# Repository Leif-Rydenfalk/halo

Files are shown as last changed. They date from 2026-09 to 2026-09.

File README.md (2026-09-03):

# halo — an open-source, cheaper AirTag-compatible tracker PCB

*A ce-designs project (`design:halo`) and a triad root. Started 2026-09-03.*

Leif, 2026-09-03, verbatim: *"its a clone of the apple airtag pcb but so we can
open source it and manufacture it for cheaper. do a whole lot of research and
find out a lot of open source projehcts which already tries to do this and
potential pcb designs and all available documentation and research out there
for this and place it all in this repo"*

Apple sells the AirTag for $29 with the hardware closed and the Find My network
gated behind an accessory program. This repo collects **everything public** about
the AirTag hardware, the Find My protocol, the open-source firmware that already
lets non-Apple boards ride the network (OpenHaystack and its successors), every
open coin-cell tracker PCB that could be a starting point, the chips that can
reproduce each function and what they cost, and the legal / certification /
child-safety / anti-stalking constraints — then designs an open board from it.

**Name.** "AirTag" and "Find My" are Apple trademarks, so the project is not
called that. *halo* — Leif, 2026-09-03: "a halo is always visible and you can
find it easily, which is what the project does." The project was briefly called
`haytag` (a tag for the haystack, after OpenHaystack); it was renamed on
2026-09-03 and GitHub redirects the old URL.

## What is where

```
README.md            this page
DECISIONS.md         every design question resolved by evidence, and what each option beat
MISSION.md           the definition of done: the eleven-artifact factory release pack
TOOLCHAIN.md         the tools we have, the open-source sim stack, the lanes building it
GOAL.md              what it is for — puck, embeddable block, local relative positioning (Leif's words)
research/            the dossiers — one per lane, every claim sourced with URL + date
  08-local-positioning-uwb-ble.md        peer-to-peer ranging: UWB TWR, BLE RSSI/AoA, open RTLS projects
  09-embeddable-block-and-modules.md     how to ship it as a KiCad sheet + castellated module
  01-airtag-hardware.md                  teardowns, chips, PCB, firmware, debug ports
  02-findmy-protocol-and-openhaystack.md the BLE payload, key rotation, every OSS project
  03-open-hardware-tag-designs.md        existing open PCBs (KiCad/Eagle/EasyEDA) ranked
  04-commercial-tags-and-clones.md       certified tags + AliExpress clones, what's inside
  05-components-and-cost-model.md        part candidates, BOM roll-up at 10/100/1k/10k
  06-legal-ip-certification-safety.md    trademark, patents, Find My program, DULT, FCC/CE, Reese's Law
  07-mechanical-enclosure-and-3d-models.md dimensions, speaker, battery door, open 3D models
  fetched/           raw text of the key pages, so the record survives link rot
  sources.tsv        every source any lane used: lane, url, title, date, note
reference/           vendored snapshots of the open-source repos (CLONE-LIST.tsv → MANIFEST.md)
  models/            freely-licensed 3D models and drawings
images/              teardown / FCC / design photos with CATALOG.md per folder (source + license)
spec/                machine-readable: bom-candidates.json, later specs.json
docs/                ANTI-STALKING.md and the design documents that follow
electronics/         schematic + netlist (ce-pcb) — next phase
hardware/            KiCad project — next phase
firmware/            pointers to upstream + our port — next phase
ce-parts/ ce-connections/ ce-assemblies/   the triad shelf for this design — next phase
evidence/            ledger.jsonl, append-only
out/                 renders, gerbers, reports — COMMITTED, they are data
```

## Method

1. **Research** (this commit) — collect every public fact with its source.
2. **Specify** — SPEC.md: what the clone must do (Find My via OpenHaystack keys
   first, official program path documented), the DULT anti-stalking minimum,
   target cost, target envelope (Ø ≈ 32 mm, 8 mm).
3. **Design** — ce-pcb board.py → KiCad → JLCPCB assembly; enclosure in ce-cad.
4. **Evidence** — every check lands in the ledger; the design is born T0.

## Status

Research lanes A–G running 2026-09-03. See research/ as they land.

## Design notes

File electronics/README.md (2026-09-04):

# halo electronics — the circuit, block by block

*Lane B1. This describes **revision A**, which lives in `halo_rev_a/`. Every
number here was produced by a tool on this machine; the last section is the
list of things that were not, and it is the most important one.*

---

## Where everything is

| path | what |
|---|---|
| `halo_rev_a/schematic.py` | the circuit, generated. **The only place a part number is typed.** |
| `halo_rev_a/board.py` | the copper. Reads the netlist back out of the schematic — it is never retyped. |
| `halo_rev_a/footprints.py` | the six land patterns KiCad does not have, and the antenna geometry |
| `halo_rev_a/pinouts.json` | the nRF54L10 and LIS2DW12 pin tables, transcribed from the datasheets with citations |
| `halo_rev_a/sim/` | our own circuit and electromagnetic models |
| `halo_rev_a/out/` | the built `.kicad_sch`, `.kicad_pcb`, PDF, SVG, netlist, ERC and DRC reports |
| `../out/release/board/` | the factory package — Gerbers, BOM, CPL, stackup, verdicts |

Rebuild the whole thing:

```bash
cd ~/dev/ce-workshop
python3 ce-designs/halo/electronics/halo_rev_a/footprints.py
ce-pcb/bin/sch build ce-designs/halo/electronics/halo_rev_a/schematic.py \
                  -o ce-designs/halo/electronics/halo_rev_a/out
ce-pcb/bin/pcb   ce-designs/halo/electronics/halo_rev_a/board.py
ce-pcb/bin/sch erc ce-designs/halo/electronics/halo_rev_a/out/halo_rev_a.kicad_sch
```

---

## The circuit, in one paragraph

A CR2032 feeds an nRF54L10 directly. There is no buck, no LDO and no load
switch: the SoC's 1.7–3.6 V range spans the whole cell curve, so every
regulator in Apple's board is a part we do not buy. The SoC carries the
2.4 GHz radio, the NFC-A tag peripheral that drives an etched coil through two
tuning capacitors, and Bluetooth Channel Sounding for peer ranging. A
LIS2DW12TR on I²C wakes it on movement; a bare piezo bender bonded to the
shell is driven anti-phase from two GPIO with no amplifier; SWD comes out on
pads that cost no height.

---

## Block by block, and why each part is there

### 1. The SoC — `nRF54L10-QFAA-R7`, LCSC **C44800139**

QFN-48, 6 × 6 mm, 0.4 mm pitch. **$2.4012 at 1000.** DECISIONS.md D12 chose
it over the nRF52840 on a measurement: Bluetooth Channel Sounding gives 6–10 cm
mean error on coin-cell hardware, the same accuracy band as ultra-wideband,
from a radio already on the tag — and it costs **61 cents less** than the
nRF52832, where adding UWB costs $8.86 more.

Its datasheet numbers drive every power figure in this project: **TX 3.7 mA at
0 dBm, RX 2.1 mA, System-ON with 192 kB retained 2.4 µA** (Table 86). Those are
radio-only figures and lower than the 4.8 mA on Nordic's marketing page, which
is whole-device.

Decoupling is four 100 nF 0201s, one per VDD pin. The SoC's own DC/DC runs off
L1 between `DCC` and `DECD`; `DECA` is tied to `DECRF` because the datasheet
says *"Must be connected to DECA"*, not because it is tidy. The passive values
are Nordic's own reference circuit configuration 1 (Figure 175 / Table 82),
copied component-for-component — the correct move for an RF front end and the
wrong one to improvise.

### 2. Power, the cell, and the five-removals reset

The CR2032 lands on **three sprung fingers**, not a holder: SPEC.md §4 records
that the lowest-profile surface-mount retainer stands 2 mm above the board and
the stack has about 1.5 mm in total. Lane M's carrier holds the cell; the
board's job is three solder lands under the finger roots.

**Bulk is 4 × 10 µF 0402, not Apple's five 100 µF.** Two of the three loads
that needed 500 µF are gone — D12 deleted the U1 and D11a deleted the class-D
amplifier — and an 0805 is 1.25 mm tall against a 0.578 mm allowance. What
40 µF actually buys is measured, not asserted: see §"What the simulations
say".

**Cell-removal detection is a circuit, not a note.** SPEC.md §3 says the
AirTag has two positive contacts *"both sensed before boot"*, and the
five-removals factory reset needs the SoC to stay alive across a removal. So
the second positive finger is **sense-only**: it feeds a 4.7 M/4.7 M divider
into AIN0 whose bottom leg returns to a GPIO rather than to ground, so it
draws 0.32 µA *only while that pin is driven low* and nothing at all the rest
of the time. On a 2.4 µA sleep budget a permanently-on divider would have been
a 13 % battery-life tax. Pull the cell and the sense node collapses in about
0.24 ms while the bulk holds the rail up for seconds. Zero series loss, zero
extra silicon, and it uses the second finger for the reason Apple has one.

### 3. Clocks

32 MHz (`NX2016SA`, C843260) and 32.768 kHz (Epson `C32346`) crystals.
**External load capacitors are placed but NOT FITTED.** The nRF54L family has
on-die load capacitors on both oscillators; fitting external ones as well
double-loads the crystal and pulls it off frequency. The pads exist so a
crystal lot that does not pull in can be trimmed without a board spin, and
populating them means disabling the internal ones — a firmware change, not a
rework.

### 4. The 2.4 GHz path

Nordic's reference matching network (L2/C18/L3/C19/L4/C22/C23) from the `ANT`
pin to a 50 Ω node, then a **pi network — C20 shunt, L10 series, C21 shunt** —
between that node and the antenna feed. L10 is fitted as a 0 Ω jumper so the
board works untuned; all three are re-valued from a measured S11.

The pi is not decoration. A trace antenna on a Ø26 mm board with a Ø20 mm
battery can 0.578 mm underneath will not present 50 Ω, and **a matching network
is the only place that error can be absorbed.**

Two layout rules travel with this block, and they are Nordic's own words from
Figure 175: **C18's ground connects ONLY to pin 32 (VSS_PA), on the top
layer**, and **C19's ground must be isolated from every ground layer except the
bottom.** Both are written onto the sheet, because a schematic cannot enforce
them and forgetting them breaks the radio.

### 5. NFC — and there is no NFC chip

SPEC.md F8: the SoC's own NFC-A peripheral drives the coil from two pins.
**There is no separate NFC front end in an AirTag either**, which deletes a
BOM line most clone designs carry. The whole block is an etched coil and two
capacitors.

The coil is **2 turns, not 5**, and that is forced rather than chosen: the
usable annulus is R10.15–R10.85, because R10.0 is the cell can and R10.94 is
the nearest battery contact land minus clearance. At the 0.30 mm pitch a
0.127 mm process allows, 0.70 mm of band is 2.33 turns.

C24/C25 are **1.1 nF, and they were 130 pF until the solver corrected them.**
130 pF is Nordic's figure *for a 2 µH antenna*; ce-rf measured the real
winding at 0.2449 µH and returned 554.6 pF of tuning across it, so each series
capacitor is 1.109 nF.

### 6. There is no SPI NOR flash — a defect fix

Revision A carried a GD25LQ32EEIGR on VDD. **That part's supply range is
1.65–2.0 V and this board's only rail is a raw 3.0 V coin cell**, so it was out
of specification from the first second — the kind of fault that half-works on
a bench and fails in a field. Caught by the production test lane reading the
sheet.

Fitting a regulator was the alternative and it is what the real AirTag does. It
costs a part, an inductor, a rail, a test and board area, and buys nothing:
nothing else here wants 1.8 V. Meanwhile the firmware measures **13,164 bytes,
1.27 % of the SoC's own 1 MB**, and research/05 §3.7 already recommended
omitting it. So it is deleted. If revision B wants external firmware staging,
the part is a **wide-range low-power NOR such as the Macronix MX25R
(1.65–3.6 V)** — not another GD25LQ.

### 7. Motion — `LIS2DW12TR`, LCSC **C189624**

LGA-12, 2 × 2 mm, under 1 µA in low-power mode, **$0.7408 at 1000**. Apple's
BMA280 is unbuyable (29 in stock against a 10,000-piece minimum packet).

**On I²C, not SPI.** It costs two pins instead of four, frees the SPI bus for
the reserved UWB option, and lets the part answer while nothing else is
selected. CS is strapped high to select I²C and SA0 low to set address 0x18,
both through resistors rather than vias so a bring-up board can change mode.
Both interrupt lines are wired: INT1 is the wake line SPEC.md F7 needs, INT2
carries the orientation vector D12 attaches to every range.

### 8. The sounder — two pins, no amplifier

D11a: a bare **Murata 7BB-20-3** piezo bender, Ø20.0 × 0.22 mm, bonded to the
inside of the shell and driven anti-phase from two GPIO. This is Apple's trick
— make the housing the radiating surface — done with a catalogue part a fifth
of a millimetre thick, because the obvious buzzer is 3.5 mm tall and the stack
has 1.5 mm.

**No MAX98357A.** A bridge-tied class-D swings ±Vbat; two pins driven
anti-phase swing the same. What the amplifier buys is current, and a bender is
capacitive. That was research/05 §11.6's arithmetic; it is now measured.

R9 is 100 Ω of series damping and it earns its line — see below.

### 9. Debug and the reserved UWB option

Six SWD lands at 1.27 mm pitch. **A Tag-Connect was drawn first and does not
fit**: its land pattern is about 80 mm² with two NPTH alignment holes, and the
DRC found those holes drilled through the SoC's pads. Six 0.8 × 1.4 mm lands
carry the same six signals in 9 mm² with no holes.

J2 reserves the halo-uwb variant of D12 as **eight SMD lands** carrying SPI, an
interrupt, a reset and power — **not a DW3110 land pattern.** No document in
this repository carries the DW3110's pin assignment, and D9 forbids guessing
48 net names; and a second 6 × 6 mm QFN does not fit a Ø26 mm board whose
middle Ø20 mm is shadowed by a battery.

### 10. Test access

Eleven probe lands and two asymmetric fiducials, placed by search rather than
by hand. **VDD and GND each get a FORCE and a SENSE pad** — sleep current is
single-digit microamps, and two probes landing in one battery pad is a
two-wire measurement wearing a four-wire name. **IPC-A-610 Class 2** is
recorded on the sheet because the optical inspection recipe is built from it.

---

## What the simulations say — about this board, not an example

| study | verdict | the number that matters |
|---|---|---|
| `sim/rail_droop.py` | **PASS** | 84.7 mV droop at end of life against a 400 mV limit; 64.5 months derated life |
| `sim/rail_droop.py` (hold-up) | **PASS** | 40 µF keeps the rail alive **4.998 s** after the cell is pulled |
| `sim/sounder_drive.py` | **PASS** | **3.98 V pp** across the bender from a 2.0 V cell — 2×VDD with no amplifier |
| `ce-rf` NFC coil | **PASS** | L = 0.2449 µH, tuning 554.6 pF |
| `ce-rf` 2.4 GHz | **FAIL** | 2.886 GHz against a 2.4–2.4835 GHz target |

**Three things the simulations changed in the design, rather than confirming.**

1. **The NFC tuning was eight times wrong.** 130 pF → 1.1 nF.
2. **R9 was justified for the wrong reason.** The schematic said 100 Ω "holds
   the peak near 30 mA". Measured: with a low-loss 40 nF bender the peak pin
   current is 32.0 mA *without* R9 and 17.8 mA *with* it. Right magnitude,
   wrong side of it. R9 is what keeps the pin under a 25 mA ceiling.
3. **The antenna was 3.78 mm too short.** openEMS returned
   `eps_eff_implied = 1.573` where the element had been sized on the textbook
   2.2, so the quarter wave is 24.49 mm and not 20.71. The element now
   meanders, with the tooth depth solved by bisection.

**Two studies caught their own mistakes**, which is the point of writing
asserts that can fail. The sounder study first measured the bender voltage
*to ground* instead of *across the bender*, reported 2.0 V where the swing is
4.0 V, and failed an assert that was actually satisfied. And the rail study
asserted the rail alive ten seconds after a cell removal — a threshold that
came from nowhere, failed at 1.400 V, and was replaced by the requirement that
actually exists (the firmware's detect-and-commit budget, about 11 ms) rather
than loosened.

---

## What is still unproven

**Load-bearing, in rough order of how much they matter.**

1. **The board is not routed.** 91 unconnected items, 0 vias. Freerouting
   was run three times and timed out three times — 900 s at 12 passes,
   3300 s at 3, 2400 s at 2. The tool works (lane T1 proved it on a Ø31.87 mm
   board); this board is denser than it can handle. Do not fabricate.
2. **The antenna has not passed.** 2.886 GHz measured on the 20.71 mm
   element, with `eps_eff_implied = 1.573` naming the cause. The corrected
   24.49 mm meander is drawn in the copper but its FDTD re-run did not
   complete — the confirmation that it lands in band is the missing piece,
   not the correction itself.
3. **Five part classes do not fit the enclosure — and the fix is already
   written down.** 46 PASS / 5 FAIL on the height check. A QFN-48 is 0.85 mm
   and the cell leaves 0.578 mm under the bottom face; X1 and L1 are over by
   0.322 mm, the SoC by 0.272.

   **DECISIONS.md D17 (lane M, 2026-09-04) ends: *"leaving 0.542 mm of dead
   air under the cell that a flat pad embossed in the door could still
   recover"*.** If that pad is embossed the cell drops and the bottom-face
   allowance becomes 0.578 + 0.542 = **1.120 mm**. The tallest part here is
   0.90 mm and needs 0.95 mm with a solder fillet, so **every part clears** —
   and only **0.372 mm of the 0.542 mm** has to be recovered to do it.

   **This is a request to lane M, and it is the single change that closes
   this lane's largest open item.** `board.py height_check()` prints the
   arithmetic on every run.
4. **Loudness is unmeasured and DULT makes it mandatory.** 60 Phon at 25 cm
   cannot be simulated; VERIFICATION-DEBT V7 carries it.
5. **The bender is unsourced at every quantity**, so its land pattern is
   deliberately generic.
6. **Two turns of NFC coil may not couple enough** to read at a phone's field
   strength. The inductance is measured; the read range is not, and no assert
   here pretends otherwise.
7. **The SoC's stock is 212 pieces** against a 1000-piece minimum packet.
8. **Channel Sounding between two halos has never been demonstrated** — the
   6–20 cm figure is from a published study on other hardware (V8).
9. **The 0402 bulk capacitors' DC bias derating is unfetched**, so 40 µF is an
   upper bound and every droop figure is optimistic by an unmeasured amount.
10. **The GPIO high-drive output resistance is an estimate** (40 Ω), and every
    peak sounder current is inversely proportional to it.
11. **Controlled impedance is not implemented**, and the fab's 0.60 mm 4-layer
    dielectric heights were never retrieved.
12. **eps_r 4.3 / tan δ 0.02 is generic FR-4**, not fab-quoted — the largest
    single uncertainty in every RF frequency here.

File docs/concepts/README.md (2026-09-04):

# halo concept portfolio

*twelve researched ways to close the last gap to the AirTag and get further ahead than Apple*

> concept docs with ideas and different approaches to close the gaps further and get even further ahead than apple themselves

halo is at functional parity with the AirTag on every row of SPEC.md section 2 except F9, Precision Finding, which needs Apple's own ultra-wideband silicon behind an NDA that cannot coexist with publishing the design. It is already ahead in five measured ways: both Apple's and Google's networks in one advertising event, an antenna simulated at +0.521 dBi against Apple's filed -3.2 dBi, peer-to-peer ranging between the owner's own devices, about a sixth of Apple's retail price, and every file open.

This portfolio is what comes after parity. Each concept is researched and costed, not brainstormed: what it is, why it beats the alternative, the evidence with sources and dates, the cost in money and current and size and complexity, what it would break in the design that exists today, a verdict, and the smallest experiment that would settle it.

Nothing here is a commitment. A concept that reaches PROVEN is a thing somebody has already made work, not a thing halo has shipped.

**4 concepts: 1 PROVEN · 3 PLAUSIBLE · 0 SPECULATIVE.**

## What the three verdicts mean here

| verdict | means |
|---|---|
| **PROVEN** | Somebody has already made this work and the artifact is readable — a paper with measurements, a repository whose source says so, a datasheet number. The remaining risk is integration, not physics. |
| **PLAUSIBLE** | Every component of the argument is sourced, but the combination has not been demonstrated in the shape halo needs. The arithmetic closes; the experiment has not been run. |
| **SPECULATIVE** | A reasoned idea whose load-bearing claim has no source I could reach. It is written down with what would settle it, and it must not be quoted as a finding. |

A concept with no source is SPECULATIVE and says what would settle it. That rule is `docs/TOOLS-THAT-LIE.md` applied to ideas rather than to tools: a portfolio that reads as all-green would be reporting completeness it had not earned.

## Where halo stands before any of this

| fact | number | source |
|---|---|---|
| Average cell current, Find My advertising baseline (2 s period, 1 ms TX at 3.7 mA, 2.4 uA sleep) | **4.2506 uA  =  12.75 uW at 3.0 V** | ce-spice rail_droop, out/release/board/sim/rail_droop/measurements.json, i_avg_uA, 2026-09-04 |
| Battery life on a 235 mAh CR2032 at that current, derated for pulsed draw and self-discharge | **64.5 months (5.4 years)** | same file, life_months_derated; derations cited to TI SWRA349 Fig 3 and Energizer 2032NA0618 |
| SoC currents that drive every power figure here | **TX 3.7 mA at 0 dBm, RX 2.1 mA, System-ON 192 kB retained 2.4 uA** | nRF54L10 datasheet 4503_018 v0.10 Table 86, transcribed research/fetched/E-nrf54l-datasheet-currents.md |
| Unit cost at 10 / 100 / 1 000 / 10 000 against Apple's $29 retail and ~$10 build | **$19.25 / $9.28 / $7.17 / $6.75** | DECISIONS.md D15; spec/bom-resolved.json cost.model.d15_baseline_usd_per_unit |
| Board, and what is on it | **D26.00 x 0.60 mm, 4 layer, 38 placed refs, 131 joints; part-routed at 49 vias, 255 track segments, 81 unconnected** | electronics/halo_rev_a/schematic.py; STATUS.md board measurement 2026-09-05 06:06 — DO NOT FABRICATE until unconnected reaches 0 |
| Peer ranging accuracy specified for v1 | **6-10 cm MAE, 16-20 cm P90, line of sight, static, <=5.5 m** | arXiv:2605.17094 Table I (eight CR2032 nRF54L15 devices); research/08 section 1; DECISIONS.md D12 |
| Energy per pairwise Channel Sounding range, 0 dBm, 37 channels | **~19 uC = ~57 uJ  [derived in research/08 section 9.3 from the paper's 79 uC/cycle for four peers]** | arXiv:2605.17094 section IV-C; research/08 section 9.3 |
| Antenna, study geometry (D30 x 1.0 mm round rim inverted-F) | **PASS: 2.4469 GHz, +0.521 dBi realized gain against Apple's filed -3.2 dBi** | ce-rf out/halo-round-rim-ifa/verdict.json, verdict PASS |
| Antenna, the board this pack actually ships (D26.00 x 0.60 mm) | **FAIL — 2.4927 GHz, solver_converged 0. The +0.521 dBi is NOT this geometry** | ce-rf out/halo-rev-a-2g4/verdict.json; spec/convergence.json refuses a value from a FAIL case |
| Firmware footprint with all three protocol layers resident | **13,164 bytes flash (1.27 %) and 704 bytes RAM (0.36 %) on nRF54L10** | SPEC.md section 2a; DECISIONS.md D18 — the DULT transport is NOT yet written and is the expensive part |
| Stack budget, closed | **31.874 x 31.874 x 7.980 mm assembly, 0.542 mm of dead air left under the cell** | DECISIONS.md D17; design.py stack budget check |
| Find My location quality, for comparison with anything local | **raw report mean error ~100 m walking; median 26 min from generation to upload; 4 reports per key; 7 day retention** | PETS 2021 Tables 5-7 and sections 6.3-6.4, quoted in research/02 sections 1.6 and 10.4 |

## The portfolio

| # | concept | verdict | value | effort | one line |
|---|---|---|---|---|---|
| C3 | [Sensor telemetry over the finding network, with no gateway of its own](C3-sensor-telemetry-over-the-finding-network.md) | **PROVEN** | 5 | 1 | The status byte is copied into the location report and encrypted to the owner's key, so a halo can report sensor state through a stranger's phone and Apple cannot read it. |
| C8 | [Form factors the embeddable block enables — and the one rule that decides each](C8-form-factors-the-block-enables.md) | **PLAUSIBLE** | 4 | 2 | A card, a sticker, a bolt-on asset tag and a solder-down module are four different products, and DULT's own applicability test — not the electronics — is what changes between them. |
| C11 | [The tag you can audit — open debug, reproducible firmware, and why it costs almost no secrecy](C11-the-tag-you-can-audit.md) | **PLAUSIBLE** | 3 | 1 | Nobody can prove what an AirTag does. A halo whose firmware hash an owner can verify against a published build is a procurement answer no commercial tracker can give — and with pre-generated keys it gives away almost nothing. |
| C12 | [The flight recorder — an on-tag event log, read at an NFC tap](C12-the-flight-recorder.md) | **PLAUSIBLE** | 4 | 2 | An AirTag remembers nothing. A halo has 1 MB of NVM and uses 13 kB of it, so it can keep the last several thousand motion and ranging events and hand them over when somebody taps it. |

## Ranked by value against effort

Value is what it is worth to the goal in `GOAL.md`; effort is what it costs to find out, not what it costs to ship. A cheap experiment on a big idea outranks an expensive certainty.

| rank | concept | value/effort | verdict | the first move |
|---|---|---|---|---|
| 1 | C3 Sensor telemetry over the finding network, with no gateway of its own | 5/1 = 5.00 | PROVEN | Write the 3-bit counter firmware and leave two tags out for 48 hours. Costs one evening and answers the density question too. |
| 2 | C11 The tag you can audit — open debug, reproducible firmware, and why it costs almost no secrecy | 3/1 = 3.00 | PLAUSIBLE | Build the firmware twice and diff. If it is reproducible, say so in the README with the hash; if it is not, that is a defect worth a line in VERIFICATION-DEBT.md. |
| 3 | C12 The flight recorder — an on-tag event log, read at an NFC tap | 4/2 = 2.00 | PLAUSIBLE | Read the NVM write current out of the datasheet and add one scenario to the rail_droop study. The answer is a number in the units this project already reports. |
| 4 | C8 Form factors the embeddable block enables — and the one rule that decides each | 4/2 = 2.00 | PLAUSIBLE | Drop the existing design block into a card outline and run one antenna solve on it. The block is already measured to transfer; what is unmeasured is whether the antenna is happier in a bigger space. |

## What was considered and left out

- **A GNSS receiver on the tag** — A first fix costs tens of milliamps for tens of seconds against a 4.2506 uA budget, and Find My already answers the question GNSS would answer — which city block — for free. The gap in this project is room scale, and GNSS does not close it.
- **A LoRaWAN or NB-IoT backhaul** — It adds a second radio, a second certification regime and a gateway, to buy uplink from places nobody walks past. C9 buys the same thing with hardware halo already has.
- **A USB port for recharging** — A port is a hole, and IP67 and Reese's Law both fight it. The measured life is 64.5 months; the problem this would solve is not the problem halo has.
- **BLE 5.1 angle of arrival** — The tag side is free but the anchor side needs a multi-element switched antenna array in every room. GOAL.md rules out per-room infrastructure. research/08 section 10.
- **Appearing inside Apple's own Find My application** — It needs a per-unit Apple Token burned into flash at the factory under MFi, and D5 refuses MFi on principle because its terms make the specification confidential and publishing an implementation would breach them. This is a commercial wall, not a technical one, and it is not going to move.
- **A display, an e-paper panel or an LED ring on the puck** — Every one of them puts a conductor inside the D37.31 mm antenna keep-out and spends stack height, to deliver something GOAL.md does not ask for. The measured cost of violating that keep-out is in C4.
- **A stealth or silent build target** — SPEC.md section 8 refuses it on principle, not by omission, and this portfolio does not reopen it.

---

Generated from `spec/concepts.json` by `tools/gen_concepts.py` on 2026-09-05, commit `cdaa1dc`. The HTML page is `out/concepts/INDEX.html`. Do not edit these files; edit the JSON.

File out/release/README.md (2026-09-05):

# halo — open AirTag-compatible tracker — Factory handoff pack

Generated 2026-09-05 from `spec/release-pack.json` by `tools/gen_release_pack.py`.

| # | artifact | status |
|---|---|---|
| 1 | Gerbers, drill and netlist | **PARTIAL** |
| 2 | Schematic, ERC-clean, plus a reusable design block | **PARTIAL** |
| 3 | Bill of materials with prices and alternates | **READY** |
| 4 | Pick-and-place file in factory format | **READY** |
| 5 | Panel drawing, stackup and materials | **PARTIAL** |
| 6 | Simulation evidence | **READY** |
| 7 | Firmware, build instructions and a proven advertisement | **READY** |
| 8 | Mechanical files and assembly instructions | **READY** |
| 9 | Production test plan | **PARTIAL** |
| 10 | Compliance dossier | **PARTIAL** |
| 11 | Cost roll-up against Apple's retail price | **READY** |

See `INDEX.html` for the full pack: the work breakdown, what we need from the factory,
the compliance rules, and the open risks.

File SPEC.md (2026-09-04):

# SPEC — what halo must be

*The specification the design is judged against. Every row is either SETTLED
(with its source) or PENDING with the lane that will settle it. Nothing here is
an assumption: a PENDING row is a work item, never a guess left to harden into
a fact. Companion documents: GOAL.md (why), MISSION.md (definition of done),
DECISIONS.md (how each question was resolved), docs/ANTI-STALKING.md (the
safety behaviour, non-optional).*

Started 2026-09-03. Revision: draft 0.

## 1. Product definition

halo is a coin-cell Bluetooth tracker that reproduces the Apple AirTag
function for function from public information only, published openly, and
manufacturable cheaply. It ships in two variants (DECISIONS.md D1):

| | halo-core | halo-uwb |
|---|---|---|
| radios | 2.4 GHz BLE, Channel Sounding | same, plus an ultra-wideband transceiver in the reserved footprint |
| purpose | the open product: find your things through Apple's Find My network, **and** range to other halos at 6–20 cm line of sight | a high-precision stuffing option, if Channel Sounding proves insufficient in a real room |
| certification | pre-certified module, modular approval, RED self-declaration | owner-operated, not a sold consumer product |
| status | the shipping default | second board revision |

The circuit is published three ways so it can be embedded in any host board in
any outline (GOAL.md deliverable 2): a KiCad hierarchical design block, a
castellated solder-down module, and the Ø 32 mm puck as the first host.

## 2. Functional requirements, against the real AirTag

Each row: what the AirTag does, what halo must do, and where the number comes
from. The part that implements each is section 3.

| # | function | requirement | state |
|---|---|---|---|
| F1a | Google Find Hub advertising | advertise concurrently on Google's network: service `0xFEAA`, frame `0x40/0x41`, ~1024 s ephemeral-ID rotation | SETTLED lane B (public spec); DECISIONS.md D7 |
| F1 | Find My advertising | non-connectable advertisement, 37 bytes on air: address = `p[0]\|0b11000000 ‖ p[1..5]`, then `1E FF 4C 00 12 19 <status> p[6..27] p[0]>>6 <hint>`, where p is the X coordinate of the rolling NIST P-224 public key | SETTLED lane B (PETS 2021 Table 2, cross-checked against OpenHaystack source) |
| F2 | key rotation | rotate the advertised key on the DULT schedule; MAC address rotation likewise | SETTLED lane F: 15 min key, 24 h MAC |
| F3 | sound maker | audible alert, **≥60 Phon at 25 cm (ISO 532-1:2017)**, mandatory, four non-owner sound opcodes | requirement SETTLED lane F; mechanism OPEN, see DECISIONS.md D11 |
| F4 | separated-state behaviour | near-owner → separated after >30 min; random 8–24 h alert timeout with 6 h back-off | SETTLED lane F |
| F5 | identifier retrieval | serial readable over NFC or BLE, behind a physical button, 5-minute window; printed unique serial on the housing | SETTLED lane F |
| F6 | owner information page | obfuscated owner-info page, ≥25-day retention | SETTLED lane F |
| F7 | motion detection | wake and change advertising behaviour on movement | SETTLED lane A: AirTag samples every 10 s at rest and 0.5 s once moving; DULT additionally requires ±10° accuracy |
| F8 | NFC tap | phone tap reads the tag and opens the owner page | SETTLED lane A: the Nordic SoC's own NFC-A peripheral emulates a read-only Type-4 tag holding the owner URL; only the coil and two tuning capacitors are external |
| F9 | precision finding | AirTag does this with Apple's U1 | **known gap** — not reproducible without MFi (DECISIONS.md D1, D5) |
| F10 | peer ranging | range to other halos with Bluetooth Channel Sounding, 6–20 cm line of sight, 30 s update, deterministically scheduled, reporting raw ranges with quality metadata and an orientation vector | SETTLED lane H; DECISIONS.md D12 |
| F11 | battery life | about a year on a CR2032 | model PASSES in ce-spice: fresh-cell droop 68 mV under a transmit pulse against a 400 mV limit, five scenarios fresh to end of life, all asserts held |
| F12 | battery replacement | user-replaceable CR2032 behind a compliant door | SETTLED lane F: tool or two independent simultaneous movements (16 CFR 1263) |

## 2a. Budget floors (from lane B)

**Measured 2026-09-04, so this section is no longer an estimate.** halo's own
firmware on an nRF54L10 uses **13,164 bytes of flash (1.27%) and 704 bytes of
RAM (0.36%)** with all three protocol layers resident. Per object: DULT 605
bytes, the two elliptic curves sharing one engine 2,766, SHA-256 1,034, AES 736,
rolling keys 383, Find Hub 334, Find My 94.

The 116.7 KB / 21.5 KB Goodix figure quoted earlier measures a **different
question** — a full stack including the LE link layer and connection handling.
halo's number covers the protocol layers only; no link layer is present and no
connection is ever established, with the DULT opcodes graded as a pure function.
The expensive part of DULT is the transport, and it is not yet written. Both
numbers are correct and they are not comparable.

## 3. Component map — one row per function

From lane A's function map (research/01-airtag-hardware.md §4), which read the
part markings off Colin O'Flynn's full-resolution board photographs and Apple's
own regulatory filing. The halo column is lane E's substitution work; rows
marked PENDING lane E are awaiting its sourced pick.

| function | AirTag part (identified) | halo part | note |
|---|---|---|---|
| CPU, Bluetooth radio **and NFC tag in one** | Nordic **nRF52832-CIAA**, WLCSP-50, marking `N52832 CIAAE0 2102JK` | **nRF54L10**, falling back to L05 or up to L15 on memory (D12) — the family keeps the NFC-A tag peripheral and adds Channel Sounding | the NFC tag is the SoC's own peripheral on pins P0.09/P0.10 — **no separate NFC chip exists in an AirTag**, which deletes a line most clone BOMs carry |
| UWB ranging | Apple **U1**, die `TMKA75`, TSMC 16 nm, in a USI system-in-package with its own processor running "Rose" firmware side-loaded by the Nordic part | **not reproducible** — never sold. halo-uwb uses a sourceable transceiver for peer ranging only (D1) | the only true hard wall in the whole design |
| firmware and key storage | GigaDevice **GD25LE32/LQ32**, 32 Mbit SPI NOR, WLCSP-10, 1.8 V | PENDING lane E — generic SPI NOR | holds both the Nordic firmware and the U1's firmware, unencrypted |
| motion detection | Bosch **BMA280** | PENDING lane E | sampled every 10 s at rest, 0.5 s once moving |
| sound | Maxim **MAX98357A** class-D amplifier driving a copper voice coil glued to the shell, against a fixed central magnet, with a **TI TLV9001** op-amp in the analogue path | **bare Murata 7BB-20-3 piezo bender, Ø20.0 × 0.22 mm**, bonded to the shell and driven anti-phase from two SoC pins (D11) | about 8 mA while sounding, over three thousand times the sleep current |
| power | TI **TPS62746** buck to a 1.8 V rail, onsemi **FPF2487** load switch gating the UWB and flash, a small LDO, and **five 100 µF** bulk capacitors marked `J107S` | PENDING lane E | the bulk capacitance is what keeps the tag alive for seconds after the cell is pulled, which is how the five-removals reset works |
| timing | 32 MHz crystal marked `T320/RBEV`, 32.768 kHz crystal marked `A048L` | PENDING lane E | |
| antennas | three laser-direct-structured traces on the plastic carrier: Bluetooth inverted-F at **−3.2 dBi**, an NFC coil, a UWB patch at **−1.6 dBi at 6.5 GHz** | PENDING ce-rf | gains are from Apple's own filed test reports, not estimates |
| battery | CR2032 on three sprung contacts, two positive rails both sensed before boot | PENDING lane E | |

**The bottom line of the map:** every function is reproducible from catalogue
parts except precision finding, which needs Apple's chip, and appearing in
Apple's own Find My application, which needs a per-unit token Apple burns into
the flash at the factory. Both walls are commercial, not technical.

## 4. Physical envelope

From Apple's own dimensioned accessory drawing (lane G found it published free
at developer.apple.com, outside the login-walled Accessory Design Guidelines)
and from teardown measurements. Apple forbids redistributing that sheet, so the
numbers are transcribed here and the redistributable geometry in
`reference/models/` is a CC BY 4.0 drawing that reproduces every callout.

| feature | value | note |
|---|---|---|
| maximum outer diameter | **31.87 mm** | occurs at z = 4.34 mm, derived from the drawing's profile |
| overall height | **7.98 mm** | |
| stepped diameters | 28.94 / 27.90 / 27.84 / 25.55 / 23.11 mm | 0.05 mm chamfer |
| speaker keep-out | **Ø25.75 mm**, "do not obstruct" | Apple's own callout |
| antenna keep-out | **Ø37.31 mm**, no metal above or below | larger than the tag itself |
| steel cover | approximately a spherical cap of radius 92 mm | not a battery terminal — all three contacts are on the carrier |
| mass | 11 g first generation, 11.8 g second | otherwise dimensionally identical |
| environment | IP67, −20 to +60 °C | |

**The stack budget is the binding constraint.** A CR2032 is 3.2 mm and the
disassembled internal module measures 3.3 mm, so 6.5 of the 7.98 mm are spent
before the cover, the clearances and the shell wall. About 1.5 mm remains.

Two consequences follow directly, and both are now design rules:

- **No coin-cell holder fits.** The lowest-profile surface-mount retainer still
  stands 2 mm above the board. Sprung fingers on the carrier, clamped by the
  door, is the only scheme that fits — which is what Apple does.
- **No housed buzzer fits.** The obvious catalogue part reaches exactly the
  required loudness at three volts but is 3.5 mm tall.

Lane C's warning still holds on the copper side: a 20 mm cell inside a 30 mm
board leaves about a 5 mm annulus for the Bluetooth antenna keep-out and the
NFC coil together. The electromagnetic solver decides whether they share it,
the cell moves off-centre, or the puck grows.

The embedded block variant is not bound by this envelope. Only the puck is.

## 5. Electrical requirements

| # | requirement | source |
|---|---|---|
| E1 | operate from a CR2032 across its full discharge curve, including the rising internal resistance at end of life | ce-spice model, lane T2 |
| E2 | survive the radio transmit current pulse without the rail dropping below the SoC minimum at end of life | ce-spice, asserted |
| E3 | sounder drive that reaches F3's loudness inside an 8 mm puck | lane G (mechanism) + ce-spice (drive current) |
| E4 | 2.4 GHz antenna matched on the real board outline, with the battery's copper in place | ce-rf, lane T3 |
| E5 | NFC coil tuned to 13.56 MHz for the chosen tag IC's input capacitance | ce-rf |
| E6 | per-layer current and voltage drop within IPC-2221B limits | ce-board-sim |

## 6. Manufacturing requirements

| # | requirement | source |
|---|---|---|
| M1 | 4-layer board, DRC-clean against JLCPCB's published capabilities | ce-fab dfm, lane T6 |
| M2 | every part in stock at LCSC with a named alternate | ce-fab bom, lane T6 |
| M3 | assembly files (BOM + pick-and-place) accepted by JLCPCB without manual correction | ce-fab jlc |
| M4 | panelized for volume | ce-fab panel |
| M5 | cost per unit at 10 / 100 / 1 000 / 10 000, compared to Apple's $29 retail | lane E |

## 7. Compliance requirements

The 30-item constraint checklist in research/06-legal-ip-certification-safety.md
is normative. The headline constraints: pre-certified radio module for modular
approval; no Bluetooth word mark (DECISIONS.md D2); Reese's Law battery door
(D3); DULT behaviour non-optional (docs/ANTI-STALKING.md); clean-room only,
no MFi (D5); licence split (D4).

## 8. Out of scope

Apple Precision Finding (F9), the "Works with Apple Find My" badge, and any
stealth or silent build target. The last is refused on principle, not omitted.

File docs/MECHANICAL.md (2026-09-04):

# MECHANICAL — the halo puck enclosure

*Lane M. Everything here is either transcribed from a named source, computed
from the parameters in [`design.py`](../design.py), or **read off the finished
solid** by the measured-check suite in that same file. Where a number is a
calculation rather than a measurement it says so, and where nothing has been
measured the verdict is CANNOT DETERMINE and the test that would settle it is
named. Nothing is asserted.*

**Twelve measured checks, all PASS** — `out/mech/verdicts.json` is the record,
and two of them went red first and are in the ledger as a `failure` row.
Reproduce every number in this page with:

```bash
cd ce-designs/halo
~/dev/ce-workshop/ce-cad/bin/cad design.py            # build, check, render, export
~/dev/ce-workshop/ce-cad/bin/cad tools/section_view.py  # the section, seconds
python3 tools/stl_bbox.py out/mech/*.stl              # read the exports BACK
CE_TRIAD_ROOT=$PWD ~/dev/ce-workshop/bin/triad check --all
```

Companion documents: [SPEC.md](../SPEC.md) §4 (the envelope), [DECISIONS.md](../DECISIONS.md)
**D3** (battery door), **D11a** (the sounder), **D13** (enclosure and tooling),
and [research/07](../research/07-mechanical-enclosure-and-3d-models.md) — lane G's
dossier, which is where every Apple number in this page comes from.

---

## 1. What halo's enclosure is

Four moulded/stamped parts, one bought bender, one cell, three stamped
springs and a bead of silicone.

| # | part | material | process | what it does |
|---|---|---|---|---|
| 1 | `part:halo-shell-top` | PC | injection moulded, **straight pull, no undercut** | the crown. It **is** the loudspeaker diaphragm and the NFC window |
| 2 | `part:halo-carrier` | LCP, LDS grade | injection moulded, **three lifters** + laser direct structuring | the PCB seat, the contact roots, the seal land, the bayonet feet, the antennas |
| 3 | `part:halo-battery-door` | 301 stainless, 0.30 mm | progressive stamping | the user-openable door; press-and-twist |
| 4 | `part:halo-door-seal` | LSR 70 Shore A | moulded in place on the carrier | the radial door seal |
| 5 | `part:halo-battery-contact` ×3 | C5191 phosphor bronze, 0.15 mm | stamped, formed, insert-moulded | the cell's three contacts. There is no holder |
| 6 | `part:halo-piezo-7bb-20-3` | brass + PZT | bought (Murata) | the sounder (D11a) |
| 7 | `part:halo-cr2032` | — | bought | the cell |
| 8 | `part:halo-pcb-blank` | FR4 | 4-layer PCB | the board outline (the copper is the electronics lane's) |

Plus two prototype variants, `part:halo-shell-top-fdm` and
`part:halo-battery-door-fdm`, §8.

**The frame, and it is Apple's own.** Origin on the axis of revolution at the
lowest point of the battery door's outer face; +z toward the crown apex at
z = 7.980; +x through the 6 o'clock bayonet ledge, so D13's three ledges are at
0 / 120 / 240° (6, 10 and 2 o'clock). Every part is **built** in this frame, so
every placement in `assembly:halo-puck` is the identity — a concentric product
has one datum and there is not a coordinate to get wrong.

**The single tooling decision that shapes the whole split.** A bayonet is an
undercut; something must have one. halo puts **every undercut on the carrier**,
which nobody sees, and leaves the cosmetic shell a pure straight pull. Catley
found the AirTag's retaining tabs are *separate plastic pieces glued to the
white shell* at 2, 6 and 10 o'clock — the same problem, solved by gluing rather
than by moving the feature to another part. Three lifters in a non-cosmetic LCP
tool is the cheaper answer, and it deletes an assembly operation.

---

## 2. The stack budget — it closes, and it closes with slack

Every row is on the axis, in the closed state, and every boundary is a variable
in `design.py`. The table is printed by `report_stack()` on every build.

| # | layer | from | to | dz | where the number comes from |
|---|---|---|---|---|---|
| 1 | door skin at the axis, 301 SS | 0.000 | 0.300 | **0.300** | halo's choice. Apple's is **unmeasured** (research/07 §5.2 row 1 is an estimate) |
| 2 | dome sagitta under the cell — dead air | 0.300 | 0.842 | **0.542** | read off Apple's own ordinate table at the cell's Ø20.00 rim |
| 3 | **CR2032** | 0.842 | 4.042 | **3.200** | Maxell datasheet |
| 4 | contact dimple + finger, compressed | 4.042 | 4.292 | **0.250** | 0.100 emboss + 0.150 C5191 stock |
| 5 | carrier deck: finger roots + PCB seat | 4.292 | 4.600 | **0.308** | halo design |
| 6 | **PCB** | 4.600 | 5.200 | **0.600** | halo's choice (Apple's is 0.30) |
| 7 | top-side component allowance inside Ø21.2 | 5.200 | 5.600 | **0.400** | halo keep-out |
| 8 | diaphragm moving gap | 5.600 | 6.280 | **0.680** | halo design |
| 9 | Murata 7BB-20-3 + 0.05 bond line | 6.280 | 6.550 | **0.270** | Murata datasheet + halo |
| 10 | PC crown wall at the axis | 6.550 | 7.980 | **1.430** | derived: flat land at 6.550, Apple's R92 crown above it |
| | **TOTAL** | | | **7.980** | Apple's drawing |

**Verdict: PASS.** The sum is 7.980 mm against the 7.980 mm of Apple's drawing,
and the built assembly measures **31.874 × 31.874 × 7.980 mm** — SPEC §4's
envelope, read off the solid, not asserted. The exported `halo-puck.stl`, read
back by `tools/stl_bbox.py` (stdlib only, and it knows nothing about ce-cad),
measures **31.874 × 31.864 × 7.980 mm over z 0.000…7.980** — and every part's
STL confirms its own row of the table: door z 0.000…2.190, cell z 0.842…4.042,
carrier z 1.290…4.900, bender z 6.280…6.500, shell z 2.290…7.980.

### 2.1 Why SPEC §4's "about 1.5 mm remains" is no longer the binding constraint

SPEC §4 says a CR2032 (3.20) plus a 3.30 mm internal module spends 81 % of the
height before the cover, leaving about 1.5 mm. **That 3.30 mm is Apple's**, and
Catley measured it with a magnet and a voice coil inside it. D11a deletes both
for a 0.22 mm Murata bender.

halo's equivalent of Apple's module is rows 4–7: **1.558 mm**. The bare bender
therefore **returns 1.742 mm to the budget**, and halo spends it on:

| what | mm | why |
|---|---|---|
| a 0.60 mm PCB instead of Apple's fragile 0.30 | +0.300 | far cheaper to fabricate; Apple's is "likely to cause damage when removed" |
| a real moving gap for the bender | +0.680 | Apple's coil moves in the same air the magnet sits in; a bonded bender needs its own clearance |
| a 1.430 mm crown at the axis, against Apple's ~0.88 residual for wall + clearance | +0.550 | see §4 — the flat internal land |
| unspent | +0.212 | absorbed by rows 4–5 |

**And there is 0.542 mm of reclaimable slack on top of that** — row 2, the dead
air under the cell's centre where the R92 door dome falls away. Emboss a flat
pad in the door's stamping and it comes back. It is not spent today because
nothing needs it; it is recorded here so the next lane knows where the money is.

The binding constraint on halo is therefore **not** the vertical stack. It is
(a) the crown wall thickness, which is an acoustic argument (§4), and (b) the
radial budget, §3.

### 2.2 What does NOT fit, stated plainly

- **A coin-cell holder.** The lowest-profile SMT retainer, Keystone 1057, still
  stands 2 mm above the board; 2 + 3.2 = 5.2 mm of 7.98 before a component.
  Sprung fingers clamped by the door is the only scheme that fits, which is
  exactly what Apple does. §5.
- **A housed buzzer.** The TDK PS1240P02CT meets DULT's loudness at 3 V and is
  3.5 mm tall — 44 % of the whole budget. §4.
- **A screw-down door.** 1.5–2.5 mm of boss depth plus a head, plus metal
  inside Apple's Ø37.31 antenna keep-out (D13).

---

## 3. The radial budget, and every callout used

SPEC §4 lists five stepped diameters. Lane G flagged two of them —
Ø27.90 and Ø27.84 — as **medium confidence**: they are plan-view callouts on
Apple's drawing that the CC BY half-section DXF omits entirely. halo's reading
is below, and it is halo's, not a measurement of an AirTag.

| Ø | what it is in halo | confidence |
|---|---|---|
| **31.874** | maximum outer diameter, at z = 4.339 | Apple's drawing; **measured on our solid** at z 4.263…4.384 |
| **28.94** | the shell's underside lip, at z = 2.290, with the 0.05 chamfer | Apple's drawing |
| **27.90** | the shell's bore — the hole the whole door assembly sits in | halo's reading of a plan-view callout |
| **27.84** | the carrier's three bayonet legs, sitting in that bore | halo's reading of the adjacent callout |
| **25.55 / 25.45** | the door's wall, with the 0.05 mm chamfer at each end | Apple's drawing (the DXF's Ø25.55 band between z 0.930 and 1.840, Ø25.45 at each end) |
| **23.11** | the carrier's seal land — the widest *continuous* feature in the 0.40 mm band between the door's rim (z 1.890) and the shell's underside (z 2.290) | halo's reading |
| **25.75** | Apple's speaker keep-out, realised as the **diameter of the acoustic surround** and as a declared keep-out volume on the shell | Apple's drawing |
| **37.31** | Apple's antenna keep-out. **Measured: the annulus Ø31.874…Ø37.31 contains no halo material at all**, so the keep-out is entirely the host's obligation | Apple's drawing |

**The metal inside Ø37.31, named rather than hidden.** halo contains seven
conductive parts — the stamped door (Ø26.37 over the tabs), the board and its
copper (Ø26.00), the bender's brass shim (Ø20.00), the cell (Ø20.00) and three
contacts — all inside the Ø31.874 envelope, exactly as the AirTag's are. The
antennas sit *above* them on the carrier's outer wall, which is why Apple's
carrier is where the LDS traces go. **RF performance is ce-rf's lane and is
CANNOT DETERMINE here.**

**The wall at the equator is 2.0 mm.** With a straight Ø27.90 bore at 1° draft
and the outside bulging to Ø31.874, the shell's section at z = 4.34 is
(31.874 − 27.86)/2 = **2.01 mm** against a 0.80 mm crown — a 2.5 : 1 thickness
ratio on a glossy white PC part, which is a sink-mark and warp risk. It is not
avoidable without a collapsible core, because a barrel-shaped cavity wider than
its own mouth is an undercut; and it is not unusual, because Apple's own shell
is the same lens with a hole in it (lane G: 2.94 mm of section per side at the
equator). **Mitigation is a process decision — gate on the rim, long hold, and
accept a matte or lightly textured finish — and it is a first-article item, not
a CAD one.**

---

## 4. Acoustics: why the wall is 0.80 mm and why the land is flat

D11a settles the *part*: a bare Murata 7BB-20-3, Ø20.0 × 0.22 mm, bonded to the
inside of the shell and driven anti-phase from two SoC pins. It does not settle
the *structure*, and the structure is where the output comes from.

### 4.1 The land is flat because a curved one cracks the ceramic

The crown's outer surface is a spherical cap of R ≈ 92 mm, so its inner surface
is R ≈ 91.2 mm. Bonding a flat Ø20 bender to it means bending the bender to
that radius. The 7BB-20-3 is a 0.12 mm brass shim carrying a 0.10 mm PZT disc;
the laminate's neutral axis, weighting each layer by its modulus, sits **0.0944
mm** from the brass face, so the PZT's outer fibre is 0.1256 mm from it and the
strain on conforming is

> ε = y / R = 0.1256 / 91.2 = **0.1377 %**

against a tensile limit for hard PZT of about **0.1 %**. The bender would crack
on assembly. So the shell's **inside is a flat land, Ø21.20 at z = 6.550**,
while the outside keeps Apple's cap. This is not a compromise: a flat, thin,
stiff bond line is what a strain-coupled exciter wants, and it is repeatable in
production in a way a gap-filling adhesive wedge is not.

The cost is that the crown is thicker at the axis (1.430 mm) than at the land
edge (0.800 mm). That turns the acoustic architecture into the one every
loudspeaker uses: **a stiff piston (the Ø21.2 crown, driven in-plane by the
bender) on a compliant surround (the 0.800 mm annulus out to Ø25.75)**.

### 4.2 The wall thickness is chosen by the exciter's authority

An exciter that is far more compliant than the panel it is glued to cannot move
it. The measure is the ratio of flexural rigidities, computed in `design.py`
from the layer moduli:

| crown wall | D_shell (N·mm) | D_piezo / D_shell | reading |
|---|---|---|---|
| 0.60 mm | 0.0479 | 1.32 | best acoustically; below lane G's mouldable minimum |
| **0.80 mm** | **0.1136** | **0.662** | **chosen** |
| 1.00 mm | 0.2219 | 0.339 | |
| 1.20 mm (the FDM variant) | 0.3834 | 0.196 | the printed shell will be markedly quieter |

**0.80 mm is chosen** because the bender still has two-thirds of the crown's
own bending stiffness — real authority — and because 0.80 mm is the wall lane
G sourced as PC's practical minimum for this part ("toughness at 0.8 mm wall,
and a diaphragm stiff enough to radiate", research/07 §6.3). 0.60 mm is the
acoustic optimum and is left on the table deliberately; the first article is
what decides whether it moulds.

Outboard of Ø25.75 the wall steps to **1.20 mm**. That step is not decoration:
it is the **stiffening ring that terminates the diaphragm**, so the acoustic
boundary is a designed feature at exactly the diameter Apple's own "DO NOT
OBSTRUCT" callout gives, rather than wherever the skirt happens to stiffen.

### 4.3 What the design has to deliver, as a displacement

DULT requires **≥ 60 phon at 25 cm**. Between 2 and 5 kHz the ear is *more*
sensitive than at 1 kHz, so asking for 60 dB SPL there is asking for more than
60 phon — a conservative stand-in. Radiating as a monopole of the piston's area:

> x = √2 · p_rms · r / (π ρ f² S) = **0.410 µm** at 3600 Hz, 250 mm

Four tenths of a micron. A 20 mm bender does tens of microns free-air. **The
design is not displacement-limited**, which is the useful result: whatever
decides halo's loudness, it is not the actuator's stroke.

### 4.4 The sealed cavity is not the limiter either

The free air volume inside the puck, **measured** by subtracting every solid
from the product's envelope of revolution, is **1405 mm³** (an upper bound — it
includes the seam gap around the door, which is open to atmosphere). The air
spring behind a Ø21.2 piston is then γP₀S²/V = **12.6 kN/m**, which against the
bender's own 0.451 g resonates at about **840 Hz** — far below the 3.6 kHz drive
point, so at the design frequency the system is mass-controlled and the trapped
air is not what stops it.

### 4.5 And therefore: the SPL is CANNOT DETERMINE

Everything above says the mechanism is sound and nothing above says how loud it
is. Lane G's caveat stands verbatim: *"this is the one thing in this document
that has to be measured on real hardware before it is believed."* iFixit's only
lab figure for an AirTag is 78–80 dB at ~13 cm, and their finding that piezo
rivals were *"just as much, if not more, noise"* is the reason to expect this to
work — not proof that it does.

**Verdict on F3 (≥60 phon at 25 cm): CANNOT DETERMINE.** The test is lane G's
open item 6, and it is §9's first row.

---

## 5. The battery door, and the compliance argument

### 5.1 The mechanism

D3 and D13: a **press-and-twist bayonet, three tabs at 2, 6 and 10 o'clock**,
because it is the only 16 CFR 1263-compliant scheme that costs **zero** vertical
height. halo's realisation:

| feature | geometry |
|---|---|
| door tabs | three, 45° arc, Ø25.55 → **Ø26.60**, z 1.890 → 2.190, formed from the same 0.30 mm stock |
| carrier feet | three, 60° arc, R 12.90 → 13.40, bearing face at **z = 1.890**, body down to z = 1.290 |
| carrier legs | three, 60° arc, R 13.40 → **Ø27.84**/2, z 1.290 → 2.500, joining the feet to the carrier floor |
| entry windows | the three 60° gaps between the legs |
| **detent** | a **square** ridge on each foot, 4° of arc, **0.250 mm** tall, at the closed position's trailing edge |
| closing cam | a **12° helicoid** on each foot's leading edge, 1.50 mm of arc and 0.319 mm of drop, so the closing rotation lifts the tab onto the bearing face instead of butting into its corner. A helicoid is not a cecad primitive, so the model cuts it as **six steps of 0.053 mm**; the moulded feature is the true ramp |
| rotation to open | 60° |

The load path is: the contact springs push the cell **down**, the cell pushes
the door **down**, and the tabs bear **up** against the feet. Nothing else
retains the door, which is why the springs are a structural part and not just an
electrical one.

### 5.2 The compliance argument, and it is measured rather than argued

16 CFR 1263 / ANSI-UL 4200A require a **tool, or at least two independent and
simultaneous hand movements**. That is a claim about geometry, so `design.py`
measures it: it moves and rotates the real door solid against the real carrier
solid and reads the shared volume back out of the kernel. Five probes, and
**two of them must be non-zero** — a test that can only pass is not a test.

| probe | expected | measured |
|---|---|---|
| **A** closed, at rest | 0 mm³ — it fits | **0.0000** |
| **B** closed, dropped 0.3 mm | **> 0** — the feet retain it; it cannot fall out | **3.7114** |
| **C** twisted 10° with no press | **> 0** — the detent blocks rotation on its own | **0.2735** |
| **D** pressed 0.250 mm **and** twisted 10° | 0 mm³ — the two movements together free it | **0.0000** |
| **E** rotated into the entry windows and dropped | 0 mm³ — aligned with the gaps it comes out | **0.0000** |

**B + C + D is the compliance argument.** Rotation alone is refused by the
geometry — and because the detent is a *square* step rather than a ramp, it is
refused at **any** torque, not merely resisted. Pressing alone does nothing but
compress the springs. Only both at once opens it.

### 5.3 The forces

The three fingers are the spring. From the modelled geometry
(L = 6.074 mm, w = 3.60 mm, t = 0.15 mm, C5191, E = 110 GPa):

| quantity | value | note |
|---|---|---|
| spring rate, per finger | **1.491 N/mm** | k = 3EI/L³ |
| contact force at the closed position (δ = 0.400) | **0.596 N** per finger, **1.79 N** total | inside the usual 0.5–1.5 N band for a coin cell |
| bending stress there | **268 MPa**, 45 % of C5191's yield | |
| force with the door pressed 0.250 mm | **0.969 N** per finger, **2.91 N** total | |
| bending stress there | **436 MPa**, 74 % of yield | a transient, not a resting state |
| **press force to open** | **≥ 2.91 N** (0.30 kgf) | |
| **opening torque** | **≥ 13.4 N·mm** | friction only, μ = 0.35 assumed, on three tab/foot interfaces at R 13.15 |
| ... as a finger force at the door's rim | **1.05 N** | |

**Caveats, stated.** The spring rate is **calculated, not measured**: w/L = 0.59,
so the strip behaves partly as a plate and the real rate is up to ~12 % higher
(1/(1−ν²)). μ = 0.35 for PC on dry stainless is an **assumption**. And 16 CFR
1263 also requires the product to pass **abuse tests** — drop, torque,
compression — with the cell retained; those are physical and have not been done.
**Verdict on F12: the mechanism PASSES its geometric requirement; the standard's
test regime is CANNOT DETERMINE.**

### 5.4 The door is at cell potential, and that is safe

The door's inner dome bears on the cell's positive can, so the stainless floats
at +3 V. It is **not a circuit terminal** — all three contacts are on the
carrier, exactly as Catley found on the AirTag, and no current flows through the
door. There is no second exposed conductor anywhere on the outside of the
product, so no external short is possible. A 0.10 mm PET insulating disc under
the cell would remove even the question and costs 0.10 mm of the 0.542 mm of
slack in row 2; it is offered as an option, not taken as the baseline.

---

## 6. The sprung contacts

No coin-cell retainer fits (§2.2), so the contacts are three formed C5191
fingers, insert-moulded into three carrier spokes at 90 / 210 / 330°:

- an **arc cantilever**, 30° at R 11.60 — 6.074 mm of length inside a 26 mm
  ring, which a straight cantilever could not reach;
- **0.15 mm stock, 3.60 mm wide**. Width buys force without buying stress:
  σ = 1.5·E·t·δ/L² is independent of width, so the spring was widened rather
  than thickened to reach 0.6 N;
- a **Ø0.90 embossed dimple** at the tip, 0.100 mm proud, which is the actual
  contact and the reason row 4 of the stack is 0.250 and not 0.150;
- **two positive** on the cell's can rim at R 9.50, **one negative** on the
  negative face at R 6.00 — Catley's 2 + 1, all carrier-side.

In the model the fingers are **cut out of the carrier** with 0.020 mm of
clearance, because that is what insert moulding does: the metal displaces the
plastic. That is also why the interference check reads zero.

**Open:** the R 9.50 contact circle assumes the CR2032's positive can rim is
exposed outside its gasket from about Ø18.4 to Ø20.0. That is the standard
construction, but crimp geometry is per-vendor and it is a caliper job on the
cell actually sourced.

---

## 7. Sealing

IP67, and **nobody has published how the AirTag does it** (lane G open item 5).
So this is halo's design, not a copy.

- **The door:** a **radial** seal — a moulded-in-place LSR 70 Shore A bead on
  the carrier's Ø24.15 land, free radial section 0.50 mm, compressed into the
  0.40 mm gap to the door's Ø24.95 bore: **20 % squeeze**, measured off the
  modelled gap. Radial on purpose, because the contact springs push the door
  *outward* — an axial face seal at this interface would be unloaded exactly
  when it is needed. Moulded in place rather than an O-ring in a groove because
  the seal station is only 0.39 mm tall and no standard groove fits.
- **The parting line:** the carrier's Ø27.60 wall is bonded into the shell's
  Ø27.90 bore over 2.31 mm of height with a 0.15 mm gap — **198 mm² of bond
  area**. The same bead is the structural joint and the seal, which is what
  iFixit found on the real product ("aim between the three clips so you only go
  through glue").

**Verdict on IP67: CANNOT DETERMINE.** It is an IEC 60529 test on a built puck.
iFixit's own counterexample is the reason not to claim it: Samsung's SmartTag
has "the thickest adhesive barrier" of any tag they opened and carries no IP
rating at all.

---

## 8. Tolerances and the printed variant

### 8.1 Moulded

| fit | nominal | clearance | why |
|---|---|---|---|
| carrier wall Ø27.60 in shell bore Ø27.90 | — | 0.150 mm radial | adhesive gap; a structural epoxy wants 0.10–0.20 |
| door wall Ø25.55 in the shell's Ø27.90 bore | — | 1.175 mm radial | the tabs and the seam gap live here |
| door bore Ø24.95 on the carrier's Ø24.15 land | — | 0.400 mm radial | the seal's compressed section |
| tab Ø26.60 to leg R 13.40 | — | 0.100 mm radial | the tabs must rotate inside the legs |
| tab top (pressed) 2.440 to carrier floor 2.500 | — | 0.060 mm | the clearance the press probe measures |
| PCB Ø26.00 in the carrier rim Ø26.20 | — | 0.100 mm radial | |
| bore draft | 1° | — | straight pull |
| edge break | 0.05 × 45° | — | Apple's own callout |

**Thinnest section, measured** (`cecad.inspect.thinnest_wall_detail`, a ray
probe over the finished solid): **0.698 mm**, at (−7.01, −12.62, 2.31) — the
shell's bore lip at the parting face, which is designed at 0.52 mm. The two
numbers differ because the probe's sample spacing on this part is 0.671 mm and
it reports that limit rather than hiding it: a feature narrower than the step
can be missed, and 0.698 is the thinnest section the probe actually found. The
designed minimum stands at 0.52 mm and it is a lip, not a wall.

### 8.2 The FDM prototype variant

`part:halo-shell-top-fdm` and `part:halo-battery-door-fdm` are built from the
same parametric source with `fdm=True`:

- **the shell's wall is 1.200 mm** — three perimeters at a 0.4 mm nozzle, which
  is the real floor for an FDM shell;
- **the door's wall is 0.500 mm, and NOT 1.200**, because a measurement said so.
  Printed at 1.200 the door's bore comes out Ø22.95 and buries itself 0.60 mm
  radially inside the carrier's Ø24.15 seal land — the exported STL read back
  **25.92 × 26.17 × 3.090 mm** against the moulded **26.08 × 26.37 × 2.190**,
  and it could not be assembled at all. 0.500 mm is one 0.4 mm extrusion at
  125 % line width, which a Bambu prints, and it leaves 0.100 mm radial on the
  land. `check_fdm_variants()` now measures the printed door and the printed
  shell against the **same carrier** on every build; nothing did before, which
  is why this shipped once;
- **the door's tabs stay 0.300 mm thick even on the printed part.** z 1.890 →
  2.190 is all the room the carrier's floor at 2.500 leaves once the door's
  0.250 mm of press travel is taken out of it. The tab's axial budget belongs
  to the bayonet, not to the printer;
- **FDM_FIT = 0.200 mm, applied in the direction each feature errs.** An
  internal feature prints undersize, so the shell's bore is **modelled 0.200 mm
  oversize** (Ø28.10) to measure Ø27.90; an external feature prints oversize,
  so the door's wall and its three tabs are **modelled 0.200 mm undersize**
  (Ø25.35 and Ø26.40) to measure Ø25.55 and Ø26.60. Both are in `design.py`,
  not only in this paragraph;
- **the crown's outer profile is deliberately NOT compensated.** It is a free
  surface and it will print up to ~0.15 mm over Ø31.874 — which the AirTag
  holder ecosystem takes, because holders are cut with +0.15 to +0.30 mm of
  margin (research/07 §5.1). Compensating it would make the *model* wrong for
  anything but one printer's flow;
- suggested process: 0.12 mm layers, **no brim**.

**A printed shell will be markedly quieter** — 1.20 mm of PC is 3.4× the
bending stiffness of 0.80 mm and the exciter authority falls from 0.66 to 0.20
(§4.2). The printed variant exists to exercise **fit and mechanism**, never
loudness. **Nothing has been queued to any printer.**

---

## 9. What only a physical sample can settle

Lane G's six open measurement tasks (research/07 §8), plus what this lane adds.

| # | question | what a sample settles | what halo did instead |
|---|---|---|---|
| 1 | **the magnet** — Ø, thickness, grade, pull force | nothing measurable is published; iFixit only photographs it | **deleted.** D11a replaces the moving-coil motor entirely, so halo has no magnet |
| 2 | **the voice coil** — bobbin Ø, wire gauge, turns, DCR | same | **deleted**, same reason |
| 3 | **the PCB outline and its central aperture**; layer count off a cross-section | Apple's board is "≤ 26 mm" by inference only; nobody has published a caliper reading | halo chose Ø26.00 × 0.60 mm, 4 layers, **no** central aperture — the aperture existed to pass Apple's magnet |
| 4 | **the white shell's wall thickness** at apex, equator and lip | the one number that would most change §4 | halo chose 0.800 / 2.01 / 1.430 mm from the exciter-authority argument, not from a measurement |
| 5 | **the steel cover's thickness and alloy** | "polished stainless steel" is all anyone has written | halo chose 0.30 mm 301 full hard |
| 6 | **the door seal** — gasket, cross-section, groove, or only adhesive | the single public statement about it is a low-trust Taobao page | halo designed a 20 %-squeeze radial MIP bead, §7 |
| **7** | **(new) the two plan-view callouts Ø27.90 and Ø27.84** | the CC BY half-section DXF omits both circles; lane G rates the interpretation *medium*. A donor sample sectioned through a bayonet tab settles what they are | halo reads them as the shell's bore and the carrier's leg circle, §3 |

And four verdicts this lane cannot close from geometry:

| what | verdict | the test |
|---|---|---|
| **SPL, ≥60 phon at 25 cm (SPEC F3)** | **CANNOT DETERMINE** | build the shell, bond a 7BB-20-3 to the flat land, measure dB(A) at 10 cm against a reference AirTag (lane G item 6) |
| **IP67 (SPEC §4)** | **CANNOT DETERMINE** | IEC 60529, 1 m for 30 min, on an assembled puck |
| **the contacts' spring rate and the door's opening force** | **CANNOT DETERMINE** | a force gauge on three stamped fingers, and a torque gauge on the door. The numbers in §5.3 are calculated |
| **antenna performance behind this carrier** | **CANNOT DETERMINE** | ce-rf's lane (SPEC §5 E4/E5); this lane guarantees only the geometry and the metal inventory |

---

## 10. Mass

The built assembly measures **7.8 g** against the AirTag's 11 g (gen 1) and
11.8 g (gen 2). The difference is almost exactly Apple's motor: a magnet, a
copper coil and the adhesive that holds them. halo is lighter because it is
doing the same job with a 0.45 g bender.

| part | measured mass |
|---|---|
| CR2032 | 3.0 g |
| shell (PC) | 1.5 g |
| door (301 SS) | 1.4 g |
| carrier (LCP) | 0.7 g |
| PCB blank (FR4, no copper, no components) | 0.6 g |
| bender | 0.5 g |
| three contacts | 0.1 g |
| seal | < 0.05 g |
| **assembly** | **7.8 g** |

The board's components and copper are not in this figure; they are the
electronics lane's, and they are the gap between 7.8 g and 11 g.

---

## 11. Files

| what | where |
|---|---|
| the ONE parametric source | [`design.py`](../design.py) |
| the blueprint (P12) — the stack budget as ten space claims | `ce-assemblies/halo-puck/current/blueprint.json`, `out/mech/halo-puck-blueprint.svg` |
| the assembly | `ce-assemblies/halo-puck/` — `assembly.json`, `bom.json` (8 rows), `joints.json` (5 rows) |
| the parts | `ce-parts/halo-*/` — ten folders, each with `cad/part.py`, `cad/interfaces.json`, `mech/mech.py`, `evidence/ledger.jsonl` |
| the connection kinds these parts join through | `ce-connections/` — eight folders; five grade themselves CANNOT DETERMINE and say why |
| renders, STEP, STL | `out/mech/` |
| **the section that shows the stack** | `out/mech/halo-puck-section-front.png` (square on) and `-quarter.png`, drawn by [`tools/section_view.py`](../tools/section_view.py) — a render-only pass, seconds instead of minutes |
| the measured verdicts, as data | `out/mech/verdicts.json` |
| the evidence | every folder's `evidence/ledger.jsonl` — append-only, and it carries the two `failure` rows as well as the passes |

**What `CE_TRIAD_ROOT=$PWD triad check --all` returns, and why it is not all
PASS: checked 19 · PASS 10 · CANNOT DETERMINE 9 · FAIL 0.** Five of the nine
are connection folders that grade **themselves** CANNOT DETERMINE — adhesive
strength, the seal, insert retention, solderability and contact force are all
untested, and TRIAD.md forbids a reader grading a folder better than it grades
itself. The other four carry a **superseded** ledger row: `out/mech/verdicts.json`
was rebuilt when two checks were added, and the standard's rule is to append a
new row naming the artifact rather than edit the old one, after which the old
row is reported as history and never deleted. Both are the system working, not
the design failing.

A note on the section renders, because it cost a wasted pass: the cut must be
kept on the **far** side of the camera (`section=("y", 0.0, "max")` viewed from
the front). Keep the near half and the camera sees an intact outside face — it
renders perfectly and shows nothing.

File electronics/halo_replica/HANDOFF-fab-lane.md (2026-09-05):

# Fab lane — handoff, paused 2026-09-05

**Paused at Leif's instruction; microduck is the priority.** Nothing here is
abandoned and nothing is mid-edit. Every process this lane started is stopped.

## Where to resume

```bash
cd ~/dev/ce-workshop/ce-designs/halo
bin/halo status          # what exists, and is anything stale
bin/halo doctor          # is everything reachable
bin/halo all             # sheet → board → DRC → route → render → pack
```

Exit code **is** the verdict: `0 PASS · 1 FAIL · 2 CANNOT DETERMINE`.
Stages, and the four traps the pipeline prevents: `WORKFLOW.md`.

## Two boards, both real, both committed

| | `fab/` | `apple/` |
|---|---|---|
| outline | Ø30 mm disc | **Apple's measured 75-point profile, 24.6624 × 24.7263 mm** |
| DRC errors | **0** | **0** |
| nets bound | 63 / 63 | 63 / 63 |
| routed | **yes** — 565 tracks, 58 vias, 4 layers | **not yet** |
| unconnected | **5** | 112 (unrouted) |
| package | `halo_replica_jlc_0.8mm.zip`, `z_fabcheck` PASS | not cut |

`apple/` is the closer answer to "the Apple replica board" and is the one to
finish. It is placed, DRC-clean and net-bound; **it has never been routed.**

## The single next action

```bash
~/dev/ce-fleet/bin/heavy && \
ce-pcb/bin/route electronics/halo_replica/apple/out/halo_replica_apple.kicad_pcb \
                 --passes 30 --timeout 1200
```

Then `bin/halo render` and a package. Expect it to route: the fab board, same
parts and same rules, went 112 → 5 in 251 s once its placement was correct.

## What is NOT true, and must not be claimed

- **Nobody has built one.** Neither board has been fabricated or powered on.
- **`fab/` has 5 unconnected nets.** Four are U1 pads — QFN-48 escape routing.
  30 and 120 passes both stop at exactly 5, so *this router is finished, not
  slow*. Fanout gets 5 → 4 and introduces 13 DRC errors: net worse.
- **The assembly is not orderable.** 5 real LCSC codes against 20 blank. A blank
  is an **honest refusal** naming an MPN a human must look up — JLC's importer
  reads that column literally and silently drops any line it cannot match.
- **0.4 mm is not orderable at 4 layers** (measured live in JLC's configurator,
  with both controls). Order the **0.8 mm** zip.
- **`apple/` swaps four connectors to 1.27 mm SMD** — pin counts unchanged, so
  nets are untouched, but it is a departure from the fab sheet.

## The three findings worth carrying, whatever happens to this board

1. **An optimiser returning the same score repeatedly is not slow — it cannot
   move.** Four identical freerouting passes were read as "needs more passes"
   and cost 3502 s for no output. The board was unroutable because **33 of 45
   parts were not on it.** Same rule across runs: 30 and 120 passes giving
   identical results means finished.
2. **A check that shares a frame, an input, or an assumption with the thing it
   checks cannot fail on it.** A keep-in test in the bug's own coordinate frame;
   a courtyard test measuring relative distances, exactly invariant under the
   translation that *was* the defect; an outline check counting ops where a
   correct circle and two disjoint arcs both give 2.
3. **A geometry question goes to a geometry engine.** Three text parses of a
   footprint agreed to 0.01 mm and all three were wrong — arc *control points*
   are not arc *extent*. `pcbnew` disagreed and was right. Agreement between
   methods that share a blind spot is one measurement, not three.

Evidence: `evidence/E09`, `evidence/E10`. Tools: `ce-pcb/cepcb/place.py`,
`tools/z_fabcheck.py`, `tools/g_package.py`, `tools/g_route_once.sh`.

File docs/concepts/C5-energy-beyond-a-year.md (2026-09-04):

# C5 — Energy beyond a year

*Researched 2026-09-05 from vendor datasheets, not from marketing pages.
Three branches were costed: indoor solar, supercapacitor hybrids, and simply a
bigger cell. One wins outright and the other two fail for reasons worth keeping.*

## The anchor

halo's "about a year on a CR2032" implies **≈26 µA average at 3.0 V**
(225 mAh ÷ 26 µA = 8,654 h). Worth noting on its own: our component model
predicts 6.0 µA at a 5-second advertising interval and 9.9 µA at 2 seconds, so
**about 16 µA of the budget is overhead nobody has named yet.** That is a
measurement debt, not an energy problem.

## Branch C — a bigger cell. VERDICT: PROVEN, and it wins by a wide margin

| swap | height cost | energy | life at 26 µA | pulse capability |
|---|---|---|---|---|
| CR2032 (today) | — | 225 mAh | **0.99 yr** | 400 Ω, ~6.8 mA |
| **→ CR2450** | **+1.8 mm** | 620 mAh | **2.72 yr** | **300 Ω, 9.0 mA** |
| → CR2477 | +4.5 mm | 1000 mAh | **4.39 yr** | — |

Both fit the Ø31.87 mm face easily at 24.5 mm diameter, so this is purely a
thickness trade. No power-management chip, no photovoltaic cell, no antenna
re-solve, no acoustic compromise, no charge-voltage clamp, no cycle-life
question — about **$0.50 of parts** instead of about $6, and the **pulse
capability improves** rather than staying flat, which matters because pulse
droop at end of life is what the coin-cell model already tracks.

## Branch A — indoor solar. VERDICT: FAILS on this enclosure

Not on physics. **On our own keep-outs.** The face is 7.98 cm², but the inner
Ø25.75 mm is Apple's "do not obstruct" acoustic path, leaving an annulus of
**2.77 cm² — and that annulus lies entirely inside the Ø37.31 mm no-metal
antenna keep-out**, where the Bluetooth antenna and the NFC coil are already
fighting for room. A photovoltaic cell is metal in that zone.

Measured yields, triangulated across three vendors at 200 lux: bare cells reach
7.3–9.0 µW/cm², **packaged modules deliver 3.0–5.4**, and the round parts that
actually fit a disc manage **1.3–2.6**. On the real 2.77 cm² at 200 lux for
12 hours a day, net of the harvester chip's own 488 nA quiescent draw, the
result is **0.7 to 2.7 µA equivalent against a 26 µA draw — 3 to 14 percent**.

Break-even at even 10 µA needs **about 700 lux for 12 hours every day**. Office
task lighting is 500 lux; a living room is 50–150; a bag, a pocket or a car
footwell is **zero**. A tracker lives in the dark.

**The comparison that settles it:** every self-powered Bluetooth device that
actually works ships **6 to 11 times more collector area** than halo's entire
usable annulus — EnOcean's sensor needs 200 lux for 6 hours a day across about
16 cm², Minew's tag wants 400–1000 lux across 31 cm². The only solar Find My tag
on the market, UGREEN's, has a panel that **cannot recharge its battery** — a
reviewer who opened it found the panel genuinely connected, which he noted is
not always true, but it only extends life rather than sustaining it.

## Branch B — supercapacitors. VERDICT: REFUSED, with one narrow exception

**A thin supercapacitor leaks 1 to 2 µA — which is 50 to 150 percent of the
entire harvest.** One holds 0.36 J and **self-empties in 43 hours with no load
at all**. A rechargeable manganese-lithium coin of the same footprint holds
59 J, 165 times more, and loses about 2 percent per year, or 13 nanoamps.

So if a harvester is ever built here it stores into a rechargeable coin, never a
supercapacitor. The one defensible supercapacitor role is a **sub-second
transmit-pulse buffer** — 11 millifarads in a 3.2 × 2.5 × 0.9 mm chip holds
about 2,100 transmit bursts but only **8 minutes** of system draw. That is a
decoupling part, not a storage part.

**And a hard rule for any future harvester:** you cannot push harvested current
into a primary lithium cell. Energizer caps reverse charge at **1 µA** on both
the CR2032 and CR2450. A harvester needs its own rechargeable element and diode
isolation — which is exactly what one power-management chip's primary-cell
path-management block exists to do, and the only topology where a harvester and
a CR cell coexist legally.

## What this forces

The energy question is a **thickness decision**, not a technology decision. It
belongs to Leif: today's 8 mm puck and one year, or a 9.8 mm puck and nearly
three years for fifty cents. Everything else on this page is the evidence that
the clever options are worse than the obvious one.

## Also found

**There is no open-source solar Bluetooth tracker.** Eleven repository searches
returned nothing — "solar airtag" returns zero results. halo would be first, if
it were worth being first at, and this research says it is not.

**A widely repeated firmware claim is wrong.** The "almost 3 years on a CR2032"
figure carried by two popular Find My firmware repositories rests on a handheld
multimeter measurement whose burden voltage made it the wrong instrument. The
corrected figure, taken with a proper power analyser, is **2× higher current**:
7.60 µA with an external crystal, 9.21 µA on the internal oscillator — so the
crystal is worth 17 percent of the budget. One real elapsed-time datapoint
exists: a user replaced a cell after **four years** of actual service.

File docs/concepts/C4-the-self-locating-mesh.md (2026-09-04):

# C4 — The self-locating mesh

*Researched 2026-09-05. Every number below is either quoted from a primary
source that was fetched and read, or **measured on this machine** and marked so.
This is the concept that serves Leif's stated reason for the project: sensors
that know where they are relative to each other, for the digital twin.*

## Verdict: PROVEN, with one hard design rule

The algorithm is settled, it fits on the chip halo already carries, and the
accuracy at building scale is good. But there is a threshold below which the
answer is not merely worse — it is **wrong by metres**, and the design must
refuse rather than publish through it.

## The result that matters

**Measured here**, 3D, nodes uniform in a 30 × 30 × 10 m box, classical
multidimensional scaling to initialise then Levenberg–Marquardt on the range
residuals, aligned to truth with reflection allowed so these are true
anchor-free relative errors:

| tags | range error σ | mean degree | **RMS position error** | Cramér–Rao bound |
|---|---|---|---|---|
| 10 | 10 cm | 9 | 15.8 cm | 15.8 cm |
| 20 | 10 cm | 19 | 9.9 cm | 10.4 cm |
| **50** | **10 cm** | 49 | **6.1 cm** | 6.1 cm |
| 50 | 30 cm | 49 | **18.3 cm** | 18.3 cm |

Two things to take from this. **The estimator hits the Cramér–Rao bound
exactly**, so no semidefinite relaxation is needed anywhere in the loop —
multidimensional scaling plus Levenberg–Marquardt is provably as good as it
gets. And **more tags make every tag better**: fifty tags at 10 cm ranging land
at 6.1 cm, better than the ranges themselves, because averaging over a denser
graph beats the individual measurement.

Plan against **σ = 30 cm**, which is Silicon Labs' measured figure for their
own Channel Sounding silicon, rather than the Bluetooth SIG's ±20 cm claim. At
fifty tags that still gives **18 cm relative accuracy across a 30 m building**.

## The hard rule: density, not precision, decides whether it works

Range-limited to 15 m, same setup:

| tags | mean degree | RMS error | bound |
|---|---|---|---|
| 10 | 3.6 | **508 cm** | 82 cm |
| 20 | 7.7 | **310 cm** | 173 cm |
| 50 | 21.0 | **10.4 cm** | 9.9 cm |

A sparse network is not "less accurate". It is **five metres wrong**, because
the range graph is not globally rigid and sub-clusters **flip** about a mirror
plane. This was cross-checked against rigidity theory rather than guessed: the
Fisher information matrix of a rigid framework has rank exactly
`n·d − d(d+1)/2`, and the failing rows are precisely the rows where the measured
rank fell below it. A tag with three neighbours in three dimensions sits on a
mirror plane and will flip.

**The rule the firmware must enforce: in 3D, require mean degree ≥ 10–12 before
publishing any position, and return CANNOT DETERMINE below it.** Global rigidity
is checkable in polynomial time by a randomised algorithm (Gortler, Healy and
Thurston, *American Journal of Mathematics* 132, 2010: a generic framework is
globally rigid **if and only if** it has a stress matrix whose kernel has the
minimum possible dimension `d+1`). So the network can *know* whether its own
graph admits a unique answer, before it claims one. **Build that check.**

## Where the computation goes

**Measured** working-set memory for the matrix-free normal-equations solve:

| case | total |
|---|---|
| 2D, 50 nodes | 58.8 KB |
| **3D, 50 nodes** | **107.8 KB** |
| 3D, 20 nodes | 17.3 KB |

The nRF54L15 carries **256 KB of RAM** and a Cortex-M33 with a floating-point
unit at 128 MHz, so 3D with fifty nodes fits with about 150 KB to spare. The
whole solve is roughly 15 MFLOP, estimated at **0.4 to 0.6 s** on that part —
an estimate from measured iteration counts and a stated throughput assumption,
**not a benchmark**; flashing it to real silicon would settle it.

**Recommendation nonetheless: the tag computes nothing global.** It ranges,
timestamps and reports. The global solve is trivial for a phone or a hub, and
the hub is the only place that can see the whole graph to run the rigidity check
and reject outliers. Keep an on-tag solver only as a degraded mode with no hub
reachable, capped at about twenty nodes in 3D.

## The architecture that makes it scale

Standard Channel Sounding is **point-to-point**: the Bluetooth SIG has adopted a
Ranging Service and Ranging Profile, both version 1.0, and both describe two
devices. Nordic's own sample is one initiator and one reflector. Neither the SIG
nor any vendor publishes a multi-node ranging profile.

The nearest published work is aimed squarely at this problem and runs on **the
exact chip halo uses**: Schex, Cremer and Dettmar, *"Connectionless Bluetooth
Channel Sounding via PAwR for Scalable and Energy-Efficient Ranging"*
(arXiv:2605.17094). It combines the Channel Sounding test command with Periodic
Advertising with Responses so that no per-pair connection is needed at all; each
device derives its role, its channel sequence and its response slot from its own
index and a shared assignment matrix. Measured on an nRF54L15: **40–48 % less
steady-state charge** than a connected baseline, **98 %** less per-switch
overhead, up to **88 % lower total charge over 24 hours** under per-cycle partner
switching, and a projection of **up to 14,080 active devices per advertising
train**.

That dissolves the per-pair connection limit that would otherwise cap a tag at a
handful of peers — which is exactly what is needed to reach the mean degree of
10 to 12 the rigidity result demands.

## Two things this forces into the hardware

1. **Put an inertial sensor on the tag.** Orientation is a first-order error
   source in Channel Sounding: a 2026 study reports a **74.6 % reduction in mean
   absolute error** from a model trained on inertial-derived orientation. A tag
   on a moving asset tumbles. halo already carries an accelerometer for the
   anti-stalking requirement, so this is nearly free — but the ranging firmware
   must actually use it.
2. **Report raw ranges with quality metadata, never solved positions.** No tag
   sees the whole graph, and the three estimators Nordic's own sample computes
   disagree — its log shows 1.04, 1.58 and 3.08 m for one measurement by
   inverse-FFT, phase-slope and round-trip-time respectively. Use the
   phase-based pair; treat round-trip time as a coarse ambiguity resolver only.

## The opportunity

A search of open repositories returned **no established open-source anchor-free
range-network solver**. GTSAM is the closest usable foundation — 3,666 stars,
BSD licensed, with a first-party range factor and incremental solving — but the
anchor-free network solver on top of it does not exist. halo would be writing
it, and the measurements above say multidimensional scaling plus
Levenberg–Marquardt is sufficient.

## What is not settled

The Cramér–Rao formula from the most-cited paper in this area could not be
quoted, because it is paywalled and the author's mirror refuses connections; the
bound used here comes from a different paper that was read in full. The absolute
figures behind the orientation result are in a PDF only the abstract of which
was fetchable. And the on-chip solve time is an estimate, not a benchmark.

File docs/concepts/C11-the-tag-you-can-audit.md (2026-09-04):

# C11 — The tag you can audit — open debug, reproducible firmware, and why it costs almost no secrecy

*Nobody can prove what an AirTag does. A halo whose firmware hash an owner can verify against a published build is a procurement answer no commercial tracker can give — and with pre-generated keys it gives away almost nothing.*

**Verdict: PLAUSIBLE** — Every component is established: the debug header exists on the board as Tag-Connect pads, the key architecture that makes an open debug port nearly free is documented in research/02 section 9, and reproducible builds are ordinary practice. What has not been done is the analysis of exactly what an attacker gains from a flash dump under each key scheme, and that analysis — not a bench — is the work.

Family `trust` · value 3/5 against effort 1/5 · part of the halo concept portfolio, `docs/concepts/README.md`.

## What it is

D6 already lists 'a documented debug header' as one of the five things halo offers that nothing on sale does: certified tags from eufy and Motorola ship with debug pads on the board, undocumented. halo's are a header with a pinout.

The concept is to take that further and make it a stated property: a published, reproducible firmware build, a hash an owner can compute themselves, and a debug port that lets them dump the part and compare. For anyone deploying tags into a facility — which is Leif's use — 'prove this device only does what it says' is a procurement requirement, and no commercial tracker can meet it at any price.

The obvious objection is that an open debug port leaks the keys. That objection is weaker than it looks, and the reason is architectural. In the OpenHaystack scheme the tag holds a list of PUBLIC keys, 28 bytes each; the private key stays with the owner. A flash dump therefore does not reveal a secret that lets anyone read the tag's location reports. What it does reveal is the tag's FUTURE advertisements, which lets whoever has the dump recognise that tag later — but whoever has the dump is holding the tag.

The alternative architecture, on-device derivation from a master secret, is where an open port really does cost something: it hands over the master and with it every past and future key. So this concept is also a fork in the firmware design, and it is worth taking the fork deliberately rather than by accident.

## Why it beats the alternative

Against a certified commercial tag: those bind you to a vendor app and, on the certified path, to a per-unit Apple Token burned into flash at the factory. There is no version of them you can audit, and no version whose keys are yours.

Against 'open source' claimed on a repository page: a published source tree proves nothing about the part on your desk. A reproducible build plus a readable port is the difference between claiming and demonstrating, and it is a difference a purchasing department understands.

Against Apple: an AirTag's firmware was dumped once, by voltage-glitching APPROTECT, by a researcher. That is the state of the art for auditing an AirTag. It is not a procurement answer.

## The numbers

| quantity | value | where it comes from |
|---|---|---|
| Debug access already on the board | **SWD on Tag-Connect pads, zero vertical height** | electronics/halo_rev_a/schematic.py header, delta D-8 |
| Storage per pre-generated advertisement key | **28 bytes** | macless-haystack flashing instructions, quoted research/02 section 9 |
| How far 500 keys go | **14 kB of flash; about 10.4 days at 30 min rotation, 5.2 days at 15 min** | research/02 section 9, verified arithmetic on verified parameters |
| Free NVM on the chosen part | **1 MB total, 13,164 bytes used** | nRF54L10; SPEC.md section 2a measurement |
| What an AirTag flash dump costs today | **a voltage-glitching attack on APPROTECT** | research/01 section 7.3 |

## The evidence

| claim | source | date | confidence |
|---|---|---|---|
| Certified commercial tags ship with undocumented debug pads; halo's are documented | DECISIONS.md D6 point 3, from lane D's FCC exhibit reading | 2026-09-03 | primary |
| OpenHaystack-style tags hold public keys only, 28 bytes each, and nRF firmwares are patched at the OFFLINEFINDINGPUBLICKEYHERE! marker | research/02 section 10.1 item 4 | fetched 2026-09-03 | primary |
| The AirTag's nRF flash was dumped by glitching APPROTECT; this is the only known route | research/01 section 7.3 | 2026-09-03 | primary |
| halo's firmware occupies 13,164 bytes of flash and 704 bytes of RAM with all three protocol layers resident, so a reproducible build is a small artifact to verify | SPEC.md section 2a; DECISIONS.md D18 | 2026-09-04 | primary, measured |
| The licence split already commits the firmware to AGPL-3.0-or-later, which obliges source availability anyway | DECISIONS.md D4 | 2026-09-03 | primary |

**What is NOT established here, stated so nobody inherits it as a fact:**

- The exact attacker gain from a flash dump under each key scheme. The claim that pre-generated public keys leak 'only future advertisements' is reasoning from the protocol, not a result anyone published. Settle it by writing the threat model down explicitly and having it read by someone who did not write it — this is a paper exercise, not a bench one, and it belongs beside docs/ANTI-STALKING.md.
- Whether the nRF54L10's build is byte-reproducible under Zephyr with the current toolchain. Nothing in this repository has tried. Two builds on two machines and a diff would answer it in an hour.

## What it costs

| dimension | cost |
|---|---|
| money | $0.00. The pads are already on the board and cost no height. |
| current | 0 uA. Leaving APPROTECT open does not draw current. |
| size | 0 mm. Tag-Connect needs no connector. |
| complexity | Low in hardware, real in process: a reproducible build needs pinned toolchains and a published recipe, and a threat model needs writing. The cost is discipline, not engineering. |

## What it would break in the current design

- It forecloses the on-device key-derivation architecture, or at least makes choosing it a decision with a stated cost. Pre-generated keys are flash-hungry and have a bounded lifetime before wrap-around; on-device derivation is unbounded but puts a master secret on a part with an open port. research/02 section 9 calls this the single biggest firmware-architecture question in the project, and this concept is one of the two things that should decide it.
- It sits awkwardly beside DULT's identifier gate. DULT section 3.15.3 requires a physical mechanism before Get_Identifier will answer, precisely so a tag cannot be silently interrogated. An open SWD port bypasses that — but so does a screwdriver, and DULT's threat model assumes the attacker does not have the device in hand.

## The smallest experiment that would settle it

Build the current firmware twice, on two machines, with a pinned toolchain, and diff the two ELF files byte for byte. If they differ, find out where and whether it is a timestamp. That one command answers whether 'verify it yourself' is a claim halo can make at all, and it costs an hour. The threat model is the second half and it is writing, not measuring.

---

Generated from `spec/concepts.json` by `tools/gen_concepts.py` on 2026-09-05. Do not edit this file; edit the JSON.

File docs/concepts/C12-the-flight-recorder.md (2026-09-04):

# C12 — The flight recorder — an on-tag event log, read at an NFC tap

*An AirTag remembers nothing. A halo has 1 MB of NVM and uses 13 kB of it, so it can keep the last several thousand motion and ranging events and hand them over when somebody taps it.*

**Verdict: PLAUSIBLE** — The storage exists and is measured, the sensor and the ranging that would fill it are already specified, and the NFC peripheral that would read it out is on the die. What is not established is the write energy and the NVM endurance under this write pattern, and those two numbers decide whether the log is a feature or a battery bug.

Family `telemetry` · value 4/5 against effort 2/5 · part of the halo concept portfolio, `docs/concepts/README.md`.

## What it is

Find My answers 'which city block, about half an hour ago, if a stranger walked past'. In a workshop, a plant room or a field it answers nothing at all, forever, because nobody walks past. In exactly those places the tag itself still knows things: it felt motion, it ranged to its neighbours, its cell sagged.

The concept is to write those events down. A record of {timestamp, event type, peer id, range, quality, orientation} is about 16 bytes. The nRF54L10 has 1 MB of non-volatile memory and the whole firmware occupies 13,164 bytes of it, so the free space holds tens of thousands of records with no part added and no BOM line.

Reading it back has two routes that both already exist on this board. The DULT-mandated NFC tap is the interesting one: a phone taps the tag and gets a URL, and DULT's own format already carries optional parameters. The SWD pads are the other, for a maintenance visit.

For a digital twin this is the difference between a location and a history. 'This pallet was stationary until 14:32, then moved, and was 2.1 m from sensor 7 when it stopped' is a record no tracker on the market produces, because none of them have anywhere to put it.

## Why it beats the alternative

Against streaming everything to a gateway: no gateway. Against streaming over the crowd network: C3's channel is three bits per fifteen minutes, which is a state, not a history.

Against a separate data logger: the storage is already bought. D-7 deleted the SPI NOR flash from the board and the reason was a rail mismatch, not a lack of need; the SoC's own NVM is what replaces it, and it costs nothing.

Against Apple: an AirTag has no log, no readout and no API. This is a capability gap, not a quality gap.

## The numbers

| quantity | value | where it comes from |
|---|---|---|
| NVM on the part, and how much the firmware uses | **1 MB total, 13,164 bytes used (1.27 %)** | SPEC.md section 2a, measured on nRF54L10 |
| Records that fit, at 16 bytes each, in half the free space | **about 32,000** | [derived] (1,048,576 - 13,164) / 2 / 16 |
| Proposed record shape, already specified for the uplink | **{tag_id, peer_id, t_utc, method, range_mm, sigma_mm, quality, rssi_dbm, n_steps} ~ 16 bytes** | research/08 section 11.3 |
| Motion sampling rate DULT already mandates | **10 s at rest, 0.5 s once moving** | draft-ietf-dult-accessory-protocol-00 Table 17 |
| The NFC readout channel that already has to exist | **the SoC's own NFC-A peripheral on two pins, emulating a read-only Type-4 tag** | SPEC.md section 3; research/01 section 4 |

## The evidence

| claim | source | date | confidence |
|---|---|---|---|
| The firmware uses 13,164 bytes of flash on a 1 MB part, so the space is free and measured rather than assumed | SPEC.md section 2a; DECISIONS.md D18 | 2026-09-04 | primary, measured |
| The SPI NOR flash was deleted from halo_rev_a for a rail mismatch (GD25LQ32E is a 1.65-2.0 V part on a raw 3.0 V cell), not because logging was unwanted | electronics/halo_rev_a/schematic.py delta D-7 | 2026-09-04 | primary, source read locally |
| Tags should report raw ranges with quality metadata rather than solved positions, and the record shape is already drafted | research/08 section 11.3; DECISIONS.md D12 | 2026-09-03 | primary |
| DULT's NFC payload is a URL with optional parameters (b battery, bt MAC, fv firmware version) beside the required pid and e | draft-ietf-dult-accessory-protocol-00 section 3.15.5 | fetched 2026-09-03 | primary |
| Find My cannot supply a history at room scale: mean raw report error ~100 m, median 26 min latency, and zero reports where nobody walks past | PETS 2021 Tables 5-7; research/02 section 10.4 | fetched 2026-09-03 | primary |

**What is NOT established here, stated so nobody inherits it as a fact:**

- The energy of one NVM write on the nRF54L10 and the endurance of the RRAM/flash under a write-every-30-seconds pattern. These are the two numbers that decide the whole concept and neither is in this repository. Settle both by opening the nRF54L10 product specification's non-volatile memory chapter — write current, write time, and the endurance figure — and multiplying out against the 4.2506 uA baseline. If a write costs more than a few microjoules, the log has to batch in RAM and flush rarely, which is a firmware design, not a blocker.
- Whether the DULT URL is the right readout channel or whether a proprietary NDEF record beside it is cleaner. DULT says the URL SHALL be hosted by the network provider, which halo is not — this interacts with the open Network ID question in D19 and should not be resolved casually.
- Whether the NFC field alone can power a readout with the cell dead. Some tag ICs harvest enough from the reader field to answer; whether the nRF54L's NFC-A peripheral does is not established here. If it does, the log survives a flat battery, which changes what the feature is for.

## What it costs

| dimension | cost |
|---|---|
| money | $0.00. No part. The storage and the NFC peripheral are both already paid for. |
| current | UNKNOWN and load-bearing — see the unverified rows. A RAM ring buffer flushed once an hour is almost certainly free against a 4.2506 uA baseline; a write per event at 0.5 s during motion is almost certainly not. The design lives or dies on the flush policy. |
| size | 0 mm. |
| complexity | Moderate. A wear-levelled log in NVM, a flush policy, and a readout format. Zephyr ships NVS and settings subsystems that do most of it. |

## What it would break in the current design

- It puts a durable record of an asset's movements on a device that can be stolen. That is a privacy consequence and it belongs in docs/ANTI-STALKING.md before a line of it is written: a log that survives the tag changing hands is a surveillance artifact. The mitigation — encrypt the log to the owner's key, the same key that already protects the location reports — is cheap and should be in the design from the start, not retrofitted.
- It competes for NVM with the pre-generated key list (C11). 500 keys is 14 kB; a log is much larger. On a 1 MB part neither is scarce, but on the nRF54L05 fallback (0.5 MB) the arithmetic has to be redone.
- It adds a write pattern to a part whose sleep current is the whole battery budget. Nothing else on this board writes NVM in normal operation.

## The smallest experiment that would settle it

Open the nRF54L10 product specification, read the non-volatile memory chapter's write current, write time and endurance figures, and put them into the existing ce-spice rail_droop study as a sixth scenario: baseline advertising plus one 16-byte NVM write every 30 seconds. The study already computes i_avg_uA and life_months_derated, so the answer comes out in the units the project already uses, and it costs one afternoon. If the derated life stays over 24 months the concept is alive; if it does not, the flush policy is the design problem and the experiment has already told you by how much.

## What follows if it works

- The tag becomes useful in exactly the places Find My is useless, which is where Leif's sensors are.
- It is the natural store for C7's ranging measurements between uplink opportunities, so the two concepts share one mechanism.

---

Generated from `spec/concepts.json` by `tools/gen_concepts.py` on 2026-09-05. Do not edit this file; edit the JSON.

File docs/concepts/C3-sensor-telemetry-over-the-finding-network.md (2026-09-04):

# C3 — Sensor telemetry over the finding network, with no gateway of its own

*The status byte is copied into the location report and encrypted to the owner's key, so a halo can report sensor state through a stranger's phone and Apple cannot read it.*

**Verdict: PROVEN** — The mechanism has been running in the field since 2022 (dakhnod/FakeTag, a mailbox sensor) and the receiving half is readable in FindMy.py's source: the status byte comes back at offset 9 of the DECRYPTED report payload. What is not proven is the throughput at any particular place, because that is a property of how many phones walk past — and the experiment below measures exactly that.

Family `telemetry` · value 5/5 against effort 1/5 · part of the halo concept portfolio, `docs/concepts/README.md`.
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

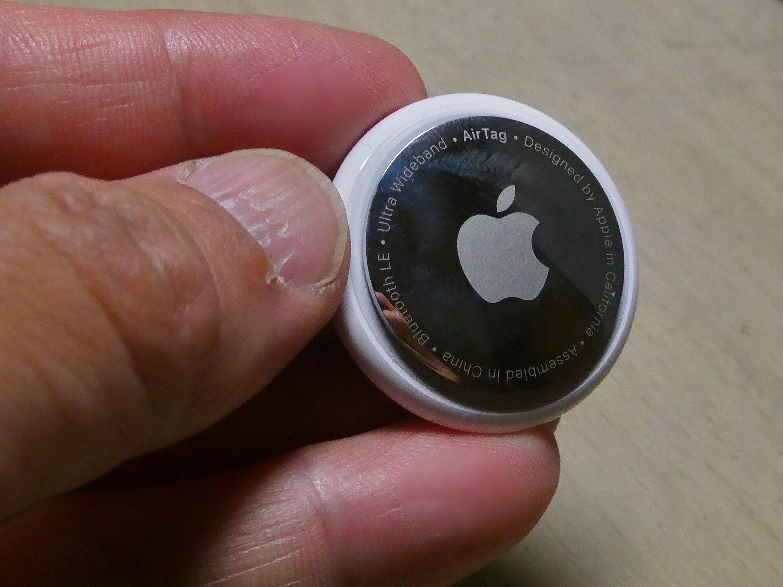
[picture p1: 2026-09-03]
images/mechanical/Airtag_-_5.jpg

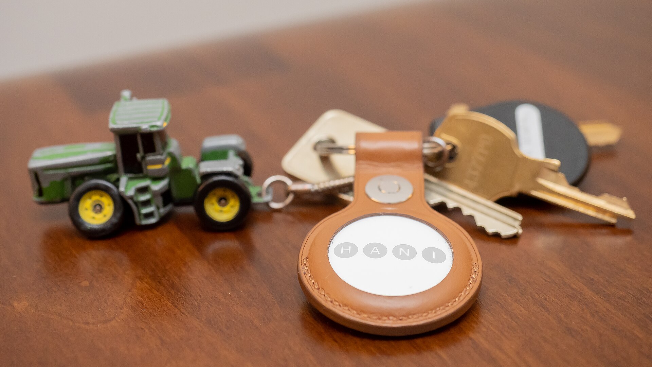
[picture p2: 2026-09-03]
images/mechanical/Apple_AirTag_(51334123725).jpg

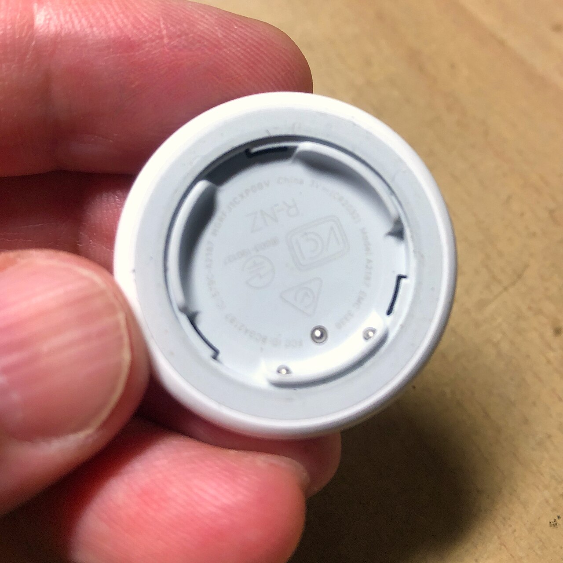
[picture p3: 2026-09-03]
images/designs/C-airtag-inside-4.jpg

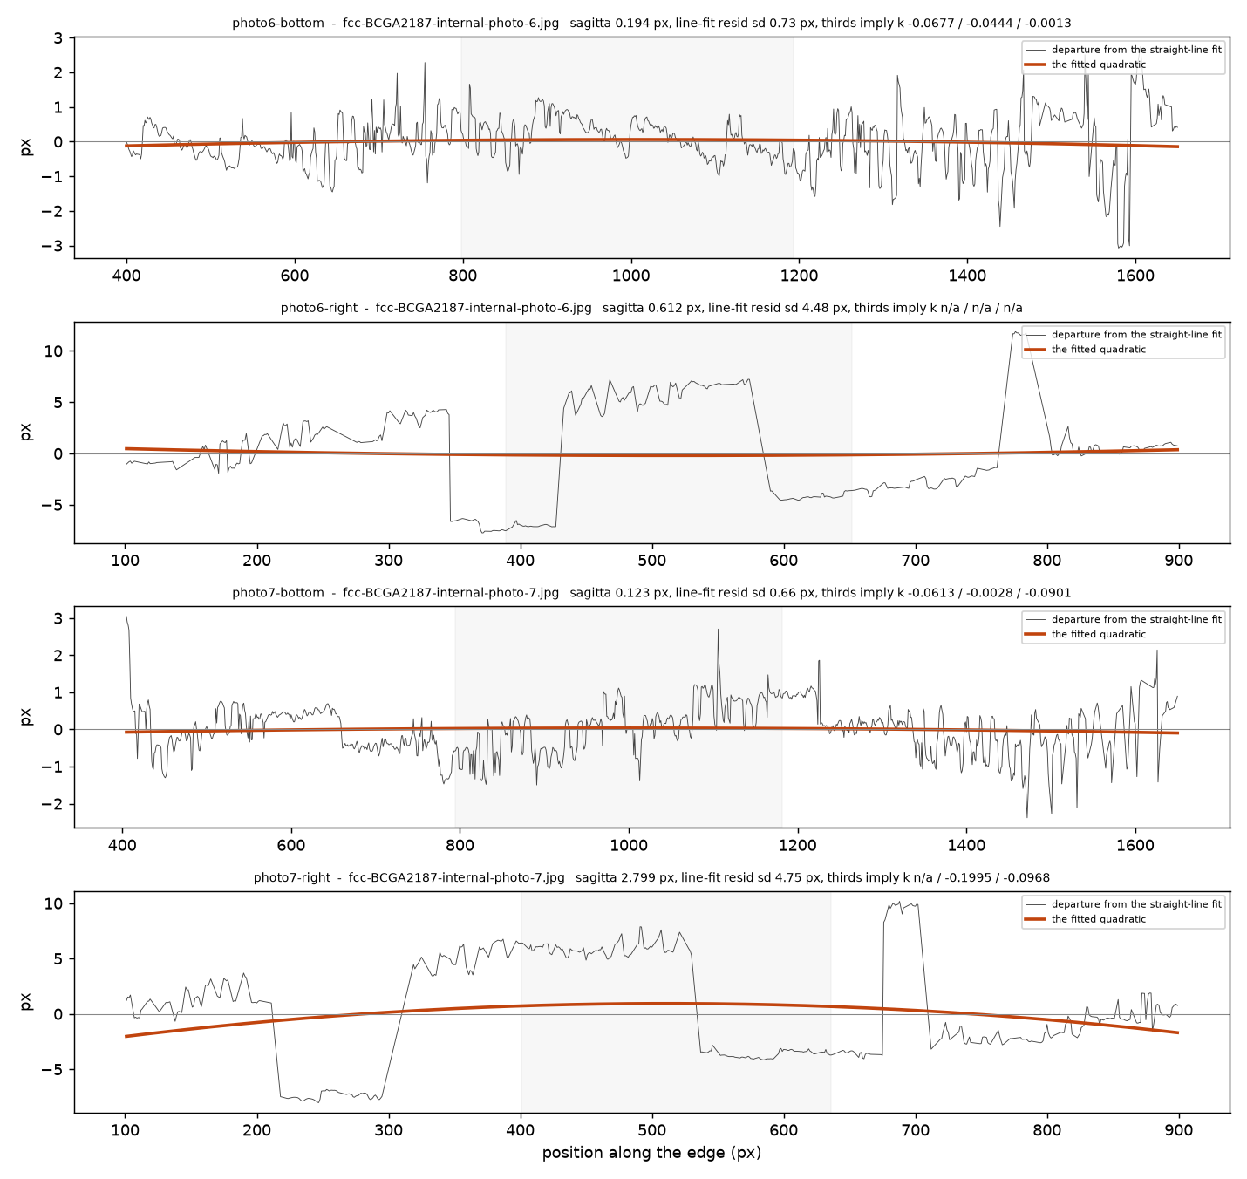
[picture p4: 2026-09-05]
electronics/halo_replica/metrology/compside/img/R17-edge-profiles-span.png

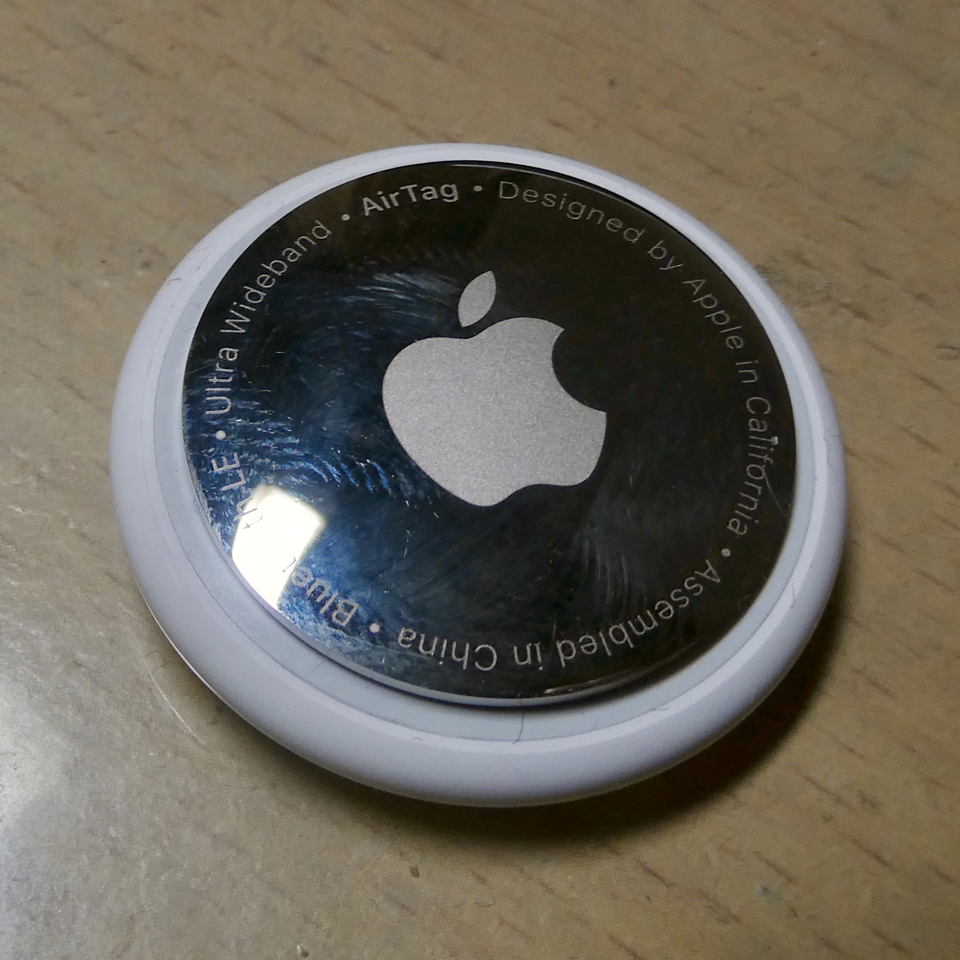
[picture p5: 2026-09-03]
images/mechanical/Airtag_-_6.jpg

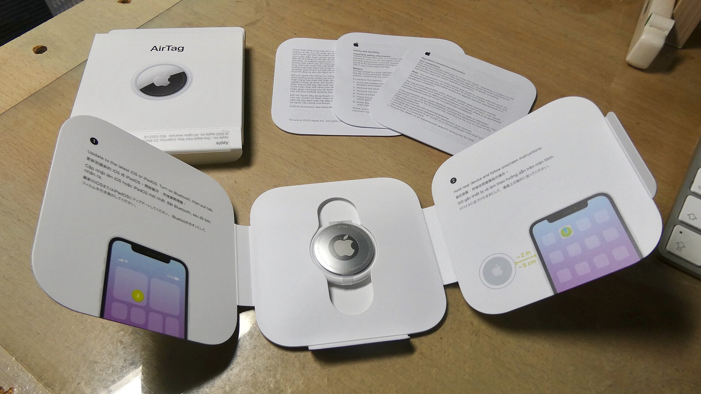
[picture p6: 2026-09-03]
images/mechanical/Airtag_-_2.jpg

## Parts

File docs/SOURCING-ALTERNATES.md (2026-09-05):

# Sourcing alternates — the lines halo_rev_a cannot buy at 1,000 and 10,000

*Lane S2 (availability). Every stock and price figure on this page was read **live on 2026-09-05**
from a named endpoint at a named second, not recalled and not taken from a catalogue snapshot.
The probe is `livestock.py` (below); its raw output is `out/verify/alternates-live-2026-09-05.json`.*

> ## The answer, in one line
>
> **Nothing on halo_rev_a is unbuyable. Every line that fails at 10,000 fails in ONE CHANNEL —
> JLCPCB's assembly catalogue — and every one of them is deeply stocked at authorized Western
> distributors, at a combined cost that comes out LOWER, not higher.** The four failing lines hold
> **472,421 · 314,042 · 51,300 · 14,956** pieces through authorized channels against needs of
> 20,004 · 20,004 · 20,010 · 10,000. **No part has to be substituted at all.** What has to change is
> who supplies them: four lines become **CONSIGNED**. §4b has the arithmetic.
>
> This paragraph replaced an earlier conclusion on the same page that said L3/L4 had no qualified
> alternate at 10,000 and would force a value change. That conclusion was right about the JLCPCB
> catalogue and wrong about the world, and it was wrong because this lane had measured one channel
> and written a verdict about all of them. **The alternates in §3 are still real and still useful as
> in-channel fallbacks — they are simply no longer the recommendation.**

**This lane proposes. It does not apply.** `electronics/halo_rev_a/schematic.py`,
`out/release/board/` and `spec/bom-resolved.json` belong to the board and halo lanes. A change that
lands only in a resolved file is not landed: the 2026-09-04 fix wrote corrected order codes into
`spec/bom-resolved.json` but not onto the sheet, and the next regeneration exported the old wrong
codes again. **Whatever is adopted here has to land on `schematic.py`.**

---

## 0 · Read this first: the FAIL in the record is not the FAIL on the board

The failures this lane was spawned to close — `C1046539` at 0 stock and `C2827888` at 59 against a
need of 100 — **were never availability failures.** They were an identity defect, and the board lane
had already fixed it before this lane started.

| code in the 09-04 transcript | sat on | what that order code actually is |
|---|---|---|
| `C2827888` | C5, C6, C7, C8 — capacitor pads | `DB2EK-3.5-8P-BK-S`, an **8-pin 3.5 mm pitch screw terminal block** |
| `C1046539` | L2, L3, L4 — 0201 inductor pads | `SIT3372AC-1E2-33NZ133.650000X`, a **SiTime 133.65 MHz MEMS oscillator** |

`out/release/board/halo_rev_a-BOM.csv` was regenerated **2026-09-05 06:06** with correct codes
(`C335106`, `C7216765`, `C3911055` …). Both parts are now deeply stocked and both lines PASS at every
quantity. **Row 3's FAIL text should be superseded, not re-measured**, and no alternate should be
sought for either code. Chasing them would have been an hour spent finding a second source for a
screw terminal block.

---

## 1 · The tool that graded this was reading two-day-old stock

`ce-fab/bin/fab bom cost --live` **fetches live only for the lines the catalogue snapshot could not
match.** Every line the snapshot *did* match is graded on `stock as of 2026-09-03` — the per-line
prose says so, honestly, but **the PASS/FAIL verdict does not**, and the verdict is what people read.

Re-probing all 23 picks live moved four verdicts:

| line | code | snapshot 2026-09-03 | **live 2026-09-05** | move |
|---|---|--:|--:|---|
| C19 | `C668326` | 5,874 | **29,352** | FAIL → **PASS** (+400 %) |
| X2 | `C843260` | 6,665 | **13,596** | FAIL → **PASS** (+104 %) |
| L3, L4 | `C3911055` | 18,376 | **8,441** | **−54 % in two days** |
| U1 | `C44800139` | 212 | **927** | FAIL → FAIL |

and two candidate reads moved even harder: `C423341` read **29,417 live against 1,167 in the
snapshot — a 25× understatement**, and `C237447` read **7,693 live against 36,092 — a 79 % collapse**.

**Consequence for anyone reading this page:** two of the six lines the 09-04 run reported as
unbuyable at 10,000 are buyable today, and one it waved through has halved. Filed in
`docs/TOOLS-THAT-LIE.md`; the fix belongs in `ce-fab`, not in a warning.

---

## 2 · What actually fails, live, 2026-09-05

| build | verdict | lines failing on stock |
|---|---|---|
| **10 boards** | **PASS** | none |
| **100 boards** | **PASS** | none |
| **1,000 boards** | **FAIL** | **U1** only |
| **10,000 boards** | **FAIL** | **U1**, **L3/L4**, **R1/R2**, **C20/C21** |

Needs include JLCPCB's stated setup attrition, as `fab bom cost` computes them. Stock is JLCPCB
assembly stock — the channel that matters when JLC supplies the parts — cross-checked against LCSC
retail.

**Every FAIL in that table is a FAIL about one channel.** Read again through authorized distributors
(§4, §4b) all four lines pass with room, at the fitted part numbers:

| line | need @10k | JLCPCB + LCSC | **authorized distributors** | cover |
|---|--:|--:|--:|--:|
| L3, L4 `LQP03HQ3N5B02D` | 20,004 | 8,441 | **472,421** | 23.6× |
| C20, C21 `GJM0335C1HR50WB01D` | 20,004 | 13,101 | **314,042** | 15.7× |
| R1, R2 `0201WMF4704TEE` | 20,010 | 10,142 | **51,300** | 2.6× |
| U1 `NRF54L10-QFAA-R7` | 10,000 | 927 | **14,956** | 1.5× |

---

### Re-read 11 hours later: the count of failing lines is 3, not 4 — and the "−54 %" was not a trend

*Added by lane L8, 2026-09-05. **Nothing above is retracted.** Every figure on this page is
correct at the second it was read; these are the same two endpoints read again, and one of them
moved a long way.*

| part | need @10k | snapshot 09-03 | S2, 2026-09-04T23:31Z | L8, 2026-09-05T10:33Z | |
|---|--:|--:|--:|--:|---|
| `C3911055` L3/L4 3.5 nH | 20,004 | 18,376 | LCSC 8,040 · **JLC 8,441** | LCSC 22,960 · **JLC 23,309** | **2.76× — now CLEARS** |
| `C44800139` U1 | 10,000 | 212 | LCSC 671 · **JLC 927** | LCSC 697 · **JLC 953** | 1.03× — still short |

Same codes, same two endpoints, same channels, eleven hours apart. `C3911055` was restocked by
roughly 15,000 pieces overnight and now covers its 20,004 need with margin. **So the "four
failing lines" above are three as of 2026-09-05T10:33:37Z** — U1, R1/R2 `C778408` and
C20/C21 `C237424` — and this page's §4b arithmetic for L3/L4 describes a shortage that has
since closed.

**And the `−54 % in two days` on L3/L4 was two points, not a trend.** The third point reversed
it: 18,376 on 09-03, 8,441 on 09-04, 23,309 on 09-05. A passive at this volume moves on reel
arrivals, not on a slope, and a percentage change between two reads of a volatile quantity
invites a reader to extrapolate something that is not there. The U1 row is the opposite and is
the one worth watching: 212 → 927 → 953 is small, consistent, and nowhere near 10,000 on any
read, which is why it and not L3/L4 is the standing risk.

**The rule this page already states is the reason both readings stand:** a stock figure carries
its endpoint and the second it was read, or it is not a measurement. Two lanes disagreeing about
"live stock" without timestamps would have looked like one of them being wrong; with timestamps
it is simply a restock, and both numbers are usable.

*Raw: `out/verify/alternates-live-2026-09-05.json` (S2, 23:31Z) and `spec/bom-resolved.json`
(L8, 10:33Z). Neither was re-fetched to write this note.*

**So the deliverable this lane was asked for — a qualified alternate per failing line — is answered
by four rows that need no alternate.** The alternates are in §3 anyway, because a second source is
worth having whether or not it is needed today, and because they are the answer if consignment is
refused.

---

## 3 · The four lines, one row each

### C20, C21 — 0.5 pF pi shunts — **PASS with a stated dependency**

| | fitted | **proposed alternate** |
|---|---|---|
| LCSC | [C237424](https://www.lcsc.com/product-detail/C237424.html) | **[C85922](https://www.lcsc.com/product-detail/C85922.html)** |
| MPN | `GJM0335C1HR50WB01D` | `GRM0335C1HR50WA01D` |
| Manufacturer | Murata | Murata |
| Capacitance | 0.5 pF | **0.5 pF** |
| Tolerance | ±0.05 pF (`W`) | **±0.05 pF (`W`)** |
| Voltage | 50 V | **50 V** |
| Dielectric | C0G | **C0G** |
| Package / land pattern | 0201 / `C_0201_0603Metric` | **0201 / same land pattern** |
| Series | GJM03 — high-Q RF | GRM03 — general-purpose C0G |
| **JLC stock, live** | **13,101** | **135,053** |
| LCSC stock, live | 13,100 | 132,300 |
| JLC unit @1k / @10k | $0.0181 / $0.0165 | **$0.0053 / $0.0047** |
| Need @10,000 boards | 20,004 | 20,004 |
| **Verdict** | **FAIL** — short 6,903 | **PASS** — 6.75× cover, and **72 % cheaper** |

**Why it is qualified:** identical value, identical tolerance code, identical voltage, identical
dielectric, identical 0201 body, same manufacturer, same land pattern. The single parameter that
differs is **Q**: GJM03 is Murata's high-Q RF series, GRM03 is the general-purpose C0G. In a 2.4 GHz
shunt leg that shows up as insertion loss, not as a wrong value.

**The dependency, stated rather than hidden:** `schematic.py:497` says of this pi — *"ALL THREE ARE
PLACEHOLDERS: the values below are a starting guess for a slightly-inductive feed, and they are what
ce-rf's measured S11 replaces."* **You cannot commit 20,000 pieces of a value that has not been
chosen.** So this row is not closed by a part; it is closed by ce-rf's S11 fixing the value, after
which the GRM part is the deep-stock answer for whatever value that is.

**What would settle it:** ce-rf's S11 on the real copper, then one sweep re-run with GRM03's Q
instead of GJM03's. If the match holds, adopt C85922 and the line gains 10× stock and gets cheaper.

**But the substitution is no longer necessary — the fitted part is abundant outside this channel.**
`GJM0335C1HR50WB01D`, authorized distributors, read 2026-09-05T07:41Z:

| distributor | status | on hand | reel price |
|---|---|--:|--:|
| DigiKey | ECIA · Authorized | **151,160** | T&R min 15,000 |
| Mouser | ECIA · Authorized | **134,042** | **$0.0150 @10k · $0.0140 @15k** |
| Newark | ECIA · Authorized | 28,840 | $0.0190 @5k |
| Arrow | ECIA · Authorized | 45,000 Americas (10-week) · 15,000 Europe (14-week) | $0.0160 · **$0.0137** |
| Future | ECIA · Authorized | 105,000 reel, 24-week lead | $0.0599 |
| **authorized on hand** | | **314,042** | |

**Need 20,004. Mouser alone covers it 6.7× at $0.0140 — which is CHEAPER than the $0.0165 JLCPCB
charges.** Keep the high-Q part, keep Nordic's Q, consign the line, and it costs less. **The
GRM substitution and the ce-rf dependency both fall away.**

**A supply fact that still outlives this row:** the GJM03 high-Q family is systematically thin *in
the JLCPCB catalogue* — this board's five GJM parts read 5,994 / 13,101 / 13,804 / 24,048 / 29,352
there. That is a fact about the channel, not about the part.

---

### R1, R2 — 4.7 MΩ cell-removal sense divider — **PASS on stock, CANNOT DETERMINE on tolerance**

| | fitted | **proposed alternate** | value-change route |
|---|---|---|---|
| LCSC | [C778408](https://www.lcsc.com/product-detail/C778408.html) | **[C423341](https://www.lcsc.com/product-detail/C423341.html)** | [C423797](https://www.lcsc.com/product-detail/C423797.html) |
| MPN | `0201WMF4704TEE` | `0201WMJ0475TEE` | `0201WMF1005TEE` |
| Manufacturer | UNI-ROYAL | **UNI-ROYAL** | UNI-ROYAL |
| Resistance | 4.7 MΩ | **4.7 MΩ** | 10 MΩ |
| **Tolerance** | **±1 % (`F`)** | **±5 % (`J`)** | **±1 % (`F`)** |
| Temp coefficient | ±200 ppm/°C | **±200 ppm/°C** | ±200 ppm/°C |
| Rating | 50 mW / 25 V | **50 mW / 25 V** | 50 mW / 25 V |
| Package / land pattern | 0201 / `R_0201_0603Metric` | **0201 / same** | 0201 / same |
| **JLC stock, live** | **10,142** | **29,417** | 13,937 |
| JLC unit @1k / @10k | $0.0015 / $0.0013 | **$0.0008 / $0.0007** | $0.0016 / $0.0013 |
| Need @10,000 boards | 20,010 | 20,010 | 20,010 |
| **Verdict** | **FAIL** — short 9,868 | **PASS on stock** — 1.47× cover, **46 % cheaper** | **FAIL** — short 6,073 |

**Mechanically qualified:** same 0201 body, same land pattern, same manufacturer, same series, same
power and voltage rating, same tempco. Nothing about the board changes.

**Electrically — this is the honest part.** Dropping ±1 % → ±5 % widens the divider ratio worst case
from **±1.0 % to ±5.0 %**, which on a 3.0 V cell is **±150 mV instead of ±30 mV** on the reported
battery voltage.

- For the divider's **primary job it does not matter at all.** `schematic.py:843` — *"BT1 pad 3 is
  SENSE ONLY through R1/R2 into AIN0 … Pull the cell and VBAT_SNS collapses in ~0.24 ms."* Cell
  removal is a collapse to zero, not a threshold with 5 % of headroom at stake.
- For the **idle-current argument it does not matter either**: 3 V / 9.4 MΩ = 0.32 µA while the GPIO
  is driven, and tolerance moves that by ±5 % of a third of a microamp.
- For **reported battery level, no requirement exists to check it against.** SPEC.md F11 says *"about
  a year on a CR2032"* and states no gauge accuracy anywhere. **This is a CANNOT DETERMINE, and it is
  recorded as one rather than resolved by assuming ±150 mV is fine.**

**What would settle it:** one line in SPEC.md giving the battery-level accuracy the product owes, or
the firmware lane naming the bucket boundaries it reports. If levels are coarse buckets — the
AirTag-class norm — ±150 mV is comfortably inside and C423341 closes this row outright, cheaper.

**Why the 10 MΩ value-change route is recorded but not recommended.** It keeps ±1 % and it *halves*
the sense current to 150 nA, but: **no single 10 MΩ ±1 % 0201 covers 20,010 either** (13,937 UNI-ROYAL
+ 8,002 YAGEO `C469663`, two manufacturers, to reach 21,939), and it doubles the ADC source impedance
2.35 MΩ → 5 MΩ and the collapse time 0.24 ms → 0.50 ms, both of which are measured numbers on the
sheet today. It trades a tolerance question for two re-measurements. **Recorded so nobody re-derives
it; not proposed.**

**There is no third ±1 % source at 4.7 MΩ *in this channel*.** `C474424` (YAGEO
`RC0201FR-074M7L`) reads **5 pieces** live and 0 at LCSC. The ±5 % field beyond C423341 is `C158489`
RALEC at 1,052 and `C171972` Walsin at 489 — neither is a supply.

**And here too the tolerance question disappears if the line is consigned.** The fitted **±1 %**
part, `0201WMF4704TEE`, at authorized distributors, read 2026-09-05T07:41Z:

| distributor | status | on hand | price |
|---|---|--:|--:|
| TME | ECIA · Authorized | **28,500** | **$0.0022 @15k**, $0.0030 @10k |
| Verical | Authorized | **22,800** (Americas 28,500) | $0.0031 |
| Mouser | ECIA · Authorized | 0 (min 15,000) | $0.0020 |
| **authorized on hand** | | **51,300** | |

**Need 20,010. TME alone covers it at $0.0022** against JLCPCB's $0.0013 — **an extra $18 across the
whole 10,000-board build.** Keeping ±1 % costs eighteen dollars. **Recommendation: keep `C778408` at
±1 % and consign it; the ±5 % question is not worth asking, and `C423341` stays on the page only as
the answer if the line must remain inside JLCPCB's catalogue.**

The CANNOT DETERMINE on the battery-gauge requirement stands and is still worth closing — it is a
gap in SPEC.md either way — but **it no longer gates this row.**

---

### L3, L4 — 3.5 nH match inductors — **FAIL inside JLCPCB, PASS through an authorized distributor**

Inside the JLCPCB catalogue the recorded alternate does not cover it and **neither does anything else
at this value** — the evidence is below, and it is worth keeping because it is what forces the
channel question. The whole live band, every 0201 inductor from 3.3 nH to 4.3 nH, read 2026-09-05:

| LCSC | MPN | value | series / Q @500 MHz | DCR | **JLC stock, live** | @10k unit | covers 20,004? |
|---|---|--:|---|--:|--:|--:|---|
| [C3911055](https://www.lcsc.com/product-detail/C3911055.html) | `LQP03HQ3N5B02D` | **3.5 nH — fitted** | HQ / **20** | 170 mΩ | **8,441** | $0.0280 | **no** |
| [C206424](https://www.lcsc.com/product-detail/C206424.html) | `LQP03TN3N5B02D` | 3.5 nH — *recorded alternate* | TN / 14 | — | **9,348** | $0.0100 | **no** |
| [C237447](https://www.lcsc.com/product-detail/C237447.html) | `LQP03HQ3N6B02D` | 3.6 nH | HQ / **20** | 170 mΩ | 7,693 | $0.0207 | no |
| [C237380](https://www.lcsc.com/product-detail/C237380.html) | `LQP03HQ3N3B02D` | 3.3 nH | HQ / **20** | 170 mΩ | 14,462 | $0.0270 | no |
| [C337939](https://www.lcsc.com/product-detail/C337939.html) | `LQP03HQ3N9B02D` | 3.9 nH | HQ / **20** | 170 mΩ | 10,385 | $0.0243 | no |
| [C2041526](https://www.lcsc.com/product-detail/C2041526.html) | `LQP03HQ4N0B02D` | 4.0 nH | HQ / **20** | 170 mΩ | 13,906 | $0.0278 | no |
| [C2988753](https://www.lcsc.com/product-detail/C2988753.html) | `LQP03HQ4N3H02D` | 4.3 nH | HQ / **20** | 170 mΩ | 36,962 | $0.0220 | yes — but +23 % value |
| [C275212](https://www.lcsc.com/product-detail/C275212.html) | `MLG0603P3N6BTZ10` | 3.6 nH | TDK / 18 | 200 mΩ | 12,496 | $0.0055 | no |
| [C76756](https://www.lcsc.com/product-detail/C76756.html) | `MLG0603P3N9BTZ10` | 3.9 nH | TDK / 14 | 220 mΩ | 17,862 | $0.0018 | no |
| [C77115](https://www.lcsc.com/product-detail/C77115.html) | `LQP03TN3N9B02D` | 3.9 nH | TN / 14 | 300 mΩ | 49,208 | $0.0155 | yes — but Q 14 and +11 % |
| **[C98045](https://www.lcsc.com/product-detail/C98045.html)** | **`LQP03TN3N3B02D`** | **3.3 nH** | **TN / 14** | 250 mΩ | **135,099** | **$0.0118** | **yes — 6.8× cover** |

*Q, DCR and current figures are JLCPCB's own catalogue description text, not the Murata datasheet.*

**Three facts that decide this line:**

1. **At 3.5 nH there is no answer, and there is not even a two-code answer.** Both order codes in
   existence total **8,441 + 9,348 = 17,789**, short of 20,004. Splitting the line across both
   manufacturers' codes still FAILS.
2. **LCSC cannot sell one reel of the fitted part today.** `C3911055`'s minimum purchase packet is
   **15,000** against **8,040** in stock. The line is below one reel, not merely below the build.
3. **The high-Q family is thin everywhere near this value.** Every LQP03**HQ** part from 3.3 to 4.0 nH
   reads between 7,693 and 14,462. Only 4.3 nH breaks 20,000, and that is a 23 % value change.

**What this forces, stated so it can be decided in a minute rather than researched again:**

| route | part | live stock | what it costs |
|---|---|--:|---|
| **A · keep 3.5 nH** | `C3911055` | 8,441 | **caps the build at ~4,200 boards.** No alternate exists. |
| **B · move to 3.3 nH, keep Q=20** | `C237380` | 14,462 | still **FAILS** 20,004 — buys ~7,200 boards |
| **C · move to 3.3 nH, accept Q=14** | **`C98045`** | **135,099** | **the only deep answer.** −6 % value, Q 20→14, DCR 170→250 mΩ, **−58 % unit cost** |
| **D · move to 4.3 nH, keep Q=20** | `C2988753` | 36,962 | +23 % value — a different match, not a substitution |

**Verdict inside the JLCPCB catalogue: FAIL at 10,000, with no qualified same-value alternate.**
Route C is the only one with real depth there, and it is **not a sourcing pick** — L3/L4 are Nordic's
reference-network values (`schematic.py:454`, tolerance ±0.1 nH), so changing them would be ce-rf's
and the board lane's call, not this lane's.

### **And it does not have to be made. This was the wrong channel.**

`LQP03HQ3N5B02D` — the fitted part, at the fitted value — at authorized distributors, read
2026-09-05T07:41Z:

| distributor | status | on hand | price |
|---|---|--:|--:|
| **DigiKey** | ECIA · Authorized | **398,982** | $0.0580 @15k · **$0.0547 @30k** · $0.0528 @45k |
| Mouser | ECIA · Authorized | **46,892** | $0.0690 @1k · $0.0590 @5k · **$0.0560 @10k** |
| Newark | ECIA · Authorized | **26,547** | $0.0600 @5k (cut tape) |
| TTI | ECIA · Authorized | 0 (Americas) | $0.0520 @15k |
| TME | ECIA · Authorized | 0 | $0.0241 @15k |
| **authorized on hand** | | **472,421** | |

**Need 20,004. DigiKey alone holds nearly twenty times that.** Not a value change, not a Q
compromise, not an S11 re-sweep — **the part halo already chose, in the quantity halo needs, from an
authorized channel, today.**

The price is the honest cost: **$0.0560/pc at Mouser against the $0.0280 JLCPCB quotes**, so 20,004
pieces run **$1,120 instead of $560 — about $560 more across a 10,000-board build, or 5.6 ¢ a
board.** That is the entire price of not re-tuning a 2.4 GHz match network.

**Revised verdict: PASS at 10,000, through an authorized distributor, with the fitted part
unchanged.** Routes B/C/D above are retained as in-channel fallbacks and as the answer if
consignment is ever refused, not as the recommendation.

**What this changes about the earlier finding:** "LCSC cannot sell one reel of the fitted part
today" is still true and still worth knowing — it is a fact about LCSC. It is not a fact about
Murata, and this page said so too broadly before it had measured a second channel.

---

### U1 — nRF54L10 — **FAIL at 1,000 and 10,000 inside JLCPCB; PASS through an authorized distributor (§4)**

| LCSC | MPN | package | JLC stock, live | LCSC stock, live | min packet | @1k / @10k |
|---|---|---|--:|--:|--:|---|
| [C44800139](https://www.lcsc.com/product-detail/C44800139.html) | `NRF54L10-QFAA-R7` — **fitted** | VFQFN-48 | **927** | 671 | 1,000 | $2.3800 / $2.3800 |
| [C45022043](https://www.lcsc.com/product-detail/C45022043.html) | `NRF54L10-QFAA-R` — same die, different reel | VFQFN-48 | **0** | **0** | 3,000 | $3.4928 |
| [C45022042](https://www.lcsc.com/product-detail/C45022042.html) | `NRF54L05-QFAA-R` — **a different SoC** | VFQFN-48 | 1,775 | 1,775 | 3,000 | $2.0112 |

**Those three rows are the entire nRF54L presence in the JLCPCB and LCSC catalogues.** A keyword
sweep of `NRF54%` returns nothing else.

- **At 1,000 boards it is short by 73 pieces**, and the minimum purchase packet is exactly 1,000 —
  so LCSC cannot even sell one packet today.
- **At 10,000 it is short by 9,073.**
- `NRF54L05-QFAA-R` is **not a drop-in**: 512 kB flash / 96 kB RAM against the L10's 1 MB / 256 kB.
  It is pin-compatible in the same QFAA package, so it is a *build* second source, but adopting it is
  a firmware and memory-budget decision. **It also still misses 10,000 by 8,225.** DECISIONS.md D18
  already records that the L05 fallback is not forced by memory; the firmware measures 13,164 bytes.

**Verdict in this channel: FAIL at both quantities.** There is no qualified in-stock alternate at
LCSC or JLCPCB — 927 pieces, three order codes, and one of them is a different SoC.

**Verdict overall: PASS, through an authorized distributor — see §4.** 14,956 pieces are on hand
across authorized channels today and Future Electronics quotes 16 weeks at **$1.8900**, which is
**21 % below what JLCPCB itself charges**. The real content of this row is not scarcity, it is that
**JLCPCB cannot be the supplier**: U1 becomes a consigned part above ~900 boards. §4a puts the three
options side by side with a number on each.

---

## 4 · U1 through authorized channels — **the blocker dissolves into a scheduling fact**

*Read 2026-09-05T07:40Z from `https://www.oemstrade.com/search/NRF54L10-QFAA-R7` and
`.../NRF54L10-QFAA-R` (Supplyframe's aggregator, which labels each distributor's ECIA / authorized
status on the row). **Public stock pages only.** No distributor was contacted, no account opened, no
quote requested, nothing ordered. Nordic's own ordering-information page returned **HTTP 403** and is
recorded below as the one thing that could not be read.*

### On hand today, authorized channels only

| distributor | status | `-QFAA-R7` (fitted) | `-QFAA-R` (see note) | @1,000 |
|---|---|--:|--:|--:|
| Mouser | ECIA member · Authorized | **813** | **8,034** | $2.75 / $2.59 |
| DigiKey | ECIA member · Authorized | **754** | **1,649** | $2.6907 (T&R @3,000 $2.5356) |
| Newark / Farnell | ECIA member · Authorized | **423** *(one pool, two storefronts — counted once)* | **1,683** | $2.48 / $2.34 |
| Verical | Authorized | **1,000** (Americas) | — | $3.3960 |
| Rutronik | — | **600** (DE; HK 0, US 0, SG 0) | — | €2.0800 |
| TME | ECIA member · Authorized | **0** | — | — |
| **Authorized on hand** | | **3,590** | **11,366** | **14,956 combined** |

**Future Electronics** (ECIA member · Authorized) holds none on the shelf and instead quotes the
thing that actually decides this: **min qty 3,000, package multiple 3,000, lead time 16 weeks, full
reel, $1.8900.** That is **the cheapest price anywhere for this part — 21 % below the $2.3800
JLCPCB charges** to supply it during assembly.

Not counted, recorded so nobody counts them: Sierra IC **9,016** ("OEM/CM ONLY"), Win Source
**8,580**, Axis Part **1,100**, Quest **800**, Unikey **401**. None is an authorized channel, and
D20's piezo finding on this project is the precedent — broker stock of a part with no traceability
is not a supply.

### The `-R` / `-R7` question — **SETTLED by the manufacturer, 2026-09-05T09:34Z**

`NRF54L10-QFAA-R` is **where nearly all the stock is** (11,366 against 3,590), so whether it is the
same device matters more than any other number on this page.

**It is the same device. Nordic's own datasheet says so, and the suffix is not part of the device
identity at all — it is the shipping container.**

Nordic Semiconductor, *nRF54L15, nRF54L10, and nRF54L05 Wireless SoCs* **datasheet v1.0, document
`4503_018`**, chapter 14 *Ordering information*, p. 926–929. Fetched as PDF 2026-09-05T09:34Z,
13,174,442 bytes, `sha256 ade0d340ba95e31f8299e6721b08d53a702962335d9b87fa202f8d2767603554`, from
`https://datasheet.lcsc.com/datasheet/pdf/11cf20669bff633a577e95a4820b68c9.pdf` (LCSC's mirror of
Nordic's own document — Nordic's `docs.nordicsemi.com` page still returns HTTP 403). Chapter 14 is
extracted verbatim to `out/verify/sourcing-evidence-2026-09-05/nrf54l-datasheet-v1.0-chapter14-ordering.txt`.

**The order code, Figure 203 and Table 99:**

```
nRF54L<DD>-<PP><VV>-<CC>
       │     │   │     └── Container code
       │     │   └──────── Function variant code
       │     └──────────── Package variant code
       └────────────────── Device code
```

| field | our part | Nordic's table |
|---|---|---|
| `<DD>` device | **10** | Table 100 — `10` = nRF54L10 |
| `<PP>` package | **QF** | Table 101 — `QF` = **QFN48, 6×6 mm, 48 pins, 0.4 mm pitch** |
| `<VV>` function | **AA** | Table 102 — `AA` = Reserved |
| `<CC>` container | **R7** *or* **R** | **Table 109 — `R7` = 7″ Reel · `R` = 13″ Reel** |

**`NRF54L10-QFAA-R7` and `NRF54L10-QFAA-R` are identical in device, package and function variant.
They differ in one field, and that field is the diameter of the reel the parts arrive on.**

Nordic's Table 111 lists both as nRF54L10 order codes with minimum order quantities of **1,000**
(`-R7`) and **3,000** (`-R`) — **which is exactly what LCSC's `minPacketNumber` returned for
`C44800139` and `C45022043` in this lane's live probe.** Two independent sources, the manufacturer's
table and the vendor's API, agree to the piece.

**Two things this settles beyond the stock number:**

1. **U1's authorized total stands at 14,956**, not 3,590. The §4 verdict, the §4b arithmetic and the
   §4a options are all unaffected.
2. **`QF` = QFN48 6×6 mm, 0.4 mm pitch is the manufacturer's own package definition**, and halo's
   land pattern is `QFN-48-1EP_6x6mm_P0.4mm_EP4.4x4.4mm`. The fitted part's package is now confirmed
   against Nordic rather than against a distributor's description string.

**Buy the 13″ reel unless there is a feeder reason not to** — it is where 11,366 of the 14,956 pieces
are, and at 10,000 boards its 3,000-piece MOQ is not a constraint.

*The distributor evidence that preceded this is kept below, because it was right and because it is
how the question got asked. It was four distributors agreeing, which is not the same as the
manufacturer confirming — and this is what the manufacturer confirming looks like:*

- Mouser lists both under the **identical description** — *"Wireless SOC, ultra low power 2.4 GHz
  radio + MCU, 1.0MB NVM"* — at the identical 1-off price of $4.0800.
- Newark carries both under the identical description with **consecutive house numbers**, `26AM1598`
  (`-R`) and `26AM1599` (`-R7`), which is how a distributor numbers two packaging options of one item.
- DigiKey's reel SKUs differ only in **minimum quantity**: `-R7TR-ND` min **1,000**, `-RTR-ND` min
  **3,000**. Future quotes the same split — package multiple 1,000 for `-R7`, 3,000 for `-R`.
- LCSC's own page lists `NRF54L10-QFAA-R` as an **associated part** of `-R7`, and stocks it as
  `C45022043` in the same VFQFN-48.

**~~What could not be read~~ — RESOLVED above.** Nordic's *HTML* ordering-information page
(`docs.nordicsemi.com/bundle/ps_nrf54L15/…/ordering_info.html`) does return **HTTP 403, 5,925
bytes**, and that failed fetch is still committed. But the same chapter exists in the PDF datasheet,
which fetched cleanly, and it settles the question outright. **The board lane no longer needs to
check this before committing a reel — it is checked.**

### Verdict

| build | route | **verdict** |
|---|---|---|
| **1,000** | Mouser holds 8,034 (`-R`) — or 3,590 across five authorized distributors on `-R7` alone | **PASS** |
| **10,000** | 14,956 authorized on hand today, or Future at 16 weeks for $1.8900 | **PASS** |

**U1 is not a design blocker and it is not a money problem. It is a purchasing-channel fact:**

> **JLCPCB cannot supply this part.** It holds **927**. Every route that builds more than ~900
> boards makes U1 a **CONSIGNED** part — halo buys the reels from an authorized distributor and
> ships them to the assembler.

That is the whole decision, and it comes with a discount rather than a premium.
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

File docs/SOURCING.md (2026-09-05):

# Sourcing — every placed part on halo_rev_a, with an order code that was read back

*Generated from `spec/bom-resolved.json` by `tools/gen_sourcing.py` at `05ecf31`. Prices and stock were read on **2026-09-05** and every one of them carries that date. Nothing on this page is typed by hand.*

## The count

| | |
|---|--:|
| Placed references in the release bill of materials | **38** |
| References covered here | **38** |
| Bill-of-materials lines | 26 |
| Lines **RESOLVED** — order code fetched, manufacturer part number and package both matched | **22** |
| Lines **RESOLVED BY REPLACEMENT** — specified part is end-of-life, a buyable equivalent is named | **1** |
| **Lines that now name a part a factory can buy** | **23** of 26 |
| Lines with a documented alternate | **23** of the 23 machine-placed lines (LS1 and BT1 carry theirs in prose) |
| Resolved lines that are a JLCPCB **Basic** part | **2** of 22 |
| Distinct **Extended** order codes on the board | **20** |
| Feeder fee those Extended parts cost, per order | **$61.40** |
| Solder joints, measured | **131** |

- **CANNOT DETERMINE** — `C24, C25` (1.1nF)
- **DNP** — `C14, C15, C16, C17` (DNP)
- **RESOLVED BY REPLACEMENT** — `LS1` (7BB-20-3)
- **NOT AN SMT LINE** — `BT1` (CR2032)

## How every number here was obtained

Two endpoints, both plain HTTPS, both re-runnable:

- **LCSC** — `GET https://www.lcsc.com/product-detail/<code>.html, __NEXT_DATA__ application/json blob`
- **JLCPCB** — `POST https://jlcpcb.com/api/overseas-pcb-order/v1/shoppingCart/smtGood/selectSmtComponentList {currentPage,pageSize,keyword}`

**Two checks make this not a tool that lies** (`docs/TOOLS-THAT-LIE.md`). An order code is accepted only if:

1. the **manufacturer part number** the vendor returns for it matches the one the line asks for, and
2. the **package** the vendor returns for it matches the size of the land pattern the release bill of materials places, read off that file's own Footprint column.

The second check is the one that catches this board's actual defect, and no price check can: a 0402 order code under a 0201 land pattern is a real part, correctly valued, deeply stocked and sanely priced. It is simply twice the size of the pads it is going on.

Both checks are **broken on purpose** by `python3 tools/resolve_bom.py --self-test`, which asserts that a nonexistent order code refuses rather than invents, that the L10's code claimed as an L15 fails, that a 0402 part on a 0201 pad fails, and that halo's own battery land pattern — for which there is no size rule — comes back CANNOT DETERMINE rather than waving through whatever the vendor happened to say. **11 of 11 pass.** Writing that self-test found a real bug in this tool: the page's JSON blob carries recommended and recently-viewed products beside the one asked for, and a first-match walk returned a JST connector for a piezo bender's order code. The parser now requires the node's own `productCode` to be the code requested.

> Two channels, never mixed. price_usd is LCSC RETAIL (you buy the reel). jlcpcb_price_usd is what JLCPCB charges when IT supplies the part during assembly. They differ by up to 2x and the assembly number is the one that belongs in a PCBA quote.

> A price at a quantity the vendor's ladder does not reach is null. Nothing here is extrapolated.

## The bill of materials

Price columns are **JLCPCB assembly** prices — what the factory pays when JLC supplies the part during placement — at the piece count a build of that many boards actually buys. LCSC retail prices and the full ladders are in `spec/bom-resolved.json`.

| Ref | Qty | Value | Function | LCSC | MPN | Mfr | Land pattern | Vendor pkg | Pkg check | Lib | JLC stock | @10 | @100 | @1k | @10k |
|---|--:|---|---|---|---|---|---|---|---|---|--:|--:|--:|--:|--:|
| **C1, C2, C3, C4** | 4 | 100nF | SoC supply decoupling, one per VDD pin | [C5142565](https://www.lcsc.com/product-detail/C5142565.html) | `TCC0201X5R104K100ZT` | CCTC | `C_0201_0603Metric` | 0201 | **ok** | extended | 6,133,533 | $0.0013 | $0.0013 | $0.0010 | $0.0008 |
| **C5, C8** | 2 | 2.2uF | SoC DEC/DCDC reservoir | [C335106](https://www.lcsc.com/product-detail/C335106.html) | `GRM033R61A225KE47D` | muRata | `C_0201_0603Metric` | 0201 | **ok** | extended | 97,292 | $0.0233 | $0.0233 | $0.0189 | $0.0165 |
| **C6** | 1 | 10nF | SoC decoupling | [C76941](https://www.lcsc.com/product-detail/C76941.html) | `GRM033R71A103KA01D` | muRata | `C_0201_0603Metric` | 0201 | **ok** | extended | 368,486 | $0.0047 | $0.0047 | $0.0039 | $0.0034 |
| **C7** | 1 | 2.2nF | SoC decoupling | [C161479](https://www.lcsc.com/product-detail/C161479.html) | `GRM033R71A222KA01D` | muRata | `C_0201_0603Metric` | 0201 | **ok** | extended | 11,619 | $0.0028 | $0.0028 | $0.0022 | $0.0019 |
| **C9, C10, C11, C12** | 4 | 10uF | bulk rail capacitance (4 x 10 uF replaces Apple's 5 x 100 uF) | [C15525](https://www.lcsc.com/product-detail/C15525.html) | `CL05A106MQ5NUNC` | Samsung Electro-Mechanics | `C_0402_1005Metric` | 0402 | **ok** | **basic** | 10,027,488 | $0.0256 | $0.0256 | $0.0192 | $0.0142 |
| **C13** | 1 | 100pF | battery-sense divider settling cap | [C76922](https://www.lcsc.com/product-detail/C76922.html) | `GRM0335C1H101JA01D` | muRata | `C_0201_0603Metric` | 0201 | **ok** | extended | 873,522 | $0.0066 | $0.0066 | $0.0054 | $0.0047 |
| **C18** | 1 | 1.5pF | 2.4 GHz match, Nordic reference network | [C435397](https://www.lcsc.com/product-detail/C435397.html) | `GJM0335C1E1R5WB01D` | muRata | `C_0201_0603Metric` | 0201 | **ok** | extended | 57,313 | $0.0337 | $0.0337 | $0.0244 | $0.0225 |
| **C19** | 1 | 2.0pF | 2.4 GHz match, Nordic reference network | [C668326](https://www.lcsc.com/product-detail/C668326.html) | `GJM0335C1E2R0WB01D` | muRata | `C_0201_0603Metric` | 0201 | **ok** | extended | 29,352 | $0.0949 | $0.0782 | $0.0636 | $0.0559 |
| **C20, C21** | 2 | 0.5pF | antenna tuning pi, shunt legs (values are placeholders until ce-rf's S11) | [C237424](https://www.lcsc.com/product-detail/C237424.html) | `GJM0335C1HR50WB01D` | muRata | `C_0201_0603Metric` | 0201 | **ok** | extended | 13,101 | $0.0257 | $0.0257 | $0.0181 | $0.0165 |
| **C22** | 1 | 0.3pF | 2.4 GHz match, series trim into the pi | [C3904589](https://www.lcsc.com/product-detail/C3904589.html) | `GJM0335C1HR30WB01D` | muRata | `C_0201_0603Metric` | 0201 | **ok** | extended | 24,048 | $0.0309 | $0.0309 | $0.0220 | $0.0200 |
| **C23** | 1 | 3.9pF | 2.4 GHz shunt at ANT (Nordic Table 82; node placement CANNOT DETERMINE) | [C1852416](https://www.lcsc.com/product-detail/C1852416.html) | `GJM0335C1E3R9WB01D` | muRata | `C_0201_0603Metric` | 0201 | **ok** | extended | 13,804 | $0.0243 | $0.0243 | $0.0171 | $0.0156 |
| **C24, C25** | 2 | 1.1nF | NFC antenna tuning, series pair across the coil - MUST BE MATCHED TO EACH OTHER | — | — | — | `C_0201_0603Metric` | — | — | — | — | — | — | — | — |
| **C14, C15, C16, C17** | 4 | DNP | crystal load capacitors, deliberately NOT FITTED (D-3: the nRF54L has on-die CAPVALUE load caps) | — | — | — | `—` | — | — | — | — | — | — | — | — |
| **R1, R2** | 2 | 4.7M | battery-sense divider (4.7 M keeps the divider current in the nanoamps) | [C778408](https://www.lcsc.com/product-detail/C778408.html) | `0201WMF4704TEE` | UNI-ROYAL | `R_0201_0603Metric` | 0201 | **ok** | extended | 10,142 | $0.0019 | $0.0019 | $0.0015 | $0.0013 |
| **R5, R6, R7, R8, R10** | 5 | 10k | I2C/SWD pull-ups and strapping | [C473048](https://www.lcsc.com/product-detail/C473048.html) | `0201WMF1002TEE` | UNI-ROYAL | `R_0201_0603Metric` | 0201 | **ok** | extended | 640,194 | $0.0012 | $0.0012 | $0.0010 | $0.0009 |
| **R9** | 1 | 100R | piezo drive series resistor (D11a: limits GPIO current into a 40 nF bender) | [C270366](https://www.lcsc.com/product-detail/C270366.html) | `0201WMF1000TEE` | UNI-ROYAL | `R_0201_0603Metric` | 0201 | **ok** | extended | 342,721 | $0.0020 | $0.0020 | $0.0016 | $0.0013 |
| **L1** | 1 | 4.7uH | SoC DC-DC inductor | [C76799](https://www.lcsc.com/product-detail/C76799.html) | `MLZ1608M4R7WT000` | TDK | `L_0603_1608Metric` | 0603 | **ok** | extended | 19,481 | $0.0600 | $0.0502 | $0.0416 | $0.0368 |
| **L2** | 1 | 2.7nH | 2.4 GHz match, Nordic reference network | [C7216765](https://www.lcsc.com/product-detail/C7216765.html) | `LQP03HQ2N7B02D` | muRata | `L_0201_0603Metric` | 0201 | **ok** | extended | 14,906 | $0.0502 | $0.0415 | $0.0338 | $0.0312 |
| **L3, L4** | 2 | 3.5nH | 2.4 GHz match, Nordic reference network | [C3911055](https://www.lcsc.com/product-detail/C3911055.html) | `LQP03HQ3N5B02D` | muRata | `L_0201_0603Metric` | 0201 | **ok** | extended | 8,449 | $0.0431 | $0.0431 | $0.0306 | $0.0280 |
| **L10** | 1 | 0R | antenna pi series element, fitted as a jumper so the board works untuned | [C473473](https://www.lcsc.com/product-detail/C473473.html) | `0201WMF0000TEE` | UNI-ROYAL | `L_0201_0603Metric` | 0201 | **ok** | extended | 4,472,650 | $0.0009 | $0.0009 | $0.0007 | $0.0006 |
| **U1** | 1 | nRF54L10-QFAA-R7 | the SoC: BLE + Channel Sounding + NFC-A (D12) | [C44800139](https://www.lcsc.com/product-detail/C44800139.html) | `NRF54L10-QFAA-R7` | NORDIC | `QFN-48-1EP_6x6mm_P0.4mm_EP4.4x4.4mm` | VFQFN-48 | **ok** | extended | 1,003 | $3.2296 | $2.5944 | $2.3800 | $2.3800 |
| **U2** | 1 | LIS2DW12TR | 3-axis accelerometer: motion wake, DULT unwanted-tracking detection | [C189624](https://www.lcsc.com/product-detail/C189624.html) | `LIS2DW12TR` | ST | `LGA-12_2x2mm_P0.5mm` | LGA-12(2x2) | **ok** | extended | 14,150 | $1.0381 | $0.7961 | $0.7343 | $0.7343 |
| **X1** | 1 | 32.768kHz | LFXO: the rotation clock the anti-stalking timing depends on | [C32346](https://www.lcsc.com/product-detail/C32346.html) | `Q13FC13500004` | EPSON | `Crystal_SMD_3215-2Pin_3.2x1.5mm` | SMD3215-2P | **ok** | **basic** | 777,959 | $0.1714 | $0.1352 | $0.1016 | $0.0805 |
| **X2** | 1 | 32MHz | HFXO: the radio reference | [C843260](https://www.lcsc.com/product-detail/C843260.html) | `NX2016SA-32MHZ-STD-CZS-5` | NDK | `Crystal_SMD_2016-4Pin_2.0x1.6mm` | SMD2016-4P | **ok** | extended | 13,596 | $0.3518 | $0.2908 | $0.2322 | $0.2090 |
| **LS1** | 1 | 7BB-20-3 | sounder: bare Ø20 x 0.22 mm piezo bender (D11a) | — | — | — | `—` | — | — | — | — | — | — | — | — |
| **BT1** | 1 | CR2032 | the cell. The CONTACTS are three sprung C5191 fingers on halo's own land pattern - there is no bought holder | — | — | — | `—` | — | — | — | — | — | — | — | — |

## The second source for every line

Lane T6 measured **212** of the main chip in stock. Single-sourcing is not a theoretical risk on this board, so every line carries an alternate that was fetched and matched the same way as the pick.
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

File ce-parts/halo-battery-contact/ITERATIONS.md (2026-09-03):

<!-- first line generated by `bin/triad new`; every later line is authored -->
# part:halo-battery-contact — iterations

| iteration | date | why it exists |
|---|---|---|
| v0.0.1 | 2026-09-03 | created — nothing measured yet |

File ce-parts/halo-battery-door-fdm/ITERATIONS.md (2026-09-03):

<!-- first line generated by `bin/triad new`; every later line is authored -->
# part:halo-battery-door-fdm — iterations

| iteration | date | why it exists |
|---|---|---|
| v0.0.1 | 2026-09-03 | created — nothing measured yet |

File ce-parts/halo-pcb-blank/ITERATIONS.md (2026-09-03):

<!-- first line generated by `bin/triad new`; every later line is authored -->
# part:halo-pcb-blank — iterations

| iteration | date | why it exists |
|---|---|---|
| v0.0.1 | 2026-09-03 | created — nothing measured yet |

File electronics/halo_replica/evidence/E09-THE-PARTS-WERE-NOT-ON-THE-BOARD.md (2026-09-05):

# E09 — The parts were not on the board, and every check I had agreed they were

**Date:** 2026-09-05 · **Lane:** fab · **Verdict:** FAIL found, fixed, both
directions broken on purpose.

## What I believed

`fab/out/halo_replica_fab.kicad_pcb` was built, checked and reported:

```
RELAX      636 iterations, 15973 pushes, courtyard clearance 0.2 mm
PLACED     45 parts on a Ø30.0 mm disc, NO courtyard overlaps
BOUND      63 of 63 nets
```

Three numbers, all true, all measured. The board was still unroutable.

## What freerouting was actually telling me

Four consecutive auto-routing passes, each running to completion:

| pass | seconds | score | unrouted | violations |
|---|---|---|---|---|
| 1 | 505.9 | 0.00 | 106 | 54 |
| 2 | 764.3 | 0.00 | 106 | 54 |
| 3 | 453.8 | 0.00 | 106 | 54 |
| 4 | 1618.6 | 0.00 | 106 | 54 |

**I read this as "needs more passes" and gave it `-mp 100`.** It is not that.
An optimiser that returns a byte-identical score four times is not converging
slowly — it is reporting that it cannot move. 3502 s of wall time and 1913 s of
CPU bought exactly nothing, and no `.ses` was ever written, because freerouting
emits only at the end of its full pass budget.

**The reading rule:** identical unrouted/violation counts across passes means
CANNOT ROUTE. Only a *changing* score means slow. Do not raise the pass budget
against a flat score; diagnose the input.

## The defect

`Board(diameter=30)` places the disc at centre **(15, 15)** — origin at the
corner of the bounding box, not at the centre. `board_fab.py` computed every
position on rings centred on **(0, 0)** (`RINGS = {0: 0.0, 1: 5.4, … 4: 12.4}`,
`R_KEEP` a radius, `math.hypot(*pos[r])` a distance from the centre) and handed
those numbers straight to `place()` and `SetPosition()` without ever adding the
centre.

Measured off the built board:

```
EDGE.CUTS bbox mm: x -0.050..30.050  y -0.050..30.050
FOOTPRINTS: 45      x -11.932..10.876   y 19.782..41.714
OUTSIDE edge-cuts bbox: 33 of 45
```

The whole cloud sat off the copper. Freerouting was being asked to route parts
that were not on the board — so it routed 5 of 111 connections and flatlined.

## Why every check I had said it was fine

```python
outside = [(r, …) for r, p in pos.items() if math.hypot(*p) > R_KEEP]
```

`pos` is the intermediate the relaxation loop just computed, and `R_KEEP` is a
radius in that same origin-centred frame. **The check and the thing it checks
share a frame, so it is true by construction and stayed green through the entire
bug.** Same for the courtyard-overlap check: relative distances between parts are
invariant under a translation, so a rigid shift of all 45 parts off the board
changes not one of its numbers. Both checks were correct. Neither could fail on
this defect.

This is E07's shape — a check that cannot fail — arriving through a **frame**
rather than through an estimator. The two checks were not weak; they were asking
about the intermediate when the defect was in the handoff to the artifact.

## The check that can fail

Read every footprint position **back out of the board** and compare it to the
**real Edge.Cuts circle**, measured from the board, not from any variable the
placement code produced:

```python
_eb  = b._pcb.GetBoardEdgesBoundingBox()
_ecx = (_eb.GetLeft() + _eb.GetRight()) / 2e6
_ecy = (_eb.GetTop()  + _eb.GetBottom()) / 2e6
_er  = min(_eb.GetWidth(), _eb.GetHeight()) / 2e6
for _fp in b._pcb.GetFootprints():
    _p = _fp.GetPosition()
    if math.hypot(_p.x/1e6 - _ecx, _p.y/1e6 - _ecy) > _er:
        REFUSE
```

Nothing in it comes from `pos`, `RINGS`, `R_KEEP` or `coords`.

## Broken on purpose, twice, in the two shapes that matter

- **Global shift** — removed the translation in `SetPosition`:
  `PLACEMENT REFUSED: 36 of 45 footprints read back OUTSIDE the Ø30.10 mm
  Edge.Cuts circle at (15.00,15.00): [('AE1', 29.77), ('C10', 18.68), …]`
- **One single part** — this one was *not* staged; it was found. With the
  `SetPosition` frame fixed but `place()` still unfixed, the check caught
  **`BT1` alone at 21.21 mm** — exactly `hypot(15, 15)`, the signature of a part
  left at raw `(0, 0)`. `BT1` is in `BACK_SIDE`, excluded from `pos`, so the
  relaxation loop never touched it and it kept its wrong `place()` position.
  **A second, independent defect that the old checks also could not see.**

A check that fires only on a global shift could be passed by any localised
error. This one fired on both.

## After

```
ONBOARD    45/45 footprints read back inside Edge.Cuts (Ø30.10 mm at 15.00,15.00)
           - measured from the board
PLACED     45 parts on a Ø30.0 mm disc, NO courtyard overlaps
BOUND      63 of 63 nets
```

## What is not settled here

That the parts are now *on* the board is not a claim that the board routes. The
routing result is a separate measurement and is recorded separately.

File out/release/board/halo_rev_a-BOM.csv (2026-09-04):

Comment | Designator | Footprint | LCSC Part # | Quantity | Value
100nF | C2,C1,C3,C4 | C_0201_0603Metric | C5142565 | 4 | 100nF
10k | R7,R5,R10,R6,R8 | R_0201_0603Metric | C473048 | 5 | 10k
2.7nH | L2 | L_0201_0603Metric | C7216765 | 1 | 2.7nH
1.0nF | C24,C25 | C_0201_0603Metric | C161371 | 2 | 1.0nF
10nF | C6 | C_0201_0603Metric | C76941 | 1 | 10nF
2.2uF | C8,C5 | C_0201_0603Metric | C335106 | 2 | 2.2uF
0R | L10 | L_0201_0603Metric | C473473 | 1 | 0R
0.5pF | C21,C20 | C_0201_0603Metric | C237424 | 2 | 0.5pF
100R | R9 | R_0201_0603Metric | C270366 | 1 | 100R
4.7M | R2,R1 | R_0201_0603Metric | C778408 | 2 | 4.7M
3.5nH | L4,L3 | L_0201_0603Metric | C3911055 | 2 | 3.5nH
3.9pF | C23 | C_0201_0603Metric | C1852416 | 1 | 3.9pF
2.2nF | C7 | C_0201_0603Metric | C161479 | 1 | 2.2nF
2.0pF | C19 | C_0201_0603Metric | C668326 | 1 | 2.0pF
1.5pF | C18 | C_0201_0603Metric | C435397 | 1 | 1.5pF
100pF | C13 | C_0201_0603Metric | C76922 | 1 | 100pF
0.3pF | C22 | C_0201_0603Metric | C3904589 | 1 | 0.3pF
10uF | C9,C12,C10,C11 | C_0402_1005Metric | C15525 | 4 | 10uF
nRF54L10-QFAA-R7 | U1 | QFN-48-1EP_6x6mm_P0.4mm_EP4.4x4.4mm | C44800139 | 1 | nRF54L10-QFAA-R7
4.7uH | L1 | L_0603_1608Metric | C76799 | 1 | 4.7uH
LIS2DW12TR | U2 | LGA-12_2x2mm_P0.5mm | C189624 | 1 | LIS2DW12TR
32MHz | X2 | Crystal_SMD_2016-4Pin_2.0x1.6mm | C843260 | 1 | 32MHz
32.768kHz | X1 | Crystal_SMD_3215-2Pin_3.2x1.5mm | C95361 | 1 | 32.768kHz

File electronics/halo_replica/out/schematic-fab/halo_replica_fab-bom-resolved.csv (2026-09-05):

Comment | Designator | Footprint | LCSC Part # | MPN | Quantity | Order code source
100nF 16V X7R | C7,C8,C9,C11,C12,C13,C19,C25 | Capacitor_SMD:C_0402_1005Metric | C1525 | CL05B104KO5NNNC | 8 | research/fetched/E-lcsc-price-pull-2026-09-03.md:57 names CL05B104KO5NNNC beside C1525 [0402, stock 6842900] | package PASS: both say 0402
nRF52832-QFAA-R | U1 | Package_DFN_QFN:QFN-48-1EP_6x6mm_P0.4mm_EP4.4x4.4mm | C77540 | NRF52832-QFAA-R | 1 | research/fetched/E-lcsc-price-pull-2026-09-03.md:9 names NRF52832-QFAA-R beside C77540 [QFN-48-EP(6x6), stock 29868] | package PASS: both say 48 pins, 6x6 mm
MAX98357A class-D, TQFN-16 | U5 | Package_DFN_QFN:TQFN-16-1EP_3x3mm_P0.5mm_EP1.23x1.23mm | C910544 | MAX98357AETE+T | 1 | research/fetched/E-lcsc-price-pull-2026-09-03.md:34 names MAX98357AETE+T beside C910544 [TQFN-16-EP(3x3), stock 17515] | package PASS: both say 16 pins, 3x3 mm
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

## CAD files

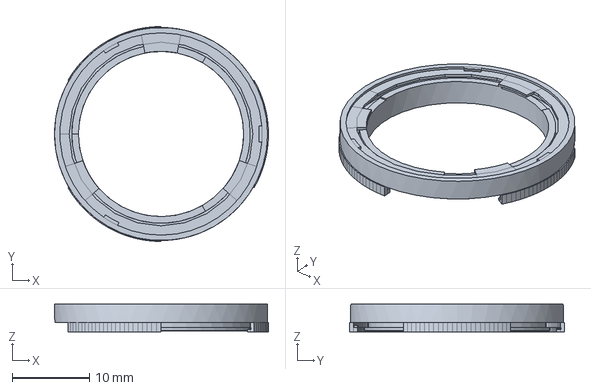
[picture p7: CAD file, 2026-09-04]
out/mech/halo-carrier.step
27.7 x 27.8 x 3.61 mm

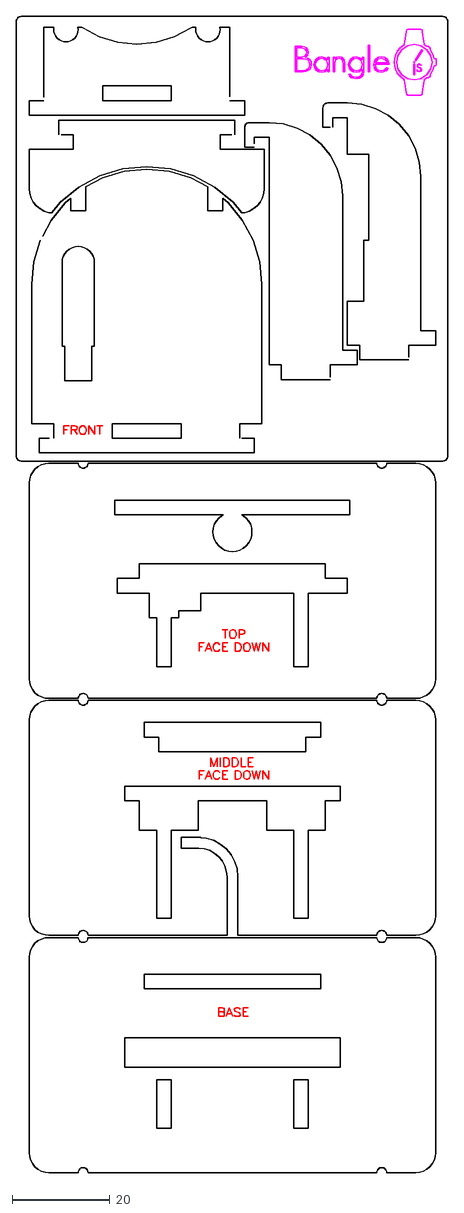
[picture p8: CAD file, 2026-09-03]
reference/EspruinoBoard/Bangle.js/banglejs_dock_3mm.dxf
88.2 x 236.2

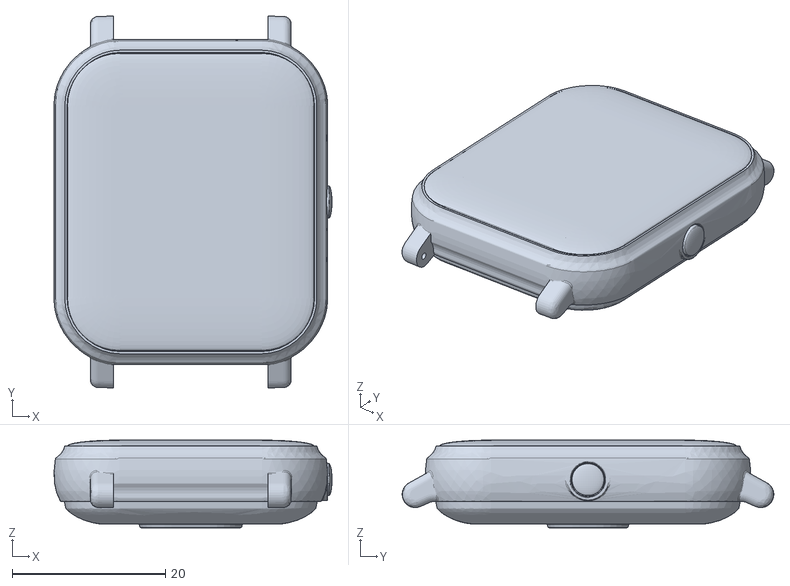
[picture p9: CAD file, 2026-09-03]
reference/EspruinoBoard/Bangle.js2/body.stl
36.3 x 48.5 x 11.4

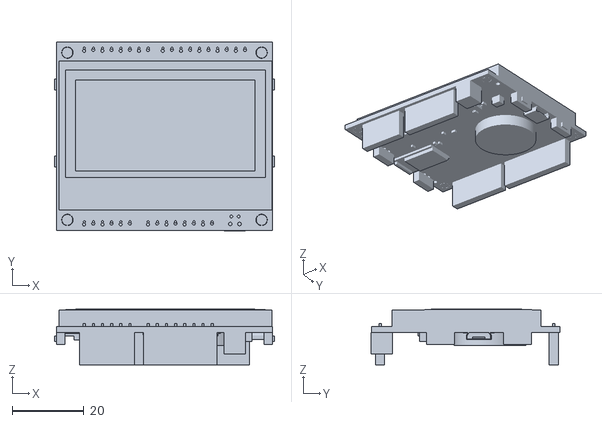
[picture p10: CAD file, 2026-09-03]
reference/EspruinoBoard/Pixl.js/other/pixljs.stl
61.2 x 52.6 x 15.5

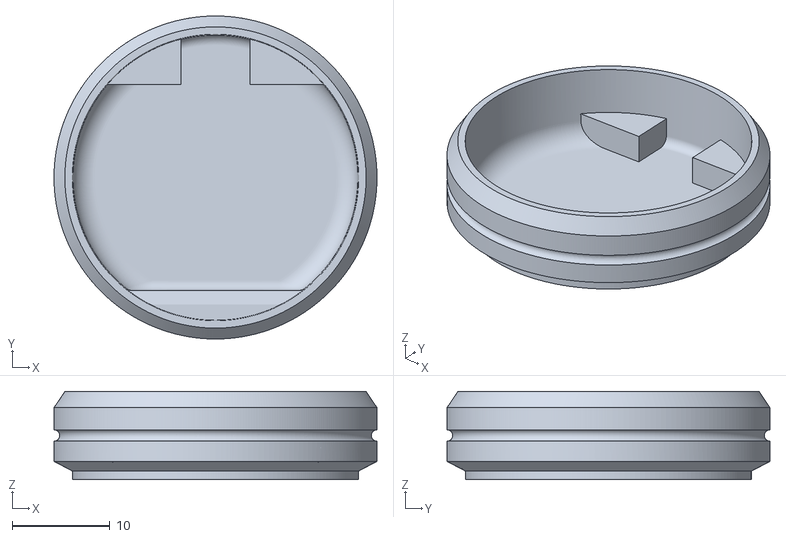
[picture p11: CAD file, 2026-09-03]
reference/EspruinoBoard/Puck.js/case/bottom_button_holder.stl
33.0 x 33.0 x 9.00

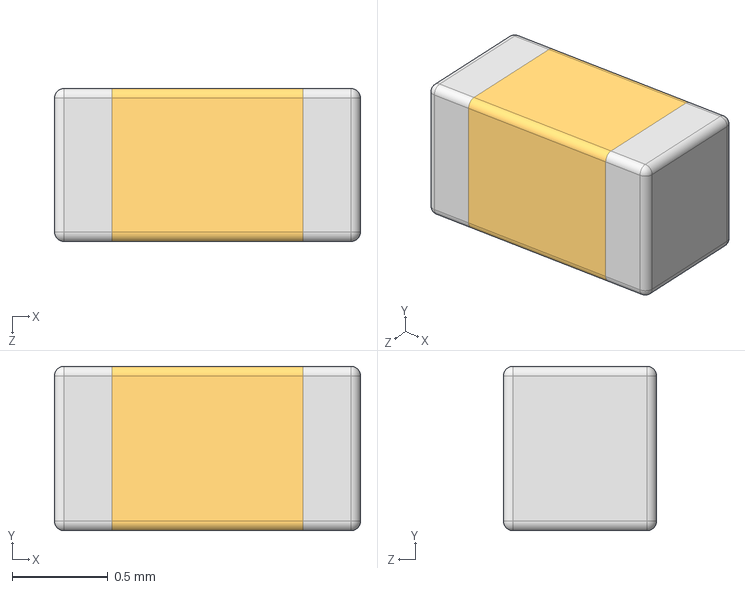
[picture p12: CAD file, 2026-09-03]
reference/Everytag/hardware/ALTIUM_EMBEDDED_MODELS/User Library-Chip Capacitor 0603.step
1.60 x 0.86 x 0.8 mm

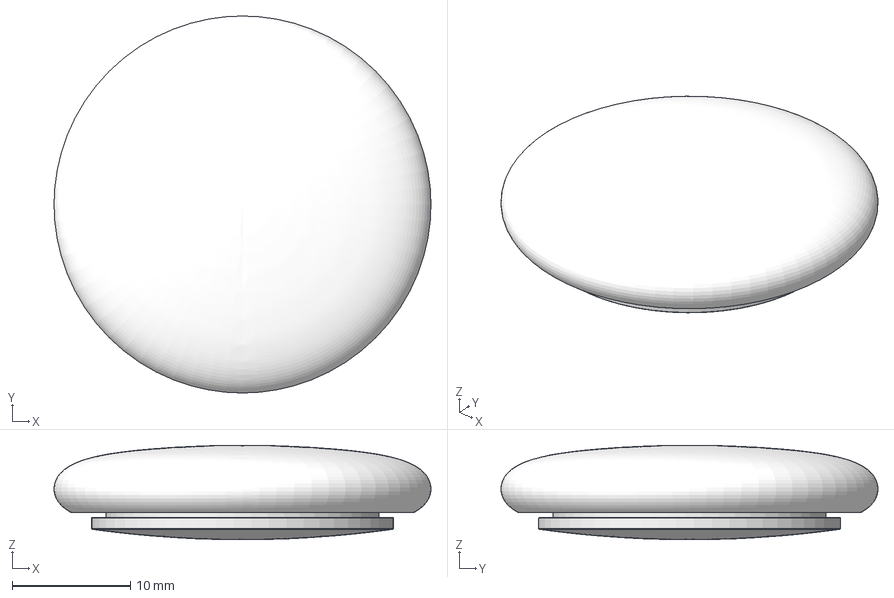
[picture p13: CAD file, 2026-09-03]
reference/models/airtag-classicgod/airtag.step
31.9 x 31.9 x 7.98 mm

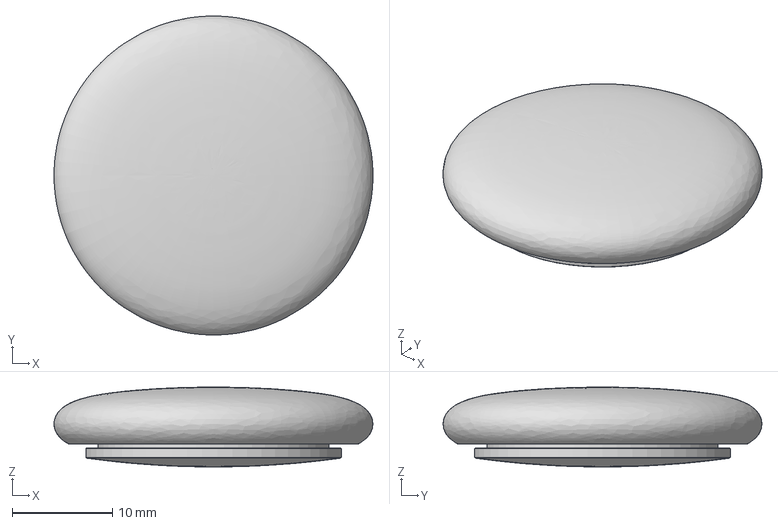
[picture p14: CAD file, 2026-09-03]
reference/models/airtag-gustav-hires/AirTag.step
31.9 x 31.9 x 7.98 mm

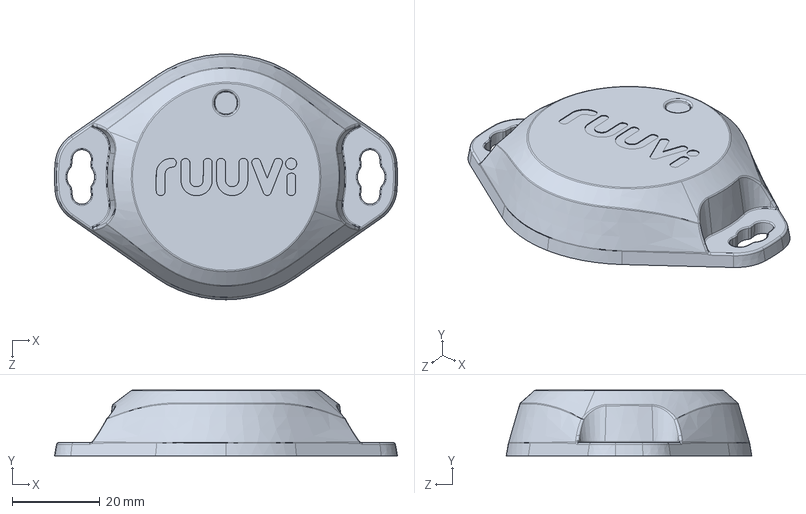
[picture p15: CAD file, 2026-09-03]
reference/models/ruuvitag-enclosure/ruuvitag-pro-simplified-enclosure.step
78.2 x 15.0 x 56.0 mm

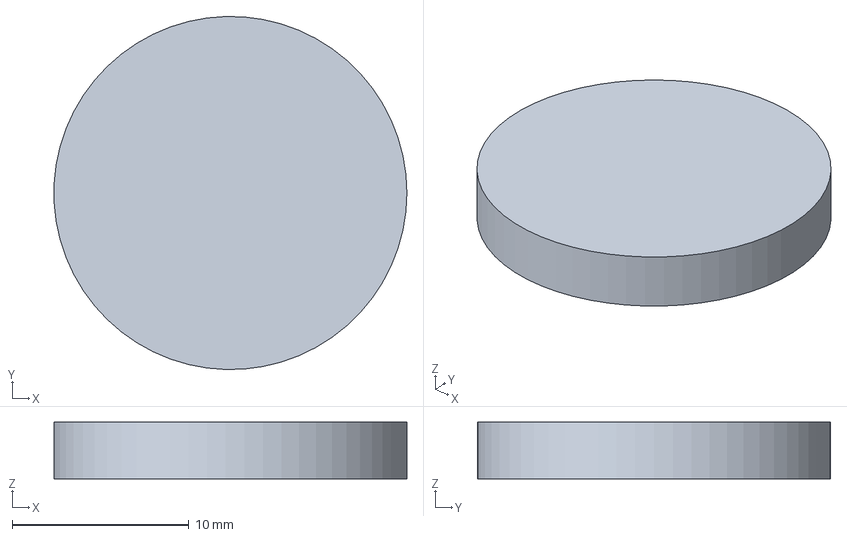
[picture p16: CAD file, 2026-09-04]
out/mech/halo-cr2032.step
20.0 x 20.0 x 3.20 mm

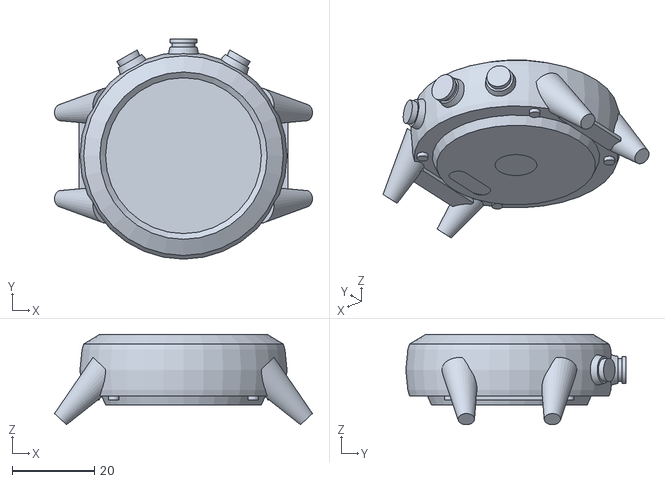
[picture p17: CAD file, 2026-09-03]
reference/EspruinoBoard/Bangle.js/banglejs_form.stl
62.9 x 53.8 x 22.1

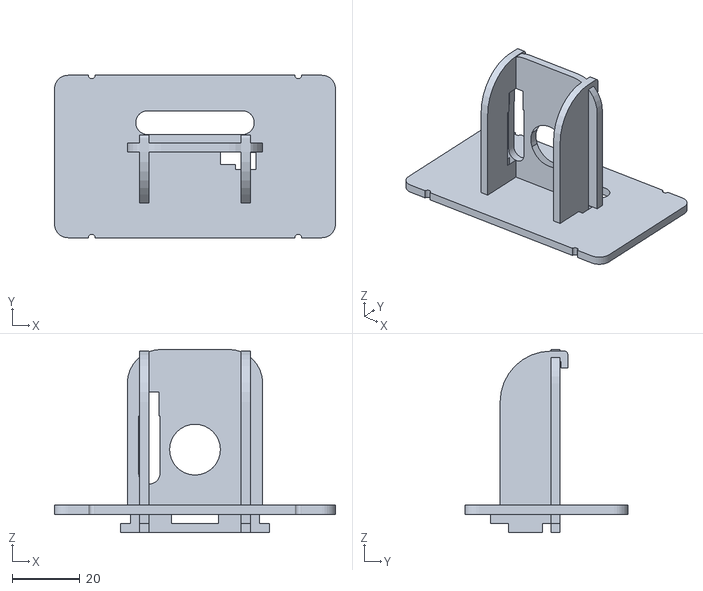
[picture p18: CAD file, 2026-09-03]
reference/EspruinoBoard/Bangle.js2/stand.stl
83.0 x 48.0 x 54.1

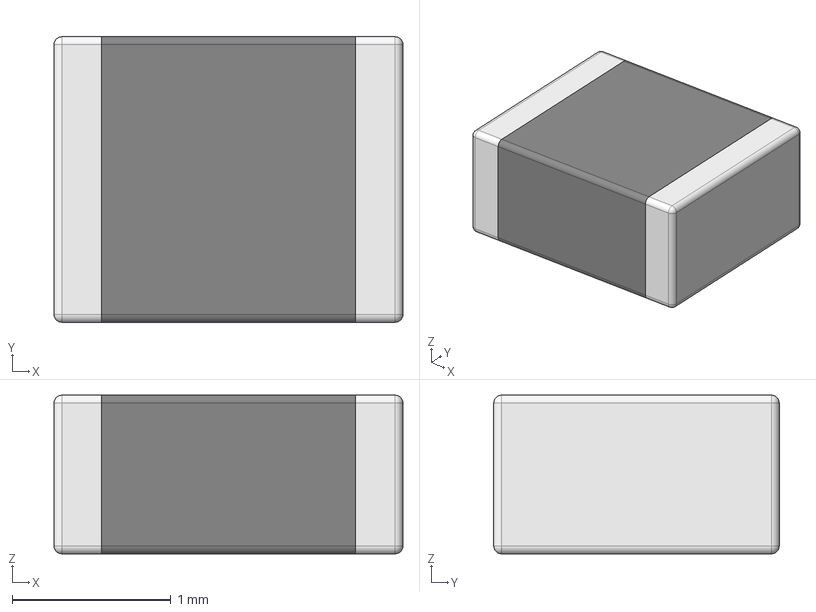
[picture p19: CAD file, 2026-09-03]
reference/Everytag/hardware/ALTIUM_EMBEDDED_MODELS/INDC2016X10N.step
2.20 x 1.80 x 1.00 mm

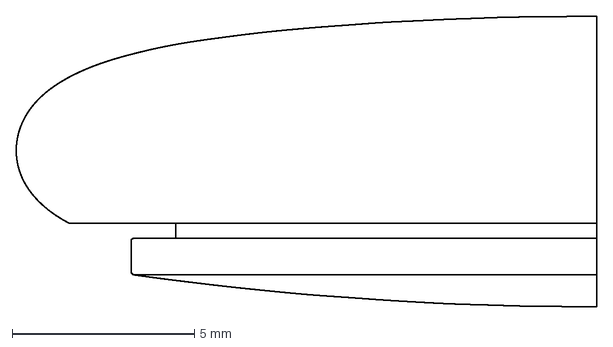
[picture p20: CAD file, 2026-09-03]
reference/models/airtag-classicgod/airtag_dimensions.dxf
15.9 x 7.98 mm

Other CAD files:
reference/models/airtag-mediaman3d/Apple_AirTag_V2.stl
reference/EspruinoBoard/Puck.js/case/bottom_no_attachment.stl
reference/models/airtag-gustav-hires/Cutout 0.15mm margin.stl
reference/models/ruuvitag-enclosure/ruuvitag-enclosure-base.step
reference/EspruinoBoard/espruino_logo.scad
reference/EspruinoBoard/boxes/espruino_box.scad
reference/EspruinoBoard/boxes/espruino_box2.scad
reference/EspruinoBoard/boxes/espruino_box3.scad
out/mech/halo-battery-contact-neg.step
out/mech/halo-battery-contact-neg.stl
out/mech/halo-battery-contact-pos-a.step
out/mech/halo-battery-contact-pos-a.stl
out/mech/halo-battery-contact-pos-b.step
out/mech/halo-battery-contact-pos-b.stl
out/mech/halo-battery-door-fdm.step
out/mech/halo-battery-door-fdm.stl
out/mech/halo-battery-door.step
out/mech/halo-battery-door.stl
out/mech/halo-carrier.stl
out/mech/halo-cr2032.stl
out/mech/halo-door-seal.step
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

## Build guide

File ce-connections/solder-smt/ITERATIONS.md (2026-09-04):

<!-- first line generated by `bin/triad new`; every later line is authored -->
# connection:solder-smt — iterations

| iteration | date | why it exists |
|---|---|---|
| v0.0.1 | 2026-09-04 | created — nothing measured yet |

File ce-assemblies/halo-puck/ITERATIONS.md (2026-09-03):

<!-- first line generated by `bin/triad new`; every later line is authored -->
# assembly:halo-puck — iterations

| iteration | date | why it exists |
|---|---|---|
| v0.0.1 | 2026-09-03 | created — nothing measured yet |

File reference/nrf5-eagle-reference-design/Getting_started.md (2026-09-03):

# Getting started with nRF5 and CadSoft EAGLE (R)

Nordic Semiconductor already provides [reference designs][altiumreference] for Altium Designer (R), but if you prefer EAGLE here is a quick guide on how to use the EAGLE reference design.

This quick guide assumes you are familiar with doing PCB designs in EAGLE, otherwise both [Adafruit] and [SparkFun] have guides on how to get started.

1. First clone or download the reference designs and libraries from [Github]
2. Select the reference-design that fits your application (if you are uncertain use *nRF52832_qfaa_dcdc*)
3. Add your own parts in the circuit diagram
4. Create the layout and routing
	* Do not modify the geometry of the rf part

Please refer to the general pcb design guidelines for [nRF51][designguidenrf51] or [nRF52][designguidenrf52].

### 1. First clone or download the reference designs and libraries from [Github]

If you are familiar with [git] this is self explanatory, if not press the (green) "Clone or download" button and then "Download ZIP".

### 2. Select the reference-design that fits your application

All reference designs supplied here are for the QFN package.
If you want to use the internal ldo (not recommended) select nRF5\*_qfaa, if you want an example of nfc antenna usage select nRF5\*_qfaa_nfc.
You probably want the nRF51x2_qfaa_dcdc or nRF52832_qfaa_dcdc, for nRF51 or nRF52 respectively.

### 3. Add your own parts in the circuit diagram

Here is the part where you do your design, use your own libraries, use libraries supplied with eagle, use parts from the Nordic_misc library, make your own parts, etc.

### 4. Do the layout and routing

This is also a part of your regular workflow. Lay out your design next to or around the reference layout.

#### Do not modify the geometry of the rf part

Now, the important part: Do not add components close to the rf layout. This means around where you attach the antenna (the signal named RF).
The cutout in the ground plane is there for a reason. Add cutouts to any internal layers of the pcb as well. There should be a ground plane on the bottom layer.
Add a generous amount of ground stiching vias (remember vias are free).

### 5. Done

There. You are done with your nRF5 design in eagle, dont forget to run design reviews before ordering pcbs. And dont forget to tune the antenna when you have your prototype in hand.

# Some info on the git repository

## Reference designs
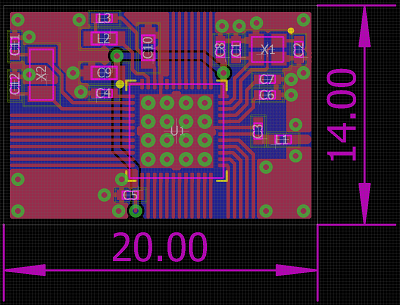
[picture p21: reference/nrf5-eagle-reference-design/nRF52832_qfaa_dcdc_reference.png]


The reference designs supplied for eagle are made by following the [general pcb design guidelines][designguidenrf52] and referencing the [altium reference layout][altiumreference].
The reference designs include eagle files as well as pdf printouts. For BOM see the altium reference designs.

* nRF51x22_qfaa
* nRF51x22_qfaa_dcdc
* nRF52832_qfaa
* nRF52832_qfaa_dcdc
* nRF52832_qfaa_nfc

## Libraries

### Nordic_nRF
This library contains the nRF51 and nRF52 in QFN and bga packages, as well as; capacitors, inductors, and a 32MHz and 32kHz xtal. All that is needed for the core reference design.

### Nordic_misc
This library contains the rest of the components used in the sample eagle design(s) in the github repository, as well as some simple antenna suggestions.

## Antenna
In the Nordic_misc library there is supplied some suggestions for antennas, please note that antenna characteristics depends greatly on the board layout. These antennas are made according to the [whitepaper][monopole] on quarter wave monopole 2.45 GHz antennas. Remember to [tune][antuning] the antenna.

## NFC
An NFC listener antenna suggestion is supplied in the Nordic_misc library, this is the antenna used in the [nRF52-DK] development kit. Remember to [tune][nfctune] the antenna.

[sparkfun]: <https://www.sparkfun.com/>
[adafruit]: <https://www.adafruit.com/>
[github]: <https://github.com/NordicPlayground/nrf5-eagle-reference-design>
[designguidenrf51]: <https://devzone.nordicsemi.com/blogs/655/general-pcb-design-guidelines-for-nrf51/>
[designguidenrf52]: <https://devzone.nordicsemi.com/blogs/870/general-pcb-design-guidelines-for-nrf52/>
[referencecircuitry]: <https://infocenter.nordicsemi.com/index.jsp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>
[altiumreference]: <http://infocenter.nordicsemi.com/index.jsp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>
[nfctune]: <https://devzone.nordicsemi.com/blogs/957/nfc-tag-antenna-tuning/>
[nRF52-DK]: <http://www.nordicsemi.com/eng/Products/Bluetooth-low-energy2/nRF52-DK>
[dcdc_reference]: <nRF52832_qfaa_dcdc_reference.png>
[monopole]: <http://infocenter.nordicsemi.com/topic/com.nordic.infocenter.whitepapers/dita/whitepapers/pdflinks/nwp_008.html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>
[antuning]: <https://infocenter.nordicsemi.com/topic/com.nordic.infocenter.whitepapers/dita/whitepapers/pdflinks/nwp_017.html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>
[git]: <https://git-scm.com/>

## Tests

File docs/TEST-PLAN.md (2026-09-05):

# halo — production test plan — what the factory measures on every unit, with limits, fixtures and sources

*Lane P1. Generated 2026-09-05 from `spec/test-plan.json` by `tools/gen_test_plan.py`. Nothing on this page is hand-typed. Companion: [`docs/TOOLS-THAT-LIE.md`](TOOLS-THAT-LIE.md), which is the standard this plan is written to, and [`out/release/TEST-PLAN.html`](../out/release/TEST-PLAN.html), which is the same data as a page for the factory.*

Thirty-one tests across three stations. Every limit in this plan names the datasheet page, the standard, the DECISIONS entry or the in-repo measurement it came from. Where no source exists the limit is written CANNOT DETERMINE with the one measurement that would settle it, because a limit we invented would be worse than no limit: the line would run to it, and the number would be wrong.

三个工位，三十一项测试。本计划中的每一个限值都注明来源：数据手册页码、标准条款、DECISIONS 决策记录，或本仓库内的实测值。凡无来源者一律写作 CANNOT DETERMINE（无法判定），并写明用哪一次测量可以定案 —— 因为我们编造的限值比没有限值更糟：产线会照着它做，而那个数字是错的。

---

## 1. The plan in numbers

**31 tests. 22 run on every unit. 99 limits, 87 of them gates a unit is judged against. 21 limits are CANNOT DETERMINE and name what would settle them, 15 of those being gates. Cycle-time estimate 4.4 min (263 s) per unit across all three stations; the busiest station is Assembled board in its carrier at 2.6 min (154 s), and that is the line's takt.**

| # | station | tests | on every unit | go/no-go | open limits | cycle per unit |
|---|---|---|---|---|---|---|
| 1 | Bare board | 5 | 1 | 3 | 4 | 21.1 s |
| 2 | Assembled board in its carrier | 17 | 15 | 12 | 3 | 2.6 min (154 s) |
| 3 | Sealed unit | 9 | 6 | 7 | 5 | 1.5 min (89 s) |
| | **total** | **31** | **22** | **22** | **12** | **4.4 min (263 s)** |

Per-unit cycle time is computed by tools/gen_test_plan.py as the sum over all tests of cycle_s × sampling_fraction, where the fraction is 1.0 for a 100 % test and n/lot for a sample test. Sample tests are amortised over an assumed lot of 500 units. The result is derived from the data, never typed.

Station cycle time is the sum for that station's stage. The line's takt is set by the slowest station, not by the total — the three stations run in parallel on different units. The dominating single test is AB-11 at 22 s, which is set by DULT's own advertising interval: to prove an interval of ≤ 4 s you must watch for long enough to count five advertisements.

- AB-11 and AB-06 can share one 20 s capture window at the same station, since both are radio observations of the same unit — this is already assumed in the station roll-up.
- AB-07's 8 s sleep window is the second-longest. It can be shortened only by accepting a noisier average; do not shorten it by starting the average before the part is actually asleep.
- FU-03 and FU-04 cannot be merged: the acoustic hood and the RF-quiet box are mutually exclusive environments, and the sounder command in FU-04 has to be heard by FU-03's microphone. Either the unit moves between two nests, or one nest is both, which is a harder fixture.

## 2. What each station is for

**1. Bare board** — at the PCB fabricator, before any component is placed. The copper is right and the board is buildable. Everything here is the fab's own process control; halo's job is to require the report and to check that the report was run against the right netlist.

**2. Assembled board in its carrier** — after reflow, after the board is seated in the LCP carrier with its three stamped contacts, before the shell is bonded. Every semiconductor answers, every rail is where it should be, the unit is programmed and given its identity, and all four radios-and-transducers paths — Bluetooth, NFC, motion, sounder drive — are proven electrically. This is the last station where anything can be reworked.

**3. Sealed unit** — after the shell is bonded to the carrier, cell fitted, door closed, label applied. The product as the customer receives it, running from its own cell with no wires attached. If a unit fails here it is a scrap or a de-bond investigation, never a rework — the parting line is a structural adhesive joint (MECHANICAL §7) and it does not come apart twice.

## 3. The tests

The verdict column grades THE TEST, not the unit. PASS = every GATE limit in the row traces to a named source, so the row can be run on a line as written. CANNOT DETERMINE = at least one gate limit has no source yet; the row says which and what would settle it. A gate is any limit the station judges a unit against; rows marked 'record', 'note' or '≈' are readings and design anchors, not gates, and a plan can be runnable while some of its recorded quantities still have no window. Section 10 lists every open limit, gate or not. No row is graded on whether a unit would pass it — nothing has been built.

> docs/TOOLS-THAT-LIE.md — every test row carries the sentence "this could report PASS while ___ is badly wrong" and the assert that closes it. A row with an empty counter-assert is not finished.

### Station 1 — Bare board (5 tests)

#### BB-01 — Netlist continuity and isolation, 100 % of nets — **CANNOT DETERMINE**

- **Proves.** the copper the fabricator made is the copper the schematic asked for
- **Traces to.** SPEC §6 M1; IPC-9252B (electrical test of unpopulated boards); electronics/halo_rev_a/out/halo_rev_a.net
- **Measurement.** flying-probe or grid test against the IPC-D-356 netlist exported from halo_rev_a.net
- **Limits.**
  - `nets tested = 41 nets` — halo_rev_a.net carries 52 net records, 11 of which are auto-generated unconnected-(U1-…) singles. 41 real nets remain and every one must appear in the ET report.
  - `opens = 0 count` — IPC-9252B — an open is a reject at any class
  - `shorts = 0 count` — IPC-9252B
  - `continuity threshold ≤ — Ω` — CANNOT DETERMINE — this plan does not hold a copy of IPC-9252B and will not quote its default table from memory. Settle it by taking the threshold from the fabricator's own ET process sheet and recording it here; the fab must state the value it used.
  - `isolation threshold ≥ — Ω` — CANNOT DETERMINE — same reason, same fix.
- **Equipment.** EQ-ET
- **Sampling.** 100 %
- **Type / cycle.** go/no-go, 20 s
- **On failure.** scrap — a bare board is the cheapest thing in the build and rework of inner-layer copper is not a thing
- **Recorded.** panel id, board position, net count tested, opens, shorts, the thresholds the fab used
- **This could report PASS while…** the netlist the tester ran against was extracted from the Gerbers rather than from the schematic — in which case a copper feature that is wrong in both files passes cleanly
- **…so assert.** the ET report's net count must equal 41. A Gerber-extracted netlist does not produce halo's net names or its count; it produces whatever the copper happens to connect.

#### BB-02 — Outline diameter and finished thickness — **CANNOT DETERMINE**

- **Proves.** the board fits the carrier's seat and the 7.980 mm stack still closes
- **Traces to.** DECISIONS.md D17; docs/MECHANICAL.md §2; design.py D_PCB / T_PCB
- **Measurement.** calipers on the routed outline at three angles; micrometer on the finished thickness at three points
- **Limits.**
  - `outline diameter = 26.0 mm` — design.py D_PCB, the value lane M's stack budget closes on (DECISIONS.md D17)
  - `finished thickness = 0.6 mm` — D17 — the 1.742 mm recovered by deleting Apple's motor was spent on a 0.60 mm board instead of Apple's 0.30 mm
  - `outline tolerance ± — mm` — CANNOT DETERMINE — halo has never stated a board tolerance. Settle it from the fabricator's routing capability sheet (JLCPCB publishes ±0.2 mm as standard) and record the agreed figure in SPEC §6.
  - `thickness tolerance ± — mm` — CANNOT DETERMINE — same. On a 0.60 mm board a ±10 % fab tolerance is ±0.06 mm and the stack has 0.542 mm of slack (MECHANICAL §2), so this is very unlikely to bind; it still has to be written down before it can be tested.
- **Equipment.** —
- **Sampling.** 5 boards per delivered panel lot
- **Type / cycle.** recorded, 60 s
- **On failure.** investigate at the fab — an outline error is a routing-program error and it is on every board in the lot, not on one
- **Recorded.** lot id, three diameters, three thicknesses
- **This could report PASS while…** the operator measures the panel rail instead of the board, or measures across a tab rather than the routed edge
- **…so assert.** three diameters at three different angles must agree within the measurement resolution; a tab or a rail shows up immediately as one reading that does not match the other two.

#### BB-03 — Controlled-impedance coupon — **CANNOT DETERMINE**

- **Proves.** the RF_50 trace is actually 50 Ω in the stackup the fab built, not in the stackup we drew
- **Traces to.** SPEC §5 E4; SPEC §6 M1; the stackup in out/release/board/ (lane B1 / T6)
- **Measurement.** TDR on the panel's impedance coupon
- **Limits.**
  - `single-ended impedance = 50 Ω` — the RF_50 net name and Nordic's reference circuit config 1 (schematic title-block comment 3); the antenna feed is a 50 Ω interface by construction
  - `impedance tolerance ± — %` — CANNOT DETERMINE — halo has not stated one. ±10 % is the industry-usual controlled-impedance class and is what most fabs quote by default, but this plan will not print a number nobody in this repo chose. Settle it in the stackup document, then this row becomes a hard limit.
- **Equipment.** —
- **Sampling.** one coupon per panel
- **Type / cycle.** recorded, 120 s
- **On failure.** investigate — an impedance miss is a stackup or an etch-compensation problem and affects the whole panel
- **Recorded.** panel id, measured Z0, the stackup revision the fab built
- **This could report PASS while…** the coupon was built from a different stackup than the boards, or the TDR was calibrated at the cable end rather than the probe tip
- **…so assert.** the coupon must be on the same panel as the boards it certifies, and the fab's report must name the stackup revision. Two coupons at opposite corners of the panel must agree.

#### BB-04 — Surface finish and solderability — **CANNOT DETERMINE**

- **Proves.** the 0201 and 0.4 mm-pitch QFN pads will wet
- **Traces to.** SPEC §6 M3; IPC-6012 (qualification and performance of rigid boards); IPC-4552 (ENIG); J-STD-003 (solderability)
- **Measurement.** the fabricator's own finish thickness measurement and solderability coupon
- **Limits.**
  - `gold and nickel thickness in — µm` — CANNOT DETERMINE — the surface finish has not been chosen in this repo. Settle it by naming the finish in the fabrication drawing (ENIG is the usual pick for a 0.4 mm-pitch QFN and 0201 passives), then take the thickness band from IPC-4552 and record it here.
  - `solderability = pass J-STD-003 category` — J-STD-003; the fabricator's coupon result, reported per lot
- **Equipment.** —
- **Sampling.** the fab's per-lot coupon
- **Type / cycle.** go/no-go, 0 s
- **On failure.** reject the lot — a non-wetting finish produces head-in-pillow joints that pass AOI and fail in the field
- **Recorded.** lot id, finish type, measured thickness, solderability result
- **This could report PASS while…** the coupon is from a different lot, or the finish is fresh and the boards sit for six months before assembly
- **…so assert.** record the fab date and require assembly within the finish's stated shelf life; a coupon result without a date on it is not evidence about the boards being built today.

#### BB-05 — Castellation integrity on the reserved UWB stub — **PASS**

- **Proves.** the eight plated half-vias on the board edge (J2) are not torn out by the routing pass
- **Traces to.** DECISIONS.md D12 (the DW3110 footprint is reserved, not populated); electronics/halo_rev_a/schematic.py block 9
- **Measurement.** microscope inspection of the eight half-vias plus continuity from each castellation to its net
- **Limits.**
  - `castellations with intact plating = 8 count` — schematic.py block 9 — J2 is an 8-way castellated stub
  - `burr or torn plating = 0 count` — a torn half-via is an open, and BB-01 will only catch it if the ET probes the castellation face
- **Equipment.** —
- **Sampling.** 5 boards per panel lot
- **Type / cycle.** go/no-go, 45 s
- **On failure.** investigate the routing program — it is a tool-path problem, not a board problem
- **Recorded.** lot id, count of intact castellations, photograph of any defect
- **This could report PASS while…** the ET probed the pad on the top surface rather than the castellation face, so a half-via that is open at the edge reads connected
- **…so assert.** probe the castellation face itself, at the board edge, and say so in the ET program. This is why the check is separate from BB-01 rather than folded into it.

### Station 2 — Assembled board in its carrier (17 tests)

#### AB-01 — Post-reflow automated optical inspection — **CANNOT DETERMINE**

- **Proves.** every one of the 51 placements is present, right way round, and wetted
- **Traces to.** SPEC §6 M3; IPC-A-610 (acceptability of electronic assemblies); the CPL in out/release/board/
- **Measurement.** AOI against the recipe built from the pick-and-place file
- **Limits.**
  - `placements inspected = 51 components` — halo_rev_a.net — 51 component records, of which C14–C17 are DNP crystal load capacitors and must be inspected as deliberately absent
  - `acceptance class = — IPC-A-610 class` — CANNOT DETERMINE — halo has never chosen a class. Class 2 is the default for consumer product and Class 3 would be an odd choice for a $7 tag, but nobody in this repo has decided, and the class changes the fillet criteria the AOI recipe is built from. This is a decision for the release pack, not for a test engineer to assume.
- **Equipment.** EQ-AOI
- **Sampling.** 100 %
- **Type / cycle.** go/no-go, 15 s
- **On failure.** rework — this is the station where a tombstoned 0201 is cheap to fix
- **Recorded.** board serial (panel + position), AOI defect codes, the recipe revision
- **This could report PASS while…** the four DNP crystal load capacitors C14–C17 are flagged as missing and the operator learns to click through the four false alarms, and clicks through a real one
- **…so assert.** C14–C17 must be programmed into the recipe as REQUIRED-ABSENT, so a board with them fitted fails. A DNP that is silently ignored trains the operator; a DNP that is asserted absent catches the day someone loads them.

#### AB-02 — Pre-power short test on the supply rail — **PASS**

- **Proves.** VDD is not shorted to GND before a cell or a supply is ever connected
- **Traces to.** electronics/halo_rev_a/schematic.py (the whole rail topology: BT1 → VDD, no regulator); ce-spice/out/cr2032_pulse_load/verdict.json
- **Measurement.** two-wire resistance between the BT1 positive pad (pad 1) and the BT1 negative pad (pad 2), test voltage below 1 V so no junction conducts
- **Limits.**
  - `R(VDD,GND) > 100000 Ω` — derived from the netlist: the lowest-resistance DC path from VDD to GND anywhere in this schematic is the cell-removal divider R1+R2 = 9.4 MΩ, and even that is gated by a GPIO that is normally not driven. 100 kΩ leaves two decades of margin under the lowest legitimate path, so anything below it is a defect and not a design current.
- **Equipment.** EQ-SMU
- **Sampling.** 100 %
- **Type / cycle.** go/no-go, 3 s
- **On failure.** rework — find the solder bridge; do not power the board first
- **Recorded.** board serial, measured resistance
- **This could report PASS while…** the meter's test voltage is high enough to forward-bias the SoC's ESD structures, so a genuine short reads as a diode drop and the operator sees 'a few hundred ohms, that's normal'
- **…so assert.** state the test voltage on the traveller and keep it under 1 V. Then there is no normal few-hundred-ohms reading: below 100 kΩ is always a fault.

#### AB-03 — SoC identity over SWD — **PASS**

- **Proves.** the part on the board is an nRF54L10 and not an L05, an L15, or a counterfeit
- **Traces to.** DECISIONS.md D12; nRF54L datasheet 4503_018 v0.10 §4.2.4.1.1.4 (INFO.PART) and §4.2.4.1.1.7 (INFO.RAM)
- **Measurement.** read the FICR block at 0x00FFC000 over SWD through the TC2030 pads
- **Limits.**
  - `INFO.PART at 0x00FFC31C = 0x00054B10 register value` — nRF54L datasheet §4.2.4.1.1.4: N54L15 = 0x00054B15, N54L10 = 0x00054B10, N54L05 = 0x00054B05. D12 picked the L10.
  - `INFO.RAM at 0x00FFC328 = 0xC0 register value` — nRF54L datasheet §4.2.4.1.1.7: K192 = 0xC0. The L10 is the 192 KB part; this is a second, independent way to tell it from an L05 (96 KB, 0x60) or an L15 (256 KB, 0x100).
  - `INFO.DEVICEID at 0x00FFC304 ≠ 0xFFFFFFFFFFFFFFFF register value` — nRF54L datasheet §4.2.4.1.1.2: a 64-bit unique device identifier, factory-programmed. The all-ones reset value means the die was never trimmed — a counterfeit or a reject.
  - `INFO.PACKAGE at 0x00FFC324 record — register value` — CANNOT DETERMINE — datasheet v0.10 §4.2.4.1.1.6 defines only 'Unspecified 0xFFFFFFFF' for this register and lists no QFN48 code. Record the value, do not assert on it, and revisit when a datasheet later than v0.10 defines the field.
- **Equipment.** EQ-SWD
- **Sampling.** 100 %
- **Type / cycle.** go/no-go, 6 s
- **On failure.** rework — replace the SoC, then re-run from AB-02
- **Recorded.** board serial, INFO.PART, INFO.RAM, INFO.DEVICEID (this is the unit's permanent key in the traceability database), INFO.PACKAGE
- **This could report PASS while…** the station reads a cached value from the previous unit because the pogo head did not make contact and the debugger returned the last successful session's data
- **…so assert.** INFO.DEVICEID is unique per die. The station must reject any DEVICEID already present in the traceability database — a stale read fails on the second board, not on the two-hundredth.

#### AB-04 — Programming, provisioning and identity readback — **PASS**

- **Proves.** the unit runs the firmware we shipped and carries a unique serial, a product ID and its own rolling key
- **Traces to.** SPEC §2 F1, F1a, F5; docs/ANTI-STALKING.md §4.1 (printed serial, unique per product ID); research/06 constraint C11; DULT §3.15.1; MISSION.md artifact 7
- **Measurement.** flash the signed image over SWD; write the serial, the product ID and the P-224 master key into UICR; read the whole region back and compare
- **Limits.**
  - `firmware image hash read back = the released build's hash SHA-256` — MISSION.md artifact 7 requires the hex and the provisioning step be part of the release; a readback compare is the only proof the write landed
  - `serial uniqueness = not previously issued database assertion` — DULT §3.15.1 — 'The serial number MUST be unique for each product ID'; research/06 C11
  - `key fingerprint stored = recorded, key material never recorded SHA-256 of the public key` — the private key must not leave the station; a fingerprint is enough to prove AB-11 saw this unit
- **Equipment.** EQ-SWD, EQ-DB
- **Sampling.** 100 %
- **Type / cycle.** go/no-go, 25 s
- **On failure.** rework — retry once, then replace the SoC. A part that fails programming twice is a part, not a process
- **Recorded.** board serial, halo serial issued, product ID, public-key fingerprint, firmware hash, station id, operator, UTC timestamp
- **This could report PASS while…** the same serial and the same key are written into every unit on the line, and every downstream test still passes because each unit is tested alone
- **…so assert.** the traceability database rejects a duplicate serial AND a duplicate key fingerprint at write time. Uniqueness is asserted by the database, never by the writer — a writer that repeats itself cannot detect that it repeated itself.

#### AB-05 — 32.768 kHz low-frequency crystal start and accuracy — **PASS**

- **Proves.** X1 oscillates, which is what the DULT key schedule and the separated-state timer are counted on
- **Traces to.** electronics/halo_rev_a/schematic.py block clocks (X1, CL 12.5 pF, ±20 ppm); docs/ANTI-STALKING.md §4.2 (15 min / 24 h rotation, 8–24 h timeout)
- **Measurement.** firmware reports LFXO started inside the startup timeout; the station then gates the RTC against its own reference for 10 s
- **Limits.**
  - `LFXO started = True boolean` — if the LFXO does not start the firmware falls back to the internal RC and the key schedule drifts — which is a DULT conformance failure, not a cosmetic one
  - `frequency error record — ppm` — CANNOT DETERMINE as a go/no-go. The crystal is specified ±20 ppm (schematic note) but the board's own load-capacitance error is not budgeted anywhere in this repo, so the assembled tolerance is unknown. Record the ppm on every unit; set the limit from the first-article distribution and from the DULT timer accuracy the firmware actually needs.
- **Equipment.** EQ-SWD
- **Sampling.** 100 %
- **Type / cycle.** recorded, 11 s
- **On failure.** rework — reflow or replace X1
- **Recorded.** board serial, LFXO start flag, measured ppm
- **This could report PASS while…** the firmware reports 'started' from a status bit that is set optimistically, while the oscillator is actually running on the internal RC
- **…so assert.** do not read a status bit — count RTC ticks against the station's reference for 10 s. An RC fallback is tens of thousands of ppm off and shows up in the first second.

#### AB-06 — 32 MHz high-frequency crystal start and carrier frequency — **PASS**

- **Proves.** X2 oscillates and the radio lands in the band
- **Traces to.** electronics/halo_rev_a/schematic.py block clocks (X2 = NDK NX2016SA-32MHZ, CL 8 pF, ±10 ppm); SPEC §5 E4
- **Measurement.** firmware puts the radio into a constant-carrier mode on channel 0 (2402 MHz); the scanner or a counter reads the carrier
- **Limits.**
  - `HFXO started = True boolean` — the radio cannot transmit at all without it, so this is implied by AB-11 — it is measured separately here so a failure names the crystal instead of the antenna
  - `carrier frequency error record — ppm` — CANNOT DETERMINE as a go/no-go. The crystal is ±10 ppm and the SoC has an internal trim (nRF54L datasheet §XOSC32MTRIM), but the Bluetooth Core Specification's centre-frequency tolerance is the number this should be judged against and this repo does not hold the Core Specification. Settle it by reading Core Spec Vol 6 Part A §3.1 and writing the ppm figure into SPEC §5.
- **Equipment.** EQ-BLE, EQ-BOX
- **Sampling.** 100 %
- **Type / cycle.** recorded, 4 s
- **On failure.** rework — reflow or replace X2
- **Recorded.** board serial, HFXO start flag, measured carrier ppm
- **This could report PASS while…** the measurement is of the scanner's own local oscillator, or of another station's DUT leaking into the box
- **…so assert.** EQ-BOX's leakage self-test (zero advertisements from a powered unit 300 mm outside the closed box) is the gate that makes any in-box reading attributable. Run it every shift and after any lid service.
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

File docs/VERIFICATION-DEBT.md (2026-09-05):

# Verification debt — what has been proven, and what still needs a physical sample

*Opened 2026-09-03. Restructured 2026-09-04 by lane V1. The rule this file
exists to enforce: **a tool is not working because a document says so; it is
working because it ran and produced a number.** MISSION.md requires every
artifact in the release pack to be generated by a tool on this machine and
graded PASS. This page tracks the gap between what the repository claims and
what has actually executed.*

**Every row below was re-run by lane V1 on 2026-09-04. Nothing here is closed
on another lane's report.** Where a number appears, it is the number that came
back on this machine, with the command beside it.

## Why this page exists

On 2026-09-03 the autorouter was found in the toolchain documentation as a
working step of the board pipeline. The jar was downloaded, the wrapper script
was written, and the workflow document described the command. **It had never
once run**, because this Mac has no Java runtime — `/usr/bin/java` is Apple's
stub, which prints "Unable to locate a Java Runtime" and exits. Nothing in the
project noticed, because nothing had asked it to route a board and checked the
result.

That is the failure mode this page is for: not a bug, but a claim that was never
tested. It is exactly what would sink a factory release pack, because the pack
is a set of claims about a board nobody has built.

## The three states, and what each means

| state | means |
|---|---|
| **CLOSED** | a command ran on this machine and produced the number in the row |
| **HARDWARE REQUIRED** | it cannot be closed without a physical sample. §2 gives the exact procedure, so the day a board exists it can be closed without asking us anything |
| **OPEN HERE** | it *can* be closed on this machine and has not been. Not hardware, not blocked — work |

---

# 1 · CLOSED

| # | claim | measured, 2026-09-04 |
|---|---|---|
| **V1** | the autorouter routes a board | **CLOSED.** OpenJDK installed. Re-run by V1: `JAVA_HOME=~/opt/jdk-21.0.12.1+1-jre/Contents/Home ce-pcb/bin/route --doctor` reports `jar runs → Freerouting v2.3.0 (build-date: 2026-08-07)` — the doctor asserts *the jar executes*, not that a path exists. Measured earlier on the Ø31.87 mm puck: **11 unconnected → 0, 0 violations**, reproduced three times |
| **V6** | the parts database prices are current | **CLOSED, and the answer is FAIL.** V1 ran `ce-fab/bin/fab bom cost out/release/board/halo_rev_a-BOM.csv --qty 10,100,1000,10000 --live` at **2026-09-04T10:40Z**. Every line carries its endpoint URL and the second it was read. Verdict **FAIL at all four quantities**: `C1046539` shows **0 stock live on both jlcpcb.com and lcsc.com**, `C2827888` has 59 in stock against a need of 100. Transcript: `out/verify/bom-cost-live-2026-09-04.md`. The debt was "prices move" — they did, and the re-pull is the mechanism that says so |
| **V9** | *(new, opened and closed by V1)* the fabrication set can be read back | **CLOSED as a capability.** `tools/check_fabset.py` reads the exported Gerbers and drill files and grades twelve assertions against the source board. All **12 proved to fire** by `tools/prove_checks.py`. The pack it graded FAILS — see V2 |
| **V10** | *(new)* the BOM orders the parts the schematic asked for | **CLOSED as a capability.** `tools/check_bom_identity.py`, six assertions, all six proved to fire. The BOM it graded FAILS — see V13 |
| **V11** | *(new)* the convergence table's rows are derived from measurements | **CLOSED as a capability.** `tools/check_convergence.py`, seven assertions, all seven proved to fire. The table it graded FAILS — see V12 |
| **V18** | *(new)* the sounder study asserts the frequency it is named for | **CLOSED — the gap was found, fixed and the fix was proved.** `f_audio_Hz` was a cited constant in the title, the deck and every plot caption, and appeared in **zero** `measure()` expressions; sixteen assertions across four corners graded only amplitudes. Added `cespice/measure.py fundamental_of()` and one assertion. **Proved three ways:** driving the H-bridge at 7 kHz with the limits still at 3.5 kHz gives `f_coil_Hz FAIL 7000.02 not in [3395, 3605]` **while `i_coil_peak_mA`, `i_batt_avg_mA` and `efficiency_pct` all still PASS**; `F_AUDIO` at 350 Hz gives CANNOT DETERMINE with all four amplitude asserts still green; an all-zero and a constant waveform are both REFUSED with *"the signal is constant to within 0 peak-to-peak"*. Restored verdict **PASS**, `f_coil_Hz` = 3499.99 / 3500.00 / 3499.95 / 3499.99 Hz. `ce-spice` commit `aafbe4e8` |

**Proof that the new checks work:** `python3 tools/prove_checks.py` builds a
correct artifact, breaks exactly one thing, and requires the named assertion to
go red. **25 of 25 assertions fired**, plus the `ce-spice` frequency assertion
proved separately three ways — **26 of 26**. An assertion never seen to fail is
not known to work, so this harness is part of the deliverable and not an extra.

---

# 2 · HARDWARE REQUIRED

**These five cannot be closed on this machine at any effort. Each row below is
written so a bench engineer or a factory can close it the day a sample exists,
without asking us a question.** Every one names the equipment, the setup, the
sample count, and the number that counts as a pass.

Cross-reference: `docs/TEST-PLAN.md` §9 carries the production line's own
qualification table, `QUAL-01` … `QUAL-12`. **Where a debt below maps to a QUAL
id, that id is authoritative for the standard and the sample plan, and this page
is authoritative for what closes the debt.** They must not diverge; if you change
one, change the other in the same commit.

---

## V7 — the sounder reaches 60 Phon at 25 cm
**Maps to `TEST-PLAN.md` QUAL-04. Unlocks production test FU-03, which is
CANNOT DETERMINE until this is done.**

**Why it cannot be simulated.** Phon is a loudness *level* computed from a
measured spectrum under ISO 532-1:2017. It is not a sound-pressure level and it
is not dB(A). No circuit simulation produces it, because it depends on the
bonded bender, the shell's cavity, the port geometry and the room. `ce-spice`
models the *drive current* into the bender and nothing beyond the terminals.

**Load-bearing.** DULT §3.13.3 makes 60 Phon mandatory for an accessory that can
be separated from its owner. `docs/ANTI-STALKING.md` §4.1 and `research/06`
constraint C8 carry the requirement. The only published AirTag figure lane G
could find is **78–80 dB at about 13 cm**, which is a different quantity at a
different distance and cannot be converted.

**Equipment**
- Class 1 sound level meter or measurement microphone with a **calibrated free-field response**, e.g. a ½″ prepolarised condenser capsule with a Class 1 preamplifier.
- An **ISO 532-1:2017 loudness analyser** — Zwicker method, time-varying. A meter that reports only dB(A) cannot close this row. Software implementations are acceptable if the implementation names ISO 532-1:2017 and its version.
- Acoustic calibrator, 94 dB at 1 kHz, with a calibration certificate inside its stated interval.
- A room or chamber whose background is **at least 10 dB below the lowest one-third-octave band of the measurement**, measured, not assumed.
- Fixture `FX-5` from `TEST-PLAN.md` §4 for the production correlation step.

**Setup**
1. Calibrate the microphone with the acoustic calibrator immediately before and immediately after the session. **If the two readings differ by more than 0.3 dB, the session is void.**
2. Mount the sealed unit with its sounder port facing the microphone, on axis, with the acoustic centre of the capsule **250 ± 5 mm** from the outer face of the shell. Support the unit on a low-reflection mount, not on a bench top.
3. Record the background spectrum with the unit present but silent. Record it in one-third-octave bands.
4. Command the sounder over GATT exactly as `TEST-PLAN.md` FU-04 does, with the unit on its own cell and no wires. **The cell must be a fresh cell of the shipped brand and lot** — a bench supply changes the result, because the sounder's output tracks the rail under the piezo's reactive load.
5. Capture at least **10 s** of the sounding pattern, including its silent gaps. ISO 532-1 time-varying loudness returns a percentile; take **N5** (the level exceeded 5 % of the time), and state that you did.

**Sample size.** **At least 5 golden units**, per QUAL-04, so the golden reading
is a mean and not one unit's luck. Report the mean and the sample standard
deviation. If the standard deviation exceeds 3 phon, the bond process is not
under control and the mean is not yet a golden number.

**Pass**
- **N5 loudness ≥ 60 phon**, computed under ISO 532-1:2017, at 250 mm on axis, on the mean of ≥ 5 units, **and** the weakest single unit ≥ 57 phon.
- Background ≥ 10 dB below the measurement in every contributing band, stated as a number.
- Both calibrator readings within 0.3 dB of each other.

**What it also produces, and must not be skipped.** In the same session, record
the **A-weighted SPL at 25 cm** for each unit. That number, minus a tolerance
from a gauge R&R study on `FX-5`'s hood and meter, becomes FU-03's production
limit. **Nobody may write 60 into a dB(A) cell.** `TEST-PLAN.md` line 469 says
so and this page agrees: they are different quantities and swapping them is
exactly the error `docs/TOOLS-THAT-LIE.md` exists to stop.

---

## V5 — the firmware advertises correctly, on a real radio
**Related to `TEST-PLAN.md` AB-11 (production) and QUAL-05 (certification), but
this debt is neither: it is the first proof that our silicon transmits at all.**

**Where it stands.** Proven **in emulation only**. `ce-fwsim` verifies the Find
My advertisement field by field against SPEC F1 from the emulated firmware's
UART log. Lane V1's audit found the specific limit of that proof: the checks
read a printed log line, and **nothing reads the radio's own `ready=` / `end=` /
`disabled=` fields**, so a firmware whose `radio_tx()` returns without the RADIO
peripheral raising a single event still passes. No electromagnetic wave has
existed.

**Equipment**
- 1 assembled halo board on its own CR2032, in its carrier (station-2 state), plus 1 sealed unit.
- A BLE 5 sniffer that reports the **raw PDU**, not a decoded name: nRF Sniffer for Bluetooth LE on an nRF52840 dongle with Wireshark, or a Ellisys/Frontline analyser. A phone app is not acceptable — it cannot show you the bytes.
- An RF-quiet enclosure (`FX-3`) with a **leakage self-test**: with a powered halo 300 mm *outside* the closed box, the in-box scanner must see **zero** of its advertisements in a 20 s capture. Run it at the start of every session. A box that fails invalidates every capture since the last pass.
- An iPhone or iPad on a current iOS with Find My enabled, and a second one signed into a different Apple ID, for the location-report half.
- The unit's provisioned private key, on the programming station only. **It must not leave that station**; record the SHA-256 fingerprint of the public key instead (`TEST-PLAN.md` line 190).

**Setup — part A, the advertisement exists on air**
1. Run the box leakage self-test. Record the result with the timestamp.
2. Power the unit on its own cell. Capture **20 s** of advertising channels 37, 38 and 39.
3. Export the raw PDUs. For each captured advertisement, check the 31 bytes against `ce-fwsim/tools/findmy_decode.py`'s field list: `len=0x1e`, `type=0xff`, company `4c 00`, Apple type `0x12`, OF length `0x19`, key bytes at `[7:29]`, key high bits at `[29]`, hint `[30]=0x00`.
4. **Derive the advertised key independently**: recover it from the captured bytes plus the captured advertising address, and compare its SHA-256 to the fingerprint recorded at programming. This is the step emulation cannot do, because in emulation the key on the wire and the key in the log come from the same process.
5. Leave the unit running and capture again after **> 15 minutes** to observe a key rotation on air.

**Setup — part B, a location report comes back**
6. Take the unit **out of the box**, at least 200 m from the owner phone, in a place with other iPhones passing.
7. Wait for the separated state and its DULT advertising, then query Apple's Find My network for reports against the day's derived hashed public keys.
8. A report is closed when a decrypted location, its timestamp and its accuracy come back and the timestamp is **after** the unit was placed.

**Sample size.** **3 units** for part A. **1 unit** for part B, repeated on **3
separate days**, because the network's reporting density is not under our
control and one silent day is not evidence of a broken tag.

**Pass**
- Part A: **≥ 5 advertisements decoded per channel in 20 s**, all 31 bytes matching SPEC F1, and the recovered key's SHA-256 equal to the programming fingerprint — on 3 of 3 units.
- Part A rotation: the key on air at t+15 min **differs** from the key at t=0, and both are members of the sequence `ce-fwsim/tools/rollkey_ref.py` derives from the master beacon key read out of the ELF image.
- Part B: **at least one decrypted location report** whose timestamp falls inside the separation window, on **2 of 3 days**. One report is the whole claim; the second day exists to distinguish a working tag from a lucky one.
- **FAIL, explicitly, if any advertisement is seen but no report ever comes back** — that is a payload that is well-formed and useless, and it is the outcome this debt exists to catch.

---

## V8 — Channel Sounding reaches 6–20 cm between two halos
**Maps to `TEST-PLAN.md` QUAL-10. SPEC §2 F10.**

**Where it stands.** The 6–10 cm figure is from a **published study on other
hardware** (nRF54L15 development kits), not on ours. `DECISIONS.md` D12 carries
the known gap in the open: Channel Sounding degrades from 25 cm to **331 cm**
when channels collide without deterministic scheduling, and a single-antenna
device can lose metres to orientation.

**Equipment**
- **8 halo units**, per QUAL-10 — the same configuration as the published study, so ours is comparable to theirs.
- A room with at least **10 m** of clear line of sight and no metal within 1 m of the path.
- A **measured** ground-truth baseline: a laser distance meter with a stated accuracy of ≤ 1 mm, or a surveyed tape. Chalk marks on a floor are not a baseline.
- Non-metallic stands that place each unit at **1.0 m** height, and a rotation stage or a marked protractor for the orientation sweep.

**Setup**
1. Place unit A at the origin. Place unit B at each of **9 true distances**: 0.25, 0.5, 1, 2, 3, 5, 7, 8.5 and 10 m, each measured with the laser and recorded to the millimetre.
2. At each distance, take **30 ranging estimates** at the shipped 30 s update rate, over ≥ 15 minutes.
3. Repeat the whole sweep at **4 relative orientations** of unit B: 0°, 90°, 180°, 270° about its vertical axis. Orientation is the failure mode D12 names; a sweep at one orientation measures the best case and calls it the answer.
4. Repeat the whole sweep **once with a second pair of units in the room ranging simultaneously**, to reproduce the channel-collision case. Record whether the firmware schedules deterministically.
5. Record every estimate, not a mean — the distribution is the result.

**Sample size.** 8 units → **4 independent pairs**. 9 distances × 4 orientations
× 30 estimates × 4 pairs = **4 320 estimates**. Anything less does not separate a
median from a tail.

**Pass**
- **Mean absolute error ≤ 20 cm** across all distances ≤ 10 m, at every orientation, with no single pair worse than 30 cm.
- **95th-percentile absolute error ≤ 50 cm.** The mean alone hides the failure D12 warns about.
- The collision run is reported **as its own number** and is not averaged into the clean one. If it exceeds 1 m, that is a finding about scheduling and it goes to DECISIONS.md — **do not widen this row's limit to absorb it.**
- FAIL if fewer than 90 % of scheduled ranging attempts return an estimate at all: a tag that ranges accurately when it answers and answers half the time has not passed.

---
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

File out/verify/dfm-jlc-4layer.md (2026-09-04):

# DFM — halo_rev_a.kicad_pcb against `jlc-4layer`

**FAIL** — 26 PASS, 2 FAIL, 0 CANNOT DETERMINE, of the PASSes 3 VACUOUS (the board carries no item the rule governs — satisfied, not covered). Generated 2026-09-04T22:06:53Z.

*Rule set: JLCPCB 4-layer FR4, 1 oz outer / 0.5 oz inner — published capability limits*

Board: 25.6138 x 26.0 mm, 4 copper layers, 0.6 mm, 62 footprints, 49 vias, 255 track segments.

> **81 unconnected item(s)** — the ratsnest. Not a fab-capability failure and not counted above, but this board is not finished.

> Netclass `Default` was **replaced** for this run: clearance=0.127, track_width=0.127, via_diameter=0.45, via_drill=0.25 -> clearance=0.09, track_width=0.09, via_diameter=0.25, via_drill=0.15. KiCad enforces the NETCLASS clearance, not the board setup floor, so a run against the designer's own netclass measures the designer's preference and not the fab's limit.
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

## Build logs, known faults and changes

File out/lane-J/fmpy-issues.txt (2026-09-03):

########## FindMy.py #222 ##########
TITLE: Does the iOS update have an impact on location reporting for custom tag devices?
STATE:open CREATED:2026-01-28T02:39:03Z CLOSED:null USER:@VoidMore
--BODY--
For custom Tags, have the latest iOS versions affected the location reporting of such devices?
My phone is an iPhone 17 with iOS 26.2.1.
Currently, my device is broadcasting and has been right beside me, but it only updates its location sporadically—unless I go to a crowded area.
Is my device not reporting? It should definitely receive broadcast packets at such a close range.
  [2026-01-28T11:31:24Z] @malmeloo: Apple devices do not upload every report they receive. Specifically, they tend to ignore duplicate reports from the same tag, and since (most) custom tags don't change their identity, the iPhone is probably ignoring it. Is the behavior you're seeing a recent development?
  [2026-01-29T08:50:51Z] @VoidMore: Yes, so I tested a single key pair and a derived key pair. The derived ones have slightly more reports. Maybe the derived key pairs will have new tags for broadcasting, which can obfuscate the reporting mechanism of the iPhone, right?

  [2026-01-29T08:51:49Z] @VoidMore: Are there any interfaces or behaviors that can be actively triggered and reported to Apple

  [2026-02-05T09:55:07Z] @VoidMore: > Apple devices do not upload every report they receive. Specifically, they tend to ignore duplicate reports from the same tag, and since (most) custom tags don't change their identity, the iPhone is probably ignoring it. Is the behavior you're seeing a recent development?苹果设备不会上传收到的所有报告。具体来说，它们通常会忽略来自同一标签的重复报告，而且由于（大多数）自定义标签的身份不会改变，iPhone 很可能忽略了这些重复报告。您遇到的这种情况是最近才出现的吗？

What is the identity of this custom tag, can I use this as a breakthrough?
  [2026-02-05T15:08:03Z] @malmeloo: I'm not exactly sure what you mean? But if you want to bypass that device behaviour you need to make sure that your tag rotates its keypair every so often, to appear to your iphone as a new tag. It's got nothing to do with obfuscation, just how the protocol works.

You can also just assume that no reports = no movement, if your tag gets stolen or lost around other people it will start generating more reports.
  [2026-02-06T11:53:54Z] @VoidMore: Can a higher rotation frequency increase the trigger reporting
  [2026-02-06T12:36:23Z] @malmeloo: Maybe, but that so increases the number of keys you need to fetch just to get a location. There's not really a point in increasing it too much.
  [2026-02-09T02:16:30Z] @VoidMore: > Maybe, but that so increases the number of keys you need to fetch just to get a location. There's not really a point in increasing it too much.

It's really frustrating. The custom Tag that has always been by my side no longer has location data, even though it has been broadcasting all along
  [2026-02-11T13:44:30Z] @malmeloo: Do you get more reports when changing the tag's identity / public key or not? This part of the network is mostly a 'black box' and not much can be done about it if it doesn't work. Apple cannot really change the BLE payload easily, but they have introduced bugs in the past that caused tags not to be reported (including official airtags).

########## FindMy.py #227 ##########
TITLE: unable to get report anymore after Feb 10, 2026
STATE:closed CREATED:2026-02-14T08:59:40Z CLOSED:2026-02-18T19:35:45Z USER:@RobinWei-dct
--BODY--

   File "/home/ubuntu/.local/lib/python3.12/site-packages/findmy/reports/account.py", line 788, in fetch_location
     hist = await self.fetch_location_history(keys)
            ^^^^^^^^^^^^^^^^^^^^^^^^^^^^^^^^^^^^^^^
   File "/home/ubuntu/.local/lib/python3.12/site-packages/findmy/reports/account.py", line 755, in fetch_location_history
     return await self._reports.fetch_location_history(keys)
            ^^^^^^^^^^^^^^^^^^^^^^^^^^^^^^^^^^^^^^^^^^^^^^^^
   File "/home/ubuntu/.local/lib/python3.12/site-packages/findmy/reports/reports.py", line 386, in fetch_location_history
     key_reports = await self._fetch_key_reports([device])
                   ^^^^^^^^^^^^^^^^^^^^^^^^^^^^^^^^^^^^^^^
   File "/home/ubuntu/.local/lib/python3.12/site-packages/findmy/reports/reports.py", line 521, in _fetch_key_reports
     encrypted_reports: list[LocationReport] = await self._account.fetch_raw_reports(ids)
                                               ^^^^^^^^^^^^^^^^^^^^^^^^^^^^^^^^^^^^^^^^^^
   File "/home/ubuntu/.local/lib/python3.12/site-packages/findmy/reports/account.py", line 712, in fetch_raw_reports
     raise UnhandledProtocolError(msg)
 findmy.errors.UnhandledProtocolError: Failed to fetch reports: None
  [2026-02-14T20:05:24Z] @malmeloo: I cannot personally reproduce this, does it happen sporadically or all the time? Can you share logs up until that point?

Try removing your account.json and signing in again
  [2026-02-16T00:26:35Z] @RobinWei-dct: Full log with new account.json. These days it happens all the time.
========================
Traceback (most recent call last):
  File "/Users/rb/Documents/findme/FindMy.py/examples/fetch_reports.py", line 63, in <module>
    sys.exit(fetch_reports(sys.argv[1]))
  File "/Users/rb/Documents/findme/FindMy.py/examples/fetch_reports.py", line 35, in fetch_reports
    location = acc.fetch_location(key)
  File "/Library/Frameworks/Python.framework/Versions/3.10/lib/python3.10/site-packages/findmy/reports/account.py", line 1191, in fetch_location
    hist = self.fetch_location_history(keys)
  File "/Library/Frameworks/Python.framework/Versions/3.10/lib/python3.10/site-packages/findmy/reports/account.py", line 1159, in fetch_location_history
    return self._evt_loop.run_until_complete(coro)
  File "/Library/Frameworks/Python.framework/Versions/3.10/lib/python3.10/asyncio/base_events.py", line 646, in run_until_complete
    return future.result()
  File "/Library/Frameworks/Python.framework/Versions/3.10/lib/python3.10/site-packages/findmy/reports/account.py", line 755, in fetch_location_history
    return await self._reports.fetch_location_history(keys)
  File "/Library/Frameworks/Python.framework/Versions/3.10/lib/python3.10/site-packages/findmy/reports/reports.py", line 386, in fetch_location_history
    key_reports = await self._fetch_key_reports([device])
  File "/Library/Frameworks/Python.framework/Versions/3.10/lib/python3.10/site-packages/findmy/reports/reports.py", line 521, in _fetch_key_reports
    encrypted_reports: list[LocationReport] = await self._account.fetch_raw_reports(ids)
  File "/Library/Frameworks/Python.framework/Versions/3.10/lib/python3.10/site-packages/findmy/reports/account.py", line 712, in fetch_raw_reports
    raise UnhandledProtocolError(msg)
findmy.errors.UnhandledProtocolError: Failed to fetch reports: None

  [2026-02-16T00:30:11Z] @RobinWei-dct: from line 690, file account.py, findmy v0.9.8, the r.status_code is 500 shown at line 706

 690 r = await _do_request()
 691         if r.status_code == 401:
 692             logger.info("Got 401 while fetching reports, redoing login")
 693 
 694             new_state = await self._gsa_authenticate()
 695             if new_state != LoginState.AUTHENTICATED:
 696                 msg = f"Unexpected login state after reauth: {new_state}. Please log in again."
 697                 raise UnauthorizedError(msg)
 698             await self._login_mobileme()
 699 
 700             r = await _do_request()
 701 
 702         if r.status_code == 401:
 703             msg = "Not authorized to fetch reports."
 704             raise UnauthorizedError(msg)
 705 
 706         logger.info("Response status: %s, ", r.status_code )

log:
===
Logged in as: xx (xx xx)
WARNING:findmy.reports.account:Empty response received when fetching reports, retrying in 2 seconds (1/5)
INFO:findmy.reports.account:Response status: 500, 
INFO:findmy.reports.account:resp:{}
Traceback (most recent call last):
  File "/Users/robin.wei/Documents/findme/FindMy.py/examples/fetch_reports_async.py", line 86, in <module>
    asyncio.run(fetch_reports(sys.argv[1]))
  File "/Library/Frameworks/Python.framework/Versions/3.10/lib/python3.10/asyncio/runners.py", line 44, in run
    return loop.run_until_complete(main)
  File "/Library/Frameworks/Python.framework/Versions/3.10/lib/python3.10/asyncio/base_events.py", line 646, in run_until_complete
    return future.result()
  File "/Users/robin.wei/Documents/findme/FindMy.py/examples/fetch_reports_async.py", line 37, in fetch_reports
    location = await acc.fetch_location(key)
  File "/Library/Frameworks/Python.framework/Versions/3.10/lib/python3.10/site-packages/findmy/reports/account.py", line 791, in fetch_location
    hist = await self.fetch_location_history(keys)
  File "/Library/Frameworks/Python.framework/Versions/3.10/lib/python3.10/site-packages/findmy/reports/account.py", line 758, in fetch_location_history
    return await self._reports.fetch_location_history(keys)
  File "/Library/Frameworks/Python.framework/Versions/3.10/lib/python3.10/site-packages/findmy/reports/reports.py", line 386, in fetch_location_history
    key_reports = await self._fetch_key_reports([device])
  File "/Library/Frameworks/Python.framework/Versions/3.10/lib/python3.10/site-packages/findmy/reports/reports.py", line 521, in _fetch_key_reports
    encrypted_reports: list[LocationReport] = await self._account.fetch_raw_reports(ids)
  File "/Library/Frameworks/Python.framework/Versions/3.10/lib/python3.10/site-packages/findmy/reports/account.py", line 715, in fetch_raw_reports
    raise UnhandledProtocolError(msg)
findmy.errors.UnhandledProtocolError: Failed to fetch reports: None

  [2026-02-17T12:35:47Z] @RobinWei-dct: Is there any chance to look into this issue? I can provide more log for further debug. Thanks.
  [2026-02-18T00:19:12Z] @malmeloo: Sorry for the late response, I've been quite busy recently. I just spent some time trying to look into this issue from my side but cannot find the problem. It doesn't seem to happen for me, and since we're working with undocumented APIs, these kinds of issues are notoriously difficult to debug.

What you can try to further debug this issue is to put a `print(r.text())` at line 705 in `/Library/Frameworks/Python.framework/Versions/3.10/lib/python3.10/site-packages/findmy/reports/account.py`, to capture the actual content of the HTTP response. I expect it to be empty, but maybe there is some information in there.

For some reason, Apple seems to be testing changes to their FindMy API in production quite often. Sometimes things just break, and in the worst case it can take months for a fix to be rolled out. Just recently they broke authentication for a few days (#225) and then it randomly started working again. A while ago they completely broke location reporting on newer iOS versions (that also affected official AirTags) that tooks months to fix. And for a few months now we've been running into this issue where the API sometimes does not return any results at all, and the library needs to internally retry the request. This one, too, is impacting official Apple devices, but for one reason or the other, Apple either does not care or does not know about the issue.

My best guess at this point is that one or more of their servers are faulty, and their load balancer is making you hit those faulty servers due to geographical proximity. What you can try to do (if you are able to) is to run the script from a different IP address, preferably far away from where you are currently running it. Or try a different account.
  [2026-02-18T02:52:47Z] @RobinWei-dct: Yes, you are right. With nothing changed, today the inquiry returned a status code of 200. 
Thank you. Cool!
=============
INFO:findmy.reports.account:Response status: 200, 
INFO:findmy.reports.account:resp:{'configVersion': 1, 'acsnLocations': {'locationPayload': [], 'configVersion': 1, 'statusCode': '200'}, 'ownedDeviceLocations': {'locationPayload': [], 'configVersion': 0, 'statusCode': '200'}}
Last known location:
 - None

  [2026-02-18T19:35:45Z] @malmeloo: Good to know! I'll close this issue for now then, but if you run into it again feel free to reopen.

########## FindMy.py #231 ##########
TITLE: Strange Behavior with findmyservice/v2/fetch
STATE:closed CREATED:2026-03-09T11:11:02Z CLOSED:2026-03-10T14:21:03Z USER:@MarcoGhise
--BODY--
**Describe the behavior**

I'm experiencing inconsistent responses when calling the findmyservice/v2/fetch endpoint. The behavior appears random even when sending identical requests.

**Steps to reproduce**

Call the findmyservice/v2/fetch endpoint.
Use the same payload for each request.
Send multiple requests with a ~5 second delay between them.

**Actual behavior**
From a sample of 5 HTTP requests for the same resource, I received the following responses:

1. Attempt → HTTP 200 with empty body
2. Attempt → HTTP 401
3. Attempt → HTTP 200 with empty body
4. Attempt → HTTP 200 with empty body
5. Attempt → HTTP 401

The endpoint response changes frequently without any apparent pattern. Sometimes the request is unauthorized (401), while other times it succeeds but returns an empty body with no report content.

**Expected behavior**

I would expect consistent behavior when sending identical requests (e.g., always 200 with data, or consistently 401 if authentication is invalid).

**Questions**

Could this be caused by auth.json expiring?

Is it necessary to re-pair the iPhone and the tag?

Has anyone else experienced this behavior?

Thanks!
  [2026-03-09T12:06:02Z] @malmeloo: Just to confirm, you are making the request yourself rather than through FindMy.py?

There is an issue with Apple's API that causes the empty 200 responses. There's an issue about it here: https://github.com/malmeloo/FindMy.py/issues/185

If you *are* using FindMy.py, try removing the account.json file and signing in again. If not, there is some other authentication issue going on.
  [2026-03-09T13:11:47Z] @MarcoGhise: Thanks @malmeloo for the quick response.

I ported your Python solution to Java, basically using the same approach and adding a retry policy (5 attempts with a 5-second delay).

What surprised me was the different responses I received from Apple even though the payload was always the same. I expected to receive consistent responses for identical requests.

Sometimes — which is quite surprising — I'm even able to retrieve all reports using the same payload simply by changing the time window.

Do you think it’s possible that the API only returns reports for the time windows in which Apple actually received location updates from the AirTag, and otherwise returns inconsistent or seemingly random responses?

Thanks again for your suggestion — I’ll apply it as soon as possible.
  [2026-03-09T13:19:15Z] @malmeloo: I would recommend fixing the time window to the last 7-14 days (I forgot which one I used) and not making it user configurable. Then in your library you can filter out the reports outside of your desired time window. Apple's API does not check the time values properly and it is essentially broken, so that could explain some of your issues.

What do you consider as 'random' responses? Do you get garbage data or simply fewer results than what you asked for? It's no longer possible to obtain very old historical data - there is a limit on how many reports are now stored server-side - but it should still be chronological.

As for those 401 errors, I can't tell for certain what would cause them as it depends on your implementation. Maybe it's related to the time parameters, the response codes are not actually very useful to determine what's going on.
  [2026-03-09T13:59:17Z] @MarcoGhise: Honestly, I'm only interested in the results from the last hour. I run my script every 60 minutes, so I only need a small snapshot of data.

This morning the script ran as usual and I was able to receive data from Apple.

By "random response", I mean getting different HTTP status codes across 5 attempts within less than 30 seconds. I agree with you that the HTTP status code alone is probably not enough to fully understand what is happening.

If you agree, I’d like to keep this issue open until I update my account.json and check the solution.

Thanks again for your support.
  [2026-03-09T15:07:30Z] @malmeloo: Sure, feel free to keep the issue open. Let me know if it fixes your problem or not.

Something that could be interesting to look into: OpenTagViewer is an android app that uses FindMy.py to fetch locations. I'm not sure how it works exactly, but the author mentioned using some kind of FFI to use FindMy.py from either Java or Kotlin (I forgot the exact details). Depending on what your goals are that could be a good alternative to reimplementing the entire library from scratch.
  [2026-03-10T14:21:04Z] @MarcoGhise: Renewing the authentication it came back to work!
A take away of all this issue is not rely on HTTP response status, they're quite confused..

Thanks again for your support

  [2026-03-10T17:52:34Z] @malmeloo: No problem, nice to hear you got it working!

########## FindMy.py #264 ##########
TITLE: AirTag location reports stop updating while Find My app shows recent location
STATE:closed CREATED:2026-08-27T00:54:17Z CLOSED:2026-08-27T15:36:24Z USER:@ViceEye
--BODY--
I am using FindMy.py to track an official Apple AirTag.

The AirTag accessory JSON was exported successfully from macOS Sonoma 14 using:

```bash
python3 -m findmy decrypt --out-dir devices/
```

I then moved the accessory JSON to Windows and use `AppleAccount.fetch_location()` / `fetch_location_history()` to query the AirTag.

The first fetch worked and returned valid location reports, but subsequent fetches appear to stop progressing.

At the same time, the Find My app on my iPhone shows a much more recent location.

For example:

- iPhone Find My app: location updated about **3 minutes ago**
- FindMy.py latest report: about **3 hours 30 minutes old**

Example output:

```text
LATEST_REPORT
============================================================
REPORT_TIMESTAMP = 2026-08-26T20:39:40+00:00
FETCH_TIMESTAMP  = 2026-08-27T00:12:17+00:00
REPORT_AGE_SEC   = 12757
REPORT_AGE_MIN   = 212.6
LAT              = [redacted]
LON              = [redacted]
STATUS           = 16
BATTERY          = Full
ACCURACY         = 42
CONFIDENCE       = 8

RESULT           = NO_NEW_REPORT
```

I also tested `fetch_location_history()`.

It returned 8 reports, all clustered between approximately:

```text
2026-08-26T20:36:20+00:00
```

and:

```text
2026-08-26T20:39:40+00:00
```

No newer reports were returned, even though the Find My app showed a location from only a few minutes earlier.

### Accessory state persistence

I am saving the accessory state after every fetch:

```python
accessory.to_json(...)
```

In my actual code I save it atomically:

```python
def save_json_atomic(value, path):
    temporary = path.with_suffix(path.suffix + ".tmp")
    value.to_json(temporary)
    os.replace(temporary, path)
```

and this is called in `finally`, so it runs after successful fetches, `NO_REPORT`, and duplicate reports.

However, I compared the accessory JSON before and after multiple fetches and it remains exactly the same.

In particular, it appears that `alignment_date` / `alignment_index` are not being updated after these fetches.

### Minimal fetch logic

The relevant code is essentially:

```python
account = AppleAccount.from_json(
    account_path,
    anisette_libs_path=anisette_path,
)

accessory = FindMyAccessory.from_json(device_path)

report = account.fetch_location(accessory)

accessory.to_json(device_path)
account.to_json(account_path)
```

I also tried:

```python
reports = account.fetch_location_history(accessory)
```

but the newest report is still the same old report.

### Environment

- FindMy.py: **0.10.1**
- Host OS: Windows
- Python: **3.14**
- AirTag accessory JSON exported from: **macOS Sonoma 14**
- Device type: official Apple AirTag

`pip show findmy`:

```text
Name: FindMy
Version: 0.10.1
Location: C:\Users\<user>\AppData\Roaming\Python\Python314\site-packages
```

### Expected behavior

Since the official Find My app shows a recent AirTag location, I expected `fetch_location()` to eventually return a similarly recent Find My Network report.

I also expected the accessory alignment state to advance if newer reports were successfully discovered.

### Actual behavior

FindMy.py repeatedly returns the same old latest report, while the official Find My app continues showing much newer locations.

The AirTag itself is still active and nearby Apple devices are clearly reporting it, because the official Find My app continues to update normally.

The accessory JSON also does not change after repeated fetches.

### Questions

Could this indicate:

1. incorrect/stale rolling-key alignment,
2. a case where newer reports exist but the generated rolling keys do not match them,
3. a difference between what the Find My app can access and what `/findmyservice/v2/fetch` exposes,
4. or a regression / edge case in AirTag alignment handling?

I can provide sanitized debug logs or additional output if useful.

Thanks!
  [2026-08-27T15:51:35Z] @malmeloo: Did you get this resolved? If the AirTag is physically close to one of its owner devices, it cannot be tracked through the FindMy network. I'm guessing this is what you were running in to?
  [2026-08-27T20:36:29Z] @ViceEye: > Did you get this resolved? If the AirTag is physically close to one of its owner devices, it cannot be tracked through the FindMy network. I'm guessing this is what you were running in to?

Yes, you are right, I let my cat out and while he is running around, I am able to pick up updates
  [2026-08-27T20:47:18Z] @malmeloo: Ah, yeah that's a FindMy network limitation unfortunately. You can still use the bluetooth scanner to find out if the tag is close to you or not.

########## FindMy.py #197 ##########
TITLE: Issues with Data Acquisition for Rolling Key Pairs
STATE:closed CREATED:2025-10-22T07:01:20Z CLOSED:2025-11-11T21:37:51Z USER:@VoidMore
--BODY--
I am currently broadcasting using the method of rolling key pairs. However, in this case, many key pairs have almost no data associated with them, and then they roll over to the next one when the time is up. This situation is quite inconvenient/frustrating.

Could it be that due to some adjustment made by Apple, the surrounding iPhone devices are not reporting such key pairs?
  [2025-10-22T09:42:59Z] @malmeloo: Can you explain your scenario a bit more? Are you using DIY tags with rolling keys? What do you mean they have no data associated?
  [2025-10-23T02:02:26Z] @VoidMore: My scenario is that I rotate the key pair every 5 minutes, and I keep broadcasting this key pair within these five minutes, but the data obtained is not satisfactory.

Most of the rolling key pairs cannot obtain data. What do you mean by the DIY tag? Could you please elaborate on it? Are some broadcast packets with custom content not recognized by Apple's servers?
  [2025-10-24T18:20:42Z] @malmeloo: So how are you generating the keys? Do you have a pool of keys that you are choosing from to broadcast or is it some kind of generator?

With DIY tag I mean a custom one. If your payload is correct Apple shouldn't be able to block your keys. But I can't comment on your specific situation because I don't know how you're generating keys, what firmware you're using, how you're querying them, etc. Especially because you appear to be using some kind of custom solution.

This is a wild guess, but 5 minutes is a very short rotation period. If you are getting reports for some keys but not for others, I wouldn't be surprised if the period is simply too short. Try increasing it to 15 - 60 minutes.

  [2025-10-25T01:46:22Z] @VoidMore: I also use the same elliptic curve algorithm as the current project for generation, followed by rolling using KDF (Key Derivation Function). It is feasible to obtain data, but it is not possible to have data for every rolled key pair. Moreover, some key pairs do not have data available during their respective broadcast time windows; instead, there is a delay of 10 to 30 minutes before the data can be retrieved.

My firmware is custom-developed rather than a generic one. For the query scheme, I have tried both the old version and the new V2 version, but there is no difference in their performance.
  [2025-10-25T01:52:40Z] @VoidMore: If I want to achieve a good result where every rolling key pair can obtain positioning data, are there any firmware configurations that have performed well in tests? This is because the firmware was custom-developed for me by a friend.
  [2025-10-25T09:12:32Z] @malmeloo: I'm afraid there is no way to enforce that each keypair comes back with data. If no iPhone nearby picks up on the tag for 5 minutes, the keypair will not have any location reports. This is an issue with official tags as well.

What do you mean with query scheme exactly?
  [2025-11-03T07:57:40Z] @VoidMore: The query solution refers to using the old version of the API and the new version of the API to obtain data and return the same content.

I'm not sure if it's because broadcast packets from custom firmware are not accepted by Apple services.
  [2025-11-03T09:49:23Z] @VoidMore: I'm currently testing whether each rolling key pair receives data using a single device, because it seems to the device that the rolling key pairs are all new.

In my situation, can I be sure that my phone will receive and upload the data to Apple's servers? The device is always next to my phone.
  [2025-11-03T16:59:06Z] @malmeloo: Ah okay, thanks for clarifying. Apple doesn't care about what firmware you are using - as long as the bluetooth LE payload is correct, devices will accept it.

There is no way to ensure that Apple devices will upload each and every report originating from the keys of your device. It's up to Apple if and when they upload data. Usually devices will wait a bit before uploading reports, but they might also not upload any reports at all.

If you're getting reports for at least some of the keys generated by your device, the system works as intended.

  [2025-11-04T01:37:29Z] @VoidMore: Thank you for your answer! I was trying to see if this method would allow for more real-time data processing. I'm currently testing with one phone and one device. The device uses rolling key pairs. Will the phone receive and report each key pair?
  [2025-11-04T19:06:59Z] @malmeloo: It may or may not report each keypair, that's up to Apple. But you definitely can't rely on it reporting every single one.
  [2025-11-05T03:35:38Z] @VoidMore: Thank you for your answer. Thank you for your contribution to this research. That's fantastic!
  [2025-11-11T21:37:51Z] @malmeloo: Closing as answered, feel free to reach out if you have further questions

########## FindMy.py #185 ##########
TITLE: UnhandledProtocolError: Failed to fetch reports: None
STATE:open CREATED:2025-09-29T20:45:15Z CLOSED:null USER:@malmeloo
--BODY--
As of recently, you may occasionally run into the following error:

```
Traceback (most recent call last):
  File "/home/mike/Projects/FindMy.py/examples/airtag.py", line 61, in <module>
    sys.exit(main(args.airtag_path))
             ~~~~^^^^^^^^^^^^^^^^^^
  File "/home/mike/Projects/FindMy.py/examples/airtag.py", line 43, in main
    location = acc.fetch_location(airtag)
  File "/home/mike/Projects/FindMy.py/findmy/reports/account.py", line 1171, in fetch_location
    hist = self.fetch_location_history(keys)
  File "/home/mike/Projects/FindMy.py/findmy/reports/account.py", line 1139, in fetch_location_history
    return self._evt_loop.run_until_complete(coro)
           ~~~~~~~~~~~~~~~~~~~~~~~~~~~~~~~~~^^^^^^
  File "/home/mike/.local/share/uv/python/cpython-3.13.2-linux-x86_64-gnu/lib/python3.13/asyncio/base_events.py", line 725, in run_until_complete
    return future.result()
           ~~~~~~~~~~~~~^^
  File "/home/mike/Projects/FindMy.py/findmy/reports/account.py", line 735, in fetch_location_history
    return await self._reports.fetch_location_history(keys)
           ^^^^^^^^^^^^^^^^^^^^^^^^^^^^^^^^^^^^^^^^^^^^^^^^
  File "/home/mike/Projects/FindMy.py/findmy/reports/reports.py", line 387, in fetch_location_history
    return await self._fetch_accessory_reports(device, only_latest=True)
           ^^^^^^^^^^^^^^^^^^^^^^^^^^^^^^^^^^^^^^^^^^^^^^^^^^^^^^^^^^^^^
  File "/home/mike/Projects/FindMy.py/findmy/reports/reports.py", line 481, in _fetch_accessory_reports
    ret |= await _fetch()
           ^^^^^^^^^^^^^^
  File "/home/mike/Projects/FindMy.py/findmy/reports/reports.py", line 440, in _fetch
    new_reports: list[LocationReport] = await self._account.fetch_raw_reports(
                                        ^^^^^^^^^^^^^^^^^^^^^^^^^^^^^^^^^^^^^^
        [(list(cur_keys_primary), (list(cur_keys_secondary)))]
        ^^^^^^^^^^^^^^^^^^^^^^^^^^^^^^^^^^^^^^^^^^^^^^^^^^^^^^
    )
    ^
  File "/home/mike/Projects/FindMy.py/findmy/reports/account.py", line 692, in fetch_raw_reports
    raise UnhandledProtocolError(msg)
findmy.errors.UnhandledProtocolError: Failed to fetch reports: None
```

This appears to be caused by a change on Apple's side. As of v0.9.3, FindMy.py will automatically re-fire the request if it detects this error. However, this is very much a band-aid fix; the real underlying issue has not been identified yet.
  [2025-09-29T20:55:48Z] @malmeloo: The FindMy app on MacOS also appears to be receiving empty responses, so it's most likely an issue on Apple's side.
  [2025-09-30T01:06:08Z] @lovelyelfpop: Same problem https://github.com/dchristl/macless-haystack/issues/219 and https://github.com/biemster/FindMy/issues/88

########## FindMy.py #183 ##########
TITLE: Last known location: None
STATE:closed CREATED:2025-09-26T07:35:16Z CLOSED:2025-11-11T17:23:36Z USER:@varac
--BODY--
Hi ! I'm testing FindMy.py with a new air tag paired yesterday, 
I successfully got the device information json, and use the unmodifies, latest `examples/airtag.py` script to fetch location data, but I get `None` as location:

```sh 
python3 ./examples/airtag.py accessories/7D….json
Logged in as: xxx
INFO:findmy.reports.reports:Fetched 0 new reports (index 0)
Last known location:
 - None
```

What can I do ?
  [2025-09-26T14:46:35Z] @malmeloo: Has your airtag been away from your apple devices? They only go into 'separated' mode when they haven't seen their owner devices in a while, at which point they become traceable by the Find My network. If your AirTag is nearby (i.e. in bluetooth range) Apple just shows your phone's location in the FindMy app.
  [2025-09-26T16:52:26Z] @varac: Yes, I checked in a situation where the AirTag is away from the Iphone, and the IOS FindMy app shows the current location right (including a recent "last seen" timestamp of a few minutes).
But FindMy.py still shows `None` as `Last known location`.

OpenTagViewer also just shows the location of the time where I imported the AirTag, with no changes after that.
  [2025-09-26T16:57:03Z] @varac: If there's anything I could provide to help debugging please let me know.
  [2025-09-26T21:28:10Z] @malmeloo: Did you dump your airtag using the utility from this library or did you convert from a plist file? If you dumped it using the tool, can you share the values of the `alignment_date` and `alignment_index` fields in the json file?

  [2025-09-27T11:41:54Z] @varac: Yes, I did use `python3 -m findmy decrypt --out-dir accessories/` to dump the json, here are the relevant values:

```json
    "alignment_date": "2025-09-25T07:34:40.038242+00:00",
    "alignment_index": 1
```
  [2025-09-27T11:56:47Z] @malmeloo: Could you try setting the alignment date to a month in the past and then run the script again? That worked for someone else who had a similar issue. I'm looking into it.
  [2025-09-27T12:04:35Z] @varac: Awesome, that worked 🥳 

```sh
❯ python3 ./examples/airtag.py accessories/xxx.json
Logged in as: xxx
INFO:findmy.reports.reports:Fetched 0 new reports (index 2224)
INFO:findmy.reports.reports:Fetched 0 new reports (index 1934)
INFO:findmy.reports.reports:Fetched 0 new reports (index 1644)
INFO:findmy.reports.reports:Fetched 0 new reports (index 1354)
INFO:findmy.reports.reports:Fetched 0 new reports (index 1064)
INFO:findmy.reports.reports:Fetched 0 new reports (index 774)
INFO:findmy.reports.reports:Fetched 0 new reports (index 484)
INFO:findmy.reports.reports:Fetched 9 new reports (index 194)
INFO:findmy.accessory:Updating alignment based on report observed at index 208
INFO:findmy.accessory:Updating alignment based on report observed at index 208
INFO:findmy.accessory:Updating alignment based on report observed at index 211
INFO:findmy.reports.reports:Fetched 0 new reports (index 193)
Last known location:
 - LocationReport(hashed_adv_key=.., timestamp=2025-09-27 14:00:01+02:00, lat=...,lon=...)
```

  [2025-09-28T10:27:55Z] @varac: I tries again today, and now the same `airtag.py` script fails with the same json as yesterday (the one where I decreased the ` alignment_date` by 1d): 

```sh 
❯ python3 ./examples/airtag.py accessories/xxx.json     
Logged in as: xxx
Traceback (most recent call last):
  File "/home/varac/projects/apple/find-my/FindMy.py/./examples/airtag.py", line 61, in <module>
    sys.exit(main(args.airtag_path))
             ~~~~^^^^^^^^^^^^^^^^^^
  File "/home/varac/projects/apple/find-my/FindMy.py/./examples/airtag.py", line 43, in main
    location = acc.fetch_location(airtag)
  File "/home/varac/projects/apple/find-my/FindMy.py/findmy/reports/account.py", line 1156, in fetch_location
    hist = self.fetch_location_history(keys)
  File "/home/varac/projects/apple/find-my/FindMy.py/findmy/reports/account.py", line 1124, in fetch_location_history
    return self._evt_loop.run_until_complete(coro)
           ~~~~~~~~~~~~~~~~~~~~~~~~~~~~~~~~~^^^^^^
  File "/usr/lib/python3.13/asyncio/base_events.py", line 725, in run_until_complete
    return future.result()
           ~~~~~~~~~~~~~^^
  File "/home/varac/projects/apple/find-my/FindMy.py/findmy/reports/account.py", line 720, in fetch_location_history
    return await self._reports.fetch_location_history(keys)
           ^^^^^^^^^^^^^^^^^^^^^^^^^^^^^^^^^^^^^^^^^^^^^^^^
  File "/home/varac/projects/apple/find-my/FindMy.py/findmy/reports/reports.py", line 387, in fetch_location_history
    return await self._fetch_accessory_report(device)
           ^^^^^^^^^^^^^^^^^^^^^^^^^^^^^^^^^^^^^^^^^^
  File "/home/varac/projects/apple/find-my/FindMy.py/findmy/reports/reports.py", line 488, in _fetch_accessory_report
    ret |= await _fetch()
           ^^^^^^^^^^^^^^
  File "/home/varac/projects/apple/find-my/FindMy.py/findmy/reports/reports.py", line 439, in _fetch
    new_reports: list[LocationReport] = await self._account.fetch_raw_reports(
                                        ^^^^^^^^^^^^^^^^^^^^^^^^^^^^^^^^^^^^^^
        [(list(cur_keys_primary), (list(cur_keys_secondary)))]
        ^^^^^^^^^^^^^^^^^^^^^^^^^^^^^^^^^^^^^^^^^^^^^^^^^^^^^^
    )
    ^
  File "/home/varac/projects/apple/find-my/FindMy.py/findmy/reports/account.py", line 677, in fetch_raw_reports
    raise UnhandledProtocolError(msg)
findmy.errors.UnhandledProtocolError: Failed to fetch reports: None
```

I tried to decrease the `alignment_date` again by 1d (now 2d earlier than the original one), and with this modification it works again 🤷 : 

```
❯ python3 ./examples/airtag.py accessories/xxx.json
Logged in as: xxx
INFO:findmy.reports.reports:Fetched 2 new reports (index 210)
INFO:findmy.accessory:Updating alignment based on report observed at index 211
Last known location:
 - LocationReport(hashed_adv_key=xxx, timestamp=2025-09-27 14:00:01+02:00, lat=xxx,, lon=xxx)
```
  [2025-09-28T15:55:15Z] @pablobuenaposada: Something is off even with pre 0.9.2, I am also getting quite some UnhandledProtocolError suddenly
  [2025-09-28T18:13:50Z] @milaq: Confirmed.
Can't fetch the correct last location report with 0.9.2. Either throws the UnhandledProtocolError from above or (if it works, at least sometimes) displays an old location report instead of the newest one.

Works fine with 0.9.0.
_Except when I poll too often, then I also get the same UnhandledProtocolError_

**Thanks for your awesome work btw @malmeloo 🥇**

  [2025-09-28T19:16:31Z] @malmeloo: I have a suspicion of what the issue could be, I'll try to implement a fix soon. The new version is a bit more aggressive in terms of making requests to Apple than the last one, especially with alignment issues like this, so I think some rate limits might be kicking in. They should (mostly) resolve themselves once a fix is deployed.
  [2025-11-11T17:23:36Z] @malmeloo: This should be fixed in the latest version

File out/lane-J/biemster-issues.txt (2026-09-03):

########## biemster/FindMy #40 ##########
TITLE: Issue with IOS 17 
STATE:closed CREATED:2023-12-06T16:36:21Z CLOSED:2024-03-26T22:48:32Z USER:@shiprec
--BODY--
Are you all seeing reporting issues from devices that have upgraded to IO17?  I haven't seen any updates come through since my phone upgraded but when I go back to 16 it works fine.
  [2023-12-06T16:43:12Z] @biemster: I see you opened a similar issue in the openhaystack repo, but both of these projects have nothing to do with iOS. Can you elaborate exactly what works fine on 16?
  [2023-12-06T16:50:03Z] @shiprec: Apologies I wasnt sure where the right place would be to ask this.  The FindMy network was working well using OpenHaystack, ie we were able to pull in location reports but I noticed as soon as my phone (and others) upgraded to IOS17, the updates from the airtag clones stopped coming in.  I wasnt sure if you or others were seeing the same issue.
  [2023-12-06T16:55:30Z] @biemster: It's possible that apple ids connected to iOS17 require a different API to retrieve the reports. Do you have an error message of any kind from either openhaystack or the code in this repo?
  [2023-12-06T17:04:48Z] @shiprec: I will ask my partners to see if there are any error messages and get back to you.
  [2023-12-06T18:11:19Z] @redex557: I can kind of confirm this issue, without any specific proof to confirm it so this might be biased. Last week I spend some time setting up new nrf51 devices and testing some alternative firmware with key rotation. Some devices never showed up and one took multiple hours to get a single report. 
All this while (at least) two iPhones where close, both running the latest iOS 17 update. 
  [2023-12-06T18:20:14Z] @biemster: That's very worrisome, maybe iOS17 can distinguish between real and cloned airtags?
  [2023-12-06T19:35:15Z] @shiprec: Yeh there are no error messages, we just aren't getting any reports from IOS 17 devices...
  [2023-12-14T16:33:40Z] @biemster: I'd like to keep this open if you don't mind, if future iOS and macOS devices know how to identify fake airtags this needs to be fixed if at all possible.
  [2023-12-18T08:29:11Z] @biemster: Also the pypush discord is reporting this issue
  [2023-12-19T01:25:20Z] @Itheras: Could this have something to do with this ? (https://github.com/seemoo-lab/openhaystack/issues/49#issuecomment-825186095) I wonder what that byte is could he just be talking about the status byte or something different. And this other piece of information (https://github.com/seemoo-lab/openhaystack/pull/225#issue-2023652959) I am testing this to see if there is any diference. 
  [2023-12-19T10:40:35Z] @biemster: That's a great find @Itheras ! I was not aware of either of those, but they seem easy to implement. Having a micropython implementation is still high on my list, maybe it's time to finish that so I can easily experiment with these suggestions.
  [2023-12-23T22:08:16Z] @Systm21: @Itheras @biemster  Are there any updates on this? it is noticeable that far fewer reports are coming in than before.
  [2023-12-24T00:36:46Z] @biemster: No updates yet on this, also I lack an iOS17 device to do any testing..
  [2023-12-24T16:50:16Z] @loganmimaroglu: I have been using OpenHaystack's HCI code for a RPi4B and have 2 iPhone 14 Pro Max's running iOS 17.1.2 and iOS 17.2.1 that I've placed near the device. I was getting, on average, 12 reports per 24 hours. I honestly thought this was quite bad but it is > 0.

The MR that @Itheras links to (https://github.com/seemoo-lab/openhaystack/pull/225#issue-2023652959) improved this quite a bit. The changes to the HCI code lead to me getting around 72 reports per 24 hours. This did change the transmission frequency from 2000 ms to 200 ms which I suspect could be the primary contributing factor... I will need to test more.
  [2023-12-24T17:10:46Z] @Itheras: Nothing on my end i dont have a computer with me until after the 25th but if someone can check i was reading apples documentation it says we should be setting the Hint byte to the value of the 5th byte of the mac address I believe we always setting the Hint byte to 0. Can someone check i am on mobile if not I'll check after Christmas 😅. 
  [2023-12-24T17:34:36Z] @loganmimaroglu: > Nothing on my end i dont have a computer with me until after the 25th but if someone can check i was reading apples documentation it says we should be setting the Hint byte to the value of the 5th byte of the mac address I believe we always setting the Hint byte to 0. Can someone check i am on mobile if not I'll check after Christmas 😅.

For the Lenze st17h66 source this appears to be true.

Screenshot 2023-12-24 at 12 32 25 PM

The HCI code I'm running also does this:
```python
@staticmethod
def advertisement_template():
    adv = ""
    adv += "1e"  # length (30)
    adv += "ff"  # manufacturer specific data
    adv += "4c00"  # company ID (Apple)
    adv += "1219"  # offline finding type and length
    adv += "00"  # state
    for _ in range(22):  # key[6:28]
        adv += "00"
    adv += "00"  # first two bits of key[0]
    adv += "00"  # hint
    return bytearray.fromhex(adv)
```

  [2023-12-24T18:51:38Z] @Itheras: It appears there are more differences than we thought, and any one of these could be causing the issue. I’ve attached the expected content. @loganmimaroglu  Thank you. Also great that you are seeing a positive result we should confirm if that is the actual fix.


  [2023-12-24T20:02:38Z] @Systm21: > For the Lenze st17h66 source this appears to be true.

Have you tried this? will the tags then also be recorded again under ios17?
  [2023-12-24T21:59:23Z] @Itheras: @Systm21 Well there is 3 things to check the AdvertisementType, the status byte "the first 5bits have values that are expected" and the Hint that should not be 0.  It seems changing advertising type had good results but we still need to confirm and the other 2 needs testing. I will test after the 25th i am on mobile now 😅. Merry Christmas everyone. 
  [2023-12-25T01:23:39Z] @Systm21: That sounds like a solution, hopefully it won't affect the undercover mode of our tags. If it does, you can still keep the project alive. It would be a shame if it was already over before it had really started (where the first macless solutions are available).
  [2023-12-26T21:59:25Z] @Itheras: I think I can call this confirmed the problem is the advertisement type.  would like if someone else can also confirm but we already have the same good results from @loganmimaroglu 
  [2023-12-26T23:22:31Z] @Systm21: What exactly is this hint byte doing that seems to be the problem?
  [2023-12-27T03:06:31Z] @Itheras: @Systm21  I am not sure but it may be that is not the issue after all.  I noticed a difference changing the advertisement type from unconnectable scannable undirected to connectable scannable undirected  I have not tested the hint or status byte much still. we should look at all 3 factors to future proof I am just a little busy at the moment.
  [2023-12-27T09:01:58Z] @biemster: Isn't the increase @loganmimaroglu sees coming from the broadcast freq change to 5Hz?
  [2023-12-27T17:19:48Z] @igrowstuff: I have tried the linked HCI code using my RPI4 and I get no reports on my two iPhone 14 devices running 17.2.1. Only time I ever get any reports is if I turn the Bluetooth on, on my Mac. 
  [2023-12-27T19:44:42Z] @loganmimaroglu: > I have tried the linked HCI code using my RPI4 and I get no reports on my two iPhone 14 devices running 17.2.1. Only time I ever get any reports is if I turn the Bluetooth on, on my Mac.

I didn't even think about my Mac, oof. Let me test again...
  [2023-12-27T20:27:00Z] @Itheras: @biemster Yeah can confirm changing advtype has no effect i saw more reports because neibor had family visiting.

Now trying changing status and hint.
  [2023-12-27T21:51:11Z] @Systm21: I think it has something to do with our stealth mode. Apple is quite behind on the anti-stalking thing and I don't think they're going to completely change the basic system now.
  [2023-12-27T21:58:32Z] @igrowstuff: > I think it has something to do with our stealth mode. Apple is quite behind on the anti-stalking thing and I don't think they're going to completely change the basic system now.

Maybe so. However I don't really understand why you would only enforce that on iOS 17. Other than the tag not being registered to an apple account the tags aren't stealth are they? Don't they just emulate a device in its separated state? The underlying system must be the same as it still works on older iOS and the latest macOS 
  [2023-12-28T00:00:14Z] @Itheras: @igrowstuff  Apple doesn't know if a tag is registered to an account or not. In function the lost mode advertising key tells apple nothing by design . It just gets uploaded. They must be doin a extra check with the data received that doesn't match what is expected. 
  [2023-12-28T07:43:39Z] @igrowstuff: I have tried setting the hint to key[5] and modifying the status byte and can't seem to generate any other reports. 

Maybe there is an updated protocol document available? If there is I do not have access to it
  [2024-01-03T11:55:16Z] @humpataa: No updated protocol document, date of last change is May 18, 2022.

  [2024-01-03T12:24:26Z] @biemster: @humpataa To comment on your edited message I doubt that ios17 has an extra check on the validity of the broadcasts it sees in terms of registered keys, since such a check is much easier implemented server side and would immediately work for all versions of ios and macos.
The fact that only ios17 iphones (or also ipads?) are able to discern them leads me to believe there is something we are missing in the details of the BLE broadcast. I really hope that they are not also listening for the UWB stuff a real AirTag sends, because that will be very difficult to emulate.

  [2024-01-03T12:30:35Z] @humpataa: @biemster after thinking about all this again, I believe you are right: nothing has changed really, but iOS devices now obviously check something that hasn't been taken into account before. I am actually using the full Status byte and will try to stick to the document instead (using only bit 6-7 and keeping the others untouched). Same with the Hint: what does "Byte 5 of the Bluetooth address" mean? The MAC address? It is always set to 0 in my code ...
  [2024-01-03T14:29:01Z] @igrowstuff: I too thought about the UWB broadcasts. I don't think all third party authorised airtags have the UWB capability so would assume they would also break on iOS17
  [2024-01-03T14:52:09Z] @humpataa: Could someone point me to some document how AirTags make use of UWB? I have my doubts because I cannot find anything about this in FindMy network specification mentioned above.
  [2024-01-03T15:03:11Z] @humpataa: > ... using the full Status byte and will try to stick to the document instead (using only bit 6-7 and keeping the others untouched). Same with the Hint: what does "Byte 5 of the Bluetooth address" mean? The MAC address? It is always set to 0 in my code ...

To quote myself: I have checked what my real AirTag advertises (separated) and set that as fixed Byte 2 (0x08) and set Byte 26 (Hint) to MAC addresses last byte. The device is advertising for half an hour and it indeed showed up in reports again! Unfortunately, I cannot make sure it is my own iPhone (iOS17) "catching" it, since it is quite a close neighborhood here ...

  [2024-01-03T18:29:03Z] @Systm21: To check the UWB stuff:
You can clone bluetooth beacons with "nrf connect" on android for example. does anyone have an airtag or official licensed product, that can be cloned and then remove the batterys? If the reports come in without a problem the UWB stuff doesn't matter. 

I haven't had a close look at nrf connect yet, but it may be that it is better to play with the individual bytes than to permanently flash/reflash new tags. 
  [2024-01-03T18:44:39Z] @malmeloo: > To check the UWB stuff: You can clone bluetooth beacons with "nrf connect" on android for example. does anyone have an airtag or official licensed product, that can be cloned and then remove the batterys? If the reports come in without a problem the UWB stuff doesn't matter.
> 
> I haven't had a close look at nrf connect yet, but it may be that it is better to play with the individual bytes than to permanently flash/reflash new tags.

Android will randomize the BLE address when advertising, and since the public key is encoded in that address it will be different from the cloned airtag. That said, I think it should still be possible to fetch those reports if you know what address it is using, as you only need the hash of that public key; you just won't be able to decrypt them. Have you already tested this by any chance?
  [2024-01-03T18:51:28Z] @Systm21: I'm not into it that much, it was just an idea. 
  [2024-01-03T18:57:00Z] @malmeloo: Ah gotcha, thought you'd tried it before. It's some interesting food for thought though, I would kill to have my phone act as a beacon...
  [2024-01-03T20:10:16Z] @humpataa: > To check the UWB stuff: You can clone bluetooth beacons with "nrf connect" on android for example. does anyone have an airtag or official licensed product, that can be cloned and then remove the batterys? If the reports come in without a problem the UWB stuff doesn't matter.

Interesting idea! I have both Android and iPhone with NRF Connect installed. And an original AirTag, an official Clone (Maginon Smart Tag) and of course my fake tags. Maybe I'll find some time tomorrow.

Apart from that, I have checked recent update details of iOS and it seems they have indeed made some changes to FindMy, claiming security fixes of course. So I have updated my iPhone to the latest it offered (17.2.1), refreshed two of my devices: one with my older code, one as close to the specification as possible (bits and hint). Both show up in the reports, but again, I cannot make sure it is my own phone doing this ...

> I haven't had a close look at nrf connect yet, but it may be that it is better to play with the individual bytes than to permanently flash/reflash new tags.

I am programming my devices using Espruino Javascript, so I don't have to flash all the time, makes it easy to try things.

  [2024-01-03T21:22:41Z] @humpataa: Tried cloning an AirTag using Android NRF Connect: it is not being recognised, at least FindMy app on iPhone cannot see it anymore (neither nearby nor separated). The advertising does not look good anyway, it uses a public key (cannot change) which surely doesn't match specification. I will try disabling bluetooth on my phone and see if there is someone around reporting my devices or it is depending on mine overnight.
  [2024-01-03T22:25:36Z] @Systm21: You told us, that you have a possible working Tag with ios17. How long does it take to retrieve the first reports? Maybe you can switch off your phone for a longer period to validate it... (Dont know if switching off bluetooth is enough)
  [2024-01-04T20:43:12Z] @humpataa: Must have been someone in the neighborhood. I have made several tests today, setting type (scannable / connectable), bits of status byte, correct hint byte, even disabled name and set advertising to 2000ms – just like a real AirTag. Having my phone (iOS17), a MacBook and an iMac around does not result in reports. As soon as I leave the office, drive a few miles, reports come up – my tags are recognised. So I guess with more and more iPhones updating reports will get fewer and fewer making fake tags useless. I'm out of ideas, still doubt it is UWB however.

  [2024-01-04T23:14:41Z] @Itheras: @humpataa yeah is definitely not related to UWB since I am testing with some find my compatible tags that don't use it and they work normally. I am starting to look into CSA mode.
  [2024-01-05T06:41:11Z] @Systm21: Is it maybe possible, that our keys can be filtered out somehow and then be locked out from the system? 
  [2024-01-05T07:40:11Z] @humpataa: > Is it maybe possible, that our keys can be filtered out somehow and then be locked out from the system?

My first idea was that newer iPhones send all the keys of their bound AirTags to the server. Even from older tags. That way, Apple's server now knows what reports to reject, because our tags never get registered. Older phones just keep sending without checking the validity first, resulting still in reports now and then. So our keys are not blocked, just not validated.

But as @biemster already said, this doesn't really make sense. It would make problems because every AirTag would need a different set of keys coming from the factory – and considering the high number of AirTags & certified clones, this sounds highly unlikely. Could be that AirTags generate their set of keys when activated (or even get them from the owners phone) and it sends them to the server to make them valid. But afair there is nothing about this in the technical specification making it unlikely as well.

Since they are working [with Google](https://www.techradar.com/phones/android/android-find-my-device) to create a joint FindMy network, this might be a reason for changes. Something with recognising tags must have changed that hinders iOS17 to send locations.

OR – I doubt it, but still hope – it is just Apple's fault: they somehow screwed it up when adding latest AirTag features like sharing etc. – after all: are we REALLY SURE original AirTags still work with iOS17 phones? It may just seem so because there are enough older phones around. This could even make it hard to identify that iOS17 actually HAS a problem sending locations with ALL tags. It DEFINITELY has no problem recognising tags in general: I was testing key rotation around Christmas (already having iOS17) and my phone was telling me there may be some tag that does not belong to me, so the stalking alarm still works.

  [2024-01-05T11:10:55Z] @biemster: I think we already discussed this, but the only validated keys hypothesis should be fairly straightforward to test by having a fake tag sending out a working airtag's broadcast right? I know on android we cannot set the bluetooth mac anymore, but the ESP32, st17h66 or the linux hci script should be able to send out the exact public key.

We might not even need to own an airtag, but just catch one in the wild and wait for the key to roll and start sending that broadcast again. (if that works it will confuse the actual owner of the airtag though, so let's not go overboard with that)

I'm still quite convinced that any key blocking or validating would be done server side, and not through a software update on specific devices.
  [2024-01-05T19:43:46Z] @Itheras: @biemster I will test that today. but I am not sure how that would work how can they validate when most of the phones out there are old or in older software versions. newer phones won't have nothing to validate against since those older phones and firmwares don't upload the necessary information do even do a check . so anyone under ios17 would have findmy experience severely impacted as time goes on.
  [2024-01-05T19:58:27Z] @biemster: @Itheras great! I'm not sure if I understand the rest of your comment though, I tried to explain my point of view that I find it unlikely that the keys are checked for validity now. That's your opinion too right?
I highly suspect that we are missing a bob or a bit in our advertisement.
  [2024-01-05T20:32:46Z] @Systm21: Maybe @adamcatley can help us with our problem, themes like he is the right contact person for our problem. 

If anyone can help us, it's him. 

[Reasearch from Adam](https://adamcatley.com/AirTag.html)
  [2024-01-05T21:19:35Z] @malmeloo: Do AirTags also expose the Find My service UUIDs while in separated state? I have a protocol spec from 2020 which says that the they must be exposed while in pairing state, but I don't think it says anything about it for the other states. It could be that those UUIDs are always exposed - how else do you get a lost airtag to make a sound? Maybe iOS 17 just adds an additional check to see whether those UUIDs are visible before uploading the report.

I've written a utility script [here](https://github.com/malmeloo/FindMy.py/blob/main/examples/device_scanner.py) that scans for nearby devices and shows what are essentially all identifying data points, at least to my knowledge. I don't own any real AirTags myself, but it should include the UUIDs in its output. Maybe someone with a real tag can test it :)
  [2024-01-05T22:17:55Z] @humpataa: > Do AirTags also expose the Find My service UUIDs while in separated state? I have a protocol spec from 2020 which says that the they must be exposed while in pairing state, but I don't think it says anything about it for the other states. It could be that those UUIDs are always exposed - how else do you get a lost airtag to make a sound? Maybe iOS 17 just adds an additional check to see whether those UUIDs are visible before uploading the report.

Interesting question. NRF Connect says a separated AirTag offers this:

Generic Access UUID: 0x1800
Generic Attribute UUID: 0x1801
UUID: 7dfc8000-7d1c-4951-86aa-8d9728f8d66c
UUID: 7dfc7000-7d1c-4951-86aa-8d9728f8d66c
UUID: 7dfc6000-7d1c-4951-86aa-8d9728f8d66c
UUID: 7dfc9000-7d1c-4951-86aa-8d9728f8d66c

The 4 longer seem to be Apple specific services, may indeed be used to let the AirTag play a sound ([see here](https://www.metabaseq.com/apple-airtags-unawanted-tracking-capabilities/)). Wether they are essential to iOS17 for sending location packets needs to be tested.

  [2024-01-05T22:27:23Z] @Systm21: Apple Tags are a thing to have an Eye on, but i think the Cheap China "Works with Apple Find My" Tags are more interesting at this moment. The cheap ones do not have the UWB stuff and are better to research, i think. 
  [2024-01-05T22:40:25Z] @Systm21: > Interesting question. NRF Connect says a separated AirTag offers this:
> 
> Generic Access UUID: 0x1800 
>Generic Attribute UUID: 0x1801 
>UUID: 7dfc8000-7d1c-4951-86aa-8d9728f8d66c 
>UUID: 7dfc7000-7d1c-4951-86aa-8d9728f8d66c 
>UUID: 7dfc6000-7d1c-4951-86aa-8d9728f8d66c 
>UUID: 7dfc9000-7d1c-4951-86aa-8d9728f8d66c
> 
> The 4 longer seem to be Apple specific services, may indeed be used to let the AirTag play a sound ([see here](https://www.metabaseq.com/apple-airtags-unawanted-tracking-capabilities/)). Wether they are essential to iOS17 for sending location packets needs to be tested.

Interesting point, what if someone adds cloned/randomized UUIDs to a fake tags, from the documentation the 9000 uuid should be the findmy identfier
  [2024-01-06T08:59:14Z] @malmeloo: > > Do AirTags also expose the Find My service UUIDs while in separated state? I have a protocol spec from 2020 which says that the they must be exposed while in pairing state, but I don't think it says anything about it for the other states. It could be that those UUIDs are always exposed - how else do you get a lost airtag to make a sound? Maybe iOS 17 just adds an additional check to see whether those UUIDs are visible before uploading the report.
> 
> Interesting question. NRF Connect says a separated AirTag offers this:
> 
> Generic Access UUID: 0x1800 Generic Attribute UUID: 0x1801 UUID: 7dfc8000-7d1c-4951-86aa-8d9728f8d66c UUID: 7dfc7000-7d1c-4951-86aa-8d9728f8d66c UUID: 7dfc6000-7d1c-4951-86aa-8d9728f8d66c UUID: 7dfc9000-7d1c-4951-86aa-8d9728f8d66c
> 
> The 4 longer seem to be Apple specific services, may indeed be used to let the AirTag play a sound ([see here](https://www.metabaseq.com/apple-airtags-unawanted-tracking-capabilities/)). Wether they are essential to iOS17 for sending location packets needs to be tested.

Interesting! The older protocol spec I found lists different UUIDs, but it does mention that they will change in an updated document. Is anyone willing to share a copy of the 2022 version?

Anyway, I'm hoping that simply exposing those UUIDs should be enough; if the rest of my doc is up-to-date then only one of those services should be accessible to non-owners of the device, and that one only allows for sound control which is an optional feature. Also, it's one thing to just receive broadcasts, but another to actually communicate with the device which would be far less reliable; therefore I think (hope) it's just a matter of tweaking the "public image" of the tag to match the official ones.

I'll see if I can get my hands on a 3rd party tag and have someone pair it for me in the coming days; I think the easiest way to go forward right now is to just clone the BLE address/payload of a real tag and work from there.
  [2024-01-06T14:01:12Z] @Systm21: I have read a lot the last hours, just about uuids and what they do... It seems, that they get randomly renewed by the Tag itself (not the identifier part). The good part in this is: The Server doesn't know the random payload of the uuid, so we can fill it with something valid, that comes from an active Airtag (or completely random maybe). 

What I also thought about: in ios17 it was introduced that you can now share airtags between iphones. Maybe they need the UUID for this and the blocking of our tags was just a coincidence. 

I mean, what interest would Apple have in willfully blocking us? Openhaystack was already big in the press in 2021 and nothing happened. Then there are the extremely cheap itags from the Far East. The licenses can't be that expensive if such a part is already available for ~€4.  I'm not deliberately blocking a few tinkerers who are having fun with their findings. I mean, how many people should copy this? 

By the way, there are also some people in the apple forum who can no longer find their original airtags after the update to ios17. 
  [2024-01-06T16:34:44Z] @humpataa: I have tried adding UUID 7dfc9000-.... to the advertising. NRF Connect shows "Apple reserved service", so it is visible. Key advertising and hint byte looking good as well. Not getting noticeably better. 

I am sure most (all?) chinese "clones" are not using Apple's network. I have some on my desk looking exactly like AirTags, but are just plain BLE devices, completely useless when they get out of range of the phone.

> By the way, there are also some people in the apple forum who can no longer find their original airtags after the update to ios17.

That's what I thought: they may have really screwed it up. It still looks good for many, because old iOS are still around.

  [2024-01-06T16:48:22Z] @Systm21: > I am sure most (all?) chinese "clones" are not using Apple's network. I have some on my desk looking exactly like AirTags, but are just plain BLE devices, completely useless when they get out of range of the phone.
> 
> >

U told us, that you have an Maginon Tag, this Tag also works with the network and i can give you 100% they all use the findmy network from apple. The Itags must be added in a bit different way, than the fancy airtag popup, but it works also... 
Not every from this cheap tags supports it, thats right. It must be advertised with "Works with Apple Find My". 

please don't put so much hope in NRF Connect, I don't know if the results are really usable. It was just an idea and is completely unvalidated. It's possible that you won't be able to recreate airtags with it. 
  [2024-01-06T17:06:02Z] @humpataa: Yeah, I use NRF Connect only to check devices. Cloning does not work properly (at least not enough to clone AirTags), so I have checked by altering the code I use with my tags The Maginon I mentioned is an official clone, but many of the chinese are not. You can check [here](https://mfi.apple.com/account/accessory-search).
  [2024-01-06T17:21:02Z] @Systm21: The Chinese ones are official too, so i wrote, that the licences cant be that expensive. 
They are cool, but not working with Android (as the original Airtags). 

I've also seen, that Lenze is offering an [FindMy SDK](https://lenzetech.com/findmy) for their Chips, so it should not very difficult for the dealers.
  [2024-01-06T18:14:59Z] @Itheras: ok i cloned a Chinese official tag. Something really interesting happened. The cloned tag was visible to the find my app and marked as just seen as the original tag . The status bit was set to 0x20 the app sees this as full battery but reading all the documentation i thought it was supposed to be 0x10. Now the interesting part i left home and left the tag on top of my sonoma mac mini and i get no new reports. So find my updates only while in range. Now i will test with the original when i get back later today.
  [2024-01-06T18:22:59Z] @Itheras: @Systm21 yeah they actually offer a all in one solution st17h6x find my is really cheap 
  [2024-01-06T18:33:13Z] @humpataa: > So find my updates only while in range. 

That is maybe because is no longer in "separated" mode. Your phone sees it because it is close.
But interesting that a clone is considered as real.

Btw, status 0x20 is 0b00100000 ... so that is battery state "00" which means full (see spec excerpt somewhere above).

  [2024-01-06T19:02:52Z] @Systm21: @humpataa is your Maginon Tag activated? Can you post the UUID's to compare the difference, or better, can u tell us what the difference is? It must be activated, otherwise it is a different UUID
  [2024-01-06T19:03:20Z] @Itheras: @humpataa Definitely just separated mode. I copied the separated adv key from a Chinese but valid tag. I used that key to program a openhaystack tag. Using that separated key find my sees it but only while in range . If i am outside the home and there is no device below 17 or sonoma i dont get any updates in find my app.
  [2024-01-06T19:13:32Z] @Systm21: I have another researcher, it seems the uuid is not that random, as i thought. 

[D20 Forensics](https://blog.d204n6.com/2022/04/airtag-youre-it.html?m=1)
  [2024-01-06T19:38:38Z] @Systm21: I told you about my suspicion that the locking out of our clones was possibly a coincidence, because they urgently need the feauture now for sharing the tags. This and Itheras' recent findings are now making more and more sense. 
The uuid is shuffled when the owner device is not nearby. This is why Itheras was able to recognize the clone as a valid tag. The owner device is nearby, it clones the UUID of the connected tag and passes the information on to the clone accordingly. Logically, the clone then behaves like the original.

It would now be interesting to know what exactly changes in the payload of the uuid (owner nearby/not nearby) and to what extent we can randomize this. 
I hope we don't need a basic UUID from the server on which everything is based. 

The fact that the faketag has not sent any reports could be explained by the fact that it is either currently being seen by your devices or is possibly outputting the uuid of "owner nearby". This may temporarily prevent further reports in order to minimize traffic in the find my network.
  [2024-01-06T20:38:47Z] @Itheras: Just want to make sure everyone understands. I removed the battery of the original tag to force lost mode then i copied the adv key. I then kept the original off and only the copy is broadcasting in lost mode the same way openhaystack work no uuids or anything just the adv. the find my app still tracks this tag like it was the original but only while in range. I will now do the same with the original if i can get report while away then definitely we are missing something if it behaves the same way then apple broke something mistakenly.
  [2024-01-06T22:37:04Z] @Systm21: You have to involve the UUID, im sure. 
  [2024-01-07T02:09:23Z] @Itheras: Well i just ran the test with the original chinese but certified tag and no reports. The tag wont update in findmy unless i am in range or there is a phone under ios 17 nearby. Please someone else confirm but it seems ios 17 and up and sonoma are not uploading tag data at all for real or our tags. I ran this test many ways in my home theres is 2 iphones with ios17 and 1 sonoma computer while the registered phone is near there is updates if the tag is in lost mode "turning off the registered phone and then reinserting the battery on the tag" it goes silent i had to take the tag to a gas station after waiting for 2 hour of nothing and in 15 mins i got a new location update. Tested this with the real and with the cloned tag that only had the lost adv key same results on both. I think this is confirmed ios17 and sonoma are borked while dealing with tags in lost mode. I am going to try to catch the traffic from my mac to the upload server maybe idkey is uploaded but messed up in someway.
  [2024-01-07T15:15:45Z] @Systm21: I think the advertising Data is more interesting.  Where can i get the documentation?
  [2024-01-08T09:58:08Z] @humpataa: You'll need a MFi developer account to access the documents.

I am also more and more convinced that iOS17 has a serious problem and it is not our fake tags.
Can anyone check iOS17 network traffic if it is actually sending "finder reports" at all?
The openhaystack paper says "finder devices" make POST requests to "https://gateway.icloud.com/acsnservice/submit" to deliver encrypted location reports about AirTags and other Apple devices (page 7).

  [2024-01-09T18:30:34Z] @MTalon63: > I really hope that they are not also listening for the UWB stuff a real AirTag sends, because that will be very difficult to emulate.

I don't think it would a good move on Apple side, not only cheaper, FindMy compatible tags usually don't include them, UWB also has much lower range, especially in crowded spaces where the 24GHz signal can't pass through people nor bounce around them.
It would effectively change airtags pickup range to 5m at best.

  [2024-01-09T18:56:52Z] @Systm21: It not belongs to UWB, the cheap and licensed Tags from China do not have any UWB stuff on board. 
  [2024-01-09T18:59:37Z] @MTalon63: So, currently, the most suspected culprits are UUIDs and sloppy job done by Apple engineers with IOS17 updates?
  [2024-01-09T20:17:15Z] @Systm21: Ios17 has got the feature with the sharing of airtags. If I interpret this correctly from the limited information I have, the UUID plays an important role in this. You have to research the UUID much further and preferably collect and compare recordings of several airtags or itags (licensed Cheap china Tags). I have compared this with the last months/versions of ios, there have always been problems with airtags and the ios updates. I don't see that there is a problem with the os right now. 
  [2024-01-09T21:20:56Z] @Itheras: @Systm21 I tried using a genuine findmy compatible tag only with ios17 devices i got no reports. No sharing enabled. just a regular authorized third party findmy tag. I live in rural setting all phones around this tag are updated to ios 17 i turned off the phone that registered the tag and left 3 other devices on. Waited for hours no 1 report i have to drive 15 mins to a nearby gas station to start receiving updates.
  [2024-01-10T15:58:40Z] @shiprec: @Systm21 are you able to reach out to the manufacturer and ask them if they have an answer for why IOS17 doesnt work with their devices?
  [2024-01-10T16:13:40Z] @Systm21: Of course I can, but you can do it just as well. There is not one manufacturer, there are many. And to break that down to Lenze... I don't know what their SDK looks like and to what extent the manufacturers are involved. 
You can ask someone at Maginon etc., I don't have an iphone or tag, so I wouldn't ask for now. 
  [2024-01-10T18:21:22Z] @ngxson: Not just these findmy-compatible (clone) tag that have problem. I recently receive much less update from my **real** Apple AirTag (before it was one report per ~6 hours, now it takes days per report). I started to wonder if apple actually has problem with their servers...
  [2024-01-10T18:35:56Z] @Itheras: I am really inclined to believe the problem is with ios17 and Sonoma. I see the same behavior not a single report from ios17 and Sonoma even with real 3rd party tags.
  [2024-01-10T18:38:42Z] @Itheras: I have installed a separate certificate in to my Sonoma Mac to decrypt all https traffic I have not seem a single request to (https://gateway.icloud.com/acsnservice/submit) in 2 days I have been looking at the traffic.
  [2024-01-10T20:58:02Z] @humpataa: > I have installed a separate certificate in to my Sonoma Mac to decrypt all https traffic I have not seem a single request to (https://gateway.icloud.com/acsnservice/submit) in 2 days I have been looking at the traffic.

Have you seen traffic to URL https://gateway.icloud.com/acsnservice/fetch? This one is used to get reports about devices by FindMy app (and openhaystack).

Do you have a phone with iOS16 at hand to check if that one uses the submit / fetch URL?

I have tried watching traffic using Fiddler and I can see the phone making contact to Apple's server to get data about the "friends" tab in FindMy app. But it says "FindMy service unavailable" a few seconds later when it tries to fetch data about devices. When I disable Fiddler proxy, everything is good again. So Fiddler seems to block these requests and I am not sure why ...

  [2024-01-11T07:22:44Z] @humpataa: > I have installed a separate certificate in to my Sonoma Mac to decrypt ...

Oh btw, this is an iMac or a MacBook? I don't think these submit "finder reports", only iPhones and iPads do.

  [2024-01-11T08:41:47Z] @Systm21: @humpataa Are you sure about that? They send out the Findmy signal, just like all other devices and have an internet connection. I would be surprised if they don't forward it to the network. 
  [2024-01-11T10:08:10Z] @humpataa: > @humpataa Are you sure about that? They send out the Findmy signal, just like all other devices and have an internet connection. I would be surprised if they don't forward it to the network.

@Systm21: Yes I am very sure about that. I have a MacBook running Monterey and an iMac running Ventura and only when  I switch on bluetooth on my older iPhone iOS16 all locations of devices (original AirTag, official clone and fake tags) get updated.

> I have tried watching traffic using Fiddler and I can see the phone making contact to Apple's server to get data about the "friends" tab in FindMy app. But it says "FindMy service unavailable" a few seconds later when it tries to fetch data about devices. When I disable Fiddler proxy, everything is good again. So Fiddler seems to block these requests and I am not sure why ...

@Itheras To quote myself: the reason for not seeing requests to submit / fetch URL as mentioned above maybe because the devices and the FindMy app use "certificate pinning". Adding a trusted certificate to watch HTTPS traffic is not sufficient, the original specific certificate is needed. 

Added a couple days later:
So I have tested a iOS16 and a iOS17 iPhone with an Apple AirTag and with a fake tag. Both phones are contacting Apple's server gateway.icloud.com on a regular basis (bluetooth turned on, display off, doing "nothing", just laying beside the tags) for hours. They make contact every few minutes, iOS16 at least every 20 minutes, iOS17 at least every 10 minutes. Because of "certificate pinning" I cannot say what URL they request.

However: when iOS16 is on, I get regular reports for my fake tag and regular updates in FindMy app for the original AirTag (on a third phone far away to be "separated" and not connected with my Apple-ID). When I turn on iOS17 phone near the tags instead, no data is getting updated: for neither device.

Trying to get our openhaystack tags working with iOS17 is a waste of time as long as it obviously doesn’t even work with original AirTags. I have filed a bug report, but have no idea how / if / when Apple will consider this a serious problem.

  [2024-01-14T15:13:15Z] @ngxson: @humpataa Thanks for the update, I was wondering why my **original** Apple AirTag report much less frequently than before. Turns out iOS 17 broke the whole FindMy system, which is clearly a bug from Apple.

Conspiracy theory: Maybe a planned obsolescence before the announcement of AirTag 2?
  [2024-01-17T17:29:52Z] @CappyT: > @humpataa Thanks for the update, I was wondering why my **original** Apple AirTag report much less frequently than before. Turns out iOS 17 broke the whole FindMy system, which is clearly a bug from Apple.
> 
> Conspiracy theory: Maybe a planned obsolescence before the announcement of AirTag 2?

Knowing the company we're dealing with, wouldn't be surprised.
  [2024-01-18T00:39:25Z] @MTalon63: IIRC there was something said by a known person about AirTag 2nd gen releasing last year (2023) with a new U2 chip, but due to rather small production quantities, it was pushed to 2025. At the same time, I would see why Apple would do that I want to believe that most users recognize what's up.
Unfortunately, there aren't any good alternatives, I think Google would be the only company that could launch something similar with support hardcoded into Android.
  [2024-01-25T15:10:28Z] @shiprec: 
> Trying to get our openhaystack tags working with iOS17 is a waste of time as long as it obviously doesn’t even work with original AirTags. I have filed a bug report, but have no idea how / if / when Apple will consider this a serious problem.

@humpataa  was any other progress made on this?
  [2024-01-25T16:19:59Z] @humpataa: No update. I have upgraded to iOS 17.3 and developer beta before. No change. No response from Apple.

  [2024-02-02T15:12:20Z] @shiprec: I asked one of the manufacturers of findmy tags to test and see if they saw the same results.  See below but the summary is that they were able to prove the findmy is working with IOS17 with multiple types of of their tags...

From Manufacturer:
I'd like to update you our engineer made the below tests.
Step 1. There are 3 iphone devices (2 ios16 phone, 1 ios17 phone), and Tag1 which is named "Test" was bound with one of the ios16.
 
Step 2. The ios16 phone which bind Tag1 is kept by the developer in the R&D centre, far away ( around 100~120m) with Tag1 which is close the another ios16 phone. The developer can find ios16 phone with Tag1 location updated.
 
Step 3. We put ios17 phone beside the Tag1, and they both are keeping still for around 3 hours. Then the developers checked the ios16 phone which is also still about the location information and found no location updated.
The initial judgment is that they have been separated for a long time, and the Tag1 has been in a static state for long. According to FIND MY to judge the status of the iphone device and Tag1/Tag2 tags (pls kindly see the picture as below for your ref), if iphone device and Tag1 are close to each other again, it will take a certain amount of time to establish connection. During this period, there may be server response and network problems during the process of initiating the connection, resulting in failure to connect, so the location information will be not updated in time) 
 
Step 4. Based on the results of the "above step 3", we continue to test whether Tag2 location updates will appear on the originally bound iOS16 phone when the Tag2 is close to iOS17.
This time, we used the originally bound iOS16 phone to unbind it from the device and re-establish the binding relationship (as mentioned in the step 3, leaving it alone for too long will prevent the phone and tag from quickly re-establishing a connection. Therefore, Choose the method of unbinding and rebinding (for the convenience of testing), and then the iOS16 mobile phone was taken home by A tester, the Tag2 and ios17 phone was taken home by B tester. The separation distance is more far than the separation in the step 2. After around 20 minutes, the location of the Tag2 was updated on the iOS16 phone. At the same time, the iOS17 phone close to the Tag2 also reminded the owner that the FIND MY device was following (see the picture below for details).

unnamed (2)

  [2024-02-02T15:26:02Z] @Itheras: I tested the same . Again all functionality works except lost mode on ios 17. The way to test this is to pair a tag remove the phone that paired the tag from the vicinity then remove the tag battery bring the ios 16 phone put the battery on the tag. Since the battery was removed it will be immediately in lost mode then wait to see a report on the phone that pair the tag . Repeat with ios 17 remove the battery from the tag bring the ios 17 phone and move the ios 16 away put the battery back and test again. If done so correctly and there is no other phones around the last seen will only update with the ios 16 phone not the ios 17 one.    
  [2024-02-02T15:53:08Z] @humpataa: Sorry, I can hardly understand what the chinese guys actually did. Are there devices with iOS16 somewhere around or in the neighbourhood? Any iPads? It proofs nothing.

No need to bind, unbind, remove batteries or anything, just try this:

1. This needs to be done in a "remote" environment, no other Apple iPhones or iPads being in bluetooth distance!
2. Get an iPhone with iOS16.x installed, enable bluetooth, ensure internet access.
3. Get an AirTag registered to someone else who is away at least 200 m (the AirTag must be in "lost" mode). She / he watching his phone (FindMy) having internet.
4. Get an iPhone with iOS17.x installed, disable bluetooth, ensure internet access.
5. Put both phones right beside the friends AirTag.
6. Let your friend WhatsApp you whenever the status of his AirTag gets updated. This will happen every couple of minutes.
7. Turn off bluetooth on iOS16, turn on bluetooth on iOS17.
8. You will no longer get messages from your friend because the status of his AirTag will not update. For hours. For days. Until you enable bluetooth on your iOS16 phone again.

If you see updates with only your iOS17 being on: let the friend send you the position of the AirTag – it will not be the location of your iOS17 but of someone nearby, easy to double check this way!

I am 100% sure it is one of the following problems:
- iOS17.x does not send report packages at all OR
- report packages from iOS17.x devices are not stored correctly on server OR
- server does not send out reports originating from iOS17.x when requested by FindMy app

  [2024-02-02T15:58:35Z] @Itheras: I agree @humpataa  is one of those 3 issues you mentioned.   About the battery removal is just a fast way to enter lost mode without waiting. 
  [2024-02-02T16:05:06Z] @humpataa: Apple has not replied to my bug feedback. I am trying to raise attention to this issue in several forums, including Apple's, so more people will file bug reports to wake Apple up. I can somehow understand that many don't "care" because they don't see the problem (because of many iOS16 devices, things don't look bad). But this thing is really serious and the FindMy network is getting weaker and weaker every day as more and more old devices get switched off or updated.

  [2024-02-02T18:49:50Z] @Systm21: @humpataa Maybe you should write to a few mac or iphone/apple news sites who can test it themselves and then publish articles accordingly. 

There are certainly sites that reach a lot of users. 

It's easy for the editors to test what you've found out. 
  [2024-02-11T19:53:57Z] @Systm21: Is there anything new on this subject?
  [2024-02-12T07:37:17Z] @humpataa: iOS 17.4 beta 2 still no difference.

  [2024-02-12T14:00:52Z] @shiprec: I sent the updated test request to the manufacturer but they wont get to it till after CNY holiday (they are back Feb 17th).
  [2024-02-12T16:16:52Z] @biemster: > I am 100% sure it is one of the following problems:
> 
> * iOS17.x does not send report packages at all OR
> * report packages from iOS17.x devices are not stored correctly on server OR
> * server does not send out reports originating from iOS17.x when requested by FindMy app

Did we exclude iOS17 sending out something different than just the hashed advertisement key? Maybe openhaystack reversed version 1 of the protocol, and iOS17+ is doing something fancier now? (although this would mean that the FindMy app on macOS should also have switched to the new protocol. We definitely need more network captures, both from macOS sonoma+ and iOS17+, real proper airtags, 3rd party airtags and clones)
  [2024-02-12T17:58:44Z] @malmeloo: I was thinking it might not work due to there being no key rotation. Maybe iOS 17 will only generate reports for a certain device for up to x hours as an anti-stalking measure? That would greatly reduce the number of reports generated while the tag is stationary, while not really affecting it while in movement. It would also explain why official/3rd party tags are unaffected.

I live in fairly densely packed student housing. The tag in my backpack has been stationary a few times over the past week, but it was still actively generating reports. Almost no reports have been generated at night time, yet it's still mostly the same people that are in my area. In fact, I'm willing to bet there's more people here at night than there are during the day, but phones do move in and out of range less often.

If statcounter is anything to go by, the market share of iOS 17.x in my country is around 70%. But during those stationary periods I'm frequently seeing 3-4 reports within the same minute, so they aren't generated by the same phone. I'm guessing there are around 10 neighbours in bluetooth range of my room, so if you factor in the number of android users as well, it seems rather unlikely that 17 isn't generating *any* reports at all.

If I get around to it this week, I'll try to build some firmware that does rotate keys, and does so during the night. If that results in a spike of generated reports, it might just be the reason we've been looking for.
  [2024-02-12T18:13:02Z] @biemster: Yeah that crossed my mind as well, if an iOS17 device sees the same key more than 15 minutes apart (the rotation interval, which I learned from you, great stuff in your repo!), it could deduce it's a fake tag and not report it.
  [2024-02-12T21:32:36Z] @humpataa: > It would also explain why official/3rd party tags are unaffected.

As far as my tests show it does affect all devices, original, certified and fake tags. 

Apple has [released data](https://developer.apple.com/support/app-store/) that currently around 66% of all iPhones already have iOS17, 53% of all iPads have iPadOS 17. This is still enough to keep the network running, but interval and accuracy getting worse every day.

Playing around almost every day with tags for the last months I have noticed that the distance of these little things is quite surprising even indoors. So making the problem visible really needs a quiet area.

> Yeah that crossed my mind as well, if an iOS17 device sees the same key more than 15 minutes apart, it could deduce it's a fake tag and not report it.

That would mean that iOS17 always waits until a device changes its key before reporting it ... no way, I don't think so. Key rotation is important for stalking detection only I believe.

  [2024-02-13T02:23:15Z] @Itheras: It seems there is a disconnect here. I have mentioned my test. I live in a pretty rural area where i have control of the phones exposed to the tags. official/3rd party tags are also affected i retested and tested ios 17 does not report clones or official 3rd party tags while on lost mode. I tried 3 different types from different vendors all 3rd party official none work correctly on ios17 only 16. They seems to work until they enter lost mode.

Sorry didnt see @humpataa response but he is right it affects all tags it seems. I have tested on both fake and official. Also key rotations is just for ble sniffers.

  [2024-02-13T10:14:38Z] @biemster: Thanks @humpataa and @Itheras , this thread got a bit confusing even for people that read everything.
So to conclude:

@humpataa tested
1. the $29 official airtag
2. the $4 3rd party tag
3. and the $1 openhaystack cloned tag
4. did you maybe also look at network captures?
5. Conclusion: with only iOS17 nearby no reports can be retrieved with either the FindMy app (1. and 2.) or the python script (2. and 3.)

and @Itheras tested
1. the $29 official airtag
2. the $4 3rd party tag
3. and the $1 openhaystack cloned tag
4. network captures on sonoma, no reports sent to /submit for either 1. 2. or 3. in lost mode (but it might be that only iPhones and iPads use this anyway)
5. Conclusion: with only iOS17 nearby no reports can be retrieved with either the FindMy app (1. and 2.) or the python script (2. and 3.)

@ngxson also mentioned much less reports with the $29 official airtags.
  [2024-02-13T15:26:52Z] @malmeloo: The broadcasted rotation interval is actually up to 24 hours, as the tag latches onto either the primary or secondary key until 4 AM when it becomes "lost". My "unaffected" claim was worded incorrectly as it would still affect official tags, just to a lesser degree as the effect would be reset the next day. But @humpataa and @Itheras' experiments (which I completely missed somehow, sorry!) do indeed rule that option out, as that would still generate at least *some* reports.

At the same time I find it hard to believe that this could be an issue on Apple's side, as they would presumably monitor this kind of statistic? Maybe not per iOS version, but the total number of generated reports dropping by at least ~50% does sound like something they would notice. But that's just speculation on my part.
  [2024-02-13T17:02:28Z] @humpataa: > At the same time I find it hard to believe that this could be an issue on Apple's side, as they would presumably monitor this kind of statistic? Maybe not per iOS version, but the total number of generated reports dropping by at least ~50% does sound like something they would notice. But that's just speculation on my part.

Well, it would be hard to notice if the "finder report packs" are send to Apple's server with iOS17 as usual, but either don't get stored properly or not send out properly when requested. It's practically invisible: not noticeable less reports stored, not noticeable less requests, data stored and transferred – useable or not.

It IS hard to believe that it really IS Apple's fault. But a few people have done quite a lot of tests and and LOOKS like it really is Apple's fault. I have tried to [watch traffic](https://github.com/biemster/FindMy/issues/40#issuecomment-1886773969), but it's not easy to do so. I have also made many attempts to exactly copy the advertising of an original tag ... offering services, setting the state bits, hint byte, type of advertising ... I don't know if I did it all right, but it had ZERO impact on the reports. I believe nothing has changed to the protocol (the docs haven't changed), I don't even think iOS17 is "more picky" when looking for tags, I agree with @biemster: it looks like a server side issue.

I have also asked people in several forums to recreate the issue, but it's hard as well because you not only need at least one iPhone with old iOS, an AirTag of a friend who is not at the same place and watching his Find My app, but a rural area without someone interfering. Beside filing bug reports I have tried to make contact with Apple through my MFi developer account, but have not received any response yet. Guess we just have to wait.

  [2024-02-13T17:39:36Z] @malmeloo: > Well, it would be hard to notice if the "finder report packs" are send to Apple's server with iOS17 as usual, but either don't get stored properly or not send out properly when requested. It's practically invisible: not noticeable less reports stored, not noticeable less requests, data stored and transferred – useable or not.

That's a good point, I hadn't considered that yet. Luckily though, at the current adoption rate it probably won't take long until they're forced to take a look at it.
  [2024-02-21T12:00:35Z] @humpataa: iOS17.4 beta 4 (developer): no change.

The quality of the FindMy network is getting really bad now, must be noticeable at Apple's end.

Added later ... interesting thing I have noticed lately:
I was using an even older iPhone 6s with iOS15.7.x because it was sending "finder reports", my tags (original & fake) got updated whenever I switched the phone on. It was useful for testing while playing around with key rotation and stuff.

Recently I updated it to the latest version available for this old brick: 15.8.1 released end of January. Suddenly, it does not work as a "finder device" anymore! I am not sure which version was installed before, something from 2022 I guess – definitely way before iOS17 was even announced. Apple's [version history](https://support.apple.com/de-de/HT201222) does not state any changes to MFi (FindMy) in particular, so it is unknown when exactly iOS15.x stopped working as a "finder device". My iPhone with iOS16.7.4 (released shortly before Christmas 2023) for sure works as a "finder device" – I will not update it!

This made me wondering when exactly iOS17 introduced "the problem": possibly with version 17.2 (released early December 2023). The [version history](https://support.apple.com/de-de/HT214035) at least mentioned changes to "Find My" ... so did this unintentionally screwed up the network? Does this coincidence with first reports about trouble we now all witness?

  [2024-02-22T07:39:05Z] @JayFoxRox: > The [version history](https://support.apple.com/de-de/HT214035) at least mentioned changes to "Find My" ... so did this unintentionally screwed up the network?

There isn't too much info in CVE-2023-42922; maybe @r3ggi can provide some more info about what the issue has been, or if it could be related to findability (reduced number of reports) of airtags with constant (non-rotating) keys in lost mode?

---

I believe I also saw forum posts about official airtags getting fewer reports in sharing mode (where you share the location of an airtag with someone else).
Maybe that's something better to report to Apple?
  [2024-02-22T09:32:07Z] @ngxson: > I believe I also saw forum posts about official airtags getting fewer reports in sharing mode (where you share the location of an airtag with someone else). Maybe that's something better to report to Apple?

Same here! I have an airtag (the official thing) shared by my friend. I see that it updates much less often than before iOS 17.

Before, when I was on iOS 16, I got update every 2-6 hrs, it's never more than 24 hrs. Now it takes days (as I'm writing this comment, the last location report was 1 week ago).
  [2024-02-23T18:07:33Z] @Itheras: > > The [version history](https://support.apple.com/de-de/HT214035) at least mentioned changes to "Find My" ... so did this unintentionally screwed up the network?
> 
> There isn't too much info in [CVE-2023-42922](https://github.com/advisories/GHSA-vrg7-4cjp-whcv); maybe @r3ggi can provide some more info about what the issue has been, or if it could be related to findability (reduced number of reports) of airtags with constant (non-rotating) keys in lost mode?
> 
> I believe I also saw forum posts about official airtags getting fewer reports in sharing mode (where you share the location of an airtag with someone else). Maybe that's something better to report to Apple?

I want to point out this has nothing to do with key rotation or anything of that sort. It affects all devices that depend on the findmy network. “Oficial, 3rd party, Or OHS they all have problems is separated mode.
  [2024-02-28T10:20:40Z] @humpataa: iOS17.4 RC: issue not fixed.

@shiprec you can use any AppleID for requesting any reports as long as you have the keys. The AppleID (iCloud) is only needed for encryption of traffic, Apple "items" (such as real or fake AirTags) are not bound to a specific AppleID.

  [2024-03-04T08:50:46Z] @acalatrava: The other day one of my official FindMy tracker (Chinese one) went rogue and my iOS 17 iPhone started reporting it as if it were not mine. It alerted me that a device was tracking me. 

So with this I can confirm that, at least, iOS 17 actively listen to the beacons… Not sure if it’s proxying them to Apple servers though. 
  [2024-03-04T09:13:11Z] @humpataa: Yes, I have noticed that as well: iOS17 does recognise when unknown AirTags are "following". At least THIS seems to work. We've made another test 3 hours in the woods yesterday. Carrying 4 AirTags (2 original, 2 official clones) plus 1 fake tag. Not a single update for any of the devices – and we've even had at least 50 people passing! All without iPhones? Rather unlikely. A few with iOS17 not doing their "job"? More likely. 

I have summed it up for asking others how to check / recreate the issue. It is actually not that hard:
- needs two iPhones with different AppleIDs and at least one AirTag, make sure there is internet
- bind the AirTag to one, let it be unknown to the other running iOS17
- turn off bluetooth at the AirTag-iPhone, turn it on at the iOS17-iPhone (via settings, NOT quick options)
- take only the three devices to an area without anyone else interfering (rural)
- watch updates in Find My App on AirTag-iPhone: it will never change

Since the iOS17 is supposed to send whereabout reports to Apple's server this shows that it doesn't. Or the server is not storing the information properly. Or not sending it back out when requested by Find My app. So annoying.

  [2024-03-05T16:12:37Z] @voidsquared: There is no problem on the Apple side. You just need to have latest firmware (2.0.61, check it when you tap serial number in find my app) to have functional tracking. I have tested vanilla fw - works, plenty of reports. I have also tested modified fw with custom pubkey - works, plenty of reports. I guess the magic is in some communication between tag and iphone, but that is a subject of research right now.
  [2024-03-05T16:24:55Z] @biemster: > There is no problem on the Apple side. You just need to have latest firmware (2.0.61, check it when you tap serial number in find my app)

you mean "official AirTag" firmware? If that's the case we should compare what this latest version sends vs older firmware (but I don't own any AirTags :( )
  [2024-03-05T16:54:25Z] @humpataa: > There is no problem on the Apple side. 

I am sure you are wrong. My original AirTags have version 2.0.61 – but apart from that – do you really believe Apple would force every AirTag (and all the clones!) to update to make them work like everyone is expecting?
Besides: how do you update the firmware of original tags anyway?

Have you done the test I wrote above? Please do. And make sure you do it exactly as described.
I am sure that some iOS16 (or even iOS15) at your place is reporting. Nothing to be happy about.

  [2024-03-05T17:31:25Z] @biemster: > Apple would force every AirTag (and all the clones!) to update to make them work like everyone is expecting?

I assumed from the comment that this is an easy procedure, and frankly this wouldn't be the first time a tech firm responds to "my [_insert device_] is not working" with "please press update".

But if your tags are all on 2.0.61 already @humpataa, I'm inclined to believe there are other devices close to @voidsquared that ruined the testing.
  [2024-03-07T08:31:32Z] @humpataa: iOS17.4 update doesn't seem to bring any changes. :roll_eyes: 
  [2024-03-07T10:33:27Z] @isibizi: I think apple has find a away to block cloned tags :(
  [2024-03-07T15:17:53Z] @shiprec: @humpataa the manufacturer was able to get back to me.  They were able to replicate the issue with multiple of their apple approved tags, based on your step by step instructions (thank you)  I am pushing them to notify Apple to see what they say.
  [2024-03-07T15:45:33Z] @isibizi: @shiprec Manufacturer of licensed Tags, or cloned? 
  [2024-03-07T15:51:39Z] @shiprec: @isibizi Manufacturer of licensed tags
  [2024-03-07T16:06:28Z] @humpataa: @shiprec 
 > @humpataa the manufacturer was able to get back to me.

sounds good. what's the name of the company?

  [2024-03-07T16:13:12Z] @shiprec: @humpataa I am not sure I should share that publicly.
  [2024-03-07T16:16:25Z] @humpataa: okay, well let's hope it has some impact. and I hope it's some server side issue, Apple just needs to pull the lever and all will be smooth again ...
  [2024-03-15T13:23:09Z] @supaeasy: > iOS17.4 RC: issue not fixed.
> 
> @shiprec you can use any AppleID for requesting any reports as long as you have the keys. The AppleID (iCloud) is only needed for encryption of traffic, Apple "items" (such as real or fake AirTags) are not bound to a specific AppleID.

Very recently I set up macless-headstack instead of openhaystack so I could throw out the macMini that I was running it on and I can definitely say that this is not true. I accidentally logged into anisette with another AppleID and got error messages when trying to fetch locations even though I correctly imported the .json File with my devices. It went flawlessly after I changed the AppleID account to the one I created the devices with. Actually I thought this should work as you described but can now tell it does not. 
  [2024-03-15T13:36:31Z] @humpataa: are you using the python scripts for requesting reports?
the iCloud_decryptionkey must be created with the AppleID you want to use, of course.

  [2024-03-15T13:42:33Z] @supaeasy: I am using anisette and macless-haystack in docker and I guess it creates the key when I login with an appleID - right? I am not at home so I cannot tell where exactly iCloud_decryptionkey comes into play.
  [2024-03-15T14:03:12Z] @humpataa: I don't know macless / docker version. but I have definitely used different AppleIDs to get reports for the same devices.
  [2024-03-17T11:05:29Z] @humpataa: > @humpataa I am not sure I should share that publicly.

Do you have updates from the company, have they been able to make contact with Apple?
I am still struggling to find an appropriate channel, tried chat, phone, forums, support – all don't seem (want) to be "responsible", cannot answer and cannot forward it to the right address. All my bug reports (feedback) have zero replies as well. Very annoying.

  [2024-03-17T13:47:22Z] @shiprec: @humpataa they said they would send it to Apple and let me know if there is any response.  So far I haven't heard anything.
  [2024-03-18T12:24:26Z] @supaeasy: Could it have something to do with [iOS17 new ability](https://www.cnet.com/tech/mobile/ios-17-lets-you-easily-share-airtags-with-others-heres-how/) to share AirTags? Maybe they changed the way the reports are handled.

  [2024-03-18T13:05:53Z] @Itheras: > Could it have something to do with [iOS17 new ability](https://www.cnet.com/tech/mobile/ios-17-lets-you-easily-share-airtags-with-others-heres-how/) to share AirTags? Maybe they changed the way the reports are handled.
> 
> 
> 
> 

nope. Regular airtag using apple findmy app gets no reports if there is no ios16 device around.
  [2024-03-22T21:07:13Z] @isibizi: iOS 17.4.1 has fixed this issue 
  [2024-03-23T00:08:50Z] @davesenior9: Can confirm, upon updating my iPhone 15 to 17.4.1, I'm immediately getting updates from the device that I've previously received zero updates from.
  [2024-03-23T14:41:13Z] @Systm21: ...our haystacked clonetags are also working normally? 
  [2024-03-23T14:44:27Z] @Itheras: Everything is back to normal. but I believe something is being done differently with the status bit ios side but take it with a grain of salt i need to dig deeper. But yes everything is reporting again.
  [2024-03-23T14:52:39Z] @isibizi: > ...our haystacked clonetags are also working normally?

Yes it should working to. 
  [2024-03-23T17:33:16Z] @humpataa: > Can confirm, upon updating my iPhone 15 to 17.4.1, I'm immediately getting updates from the device that I've previously received zero updates from.

Same here: it really looks good since yesterday, however, I have the feeling that older devices (iOS < 16.7.6) still report quicker and more reliable?! But working again finally! 😍

Tested with 2 original AirTags, 2 official clones and several fake tags (status byte fully used, hint byte correctly set) – all fine.

There is an update for iOS16 as well, fixing the issue too I believe. Still waiting for technical details of the update, guess Apple is waiting for the rollout to reach enough people before sharing details.

  [2024-07-25T19:56:11Z] @Cassander313: Does anyone notice if this issue has now come back up since the new 17.5.1 role out in terms of detecting tags.
  [2024-08-01T17:29:05Z] @69888: > Does anyone notice if this issue has now come back up since the new 17.5.1 role out in terms of detecting tags.

Can confirm, i'm on 17.6 and no report appears with the original HCI.py, i'm trying with the one from the PR but i had to patch it further more since it couldn't change ble addr

  [2024-08-01T18:46:28Z] @69888: > > Does anyone notice if this issue has now come back up since the new 17.5.1 role out in terms of detecting tags.
> 
> Can confirm, i'm on 17.6 and no report appears with the original HCI.py, i'm trying with the one from the PR but i had to patch it further more since it couldn't change ble addr

ok i managed to fix it (?) but idk how reliable this is, also it's very device specific and i dont know which edits are necessary.

gist url: https://gist.github.com/doggyhaha/37e61a03a07868942f64c343b29766c2
also had to build bdaddr ([this one](https://github.com/thxomas/bdaddr) since bluez didn't have it included)

i run it with python HCI_fix.py -k "ADV_KEY" -i 33 (as root)
i used [this script](https://github.com/malmeloo/FindMy.py/blob/main/examples/fetch_reports_async.py) to get results
and used [this script](https://github.com/biemster/FindMy/blob/main/generate_keys.py) to generate the keys

i didn't try any other combination/script, i have an iphone 15 with ios 16, if i understood correctly the problem what that HCI.py couldn't change the MAC address on my device

########## biemster/FindMy #86 ##########
TITLE: Ideas about the 5th byte (if len = 89)
STATE:open CREATED:2025-08-24T21:06:55Z CLOSED:null USER:@sonman
--BODY--
For some reason Apple introduced a year ago an extra 5th byte into the location report (see [52](https://github.com/biemster/FindMy/issues/52). 
In my cases it is always 0x00. 

Any other observations ? Do you have an idea for what this byte is for ? 
  [2026-01-31T16:15:10Z] @fz6: I looked back over ~40k reports for something else today, FWIW I have 16k 88-byte reports and 26k 89 byte reports. The extra byte is always 0x00 for me too.

########## biemster/FindMy #92 ##########
TITLE: Location not Update in FindMy (update in GoogleFindMyTools)
STATE:closed CREATED:2025-12-04T16:26:40Z CLOSED:2025-12-04T17:22:35Z USER:@driagi
--BODY--






The position is not updated. If I open the Android Find Hub app and check where the tag is, then it also updates in HA. The current position shown in HA is several kilometers away from the real one. GoogleFindMyTools remains updated, while FindMy does not update.

FindMy version 1.7
  [2025-12-04T17:22:35Z] @biemster: This seems to all be about the Google Find My Device Network, this repository is an implementation to query Apple's network. You probably want to reopen this ticket in https://github.com/leonboe1/GoogleFindMyTools.
  [2025-12-04T19:06:20Z] @driagi: Sorry, I used the wrong link.

########## biemster/FindMy #94 ##########
TITLE: request response missing key "datePublished"
STATE:open CREATED:2026-03-14T08:08:42Z CLOSED:null USER:@jl-jung
--BODY--
The `datePublished` field in the response from Apple’s server has been missing for the past few days.

`Example response item:
{
  "payload": "L1xAWwACBGGyF5qhmCL+SOqbcHSHez/n/E6tLNEAdAKqVveUhNM2QuxuWctMkpnbPTSuewQ87uBanZTJj5aS5SO4kc9rSlOYrPoWPqykajL7YDwMUoJn+ck=",
  "description": "found",
  "id": "Kx50+DDKWa1wdAlvJ6m2ONUjEOiS2dfXFVzv0UF+5fA=",
  "statusCode": 0
}`

This makes it impossible to determine or display the “last seen” date and time. 
Has anyone found a solution for this?

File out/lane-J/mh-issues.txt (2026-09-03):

############ macless-haystack #219 ############
TITLE: Apple's new fetch api often returns empty string now since one or two days ago, even http status code is '200'
STATE: open  CREATED: 2025-09-28T02:20:38Z  CLOSED: null
USER: lovelyelfpop
---BODY---
`https://gateway.icloud.com/findmyservice/v2/fetch`

I can't get much location reports now, since half of my requests get empty responses
  [2025-09-28T02:55:53Z] @lovelyelfpop: Linked https://github.com/biemster/FindMy/issues/88

############ macless-haystack #213 ############
TITLE: Why localhost no update location When not reload web
STATE: open  CREATED: 2025-08-07T01:09:20Z  CLOSED: null
USER: josephBoonrawd
---BODY---
My localhost web no update when I don't reload web
How to fix?

############ macless-haystack #229 ############
TITLE: Error message: Account limit reached.
STATE: open  CREATED: 2026-01-27T23:31:36Z  CLOSED: null
USER: aarontrom
---BODY---
Hey folks, 

my problem is that I can't register the device after login at Apple. Basically I'm at step which is about the [server setup](https://github.com/dchristl/macless-haystack?tab=readme-ov-file#server-setup)

> 3. Start and set up your Macless Haystack endpoint in interactive mode:

and exactly [here](https://github.com/dchristl/macless-haystack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) I can enter an Apple-ID, my password, get the 2FA code on my phone and type it in, but then Apple says either `"Error message: Account limit reached."` or I also did see: `"It seems your account score is not high enough. Log in to https://appleid.apple.com/ and add your credit card (nothing will be charged) or additional data to increase it."` 

**I've tried several accounts with genuine iOS devices and credit card information and other information added, but Apple refuses to connect. So I wonder if this step also fails for others?**

Here's the log: 

```
sudo docker run -it --restart unless-stopped --name macless-haystack -p 6176:6176 --volume mh_data:/app/endpoint/data --network mh-network christld/macless-haystack
remote: Enumerating objects: 242, done.
remote: Counting objects: 100% (50/50), done.
remote: Compressing objects: 100% (6/6), done.
remote: Total 242 (delta 44), reused 44 (delta 44), pack-reused 192 (from 2)
Receiving objects: 100% (242/242), 50.66 KiB | 551.00 KiB/s, done.
Resolving deltas: 100% (112/112), completed with 12 local objects.
From https://github.com/dchristl/macless-haystack
 * branch            main       -> FETCH_HEAD
   a284a9b..f847f2e  main       -> origin/main
2026-01-27 22:32:06,545 - INFO - Checking if Anisette http://anisette:6969 is reachable
2026-01-27 22:32:06,622 - INFO - Searching for token at /app/endpoint/data/auth.json
2026-01-27 22:32:06,624 - INFO - No auth-token found.
2026-01-27 22:32:06,625 - INFO - Trying to register new device.
2026-01-27 22:32:06,628 - INFO - Trying to login

Apple ID: **MYAPPLEIDHERE**
Password: 
2026-01-27 22:32:37,260 - INFO - Authentication request initialization
2026-01-27 22:32:38,685 - DEBUG - HTTP-Code: 200
<?xml version="1.0" encoding="UTF-8"?>
<!DOCTYPE plist PUBLIC "-//Apple//DTD PLIST 1.0//EN" "http://www.apple.com/DTDs/PropertyList-1.0.dtd">
<plist version="1.0">
<dict>
    <key>Response</key>
    <dict>
        <key>Status</key>
        <dict>
            <key>hsc</key>
            <integer>200</integer>
            <key>ed</key>
            <string></string>
            <key>ec</key>
            <integer>0</integer>
            <key>em</key>
            <string></string>
            <key>ptxid</key>
            <string>6f375ce8-cb4c-452c-9bf5-41269825059c</string>
            <key>rsh</key>
            <false/>
        </dict>
        <key>i</key>
        <integer>20334</integer>
        <key>s</key>
        <data>jnCm5wH3KQ+3SXgg2Y8J8g==</data>
        <key>sp</key>
        <string>s2k</string>
        <key>ptxid</key>
        <string>6f375ce8-cb4c-452c-9bf5-41269825059c</string>
        <key>c</key>
        <string>i-9b-15c7a4c6-fbd0-11f0-8277-174e5b293b4e:PRN</string>
        <key>B</key>
        <data>gT9CcpQvsFuTM7uL+D63jq4Gyxx1ZdLJ6DDcZ7WQ04utPG9eVKv9ndgqyeQxOkS8IqVaqBIqmI+wJnHRUaNjU0upV/n/45fJQUGoBxn/rP0gabrxIQ3O3ahtXZ/dQaPDye4AW1VmNff/7xLy1UewB5w2E09dx4+ZnlLkzXGDC/BCJP4d2BMp8/5ElZS4/GZ5lnNhLvl67svWbKlor6PrOQHdEJ708E4+3TwwPP3FUNACaQUF39DeWOISLodYWdYiHxEXZHdrytPxa7PnSxf9gyNXxS3P8BcekMyvCEgae7CD+4tx+yDoAR25pIg6ZYUQsNLodcOfoGGfoRJTP8edkQ==</data>
    </dict>
    <key>Header</key>
    <dict>
    </dict>
</dict>
</plist>

2026-01-27 22:32:52,134 - INFO - Authentication request completion
2026-01-27 22:32:53,413 - DEBUG - HTTP-Code: 200
<?xml version="1.0" encoding="UTF-8"?>
<!DOCTYPE plist PUBLIC "-//Apple//DTD PLIST 1.0//EN" "http://www.apple.com/DTDs/PropertyList-1.0.dtd">
<plist version="1.0">
<dict>
    <key>Response</key>
    <dict>
        <key>Status</key>
        <dict>
            <key>hsc</key>
            <integer>200</integer>
            <key>ed</key>
            <string></string>
            <key>ec</key>
            <integer>0</integer>
            <key>em</key>
            <string></string>
            <key>ptxid</key>
            <string>fbe0758a-1437-471e-badc-dfc4d2cb2218</string>
            <key>rsh</key>
            <false/>
        </dict>
        <key>spd</key>
        <data>4vr4cIuPn7mbuWFJT+q7NIIM575wcFV9RMWo2vjMDHzzNg5BC7OrcOg+Re6VH8iLPJvW7SBbGYzPswvHEyhvpyfw9tc8yKpNdYEnoWgXrGzJDCGHO6LrQ/mIZq2oGvE1y6wXrtwxVSI/T7VbBC+k/6rKinrWV1sgo/qRc3EY2/nu6dPer91vb1NXSwhB6SQIq7pp9Osv+IjYuR6Z+7M3Dfyb7ou0WqVJfbavKOui2wBFbWgFiyszntqziT8UK7gMjM4upWc1K9F9lCD3S9DkLqB5rVW1AuHFNc/uLuZFUf7o219FPy0FgZrvXNgQlYvzV9xdexTg/49drxAecgjgaA1ogUvHbpL9U0xZ3LmazUoBbgzJ/Ug9uDTpOkpUEyzFX/L4QTD54WR+V9EXZW/q6B5KKt10gvvSC05VW0XpMGsbvW7gVCsKGsAbBHvvRpxR8vBSl3vKp1i7M/wCjEuH/cWPZ4oLdsA77Gvibvuu/cvFVqHtYXk8F+rUWMivl0KyoCHtOrPddboJ0vmcEOdCjwGuYeX4p/8LLGkn01IGLGKVg6izAwp8wrC3sVjdCZmQRz8lV86M7UrEDAvlMCedRGiv+TrdMTYDRRbgUwGSpZg90ZXJTm+Ut3fL9lucLHonSd6Ee16AEV/KK8dec18jFiUaOGw5rqBTibymXExcgbisZXCoUwiuKB7SL10+5UB/4dFmR/R1xufRiuLMfPnePC6wk+uSiFch2z/EI6PkiG4wU5yuZE/M3l5tbL6mmYkSnQgWLpYQvhIurO/zhMgytzxNEdTqdDgP+ujo0MYJvzXVaMKzzzqX23La7D+JaR9HHGj1fBD6c/bnPDMRjBilj2RSYxaBZUAvgi9W95F/UFSWIY3A+cYHN8JwoualFrFaN4V3ykSr/eoZwtnG1SXsuOey299tq0Kp2guEA5O7R6qJZMNnHdBys9o+kyBWZ8J44GdqknzvKoqbawETjRLRz/BMNBlZicAIIJkkOjSU3Va4mHBtvqVhHX/jyl6nJs8Jh8o/5d6ILC1td6hLIOWvtgXPrsNc/12oCWo6kV8mMw+nlM4NsmpyZxxSEomolYNmXE80VtaejSP5Ay4xGGMVXXajd2VpyW3rm3mwSQ0L84ewpqscjw3BJPdYnWj755RtYcST4NZSKC7iSJ6eMGxwVhSxHBfHWdq4ZKt/+MNHIk0Jir3A1HU5Zzpk/Xox23E30e+82pbULcLJhPHmATIbg2dp+z3yOvSFl/AbUZ6ze/ri37WTAd1xbHK8fVzqxIC4MKYYnG+WCC7tHFvsK/Lf2cZyzGmPb2PkPlKybwelUlTqmsv7bA4UnxXCqfhajlY6h7L7868bgFfK4kcYLVWz8d9LXRjB21XUdQR0arqFebyF4IHZ6C96r8lDeM/SslI9BmaR1VryvF2Obq+nSdUDX4l6phlNFfpC4+kaYHukOLjbERkdTHOV37y2ub5igjW/jkYDDJjzFrBO/FHZv5FoSJQHkuaTkie9wuzKyB433t2RngN10ble8w+psvoJMu6yd1GlcnTQ+/TSo0MxNgs+9a0j7HlVedUWfGPRoRTNzkTBoNqK4dH+WBLzhBHTqSW6htQZAmQ2H9Yb/HihhM9tW5RHas2BTgdP3XPtEgiIY/NSTM7j1f/wDy8e43+LBMbbx5+SBl8gVRy3EyVddvIpge6Zu6GLCG3HPGp4DDF5uD+Djiqzlg9gpa7iNgTCumgxKT9r7xYuRj/5cc4XxZzpR00CIsEh9SA2WOntE2pm9B/eVdruSyBseNAyVkKhzM7jVxVLYRbjin7E3BlaYcTbmuDyPToKvfWJeZephZdCVPhKs8vNCU2+GxU8bANOEmM/M25UzEgMTFrXZIZyfYqfmbag04w1wL/NR61d4bGw+0Pbm0rPe6sl2IXSsfjvMUA0LeXheUVLxUbLfDPQJnT4asHIqy4k7naJkAydL+hzEOgLtbgA+gHso4ANvc0abmoxos61xNH+0tcKghIZBZR4EqVJD3/F+0/nh74nFUFYnDhCwWF3kY5cDPh2v6AKuBF+w5TUzS1g2xqtn3Oe45p6xiHXWmlj+EIdz+lG41QQuHkvRCbiUZMlHoAE4t3F78qgxlLhEgj1pFAc1mpOtLQeNnkHvcCjwFlrH7Xgd8O1F/twWuAI0o91Dkk9ytBLct8HXx8QGvXXGQfIYhz3HN92PH13FsgeDvLng8e2Bw8tWBd6HWhZKUdDV7E4f1D05oh4y25RUgK93IDdCRkIgybSEwIFZ4NivxvxFLKrdfAtDUYoldD1D3IyFmK50DzQu06Vbiojrp5aDiwltWG0bYDwLxyJ3zpoUA42AmO3w4NGq9kVz1O0bB1Z9u+oF1z1q3O+57Q5eW4ua2vNLfO0Ug3WknSOAnpKMJBQkcoSP7XvJY8BQ6l4v6uEM6aHgE4z7Ajh4rLuw10IcgKUaEkrhPn1WThO2KAsWyzREAsbTNhAXHOa/HJudmM0/NIbToeiyBShJpNC8jHzAd4M5N2HQ43XFDtKzfmM85qQQPaCkCI9XYogzZ9IyVFKyDCfY+XQTLBvcjajAbqJF/canf91xCnPNWEY9YiKw2X9uu1+izWvAXd/Ujd0pyHA6djHHecPdNkbiM96yIcxpiu3RlApAW+h7JqAvLDtCPWfoxdYYoZt1ax6+mVUNefm/pKvMkJtFHOSplLXb8m40MECXkNgGvsZaEZfcMZ8HF7zwUz4xqMAtlmmjN39UiDEbURPUxCdtZwFCjmAjf8UOqJbQft7BL6iu32YDQIlYzh2YBRjWTSLsNziPXT71WwwUXVVIz6JpipJAnsAhJ9RFo3wny0SnfdpY4y4cPjxBmoXsORoVfxRH7umSDR/seECZ0iZYuk80wfeR1yIuEXo8gjDAZ0MWo2IcRumHi0msqSOxZMf/yYOD5J+ZGuJ0FsWfB16FDNTb0Ta/LWlF+09HCv8I7EAa6skc5CsPA7xAKVfMjQ+g9+O7TGC6jVSsYUwWCY7QvqhfqyvqgJFa8ZMG2O2fMX+WnKq3UDejlqxjCFLZ/tVq86n4u6WYaQ4vNI6TmyW8JxR00jK/6fWP3D907/5bCu/MSNuFqt4jwmcdq3Uer9ens34KQiq/G/FgRCYoIKSN327YEnpSjZrt8LoiYJi/f97p+/dFzNzTWw7oYxbzqox613HOa4OuDNUlhjJO1qWjbC34ph36yEXsreK5miRvx2QrSx7JlTyJsr+cY2C6M4sFTMudHklurB1lDNgtxa2AfyIPvjuu4yq9VNy9U7qml4QzsPwV0tVPAzTUTcWipWp/AAPHXxQ6N0Eabjoa0ynbiDO12zPVmoYX5D/wD2fqWiZiOY/D8TP300sww5Fn8HOt+TY4EnrmzlEAClSnOP+txSdCPmRjK8dyopgSxOvUJiqTcCCwZhJYIS0ey+eqh3vbmsIGkImdI+xXHxySQ6+ja/jBrfSIxMetBYJtjlJbgvyTUk1dDZkdtkh2PO/5J969kx3DZzfcl3AF3VKfBY7hV0HxQmBZ5CvBaYZjkEEcV8wn64S/SIDWNIjlKKXjECWXrtqPWLY0pUCUm9iernLPkvpzBa8sdSDJwfURkzEUexi8kfZDr/F8OgR3E0ep/FKA0kHAlKRA3Pld4g5Hc01bcvx01BHVoe/Y6Ok0M90tmMq5elZqCCERuVxx+1ETNoY0vislbxEGWcWG4gLfOlNjdYYxBwUoehzCCP9Ech7x8Ngvx7TEuYBcLczcQmYFgu98gwg6ScCI5c6efWl19pI4rtDH7za6fK1euHniTh+QR7av1THXYS1aM+82ZEf3jnsXrgqenS7GusVRc/9mWb40isri6CFhK5cftrxSqcPywSNRL5RnrwKReKUCWX/9koadOK38qXR0LhlWVrMcAxybvD+icoR6bN9kYH2cp0+WuUBZ6QeX/GEWnBpl3FYdMhFOgiUzQDcAVqgH4oY3e1/YzP7VeHXEj8Y36zTp8P/iSzMcyAaKD5HNYkgj+ip9CGK5IEh0ZOG7USrrH12IIWkRl9du6K4eb3bTtKE/oIirTSxP38swu9jjudS+/OxEVobKb/jt1ltPs8J+sA81W0sT/HlmocqEDj6fdrFoh25C1Z0O4Ev1FZExcbKnBTI/iDgSXc3B+P3oMj/G2ieP9zhlCHDWqrvip0vzj7z8zURK5WBbxF8fs7dCRq0I0AKf79NmR3FtXmQw9omLFPDkfhJSC2xjEs7Shu5M/Orbk8U20nkOc4/iRRZupVWAQBTAmAWJbEB51lwuNxM9fNPZbjwx/AX4ws76gAamX9NTcGtSqSvrjVfQNaUA+ypsExVXlDddGrKRhUEny0lFtO5c0I3LcqsU2PKqaLywZnAt/Vmxo3avEW1pAKkgOptzv0g0rDi/EgnTRcNpidor5XTCKuiG4ccksPRLY3NJWiR2ZCVkydji/h6A2pJk/Q/rwTxydyD0NvR7S/9iLF9uE2B5Az0Ef9h7VOg3QMyEPbqEOXZItIo5nNgI9hwNtKZOySNUP1oL7j8PVlJgJwxrcB70kqFGA2AWKZXg0oQnuWQPgyvJyGGhRXVL/muTM3dwSYAO64XlUipQwWs1IQrWiFty35NJogYSvlJZn3Uzg/onnXtlXL0I+8AfaHO3lAR2VpMFV9ExPY4AAQEESs8wASNeLnsw1CAffs96mCHLurtNv+UBGqVBI47sEqbkjPgOccKpyBMmFSkiJw7Cgc/OUkcMk4dpnEMCgcSCs5mhXuaWlRQ2pdgXPxeA1b7mihxi3KUCZbgdolSMHJo2cfyvg5c8M6ih3VhZZxV+fBGSxYwxstPFPvP7Cx+RlA1IhkdgPP6y4mV7g2HBUAbmnjzAFjzwJzahEc7s98kutL+gyKWF6yqgAf12FQrxRRrRRqx5pFql4JnFJd1ef7njDG/xBeManimut91GYk1i6qbKBJD120GqIWqO5BsMuwhxCruRj1h+NvwAKHwPt3AnyOhz7x2Ok9xXwhbggLji9xiJXIkf2PlRjMLHVONZODtekVzORA+3E8ny6xYHKJnWutFcJzTwCD7tr8BnoQLhpuXffyc4yzRhNsMx82gVFkEv+6kCer/FA8EjlimZwmtV4bYjAQzkwoiaMi4Q1Cm8BQl4jp7Bg433j7GdXAwjX1gJkOGjjbwVSPQ5AORHZ/C0K+8wfX3ETTuhg/B4oHQ0DQuyK3c/pKCviQgW4OuM8P1+qTi7jB8qVo5UiZMuOXvJduGwLU/IFYu/pAI8XwW7LoZMe8KHCr8kcIQFRoI2GHhn8dLF9dwMZyaSIGOLud4RTxuMXIaBw+ZAzxJXLJNH2bH9KEJ80m11zKMeiU9rk/nd0W+dZMec0VZZU0zWp3oe2Sbny8382t1bJlVJAn8f5zL8LpUU6OjgOsY+hOeF8kMhBMLyPxBZnbJC7br/jJBN/ggaobnbXhVkaJp01yRQMvAsfC0Zn5YwujH5rZLkG9EBIs6Ph6Ooml2nOKjZzSbFBi+/bbJe9r7/6Phz2GCFSF+uKsV2jRQU5BpBRia+YdL8y9DcMzxRnS8EYoWQIuFAwac6DoH/7+zVZn4OaW3wcbxwMf6i7xZDHNMWhWFYjmhfMz6bmxvTQkmpk5DvwIh5nD51tg4Vd9HvIn5OYLMZ3XdidUBXq22Y01fJd3/CubNoIpHvg++fWc095V3dNfwC/+qLh1WdhZoR9dRnbnztTE96hbYjXMw/neKHpI+MADzFPVYHVI5UYskYze91GYlap7GBLmVakifWRgE0yY/RR1NECfXxLv0kJq4IU6p8zJL0r4BHFmyZA8WmHy8nF8BSIhoA8+MiR0CsSDcd887MnIhQ6J7B851ktp9U3sfsaRdky1KJN9LCfB2lUhgBbn0a5/iDOHLO2IMapn2JjVoC2Wt0BLS+EnwIfGl4hdUe0KLfT7SatJK8xNm4GDCUaefEcP8TrB2iAqu2+C5bKR4mqQYuL/MBsjbvMbhHiIv7WG+absKyrgE1PaaW9gzxYFOmgk+bEV0c+x0ZYP4xIXzkh6ub17KvIHL9N+dPPw6VcK8igvnYE/tDscchP0v0Fm95CzZ1z3xwEirLxtlPcJyS6V0cD8xhXmVB4XbW8JMsDGK
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

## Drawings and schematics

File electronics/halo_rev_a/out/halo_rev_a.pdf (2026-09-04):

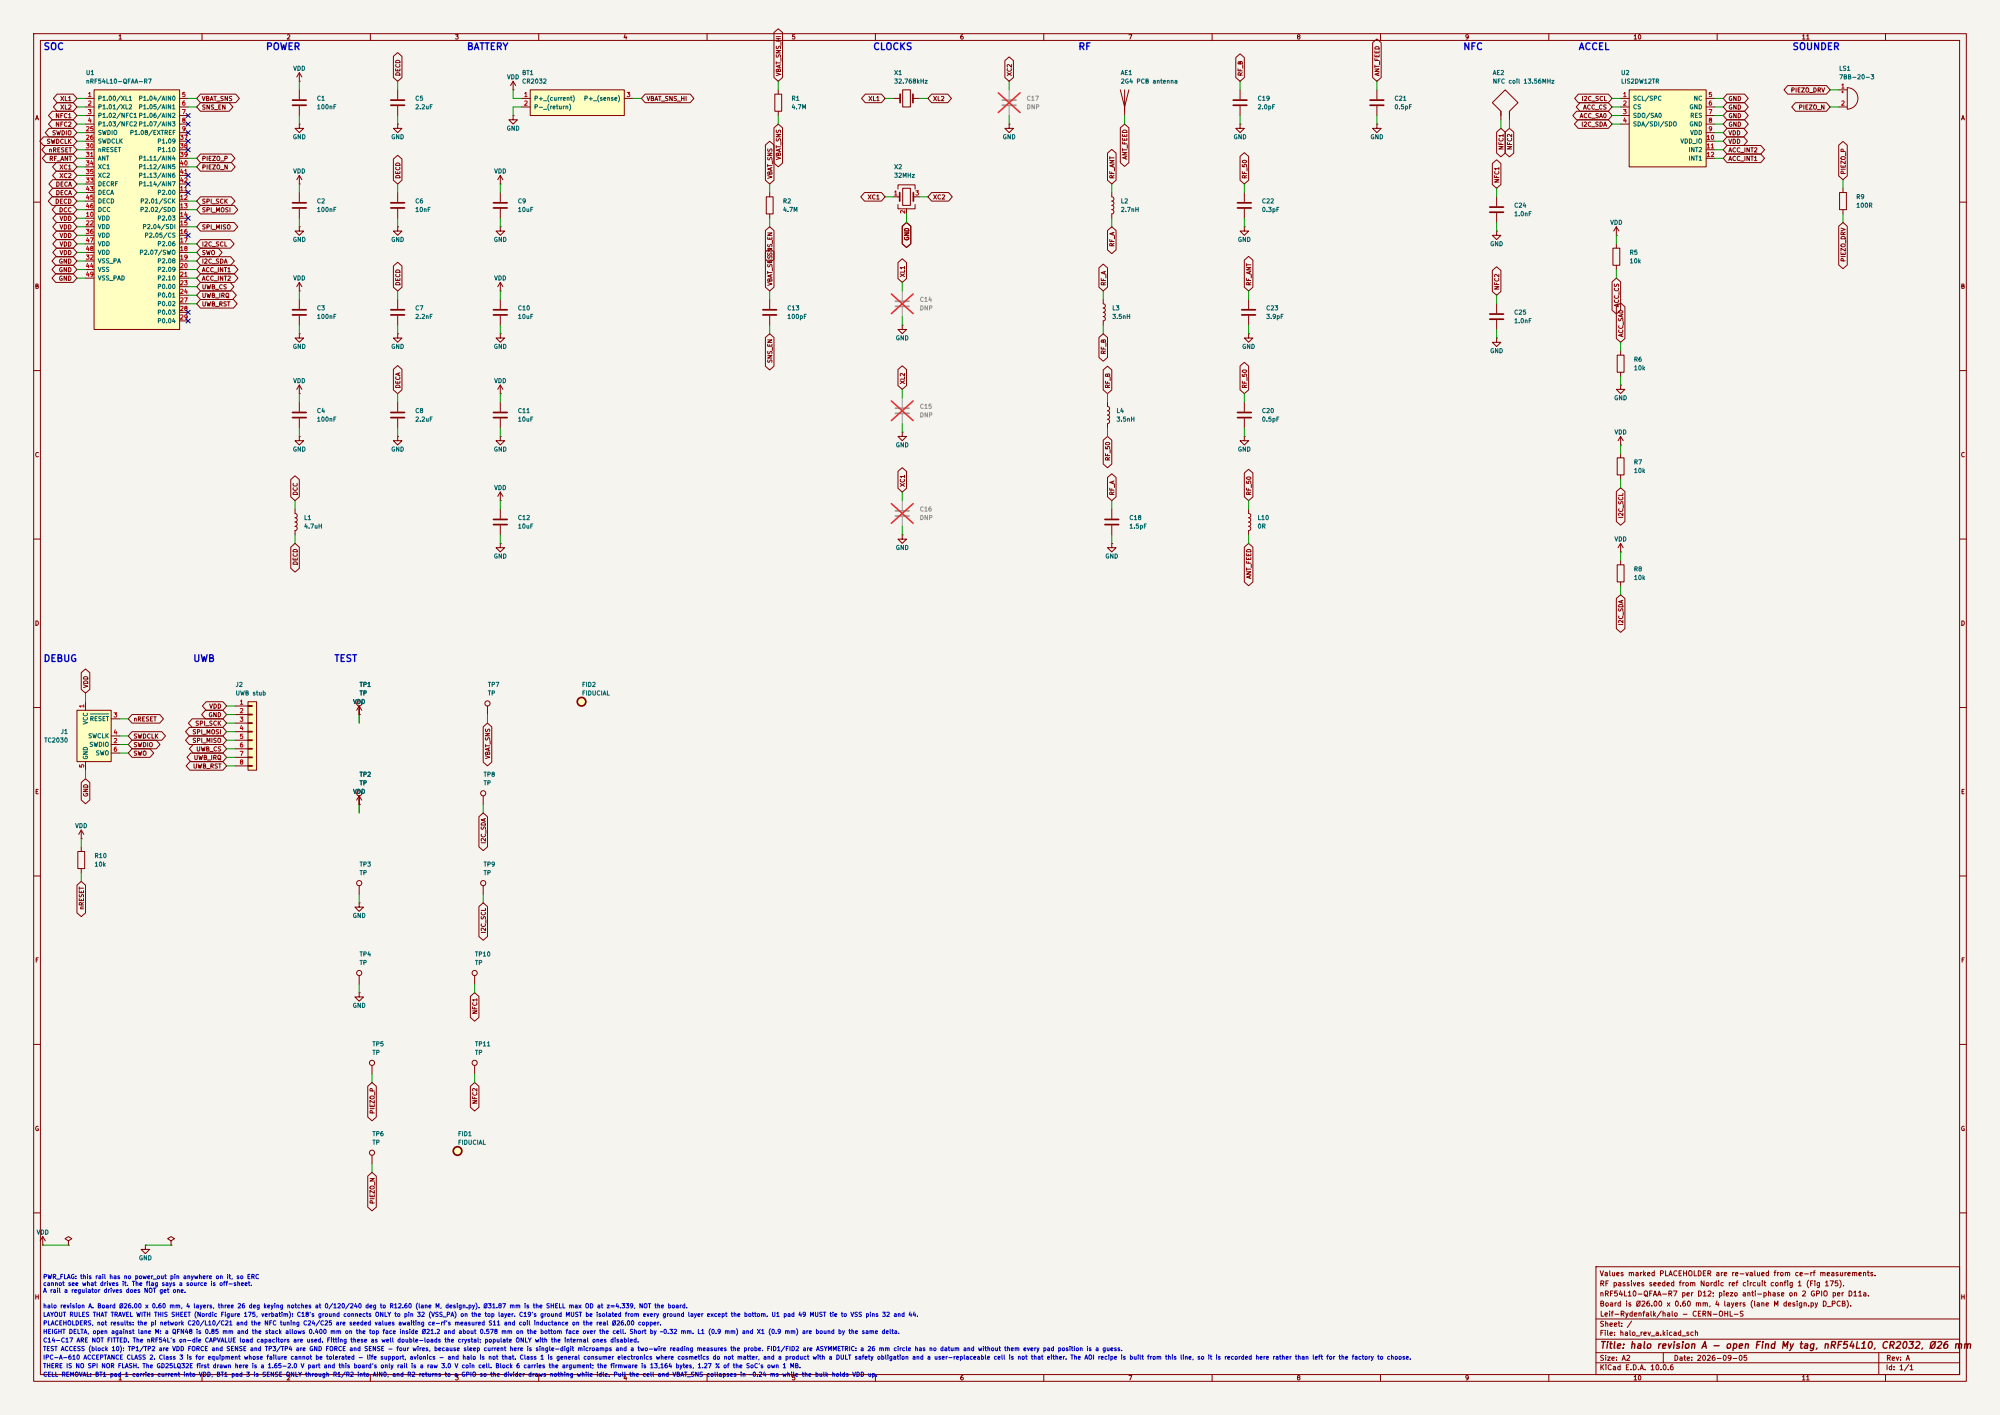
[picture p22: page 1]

PWR_FLAG: this rail has no power_out pin anywhere on it, so ERC
cannot see what drives it. The flag says a source is off-sheet. A rail a regulator drives does NOT get one.

Values marked PLACEHOLDER are re-valued from ce-rf measurements.
RF passives seeded from Nordic ref circuit config 1 (Fig 175).
nRF54L10-QFAA-R7 per D12; piezo anti-phase on 2 GPIO per D11a.
Board is Ø26.00 x 0.60 mm, 4 layers (lane M design.py D_PCB).
Leif-Rydenfalk/halo - CERN-OHL-S
Sheet: /
File: halo_rev_a.kicad_sch
Title: halo revision A - open Find My tag, nRF54L10, CR2032, Ø26 mm

IPC-A-610 ACCEPTANCE CLASS 2. Class 3 is for equipment whose failure cannot be tolerated - life support, avionics - and halo is not that. Class 1 is general consumer electronics where cosmetics do not matter, and a product with a DULT safety obligation and a user-replaceable cell is not that either. The AOI recipe is built from this line, so it is recorded here rather than left for the factory to choose. TEST ACCESS (block 10): TP1/TP2 are VDD FORCE and SENSE and TP3/TP4 are GND FORCE and SENSE - four wires, because sleep current here is single-digit microamps and a two-wire reading measures the probe. FID1/FID2 are ASYMMETRIC: a 26 mm circle has no datum and without them every pad position is a guess. HEIGHT DELTA, open against lane M: a QFN48 is 0.85 mm and the stack allows 0.400 mm on the top face inside Ø21.2 and about 0.578 mm on the bottom face over the cell. Short by ~0.32 mm. L1 (0.9 mm) and X1 (0.9 mm) are bound by the same delta. LAYOUT RULES THAT TRAVEL WITH THIS SHEET (Nordic Figure 175, verbatim): C18's ground connects ONLY to pin 32 (VSS_PA) on the top layer. C19's ground MUST be isolated from every ground layer except the bottom. U1 pad 49 MUST tie to VSS pins 32 and 44. THERE IS NO SPI NOR FLASH. The GD25LQ32E first drawn here is a 1.65-2.0 V part and this board's only rail is a raw 3.0 V coin cell. Block 6 carries the argument; the firmware is 13,164 bytes, 1.27 % of the SoC's own 1 MB. C14-C17 ARE NOT FITTED. The nRF54L's on-die CAPVALUE load capacitors are used. Fitting these as well double-loads the crystal; populate ONLY with the internal ones disabled. PLACEHOLDERS, not results: the pi network C20/L10/C21 and the NFC tuning C24/C25 are seeded values awaiting ce-rf's measured S11 and coil inductance on the real Ø26.00 copper. halo revision A. Board Ø26.00 x 0.60 mm, 4 layers, three 26 deg keying notches at 0/120/240 deg to R12.60 (lane M, design.py). Ø31.87 mm is the SHELL max OD at z=4.339, NOT the board.

Size: A2 | Rev: A
KiCad E.D.A. 10.0.6 | Id: 1/1

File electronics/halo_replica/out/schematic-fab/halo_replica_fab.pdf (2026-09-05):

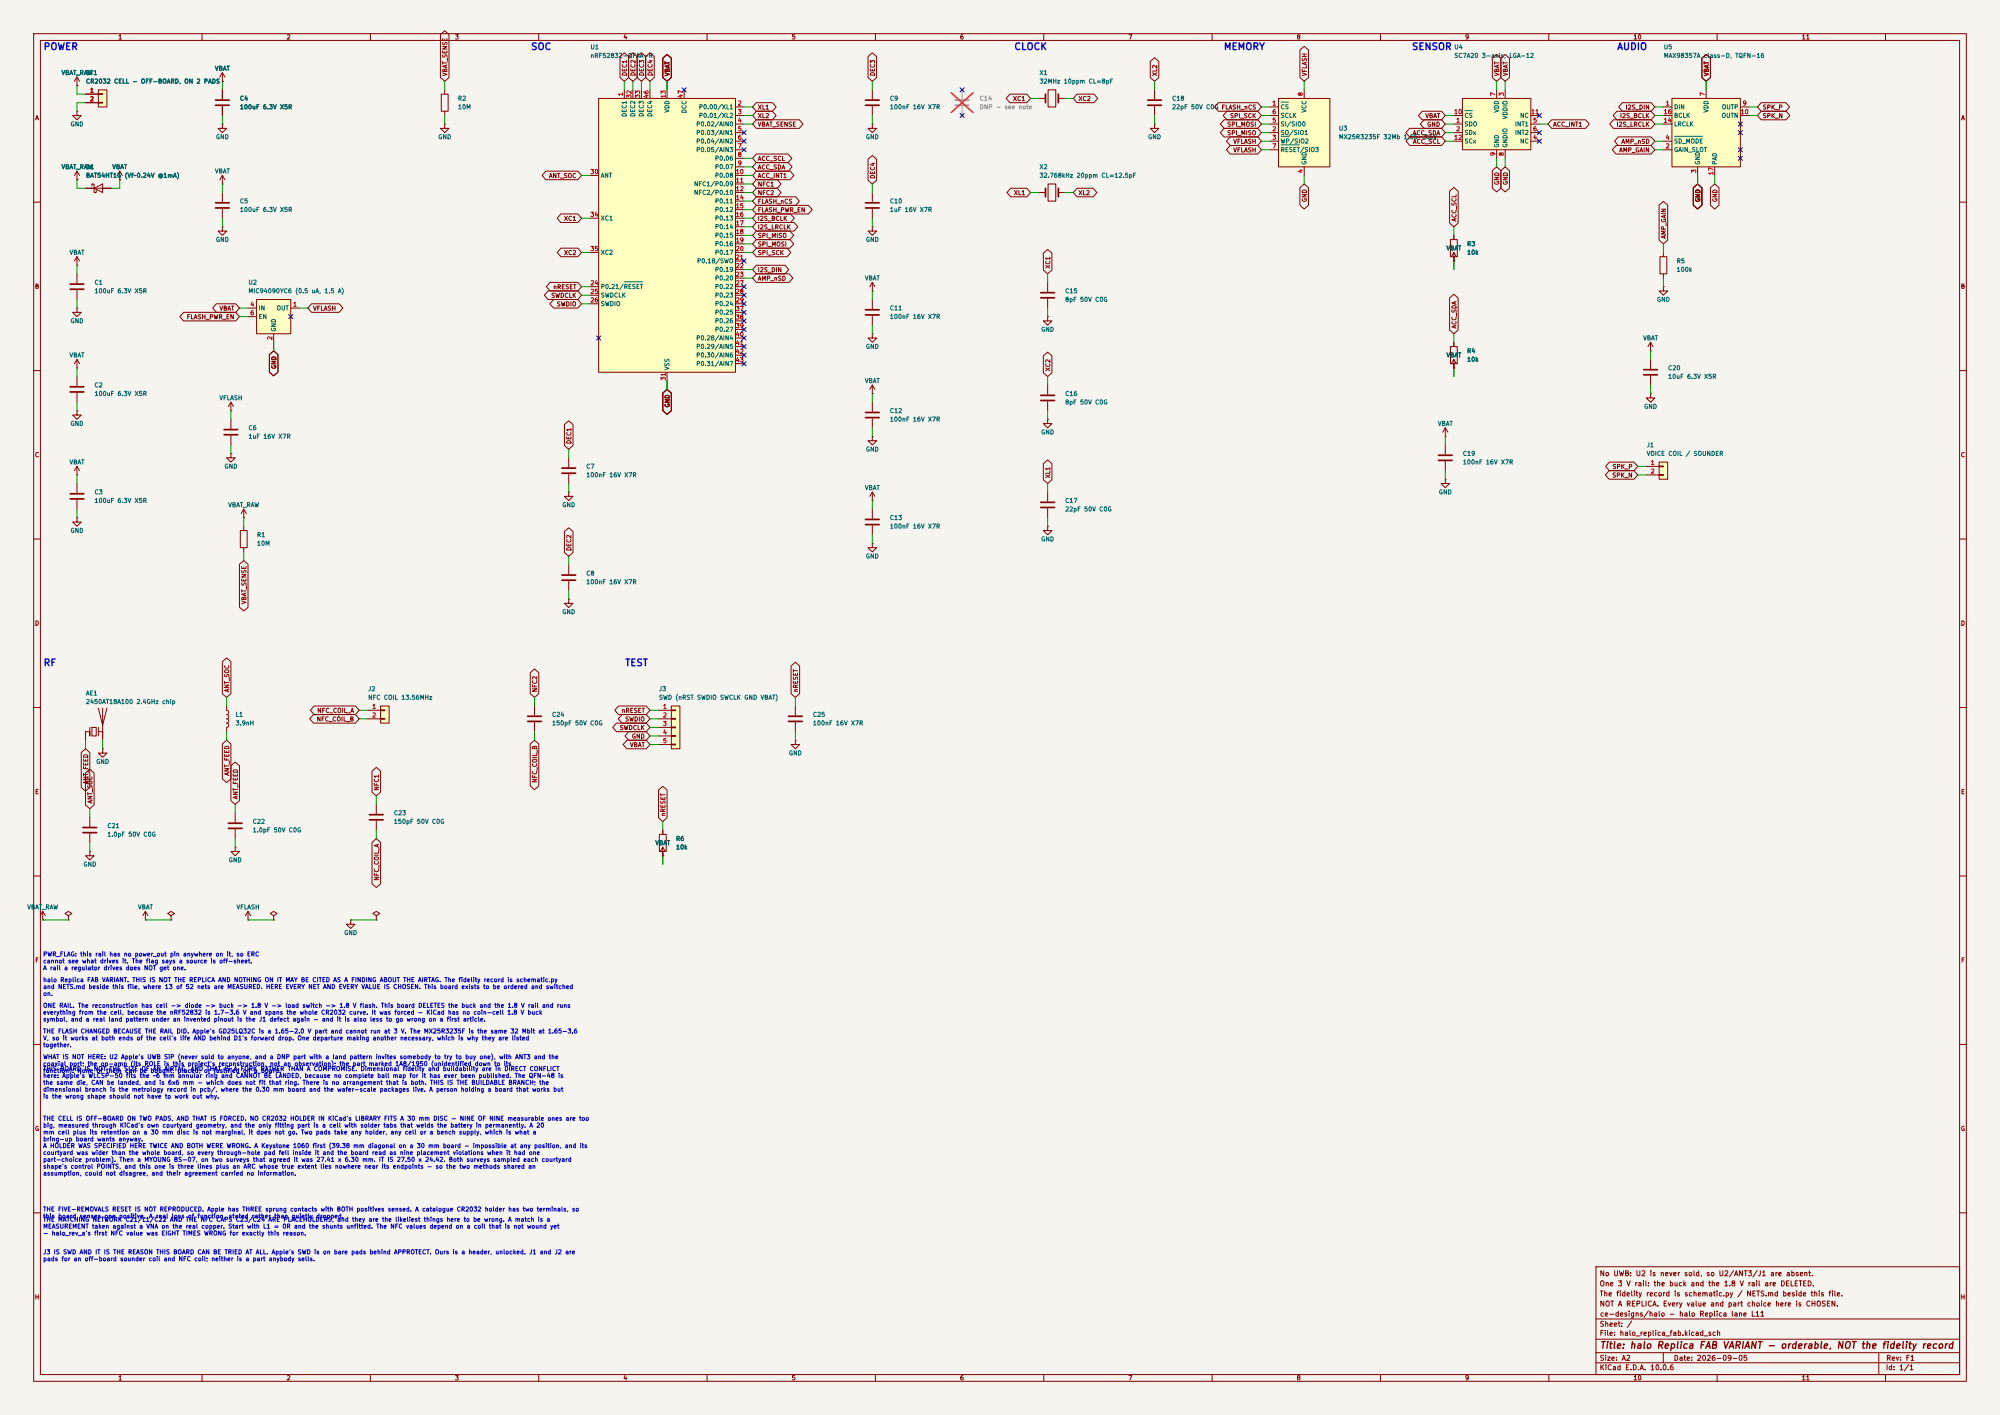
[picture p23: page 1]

VBAT_RAWBT1 CR2032 CELL - OFF-BOARD, ON 2 PADS

SWD (nRST SWDIO SWCLK GND VBAT) C24

PWR_FLAG: this rail has no power_out pin anywhere on it, so ERC
FGH
cannot see what drives it. The flag says a source is off-sheet. A rail a regulator drives does NOT get one. THE FLASH CHANGED BECAUSE THE RAIL DID. Apple's GD25LQ32C is a 1.65-2.0 V part and cannot run at 3 V. The MX25R3235F is the same 32 Mbit at 1.65-3.6

symbol, and a real land pattern under an invented pinout is the J1 defect again - and it is also less to go wrong on a first article. halo Replica FAB VARIANT. THIS IS NOT THE REPLICA AND NOTHING ON IT MAY BE CITED AS A FINDING ABOUT THE AIRTAG. The fidelity record is schematic.py and NETS.md beside this file, where 13 of 52 nets are MEASURED. HERE EVERY NET AND EVERY VALUE IS CHOSEN. This board exists to be ordered and switched

on. A HOLDER WAS SPECIFIED HERE TWICE AND BOTH WERE WRONG. A Keystone 1060 first (39.38 mm diagonal on a 30 mm board - impossible at any position, and its courtyard was wider than the whole board, so every through-hole pad fell inside it and the board read as nine placement violations when it had one part-choice problem). Then a MYOUNG BS-07, on two surveys that agreed it was 27.41 x 6.30 mm. IT IS 27.50 x 24.42. Both surveys sampled each courtyard

bring-up board wants anyway. ONE RAIL. The reconstruction has cell -> diode -> buck -> 1.8 V -> load switch -> 1.8 V flash. This board DELETES the buck and the 1.8 V rail and runs everything from the cell, because the nRF52832 is 1.7-3.6 V and spans the whole CR2032 curve. It was forced - KiCad has no coin-cell 1.8 V buck

V, so it works at both ends of the cell's life AND behind D1's forward drop. One departure making another necessary, which is why they are listed
together. WHAT IS NOT HERE: U2 Apple's UWB SiP (never sold to anyone, and a DNP part with a land pattern invites somebody to try to buy one), with ANT3 and the

coaxial port; the op-amp (its ROLE is this project's reconstruction, not an observation); the part marked 1A8/1950 (unidentified down to its
function). None of them can be bought, placed, or justified on a board. THIS BOARD IS NOT THE SIZE OF AN AIRTAG, AND THAT IS A FORK RATHER THAN A COMPROMISE. Dimensional fidelity and buildability are in DIRECT CONFLICT here: Apple's WLCSP-50 fits the ~6 mm annular ring and CANNOT BE LANDED, because no complete ball map for it has ever been published. The QFN-48 is

the same die, CAN be landed, and is 6x6 mm - which does not fit that ring. There is no arrangement that is both. THIS IS THE BUILDABLE BRANCH; the dimensional branch is the metrology record in pcb/, where the 0.30 mm board and the wafer-scale packages live. A person holding a board that works but

is the wrong shape should not have to work out why. THE CELL IS OFF-BOARD ON TWO PADS, AND THAT IS FORCED. NO CR2032 HOLDER IN KiCad's LIBRARY FITS A 30 mm DISC - NINE OF NINE measurable ones are too

big, measured through KiCad's own courtyard geometry, and the only fitting part is a cell with solder tabs that welds the battery in permanently. A 20 mm cell plus its retention on a 30 mm disc is not marginal, it does not go. Two pads take any holder, any cell or a bench supply, which is what a

shape's control POINTS, and this one is three lines plus an ARC whose true extent lies nowhere near its endpoints - so the two methods shared an
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

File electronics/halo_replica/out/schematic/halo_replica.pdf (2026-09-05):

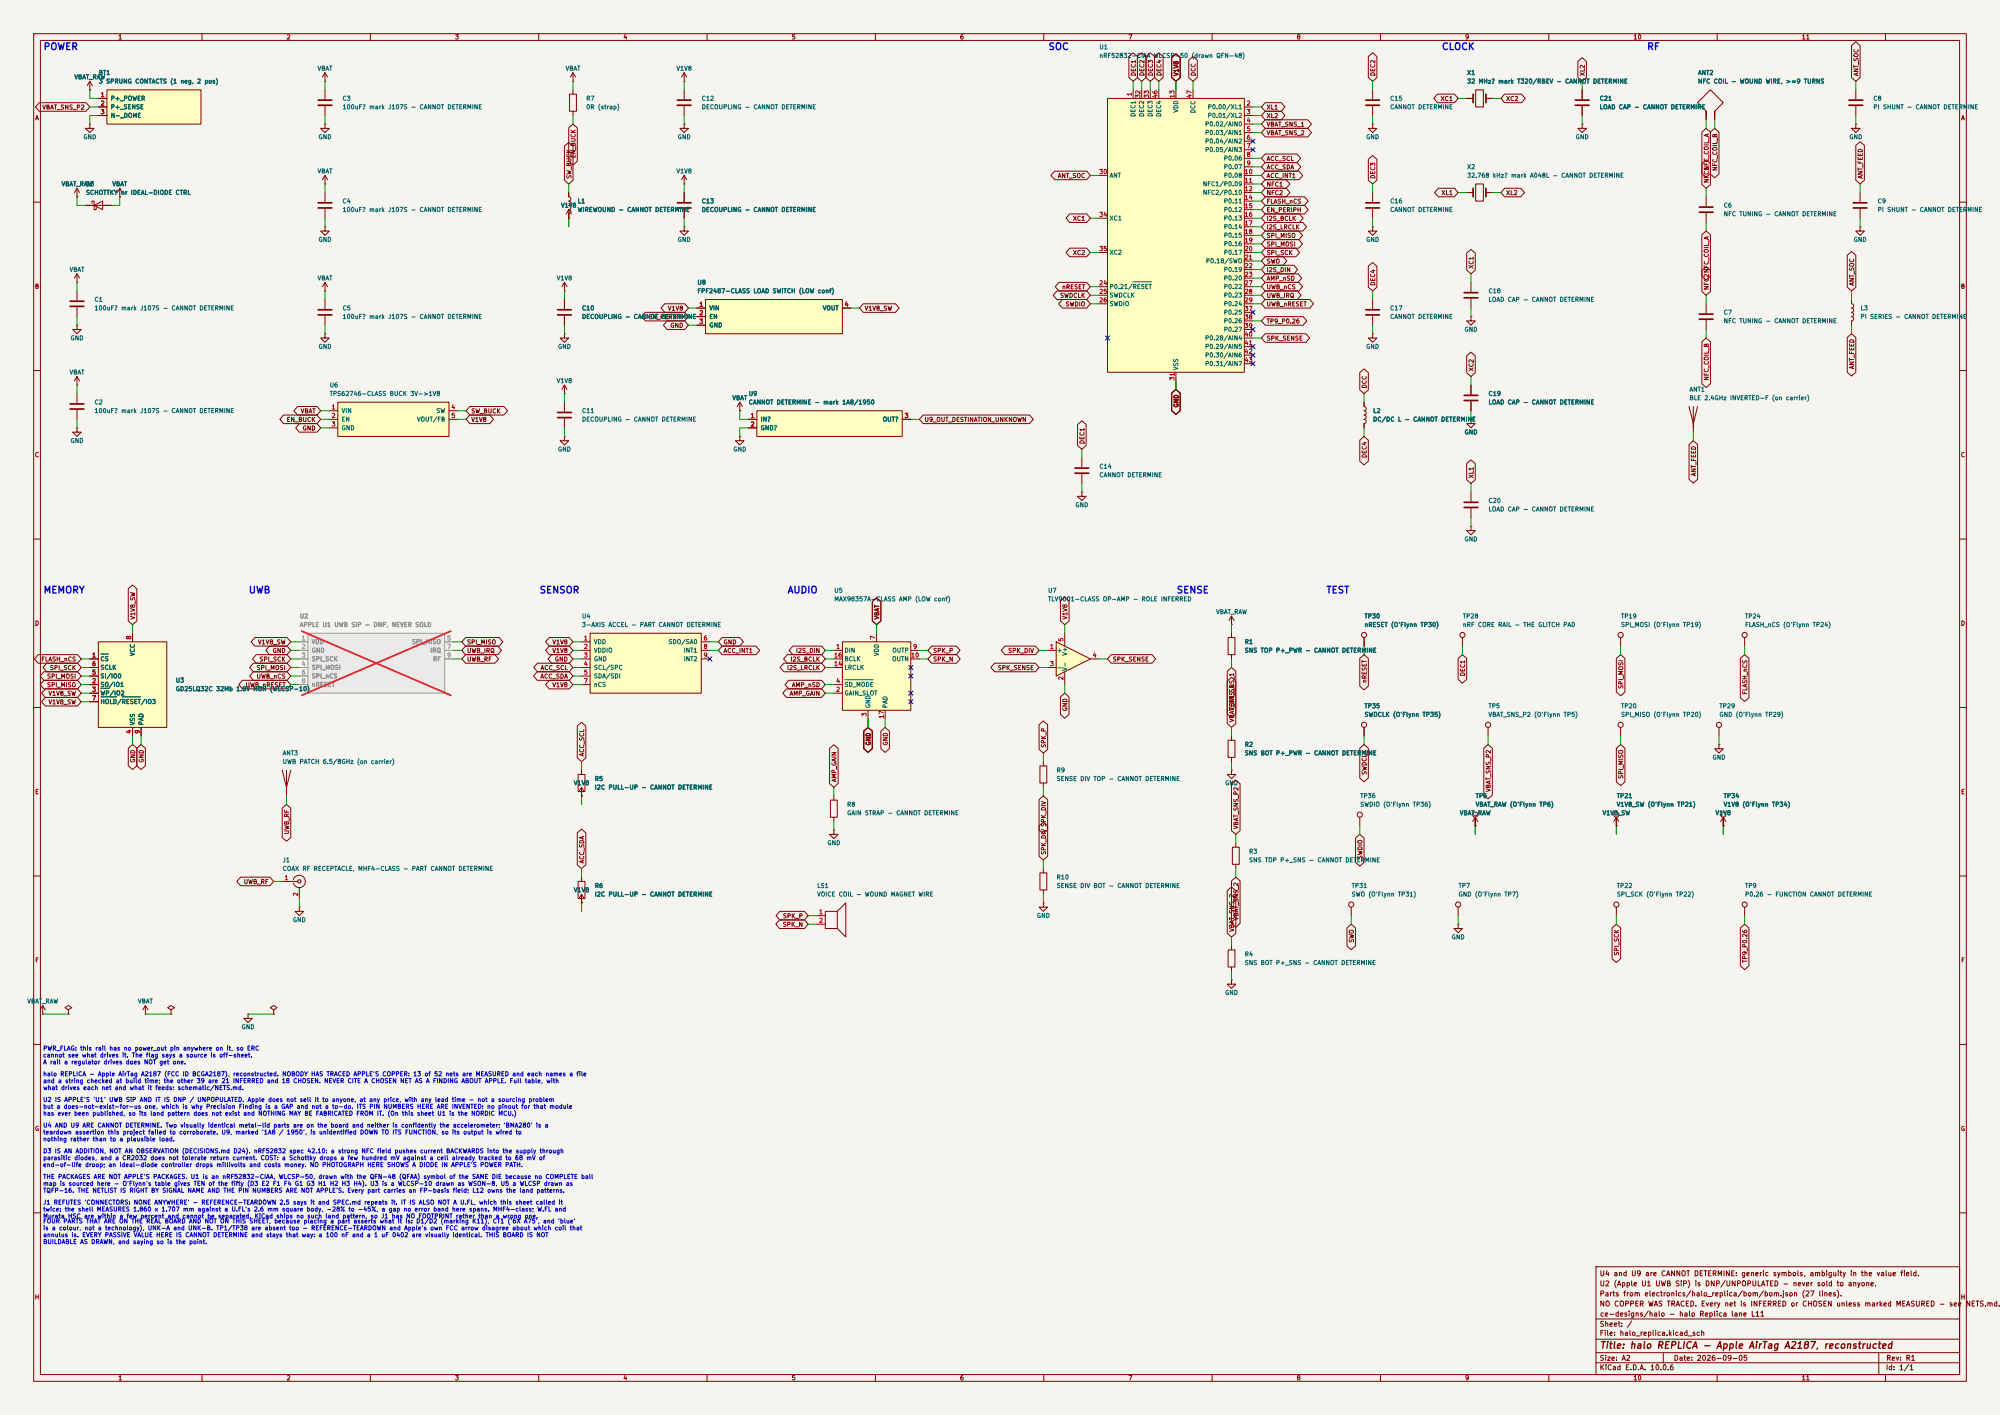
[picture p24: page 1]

3 SPRUNG CONTACTS (1 neg, 2 pos) GND

32 MHz? mark T320/RBEV - CANNOT DETERMINE C21

ANT2 NFC COIL - WOUND WIRE, >=9 TURNS

32 MHz? mark T320/RBEV - CANNOT DETERMINE GND

LOAD CAP - CANNOT DETERMINE DEC1

C9PI SHUNT - CANNOT DETERMINE C8PI SHUNT - CANNOT DETERMINE GND

100uF? mark J107S - CANNOT DETERMINE GND

LOAD CAP - CANNOT DETERMINE X2

LOAD CAP - CANNOT DETERMINE C19

32.768 kHz? mark A048L - CANNOT DETERMINE

V1V8 L1WIREWOUND - CANNOT DETERMINE U8
V1V8 C10 DECOUPLING - CANNOT DETERMINE GND

C7NFC TUNING - CANNOT DETERMINE C6NFC TUNING - CANNOT DETERMINE

L3PI SERIES - CANNOT DETERMINE GND +

FPF2487-CLASS LOAD SWITCH (LOW conf) VIN 1

FPF2487-CLASS LOAD SWITCH (LOW conf) VDD 1

LOAD CAP - CANNOT DETERMINE

ANT1 BLE 2.4GHz INVERTED-F (on carrier)

L2DC/DC L - CANNOT DETERMINE GND

3-AXIS ACCEL - PART CANNOT DETERMINE GND

TLV9001-CLASS OP-AMP - ROLE INFERRED

APPLE U1 UWB SiP - DNP, NEVER SOLD

nRF CORE RAIL - THE GLITCH PAD

SNS TOP P+_PWR - CANNOT DETERMINE R2

SNS BOT P+_PWR - CANNOT DETERMINE

SENSE DIV TOP - CANNOT DETERMINE

I2C PULL-UP - CANNOT DETERMINE V1V8

I2C PULL-UP - CANNOT DETERMINE R5
I2C PULL-UP - CANNOT DETERMINE R6

SWO (O'Flynn TP31) R3
SNS TOP P+_SNS - CANNOT DETERMINE

J1COAX RF RECEPTACLE, MHF4-CLASS - PART CANNOT DETERMINE

I2C PULL-UP - CANNOT DETERMINE

VOICE COIL - WOUND MAGNET WIRE

SENSE DIV BOT - CANNOT DETERMINE

SNS BOT P+_SNS - CANNOT DETERMINE

but a does-not-exist-for-us one, which is why Precision Finding is a GAP and not a to-do. ITS PIN NUMBERS HERE ARE INVENTED: no pinout for that module has ever been published, so its land pattern does not exist and NOTHING MAY BE FABRICATED FROM IT. (On this sheet U1 is the NORDIC MCU.) halo REPLICA - Apple AirTag A2187 (FCC ID BCGA2187), reconstructed. NOBODY HAS TRACED APPLE'S COPPER: 13 of 52 nets are MEASURED and each names a file and a string checked at build time; the other 39 are 21 INFERRED and 18 CHOSEN. NEVER CITE A CHOSEN NET AS A FINDING ABOUT APPLE. Full table, with what drives each net and what it feeds: schematic/NETS.md. PWR_FLAG: this rail has no power_out pin anywhere on it, so ERC
cannot see what drives it. The flag says a source is off-sheet. A rail a regulator drives does NOT get one.

U2 IS APPLE'S 'U1' UWB SiP AND IT IS DNP / UNPOPULATED. Apple does not sell it to anyone, at any price, with any lead time - not a sourcing problem

U4 AND U9 ARE CANNOT DETERMINE. Two visually identical metal-lid parts are on the board and neither is confidently the accelerometer; 'BMA280' is a
teardown assertion this project failed to corroborate. U9, marked '1A8 / 1950', is unidentified DOWN TO ITS FUNCTION, so its output is wired to
nothing rather than to a plausible load.
D3 IS AN ADDITION, NOT AN OBSERVATION (DECISIONS.md D24). nRF52832 spec 42.10: a strong NFC field pushes current BACKWARDS into the supply through
parasitic diodes, and a CR2032 does not tolerate return current. COST: a Schottky drops a few hundred mV against a cell already tracked to 68 mV of end-of-life droop; an ideal-diode controller drops millivolts and costs money. NO PHOTOGRAPH HERE SHOWS A DIODE IN APPLE'S POWER PATH. THE PACKAGES ARE NOT APPLE'S PACKAGES. U1 is an nRF52832-CIAA, WLCSP-50, drawn with the QFN-48 (QFAA) symbol of the SAME DIE because no COMPLETE ball map is sourced here - O'Flynn's table gives TEN of the fifty (D3 E2 F1 F4 G1 G3 H1 H2 H3 H4). U3 is a WLCSP-10 drawn as WSON-8, U5 a WLCSP drawn as

TQFP-16. THE NETLIST IS RIGHT BY SIGNAL NAME AND THE PIN NUMBERS ARE NOT APPLE'S. Every part carries an FP-basis field; L12 owns the land patterns. J1 REFUTES 'CONNECTORS: NONE ANYWHERE' - REFERENCE-TEARDOWN 2.5 says it and SPEC.md repeats it. IT IS ALSO NOT A U.FL, which this sheet called it

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

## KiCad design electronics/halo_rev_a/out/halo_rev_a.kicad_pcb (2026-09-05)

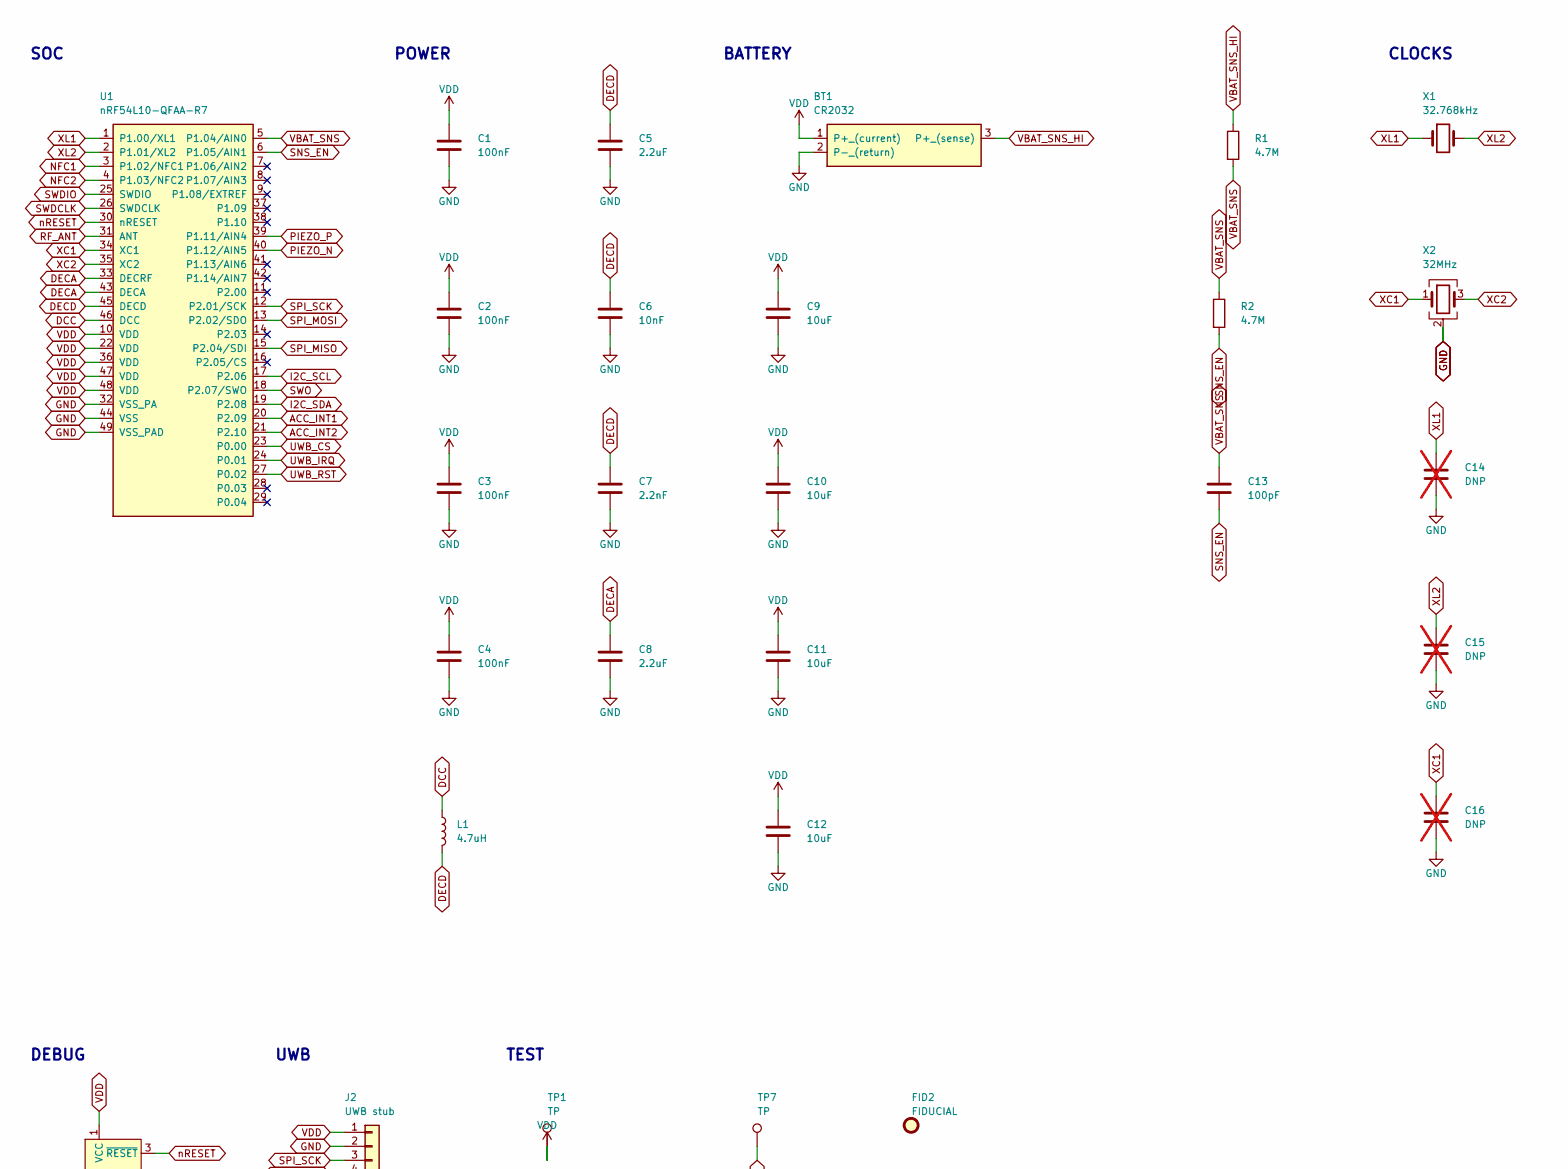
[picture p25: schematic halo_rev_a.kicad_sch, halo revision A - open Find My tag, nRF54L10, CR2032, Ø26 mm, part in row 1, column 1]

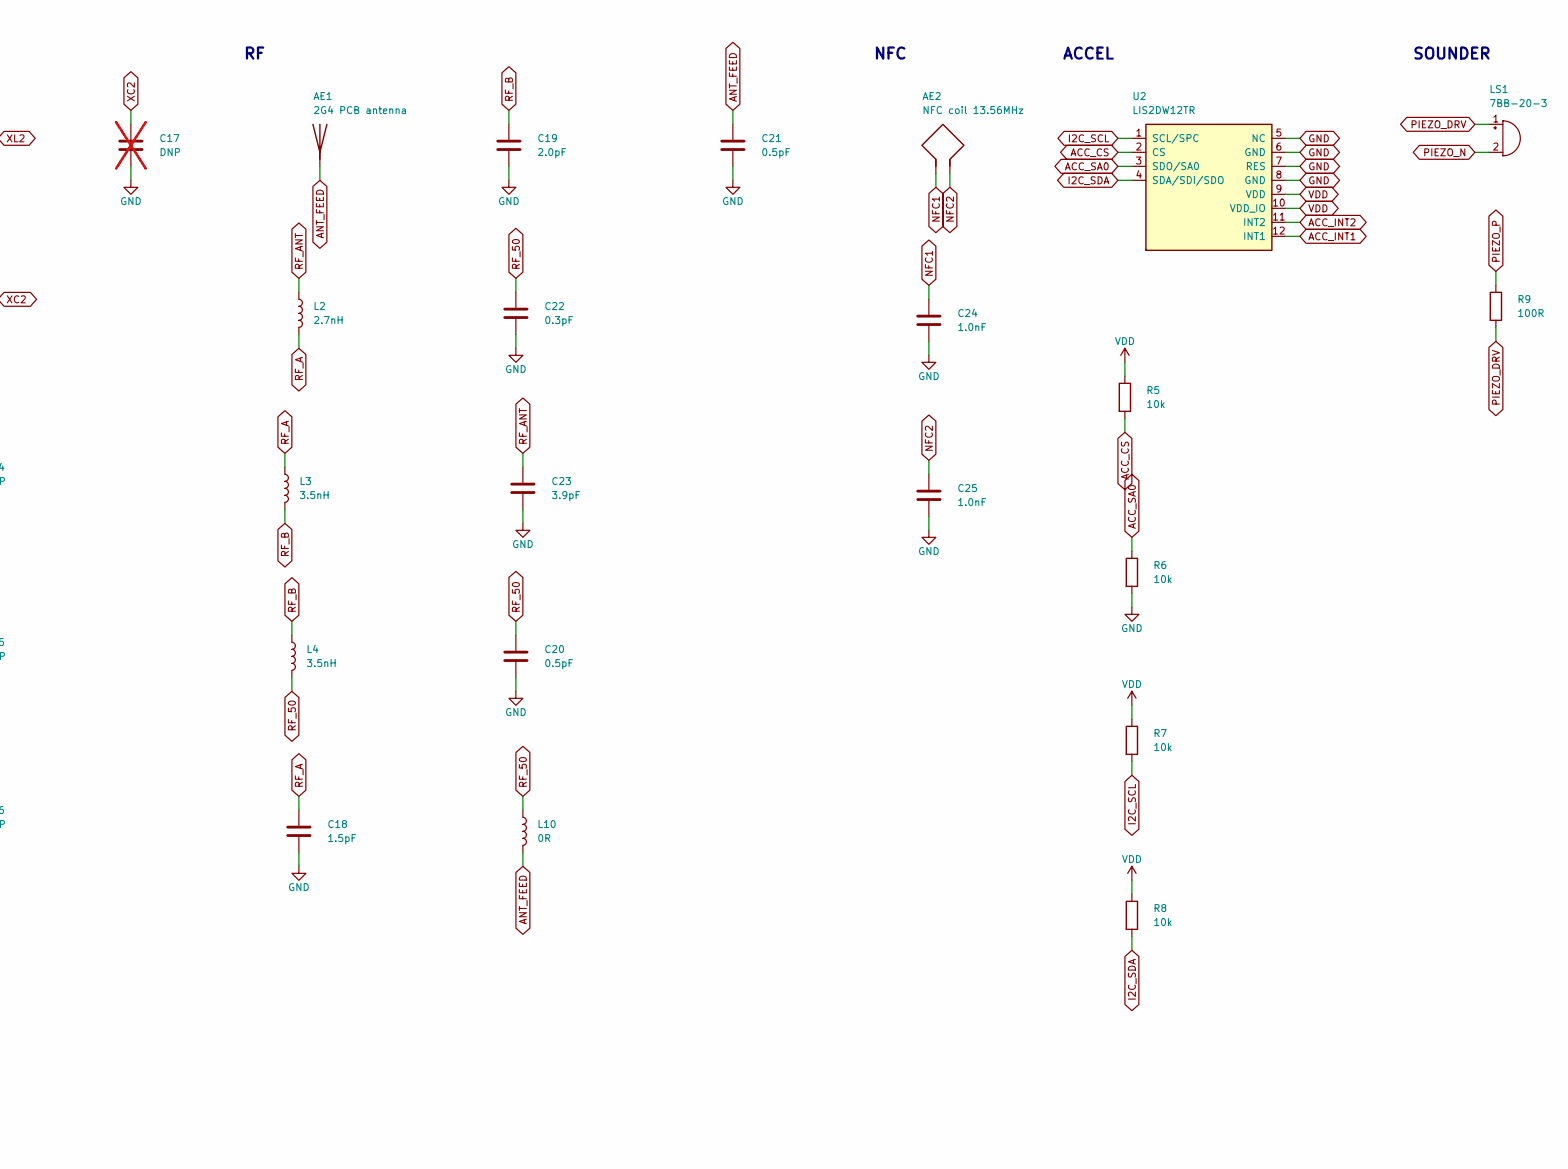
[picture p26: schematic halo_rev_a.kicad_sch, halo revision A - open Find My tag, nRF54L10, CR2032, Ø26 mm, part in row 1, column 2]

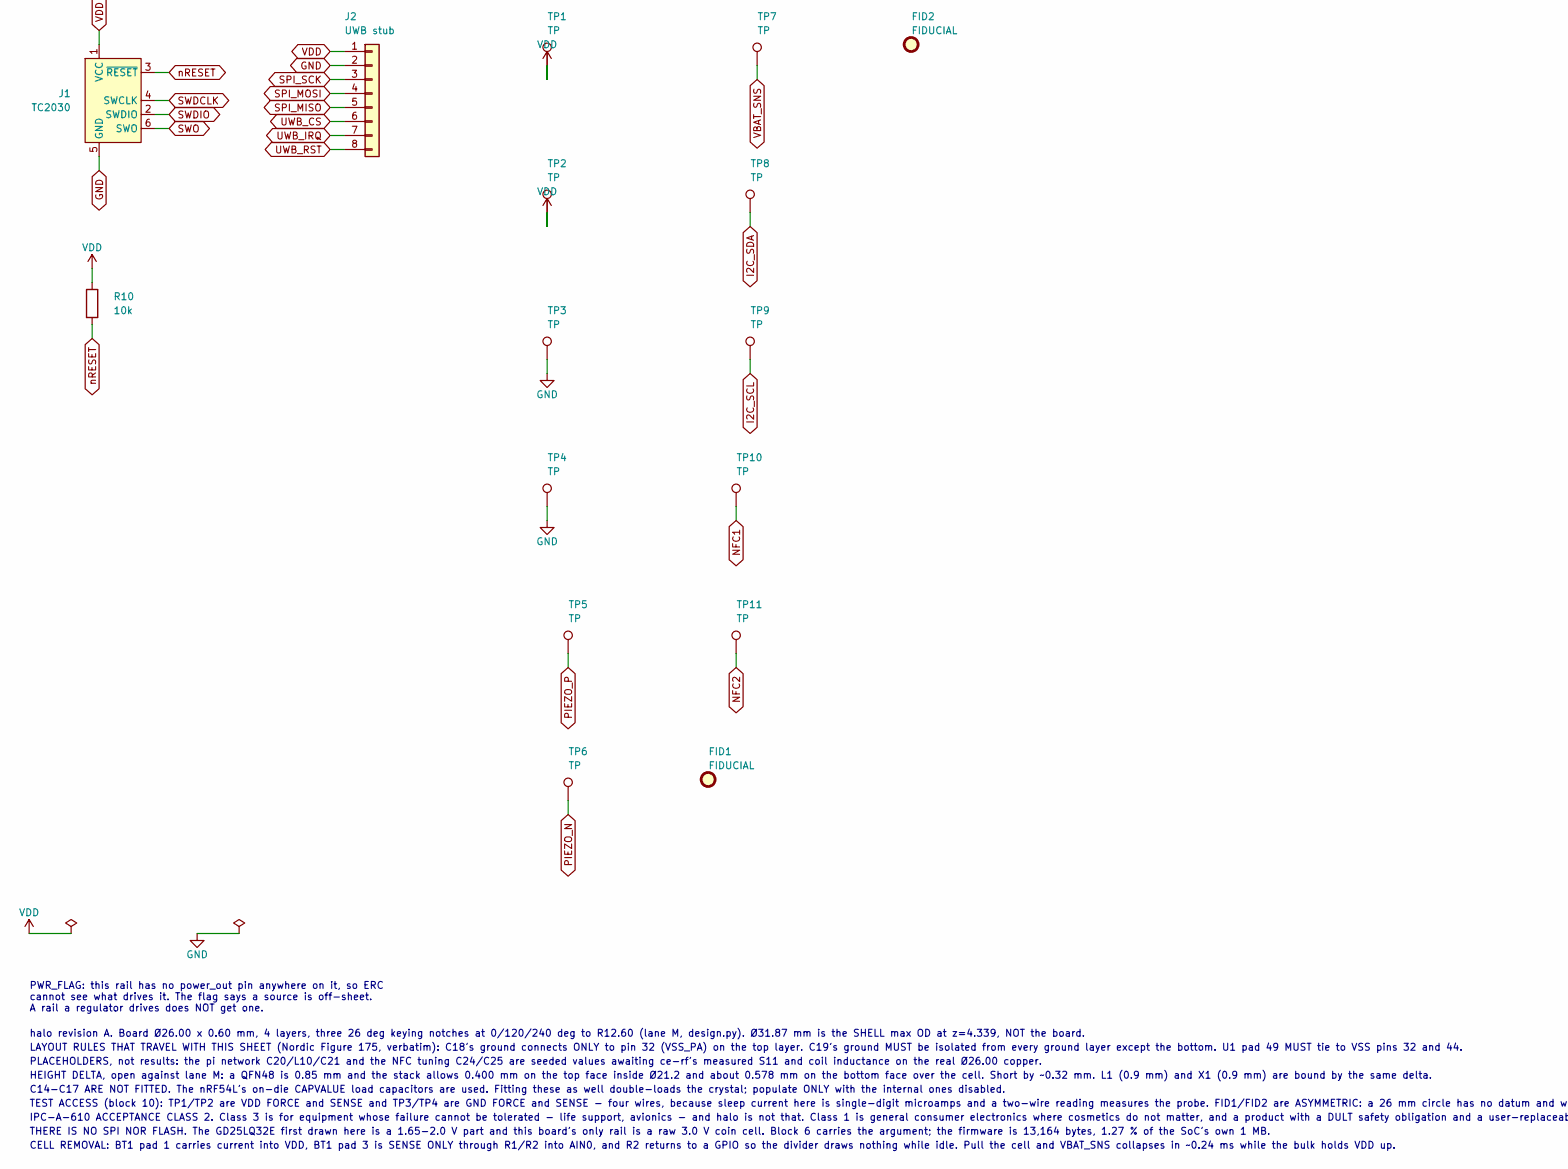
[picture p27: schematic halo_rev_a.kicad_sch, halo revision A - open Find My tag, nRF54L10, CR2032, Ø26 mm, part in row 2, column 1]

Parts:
AE1: 2G4 PCB antenna
AE2: NFC coil 13.56MHz
BT1: CR2032; HALO_BATT_CONTACT_3PAD; MPN CR2032; LCSC Part # NO ORDER CODE - NOT AN SMT LINE
C1, C2, C3, C4: 100nF; C_0201_0603Metric; MPN TCC0201X5R104K100ZT; LCSC Part # C5142565
C5, C8: 2.2uF; C_0201_0603Metric; MPN GRM033R61A225KE47D; LCSC Part # C335106
C6: 10nF; C_0201_0603Metric; MPN GRM033R71A103KA01D; LCSC Part # C76941
C7: 2.2nF; C_0201_0603Metric; MPN GRM033R71A222KA01D; LCSC Part # C161479
C9, C10, C11, C12: 10uF; C_0402_1005Metric; MPN CL05A106MQ5NUNC; LCSC Part # C15525
C13: 100pF; C_0201_0603Metric; MPN GRM0335C1H101JA01D; LCSC Part # C76922
C14, C15, C16, C17: DNP; C_0201_0603Metric; not fitted
C18: 1.5pF; C_0201_0603Metric; MPN GJM0335C1E1R5WB01D; LCSC Part # C435397
C19: 2.0pF; C_0201_0603Metric; MPN GJM0335C1E2R0WB01D; LCSC Part # C668326
C20, C21: 0.5pF; C_0201_0603Metric; MPN GJM0335C1HR50WB01D; LCSC Part # C237424
C22: 0.3pF; C_0201_0603Metric; MPN GJM0335C1HR30WB01D; LCSC Part # C3904589
C23: 3.9pF; C_0201_0603Metric; MPN GJM0335C1E3R9WB01D; LCSC Part # C1852416
C24, C25: 1.0nF; C_0201_0603Metric; MPN GRM0335C1E102JA01D; LCSC Part # C161371
FID1, FID2: FIDUCIAL; Fiducial_0.5mm_Mask1mm; LCSC Part # n/a
J1: TC2030; Tag-Connect_TC2030-IDC-NL_2x03_P1.27mm_Vertical; LCSC Part # n/a
J2: UWB stub; HALO_UWB_LANDS_1x08_P1.00; LCSC Part # n/a
L1: 4.7uH; L_0603_1608Metric; MPN MLZ1608M4R7WT000; LCSC Part # C76799
L2: 2.7nH; L_0201_0603Metric; MPN LQP03HQ2N7B02D; LCSC Part # C7216765
L3, L4: 3.5nH; L_0201_0603Metric; MPN LQP03HQ3N5B02D; LCSC Part # C3911055
L10: 0R; L_0201_0603Metric; MPN 0201WMF0000TEE; LCSC Part # C473473
LS1: 7BB-20-3; MPN 7BB-20-3; LCSC Part # NOT IN CATALOGUE
R1, R2: 4.7M; R_0201_0603Metric; MPN 0201WMF4704TEE; LCSC Part # C778408
R5, R6, R7, R8, R10: 10k; R_0201_0603Metric; MPN 0201WMF1002TEE; LCSC Part # C473048
R9: 100R; R_0201_0603Metric; MPN 0201WMF1000TEE; LCSC Part # C270366
TP1, TP2, TP3, TP4, TP5, TP6, TP7, TP8, TP9, TP10, TP11: TP; HALO_TP_D0.8; LCSC Part # n/a
U1: nRF54L10-QFAA-R7; QFN-48-1EP_6x6mm_P0.4mm_EP4.4x4.4mm; MPN NRF54L10-QFAA-R7; LCSC Part # C44800139
U2: LIS2DW12TR; LGA-12_2x2mm_P0.5mm; MPN LIS2DW12TR; LCSC Part # C189624
X1: 32.768kHz; Crystal_SMD_3215-2Pin_3.2x1.5mm; MPN Q13FC13500049; LCSC Part # C95361
X2: 32MHz; Crystal_SMD_2016-4Pin_2.0x1.6mm; MPN NX2016SA-32MHZ-STD-CZS-5; LCSC Part # C843260

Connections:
ACC_CS: R5.2, U2.2 (CS)
ACC_INT1: U1.20 (P2.09), U2.12 (INT1)
ACC_INT2: U1.21 (P2.10), U2.11 (INT2)
ACC_SA0: R6.1, U2.3 (SDO/SA0)
ANT_FEED: AE1.1, C21.1, L10.2
DCC: L1.1, U1.46 (DCC)
DECA: C8.1, U1.33 (DECRF), U1.43 (DECA)
DECD: C5.1, C6.1, C7.1, L1.2, U1.45 (DECD)
I2C_SCL: R7.2, TP9.1, U1.17 (P2.06), U2.1 (SCL/SPC)
I2C_SDA: R8.2, TP8.1, U1.19 (P2.08), U2.4 (SDA/SDI/SDO)
NFC1: AE2.1, C24.1, TP10.1, U1.3 (P1.02/NFC1)
NFC2: AE2.2, C25.1, TP11.1, U1.4 (P1.03/NFC2)
PIEZO_DRV: LS1.1 (+), R9.2
PIEZO_N: LS1.2 (-), TP6.1, U1.40 (P1.12/AIN5)
PIEZO_P: R9.1, TP5.1, U1.39 (P1.11/AIN4)
RF_50: C20.1, C22.1, L4.2, L10.1
RF_A: C18.1, L2.2, L3.1
RF_ANT: C23.1, L2.1, U1.31 (ANT)
RF_B: C19.1, L3.2, L4.1
SNS_EN: C13.2, R2.2, U1.6 (P1.05/AIN1)
SPI_MISO: J2.5, U1.15 (P2.04/SDI)
SPI_MOSI: J2.4, U1.13 (P2.02/SDO)
SPI_SCK: J2.3, U1.12 (P2.01/SCK)
SWDCLK: J1.4 (SWCLK), U1.26 (SWDCLK)
SWDIO: J1.2 (SWDIO), U1.25 (SWDIO)
SWO: J1.6 (SWO), U1.18 (P2.07/SWO)
UWB_CS: J2.6, U1.23 (P0.00)
UWB_IRQ: J2.7, U1.24 (P0.01)
UWB_RST: J2.8, U1.27 (P0.02)
VBAT_SNS: C13.1, R1.2, R2.1, TP7.1, U1.5 (P1.04/AIN0)
VBAT_SNS_HI: BT1.3 (P+_(sense)), R1.1
XC1: C16.1, U1.34 (XC1), X2.1
XC2: C17.1, U1.35 (XC2), X2.3
XL1: C14.1, U1.1 (P1.00/XL1), X1.1
XL2: C15.1, U1.2 (P1.01/XL2), X1.2
nRESET: J1.3 (~RESET), R10.2, U1.30 (nRESET)

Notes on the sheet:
PWR_FLAG: this rail has no power_out pin anywhere on it, so ERC cannot see what drives it. The flag says a source is off-sheet. A rail a regulator drives does NOT get one.
SOC
POWER
BATTERY
CLOCKS
NFC
ACCEL
SOUNDER
DEBUG
UWB
TEST
halo revision A. Board Ø26.00 x 0.60 mm, 4 layers, three 26 deg keying notches at 0/120/240 deg to R12.60 (lane M, design.py). Ø31.87 mm is the SHELL max OD at z=4.339, NOT the board.
LAYOUT RULES THAT TRAVEL WITH THIS SHEET (Nordic Figure 175, verbatim): C18's ground connects ONLY to pin 32 (VSS_PA) on the top layer. C19's ground MUST be isolated from every ground layer except the bottom. U1 pad 49 MUST tie to VSS pins 32 and 44.
PLACEHOLDERS, not results: the pi network C20/L10/C21 and the NFC tuning C24/C25 are seeded values awaiting ce-rf's measured S11 and coil inductance on the real Ø26.00 copper.
HEIGHT DELTA, open against lane M: a QFN48 is 0.85 mm and the stack allows 0.400 mm on the top face inside Ø21.2 and about 0.578 mm on the bottom face over the cell. Short by ~0.32 mm. L1 (0.9 mm) and X1 (0.9 mm) are bound by the same delta.
C14-C17 ARE NOT FITTED. The nRF54L's on-die CAPVALUE load capacitors are used. Fitting these as well double-loads the crystal; populate ONLY with the internal ones disabled.
TEST ACCESS (block 10): TP1/TP2 are VDD FORCE and SENSE and TP3/TP4 are GND FORCE and SENSE - four wires, because sleep current here is single-digit microamps and a two-wire reading measures the probe. FID1/FID2 are ASYMMETRIC: a 26 mm circle has no datum and without them every pad position is a gu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
IPC-A-610 ACCEPTANCE CLASS 2. Class 3 is for equipment whose failure cannot be tolerated - life support, avionics - and halo is not that. Class 1 is general consumer electronics where cosmetics do not matter, and a product with a DULT safety obligation and a user-replaceable cell is not that either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
THERE IS NO SPI NOR FLASH. The GD25LQ32E first drawn here is a 1.65-2.0 V part and this board's only rail is a raw 3.0 V coin cell. Block 6 carries the argument; the firmware is 13,164 bytes, 1.27 % of the SoC's own 1 MB.
CELL REMOVAL: BT1 pad 1 carries current into VDD, BT1 pad 3 is SENSE ONLY through R1/R2 into AIN0, and R2 returns to a GPIO so the divider draws nothing while idle. Pull the cell and VBAT_SNS collapses in ~0.24 ms while the bulk holds VDD up.

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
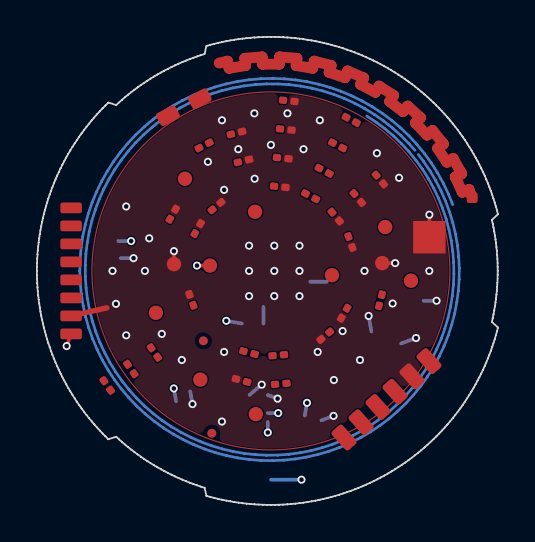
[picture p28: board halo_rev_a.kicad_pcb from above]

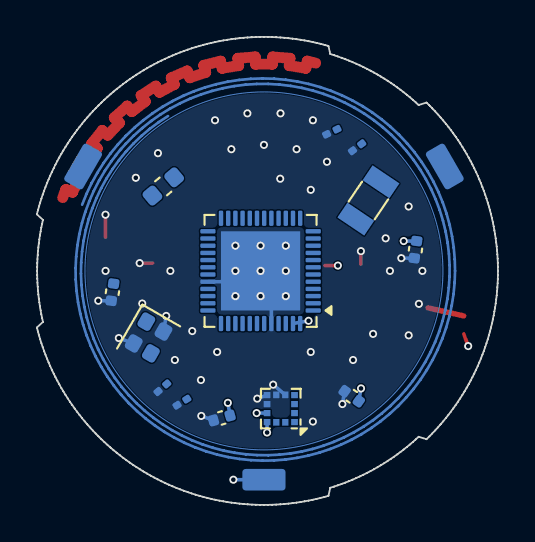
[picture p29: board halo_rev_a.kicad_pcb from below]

Board: 4 copper layers, 25.6 x 26.0 mm, 62 parts (15 on the bottom side), 38 nets.

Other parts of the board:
M1: HALO_SERIAL_MARK_1X8

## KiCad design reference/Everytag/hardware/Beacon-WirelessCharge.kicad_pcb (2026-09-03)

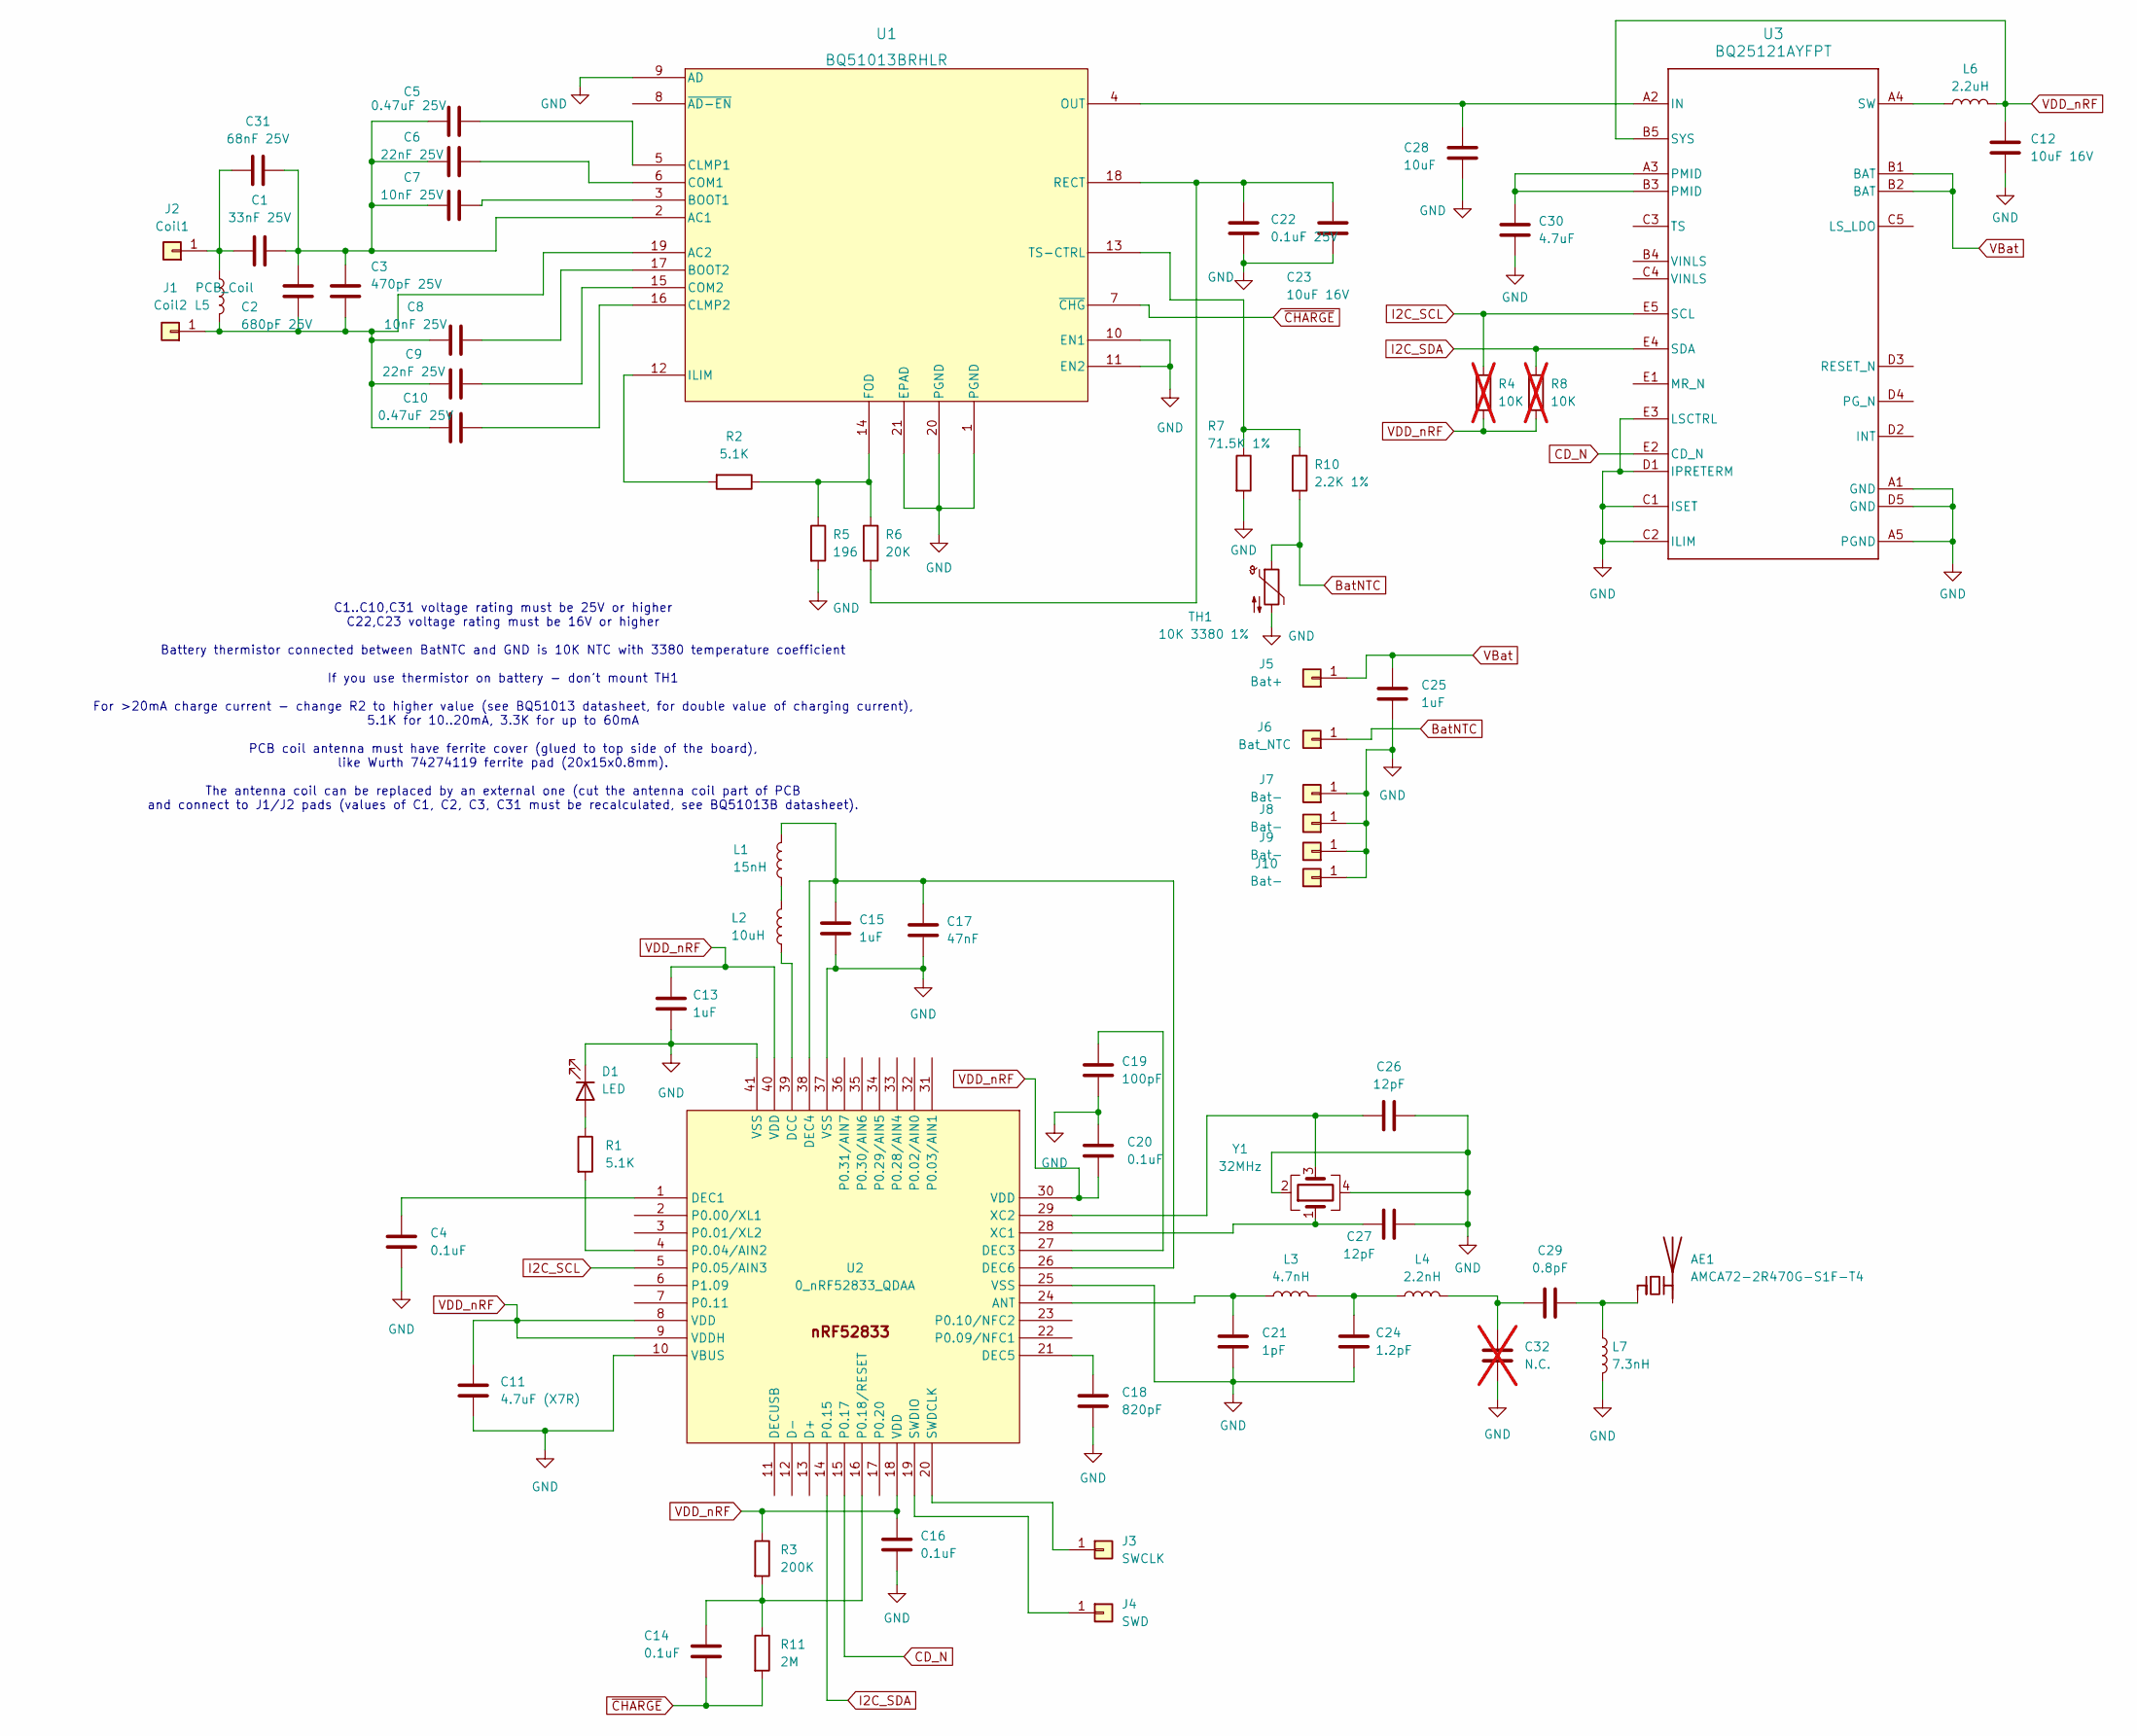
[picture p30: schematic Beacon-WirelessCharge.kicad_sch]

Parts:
AE1: AMCA72-2R470G-S1F-T4; Antenna_2450AT43A100
C1: 33nF 25V; C_0402_1005Metric
C2: 680pF 25V; C_0402_1005Metric
C3: 470pF 25V; C_0402_1005Metric
C4, C14, C16, C20: 0.1uF; C_0402_1005Metric
C5, C10: 0.47uF 25V; C_0402_1005Metric
C6, C9: 22nF 25V; C_0402_1005Metric
C7, C8: 10nF 25V; C_0402_1005Metric
C11: 4.7uF (X7R); C_0603_1608Metric
C12, C23: 10uF 16V; C_0603_1608Metric
C13, C15, C25: 1uF; C_0402_1005Metric
C17: 47nF; C_0402_1005Metric
C18: 820pF; C_0402_1005Metric
C19: 100pF; C_0402_1005Metric
C21: 1pF; C_0402_1005Metric
C22: 0.1uF 25V; C_0402_1005Metric
C24: 1.2pF; C_0402_1005Metric
C26, C27: 12pF; C_0402_1005Metric
C28: 10uF; C_0402_1005Metric
C29: 0.8pF; C_0402_1005Metric
C30: 4.7uF; C_0402_1005Metric
C31: 68nF 25V; C_0402_1005Metric
C32: N.C.; C_0402_1005Metric; not fitted
D1: LED; D_0402_1005Metric
J1: Coil2; Pin-1.5_1.5mm
J2: Coil1; Pin-1.5_1.5mm
J3: SWCLK; Pin-1.5_1.5mm
J4: SWD; Pin-1.5_1.5mm
J5: Bat+; Pin-1.5_1.5mm
J6: Bat_NTC; Pin-1.5_1.5mm
J7, J8, J9, J10: Bat-; Pin-1.5_1.5mm
L1: 15nH; L_0402_1005Metric
L2: 10uH; L_0603_1608Metric
L3: 4.7nH; L_0402_1005Metric
L4: 2.2nH; L_0402_1005Metric
L5: PCB_Coil; antenna 19x13mm
L6: 2.2uH; L_0603_1608Metric
L7: 7.3nH; L_0402_1005Metric
R1, R2: 5.1K; R_0402_1005Metric
R3: 200K; R_0402_1005Metric
R4, R8: 10K; R_0402_1005Metric; not fitted
R5: 196; R_0402_1005Metric
R6: 20K; R_0402_1005Metric
R7: 71.5K 1%; R_0402_1005Metric
R10: 2.2K 1%; R_0402_1005Metric
R11: 2M; R_0402_1005Metric
TH1: 10K 3380 1%; R_0402_1005Metric
U1: BQ51013BRHLR; RHL20_2P05X3P05
U2: 0_nRF52833_QDAA; _Applications_test_rsk_lib_RSK-ONLY_Nordic Active DB.DbLib_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; PART NUMBER nRF52833-QDAA
U3: BQ25121AYFPT; BGA25C40P5X5_247X253X50
Y1: 32MHz; Crystal_SMD_2016-4Pin_2.0x1.6mm

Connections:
BatNTC: J6.1, R10.2, TH1.1
CD_N: U2.15 (P0.17), U3.E2 (CD_N)
GND: C4.2, C11.2, C12.2, C13.2, C15.2, C16.2, C17.2, C18.2, C19.2, C20.1, C21.2, C22.2, C23.2, C24.2, C25.2, C26.2, C27.2, C28.2, C30.2, C32.2, D1.1 (K), J7.1, J8.1, J9.1, J10.1, L7.2, R5.2, R7.2, TH1.2, U1.1 (PGND), U1.9 (AD), U1.10 (EN1), U1.11 (EN2), U1.20 (PGND), U1.21 (EPAD), U2.10 (VBUS), U2.25 (VSS), U2.37 (VSS), U2.41 (VSS), U3.A1 (GND), U3.A5 (PGND), U3.C1 (ISET), U3.C2 (ILIM), U3.D1 (IPRETERM), U3.D5 (GND), U3.E3 (LSCTRL), Y1.2, Y1.4
I2C_SCL: R4.1, U2.5 (P0.05/AIN3), U3.E5 (SCL)
I2C_SDA: R8.1, U2.14 (P0.15), U3.E4 (SDA)
unnamed: AE1.1 (FEED), C29.2, L7.1
unnamed: C24.1, L3.2, L4.1
unnamed: C29.1, C32.1, L4.2
unnamed: C30.1, U3.A3 (PMID), U3.B3 (PMID)
unnamed: D1.2 (A), R1.1
unnamed: C2.2, C3.2, C8.1, C9.1, C10.1, J1.1, L5.2, U1.19 (AC2)
unnamed: C1.1, C31.1, J2.1, L5.1
unnamed: J3.1, U2.20 (SWDCLK)
unnamed: J4.1, U2.19 (SWDIO)
unnamed: L1.1, L2.2
unnamed: C1.2, C2.1, C3.1, C5.1, C6.1, C7.1, C31.2, U1.2 (AC1)
unnamed: C7.2, U1.3 (BOOT1)
unnamed: C8.2, U1.17 (BOOT2)
unnamed: C5.2, U1.5 (CLMP1)
unnamed: C10.2, U1.16 (CLMP2)
unnamed: C6.2, U1.6 (COM1)
unnamed: C9.2, U1.15 (COM2)
unnamed: R2.1, R5.1, R6.1, U1.14 (FOD)
unnamed: R2.2, U1.12 (ILIM)
unnamed: C28.1, U1.4 (OUT), U3.A2 (IN)
unnamed: C22.1, C23.1, R6.2, U1.18 (RECT)
unnamed: R7.1, R10.1, U1.13 (TS-CTRL)
unnamed: C21.1, L3.1, U2.24 (ANT)
unnamed: L2.1, U2.39 (DCC)
unnamed: C4.1, U2.1 (DEC1)
unnamed: C19.1, U2.27 (DEC3)
unnamed: C15.1, C17.1, L1.2, U2.26 (DEC6), U2.38 (DEC4)
unnamed: C18.1, U2.21 (DEC5)
unnamed: R1.2, U2.4 (P0.04/AIN2)
unnamed: C14.1, R3.2, R11.1, U2.16 (P0.18/RESET)
unnamed: C27.1, U2.28 (XC1), Y1.1
unnamed: C26.1, U2.29 (XC2), Y1.3
unnamed: L6.1, U3.A4 (SW)
VBat: C25.1, J5.1, U3.B1 (BAT), U3.B2 (BAT)
VDD_nRF: C11.1, C12.1, C13.1, C16.1, C20.2, L6.2, R3.1, R4.2, R8.2, U2.8 (VDD), U2.9 (VDDH), U2.18 (VDD), U2.30 (VDD), U2.40 (VDD), U3.B5 (SYS)
~CHARGE: C14.2, R11.2, U1.7 (~CHG)

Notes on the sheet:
C1..C10,C31 voltage rating must be 25V or higher C22,C23 voltage rating must be 16V or higher Battery thermistor connected between BatNTC and GND is 10K NTC with 3380 temperature coefficient If you use thermistor on battery - don't mount TH1 For >20mA charge current - change R2 to higher value (see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

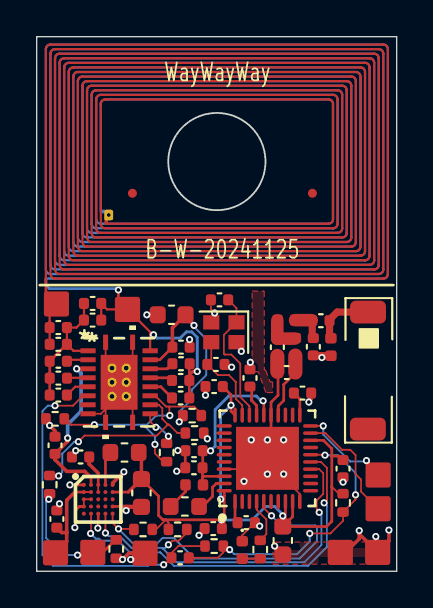
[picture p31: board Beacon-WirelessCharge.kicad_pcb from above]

Board: 2 copper layers, 20.0 x 29.7 mm, 68 parts (1 on the bottom side), 41 nets.

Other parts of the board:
Fiducial_0.5_1_A, Fiducial_0.5_1_B: Fiducial_0.5mm_Mask1mm

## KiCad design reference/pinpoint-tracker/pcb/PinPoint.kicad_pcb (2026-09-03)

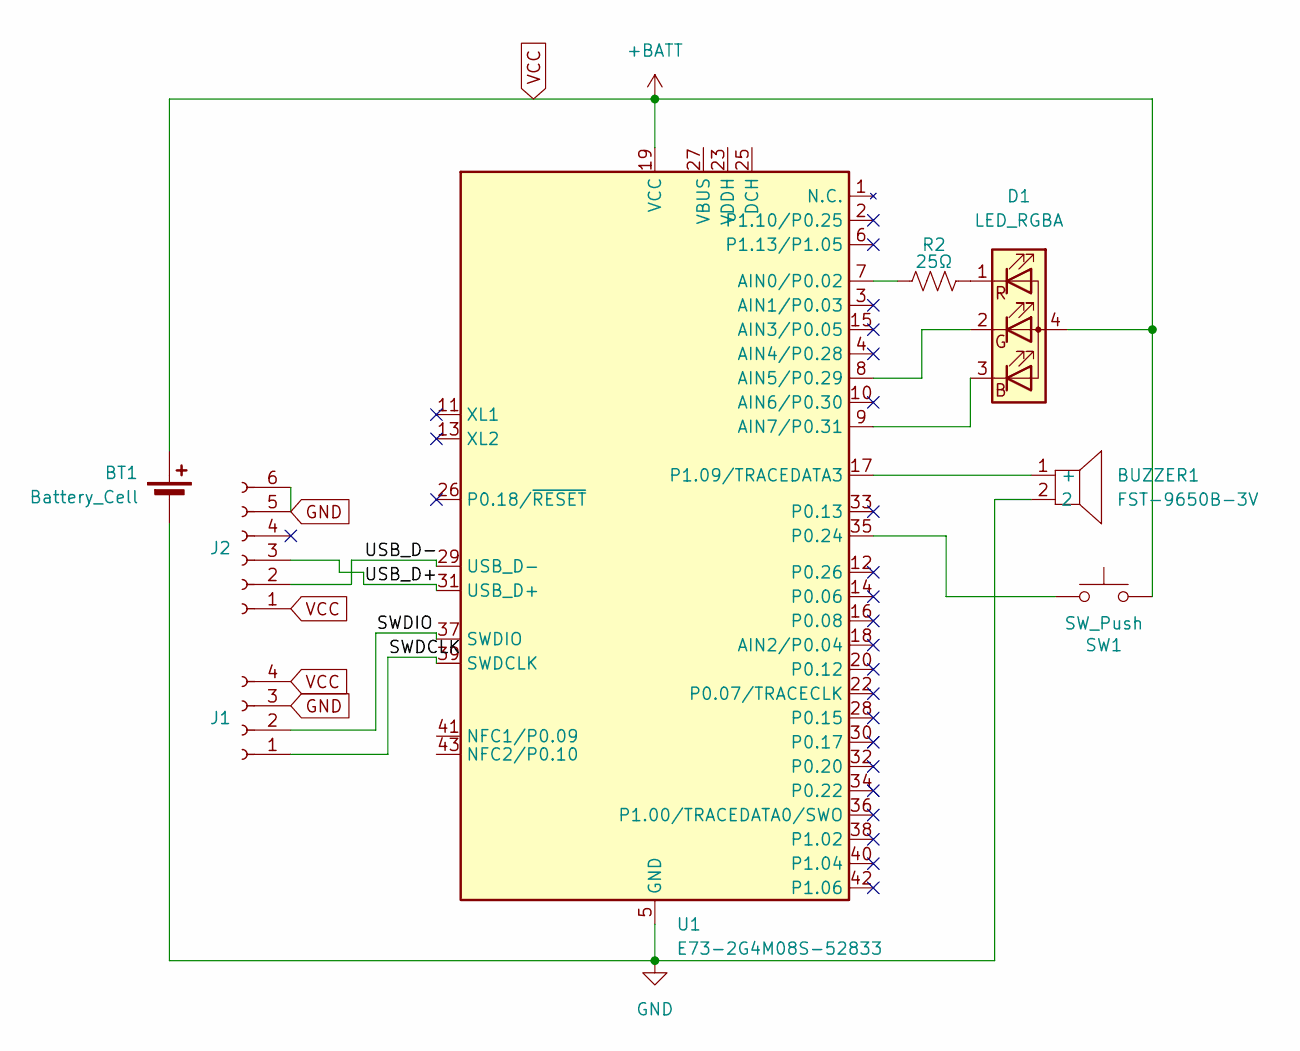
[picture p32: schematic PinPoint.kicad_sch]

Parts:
BT1: Battery_Cell; BatteryHolder_Keystone_3034_1x20mm; LCSC Part # C964823
BUZZER1: FST-9650B-3V; BUZ-SMD_L9.6-W9.6-LS10.0-R; LCSC Part C391032
D1: LED_RGBA; LED_LiteOn_LTST-C19HE1WT; LCSC Part # C458749
J1: PinHeader_1x04_P2.54mm_Vertical
J2: USB_Micro-B_Molex_47346-0001; LCSC Part # C132560
R2: 25Ω; R_0603_1608Metric
SW1: SW_Push; SW_SPST_CK_KXT3; LCSC Part # C388289
U1: E73-2G4M08S-52833; E73-2G4M08S1E; LCSC Part # C356849

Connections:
/SWDCLK: J1.1, U1.39 (SWDCLK)
/SWDIO: J1.2, U1.37 (SWDIO)
/USB_D+: J2.3, U1.31 (USB_D+)
/USB_D-: J2.2, U1.29 (USB_D-)
GND: BT1.2 (-), BUZZER1.2, J1.3, J2.5, J2.6, U1.5 (GND), U1.21 (GND), U1.24 (GND)
unnamed: BUZZER1.1 (+), U1.17 (P1.09/TRACEDATA3)
unnamed: D1.3 (BK), U1.9 (AIN7/P0.31)
unnamed: D1.2 (GK), U1.8 (AIN5/P0.29)
unnamed: D1.1 (RK), R2.2
unnamed: R2.1, U1.7 (AIN0/P0.02)
unnamed: SW1.1, U1.35 (P0.24)
VCC: BT1.1 (+), D1.4 (A), J1.4, J2.1, SW1.2, U1.19 (VCC)

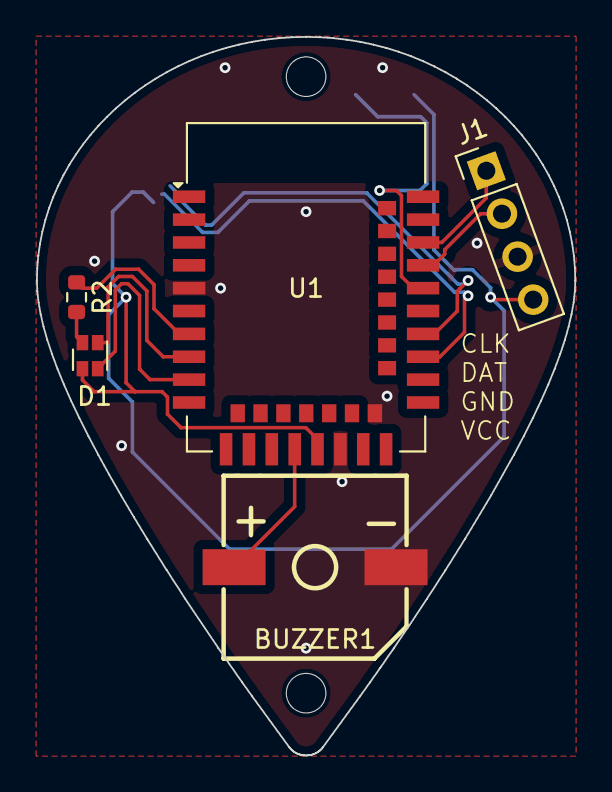
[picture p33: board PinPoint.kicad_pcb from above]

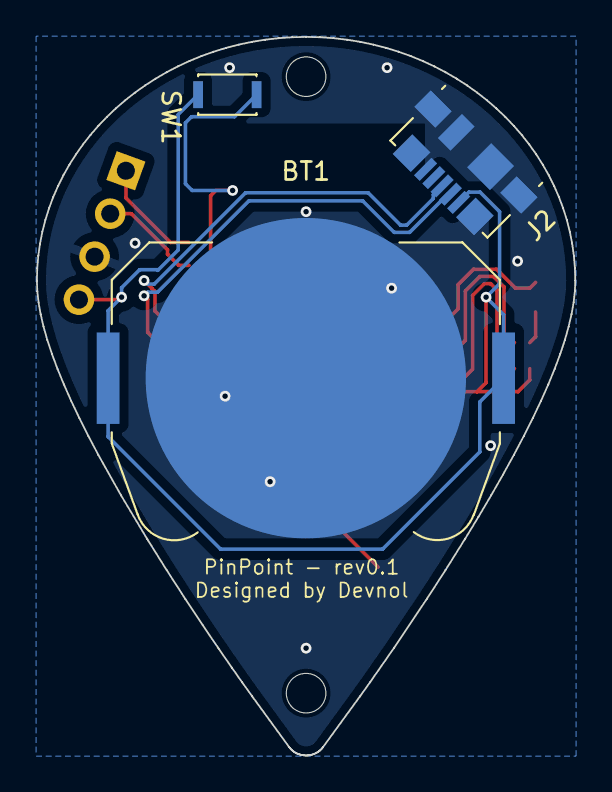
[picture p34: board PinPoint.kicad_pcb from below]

Board: 2 copper layers, 29.9 x 39.9 mm, 8 parts (3 on the bottom side), 12 nets.

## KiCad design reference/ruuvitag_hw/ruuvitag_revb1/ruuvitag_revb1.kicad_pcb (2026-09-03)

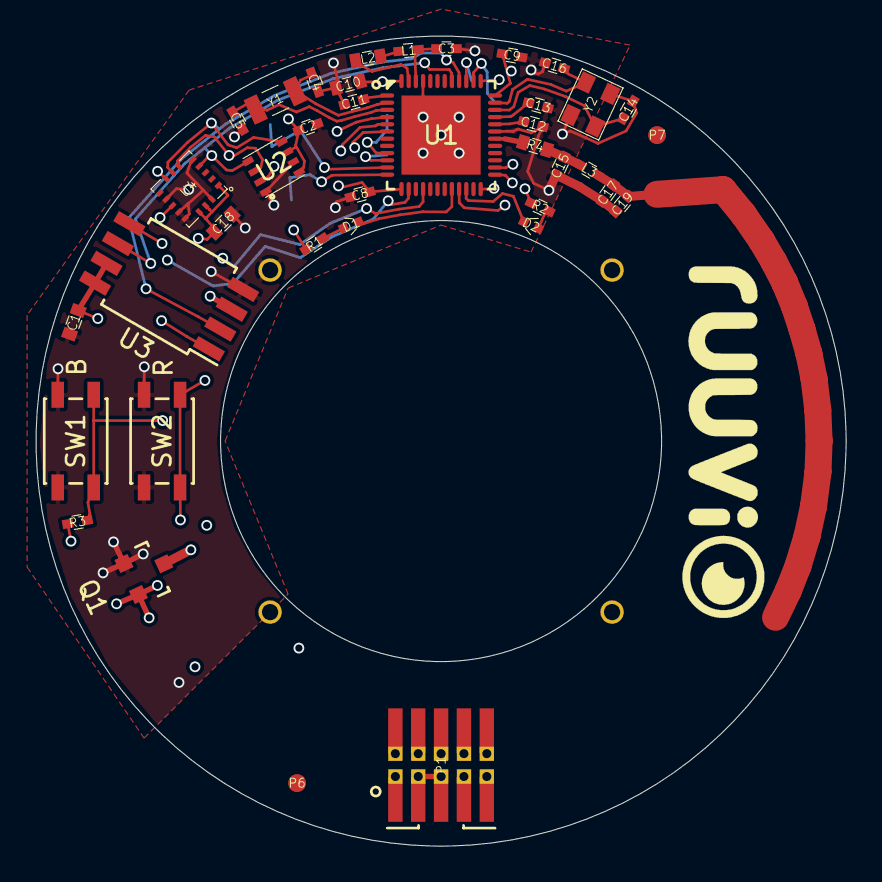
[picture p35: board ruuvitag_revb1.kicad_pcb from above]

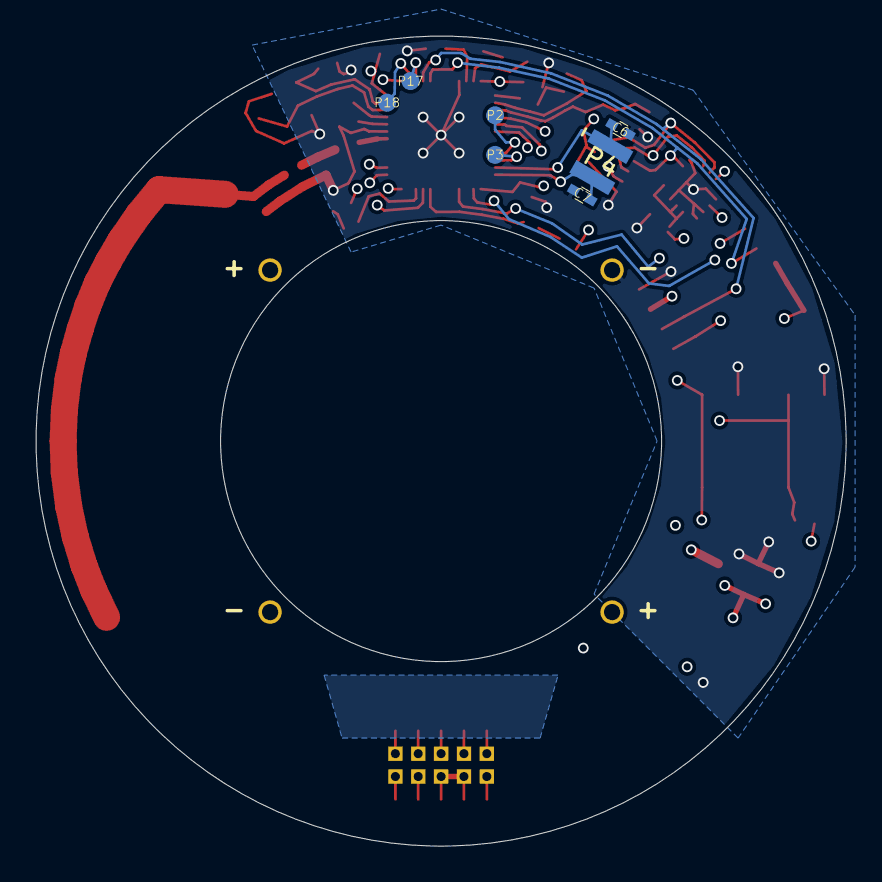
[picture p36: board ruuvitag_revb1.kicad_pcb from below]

Board: 4 copper layers, 45.0 x 45.0 mm, 49 parts (7 on the bottom side), 38 nets.

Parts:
C1, C10, C18: 4u7; 0603_GENERAL
C2, C8, C9, C11: 100n; 0402_GENERAL
C3: 1u; 0402_GENERAL
C4, C5, C14, C16: 12p; 0402_GENERAL
C6: NFCTUN1; 0402_GENERAL
C7: NFCTUN2; 0402_GENERAL
C12, C13: 100p; 0402_GENERAL
C15: 0p8; 0402_GENERAL
C17, C19: 1p2; 0402_GENERAL
D1: LED1; 0402_LED
D2: LED3; 0402_LED
L1: 15n; 0402_GENERAL
L2: 10u; 0603_GENERAL
L3: 3n9; 0402_GENERAL
P1: ARM_DEBUG; ARM_DEBUG_CONNECTOR_10PIN_ALSO_SMD
P2: UART_TX; FIDUCIAL_1MM
P3: UART_RX; FIDUCIAL_1MM
P4: NFC; 2PIN_2MM_PITCH_SMD_PIN_STRIP
P6, P7: FIDUCIAL; FIDUCIAL_1MM
P8, P9: +BATT; 09MM_PLATED_HOLE
P11, P12: GND; 09MM_PLATED_HOLE
P17: I2C_SCL; FIDUCIAL_1MM
P18: I2C_SDA; FIDUCIAL_1MM
Q1: Q_PMOS_GSD; SOT-23
R1, R2: 470; 0402_GENERAL
R3: 100k; 0402_GENERAL
R4: 0; 0603_GENERAL
SW1, SW2: SW_PUSH; SW_SPST_EVQP2
U1: nRF52832; QFN-48_6X6MM_BOTPAD
U2: BME280
U3: GENERIC_DATAFLASH; SOIJ-8_5.3x5.3mm_Pitch1.27mm
U4: ADXL363; LGA16_3X3MM
Y1: 32K; 32X15MM_2PIN_CRYSTAL
Y2: 32M; 32X25MM_4PIN_CRYSTAL

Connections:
/ACC_INT1: U1.4, U4.11
/ANTENNA: C15.1, L3.1, R4.1
/BUTTON1: R3.1, SW1.2, U1.16
/LED1: D1.1, U1.20
/LED3: D2.1, U1.22
/RESET: P1.10, SW2.2, U1.24
/SPI_ACC_CS: U1.14, U4.8
/SPI_FLASH_CS: U1.6, U3.1
/SPI_HUMI_CS: U1.5, U2.2
/SPI_MISO: U1.40, U2.5, U3.2, U4.7
/SPI_MOSI: U1.37, U2.3, U3.5, U4.6
/SPI_SCK: U1.41, U2.4, U3.6, U4.4
/SWDCLK: P1.4, U1.25
/SWDIO: P1.2, U1.26
/SWO: P1.6, U1.21
/XC1: C14.2, U1.34, Y2.1
/XC2: C16.2, U1.35, Y2.3
GND: C1.2, C2.2, C3.2, C4.1, C5.1, C6.1, C7.2, C8.1, C9.1, C10.1, C11.1, C12.1, C13.1, C14.1, C15.2, C16.1, C17.2, C18.2, C19.2, P1.3, P1.5, P1.9, P11.1, P12.1, Q1.1, SW1.1, SW2.1, U1.31, U1.45, U1.49, U2.1, U2.7, U3.4, U4.5, U4.10, U4.12, U4.13, U4.16, Y2.2, Y2.4
unnamed: C3.1, L1.2, U1.46
unnamed: C4.2, U1.2, Y1.1
unnamed: C5.2, U1.3, Y1.2
unnamed: C6.2, P4.1, U1.11
unnamed: C7.1, P4.2, U1.12
unnamed: C11.2, U1.1
unnamed: C12.2, U1.32
unnamed: C13.2, U1.33
unnamed: C17.1, C19.1, L3.2
unnamed: D1.2, R1.1
unnamed: D2.2, R2.1
unnamed: L1.1, L2.2
unnamed: L2.1, U1.47
unnamed: P2.1, U1.9
unnamed: P3.1, U1.10
unnamed: P8.1, P9.1, Q1.3
unnamed: P17.1, U1.39
unnamed: P18.1, U1.38
unnamed: R4.2, U1.30
VDD: C1.1, C2.1, C8.2, C9.2, C10.2, C18.1, P1.1, Q1.2, R1.2, R2.2, R3.2, U1.13, U1.36, U1.48, U2.6, U2.8, U3.3, U3.7, U3.8, U4.1, U4.14, U4.15

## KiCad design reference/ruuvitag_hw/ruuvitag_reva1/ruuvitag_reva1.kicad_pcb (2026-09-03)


Board: 4 copper layers, 30.0 x 30.0 mm, 55 parts (0 on the bottom side), 24 nets.

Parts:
C1, C2, C3, C4, C5, C6, C8, C9, C10: 1u; 0402_GENERAL
C7, C12: NA; 0402_GENERAL
C11: 0_ohm_resistor; 0402_GENERAL
D1: LED; 0402_LED
L1: NA; 0402_GENERAL
L2: 2u2; 0603_GENERAL
L3: 0_ohm_resistor; 0402_GENERAL
P1: SPI_SCK; 05MM_PLATED_RECT_HOLE
P2: P0_1; 05MM_PLATED_RECT_HOLE
P3: P0_2; 05MM_PLATED_RECT_HOLE
P4: P0_3; 05MM_PLATED_RECT_HOLE
P5: ENERGY_HARVESTER_GND; WIDE_PLATED_HOLE2
P6: SPI_MISO; 05MM_PLATED_RECT_HOLE
P7: SPI_MOSI; 05MM_PLATED_RECT_HOLE
P8: P0_7; 05MM_PLATED_RECT_HOLE
P9: I2C_SCL; 05MM_PLATED_RECT_HOLE
P10: I2C_SDA; 05MM_PLATED_RECT_HOLE
P11: I2C_VDD; 05MM_PLATED_RECT_HOLE
P12: I2C_GND; 05MM_PLATED_RECT_HOLE
P13, P14: FIDUCIAL; FIDUCIAL_1MM
P18: EXTRNL_PWR_(DURING_FLASHING); 09MM_PLATED_HOLE
P19: UART_TX_(FLASHING); 09MM_PLATED_HOLE
P20: UART_RX_(FLASHING); 09MM_PLATED_HOLE
P21: GND_(FLASHING); 09MM_PLATED_HOLE
P22: OTP_6V8_(FLASHING); 09MM_PLATED_HOLE
P23: SWDIO; 09MM_PLATED_HOLE
P24: SWD_CLK; 09MM_PLATED_HOLE
P25: RST_(FLASHING); 09MM_PLATED_HOLE
P27, P32, P33: +BATT; WIDE_PLATED_HOLE
P28, P34: GND; 09MM_PLATED_HOLE
R6: 470; 0402_GENERAL
R7, R8: 10k; 0402_GENERAL
U1: DA1458X_WLCSP34; WLCSP34
U2: GENERIC_DATAFLASH; USON8_2X3MM
U3: LIS331DLH; LGA16_3X3MM
U4: OPT3001; USON6_2X2MM_WITHTHRMLPAD
U5: AT30TS74_WLCSP; WLCSP4
U6: Si7006; DFN6_3X3MM
U7: MS5637
U8: UVIS25
Y1: 16M; 32X25MM_4PIN_CRYSTAL

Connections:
/ACC_INT1: P2.1, U1.B5, U3.11
/ACC_INT2: P8.1, U1.E5, U3.9, U4.5, U8.7
/ANTENNA: C11.1, L1.2, U1.A4
/I2C_SCL: P9.1, R7.1, U1.E2, U4.4, U5.B2, U6.6, U7.3, U8.2
/I2C_SDA: P10.1, R8.2, U1.D2, U4.6, U5.B1, U6.1, U7.2, U8.4
/LED: D1.1, P19.1, U1.D5
/OTP_6V8_VIN: P22.1, U1.A6
/P1_4: P24.1, U1.C1
/P1_5: P23.1, U1.D1
/RST: P25.1, U1.E3
/SPI_ACC_CS: P3.1, U1.C5, U3.8
/SPI_FLASH_CS: P4.1, U1.C6, U2.1
/SPI_MISO: P6.1, P20.1, U1.D6, U2.2, U3.7
/SPI_MOSI: P7.1, U1.E6, U2.5, U3.6
/SPI_SCK: P1.1, U1.B6, U2.6, U3.4
/VDCDC: C1.1, C2.1, L2.2, U1.A2, U1.F2
GND: C1.2, C2.2, C3.2, C4.2, C5.2, C6.2, C7.2, C8.2, C9.2, C10.2, C12.2, L1.1, P5.1, P12.1, P21.1, P28.1, P34.1, R6.2, U1.A3, U1.A5, U1.B4, U1.C3, U1.D3, U1.D4, U1.E1, U1.F3, U2.4, U3.5, U3.10, U3.12, U3.13, U3.16, U4.2, U4.3, U4.7, U5.A2, U6.2, U6.7, U7.4, U8.3, U8.8, U8.9, Y1.2, Y1.4
unnamed: C7.1, L3.2
unnamed: C11.2, C12.1, L3.1
unnamed: D1.2, R6.1
unnamed: L2.1, U1.F1
unnamed: U1.A1, Y1.1
unnamed: U1.B1, Y1.3
VDD: C3.1, C4.1, C5.1, C6.1, C8.1, C9.1, C10.1, P11.1, P18.1, P27.1, P32.1, R7.2, R8.1, U1.E4, U1.F4, U2.3, U2.7, U2.8, U3.1, U3.14, U3.15, U4.1, U5.A1, U6.5, U7.1, U8.1, U8.6, U8.10

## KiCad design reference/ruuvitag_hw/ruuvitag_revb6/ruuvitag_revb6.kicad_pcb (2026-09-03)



Board: 4 copper layers, 45.0 x 45.0 mm, 57 parts (18 on the bottom side), 36 nets.

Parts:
C1: 0p8; 0402_CAP
C2, C8, C9, C11: 100n; 0402_CAP
C3: 1u; 0402_CAP
C4, C5, C12, C14, C16: 12p; 0402_CAP
C6, C7: 130p; 0402_CAP
C10, C18: 4u7; 0603_CAP
C13: 100p; 0402_CAP
C19: NA; 0402_CAP
D1: LED1; 0603_LED
D2: LED2; 0603_LED
L1: 15n; 0402_IND
L2: 10u; 0603_IND
L3: 3n9; 0402_IND
P1: TC2030; TAGCONNECT_TC2030-MCP-NL
P2, P3, P10, P11, P12, P13, P14, P15, P16, P17, P18, P19, P20, P21, P22, P23, P24, P25: TP; TEST_POINT_SMD_1MM
P4: NFC; NFC_RUUVITAG_REVB2
P5: GND; ABG-96_POS_BATT_CONTACT
P6, P7: FIDUCIAL; FIDUCIAL_1MM
P8, P9: +BATT; WIDE_PLATED_HOLE
Q1: Q_PMOS_GSD; SOT-23
R1, R2: 1k; 0402_RES
SW1, SW2: SW_PUSH; SKRKAEE010_BUTTON
U1: nRF52832; QFN-48_6X6MM_BOTPAD
U2: BME280
U4: LIS2DH12; LGA12_2X2MM
Y1: 32K; 32X15MM_2PIN_CRYSTAL
Y2: 32M; 20X16MM_4PIN_CRYSTAL

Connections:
+BATT: P1.1, P8.1, P9.1, P18.1, Q1.3
/ACC_INT1: U1.4, U4.12
/ACC_INT2: U1.8, U4.11
/ANTENNA: C19.1, L3.2
/BUTTON1: P15.1, SW1.2, U1.16
/LED1: D1.1, P14.1, U1.20
/LED2: D2.1, P13.1, U1.22
/RESET: P1.3, P22.1, SW2.2, U1.24
/SPI_ACC_CS: U1.10, U4.2
/SPI_HUMI_CS: U1.5, U2.2
/SPI_MISO: P3.1, U1.40, U2.5, U4.3
/SPI_MOSI: C12.1, P12.1, U1.37, U2.3, U4.4
/SPI_SCK: P2.1, U1.41, U2.4, U4.1
/SWDCLK: P1.4, P20.1, U1.25
/SWDIO: P1.2, P19.1, U1.26
/SWO: P1.6, P21.1, U1.21
/XC1: C14.2, U1.34, Y2.1
/XC2: C16.2, U1.35, Y2.3
GND: C1.2, C2.2, C3.2, C4.1, C5.1, C6.1, C7.2, C8.1, C9.1, C10.1, C11.1, C12.2, C13.1, C14.1, C16.1, C18.2, C19.2, P1.5, P5.1, P16.1, P23.1, Q1.1, SW1.1, SW2.1, U1.31, U1.45, U1.49, U2.1, U2.7, U4.5, U4.6, U4.7, U4.8, Y2.2, Y2.4
unnamed: C1.1, L3.1, U1.30
unnamed: C3.1, L1.2, U1.46
unnamed: C4.2, U1.2, Y1.1
unnamed: C5.2, U1.3, Y1.2
unnamed: C6.2, P4.1, U1.11
unnamed: C7.1, P4.2, U1.12
unnamed: C11.2, U1.1
unnamed: C13.2, U1.33
unnamed: D1.2, R1.1
unnamed: D2.2, R2.1
unnamed: L1.1, L2.2
unnamed: L2.1, U1.47
unnamed: P10.1, U1.6
unnamed: P11.1, U1.7
unnamed: P24.1, U1.43
unnamed: P25.1, U1.42
VDD: C2.1, C8.2, C9.2, C10.2, C18.1, P17.1, Q1.2, R1.2, R2.2, U1.13, U1.36, U1.48, U2.6, U2.8, U4.9, U4.10

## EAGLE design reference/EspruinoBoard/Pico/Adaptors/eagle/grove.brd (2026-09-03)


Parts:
A1, A2: GROVE-4P-2.0-3470130P1; 4P-2.0
D1, D2: GROVE-4P-2.0-3470130P1; 4P-2.0
I2C2, I2C3: GROVE-4P-2.0-3470130P1; 4P-2.0
J2: JST-2P-SMD-PW-3410050P1; 2P-SMD-2.0-90D
R1, R2, R3, R4: 4.7k; R0805
U$1: ESPRUINO_PICO_0.1
UART: GROVE-4P-2.0-3470130P1; 4P-2.0

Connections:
3.3V: R1.1, R2.1, R3.1, R4.1, U$1.3.3V
A5: A1.1, U$1.A5
A6: A1.2, U$1.A6
A7: A2.1, U$1.A7
A8: I2C3.1, R4.2, U$1.A8
B1: A2.2, U$1.B1
B3: I2C2.2, R1.2, U$1.B3
B4: I2C3.2, R3.2, U$1.B4
B5: D1.1, U$1.B5
B6: U$1.B6, UART.2
B7: U$1.B7, UART.1
B10: I2C2.1, R2.2, U$1.B10
B13: D1.2, U$1.B13
B14: D2.1, U$1.B14
B15: D2.2, U$1.B15
GND: A1.4, A2.4, D1.4, D2.4, I2C2.4, I2C3.4, J2.3, J2.4, J2.-, U$1.GND, UART.4
unnamed: J2.+, U$1.BAT
VCC: A1.3, A2.3, D1.3, D2.3, I2C2.3, I2C3.3, U$1.5V, UART.3


Board: 2 copper layers, 35.6 x 40.6 mm, 13 parts (0 on the bottom side), 18 nets.

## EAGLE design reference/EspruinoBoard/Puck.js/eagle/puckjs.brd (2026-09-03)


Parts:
B1: MJTP1243
C1: 10uf; C0805
C2: 1uf; C0402
C3: 4.7uf; C0402
C4, C5, C6: 100nf; C0402
CTUNE1, CTUNE2: TBD; C0402
D1: RED; LED-0603
D2: GREEN; LED-0603
D3: BLUE; LED-0603
D4: IR; LED-0603
D6: DIODESOD-523; SOD-523
D7: NOFIT; SOD-523
J1, J2: PINHD-1X04_2.54-S; 1X04-S
J1A: PINHD-1X04; 1X04M2
J3: NOFIT; SOT23
J4, J9: PINHD-1X1; 1X01
J5: NOFIT; R1206
J6, J7: NOFIT; R0603
J8: KEYSTONE-3003
L1: 15NH-300MA; L0402
L2: 10UH-50MA; L0603
R1: 120; R0402
R2, R3, R4: 47; R0402
R5: 1M; R0402
RST: TPTP15R; TP15R
SWCK: TPTP15R; TP15R
SWIO: TPTP15R; TP15R
U1: MDBT42Q; MDBT40
U2: MAG3110; DFN-10

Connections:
BTN1: B1.2 (3), U1.P13 (P13-P0.00/XL1)
CAPSENSE_RX: J9.1, R5.2, U1.P25 (P25-P0.11)
CAPSENSE_TX: R5.1, U1.P26 (P26-P0.12)
D1: J1.4, J1A.4, U1.P14 (P14-P0.01/XL2)
D2: J1.3, J1A.3, U1.P15 (P15-P0.02/AIN0)
D6: J3.3 (D), U1.P19 (P19-P0.06)
D7: J3.1 (G), U1.P20 (P20-P0.07)
D8: J3.2 (S), U1.P21 (P21-P0.08)
D13: J7.1, U1.P27 (P27-P0.13)
D14: J6.1, U1.P28 (P28-P0.14)
D15: J7.2, U1.P29 (P29-P0.15)
D16: J6.2, U1.P30 (P30-P0.16)
D28: J2.4, U1.P5 (P5-P0.28/AIN4)
D29: J2.3, U1.P6 (P6-P0.29/AIN5)
D30: J2.2, U1.P7 (P7-P0.30/AIN6)
D31: J2.1, U1.P8 (P8-P0.31/AIN7)
GND: C1.1, C2.2, C3.1, C4.2, C5.2, C6.1, CTUNE1.1, CTUNE2.1, D6.A, J1.1, J1A.1, J8.V-, R1.1, R2.1, R3.1, U1.P1 (P1-GND), U1.P12 (P12-GND), U1.P24 (P24-GND), U1.P39 (P39-GND), U2.5 (GND), U2.10 (GND)
LEDB: D3.+, U1.P16 (P16-P0.03/AIN1)
LEDG: D2.+, U1.P17 (P17-P0.04/AIN2)
LEDIR1: D4.-, U1.P3 (P3-P0.26)
LEDIR2: R4.2, U1.P2 (P2-P0.25)
LEDR: D1.+, U1.P18 (P18-P0.05/AIN3)
MAG_INT: U1.P31 (P31-P0.17), U2.9 (INT1)
MAG_SCL: U1.P33 (P33-P0.19), U2.7 (SCL)
MAG_SDA: U1.P34 (P34-P0.20), U2.6 (SDA)
MAG_VDD: C6.2, U1.P32 (P32-P0.18), U2.2 (VDD), U2.8 (VDDIO)
unnamed: D1.-, R1.2
unnamed: D2.-, R2.2
unnamed: D3.-, R3.2
unnamed: J4.1, U1.P4 (P4-P0.27)
unnamed: SWCK.TP, U1.P36 (P36-SWDCLK)
unnamed: SWIO.TP, U1.P37 (P37-SWDIO)
unnamed: J5.2, U1.P40 (P40-P0.24)
unnamed: J5.1, U1.P41 (P41-P0.23)
unnamed: D4.+, R4.1
unnamed: C2.1, L1.1, U1.P9 (P9-DEC4)
unnamed: L1.2, L2.1
unnamed: C5.1, U2.1 (CAP-A)
unnamed: L2.2, U1.P10 (P10-DCC)
unnamed: RST.TP, U1.P35 (P35-P0.21/NRST)
unnamed: C4.1, U2.4 (CAP-R)
NFC: CTUNE1.2, CTUNE2.2, U1.P22 (P22-P0.09/NFC1), U1.P23 (P23-P0.10/NFC2)
VDD: B1.1, C1.2, C3.2, D6.K (C), D7.A, D7.K (C), J1.2, J1A.2, J8.V+1 (V+), J8.V+2 (V+), U1.P11 (P11-VDD)

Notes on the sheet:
We'll use internal nRF pullups for I2C
Use nRF IO for VDD so we can turn off MAG3110 when not needed (2uA even in sleep)
To bring IO out on useful pads
allow LiPo 2032s to be used if diode in here
Reverse volt protection
NOTE: The RED LED aptd1608lseck has a the polarity mark in the opposite direction to all the others!


Board: 2 copper layers, 28.6 x 28.6 mm, 37 parts (1 on the bottom side), 43 nets.

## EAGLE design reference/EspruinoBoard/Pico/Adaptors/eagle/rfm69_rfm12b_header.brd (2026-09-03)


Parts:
ANT: PINHD-1X1; 1X01
J1: JST-2P-SMD-PW-3410050P1; 2P-SMD-2.0-90D
U$1: ESPRUINO_PICO_0.1
U$2: RFM12B
U$3: RFM69

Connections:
3.3V: U$1.3.3V, U$2.VDD (VCC), U$3.P$8 (3V3)
CS: U$1.B10, U$2.SEL, U$3.P$15 (NSS)
GND: J1.3, J1.4, J1.-, U$1.GND, U$2.GND, U$3.P$9 (GND), U$3.P$11 (GND_2)
IRQ: U$1.A7, U$2.IRQ, U$3.P$2 (DIO0)
MISO: U$1.B14, U$2.SDO, U$3.P$13 (MISO)
MOSI: U$1.B15, U$2.SDI, U$3.P$14 (MOSI)
unnamed: ANT.1, U$2.ANT, U$3.P$10 (ANA)
unnamed: J1.+, U$1.BAT
RST: U$1.B1, U$3.P$1 (RST)
SCK: U$1.B13, U$2.SCK, U$3.P$12 (SCK)


Board: 2 copper layers, 52.4 x 18.4 mm, 5 parts (1 on the bottom side), 10 nets.

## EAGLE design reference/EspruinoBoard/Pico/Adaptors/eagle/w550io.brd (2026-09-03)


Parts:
J1, J3: PINHD-1X8; 1X08
J2: PINHD-1X6; 1X06
U$1: ESPRUINO_PICO_SMD

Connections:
3V3: J1.7, J1.8, J2.1, U$1.3.3V
GND: J1.1, J1.2, J2.6, U$1.GND
INT: J2.5
MISO: J1.4, U$1.B14
MOSI: J1.3, U$1.B15
unnamed: J3.1, U$1.A4
unnamed: J3.2, U$1.A3
unnamed: J3.3, U$1.A2
unnamed: J3.4, U$1.A1
unnamed: J3.5, U$1.A0
unnamed: J3.6, U$1.A10
unnamed: J3.7, U$1.B9
unnamed: J3.8, U$1.B8
RDY: J2.2
RST: J2.3
SCLK: J1.5, U$1.B13
SCS: J1.6, U$1.B10


Board: 2 copper layers, 28.1 x 26.8 mm, 4 parts (0 on the bottom side), 14 nets.

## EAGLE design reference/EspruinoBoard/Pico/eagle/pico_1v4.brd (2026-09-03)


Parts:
B1: KMR421NG
C1: 4.7uF/4V; C0402
C2: 0.1uF/4V; C0402
C3: 0.1uF/16V; C0402
C4: 10uF/4V; AVX-A
C5, C6: 8pF; C0402
D1: Schottky, SOD-323; SOD323-W
D2: RED; LED-0402
D3: GREEN; LED-0402
FUSE: R-EU_R0603; R0603
J1, J2: PINHEAD9
J3, J7: SOLDERJUMPER
J4A: USB_TYPE_A_ONBOARD; USB_TYPEA_ONBOARD
J4B: USB_MINI
J5: PHR-2; JST-SMD-2.0-90D
J6: CON-SWD
J8: PINHEAD-1.27-8X1
J9: PINHEAD-1.27-3X1
Q1: FDN358P; SOT23
R1, R5: 100; R0402
R2: 100k; C0402
R3, R4, R6: 100k; R0402
U1: STM32F401CDU6; UFQFPN48
U2: MCP1703T-3302E/CB; SOT23
U$1: USB
X1: 8Mhz; 3P-SMD-3.6X1.3
X2: 32.768k; 2P-SMD-2.05X1.2

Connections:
5V: C3.1, D1.C, J2.2, J9.P$3, Q1.2 (S), U2.3 (VIN)
A0: J8.P$4, U1.P10 (PA0)
A1: J8.P$5, U1.P11 (PA1)
A2: J8.P$6, U1.P12 (PA2)
A3: J8.P$7, U1.P13 (PA3)
A4: J8.P$8, U1.P14 (PA4)
A5: J1.9, U1.P15 (PA5)
A6: J1.8, U1.P16 (PA6)
A7: J1.7, U1.P17 (PA7)
A8: J2.9, U1.P29 (PA8)
A10: J8.P$3, U1.P31 (PA10)
A11: J4A.P2 (DM), J4B.2 (DM), U1.P32 (PA11), U$1.DM
A12: J4A.P3 (DP), J4B.3 (DP), U1.P33 (PA12), U$1.DP
A13: J6.JTMS, U1.P34 (PA13)
A14: J6.JTCK, U1.P37 (PA14)
A15: J6.SWO, U1.P38 (PA15)
B0_BAT_FET: J3.P$2, U1.P18 (PB0)
B1: J1.6, U1.P19 (PB1)
B2: R5.2, U1.P20 (PB2)
B3: J2.4, U1.P39 (PB3)
B4: J2.5, U1.P40 (PB4)
B5: J2.6, U1.P41 (PB5)
B6: J2.7, U1.P42 (PB6)
B7: J2.8, U1.P43 (PB7)
B8: J8.P$1, U1.P45 (PB8)
B9: J8.P$2, U1.P46 (PB9)
B10: J1.5, U1.P21 (PB10)
B12: R1.2, U1.P25 (PB12)
B13: J1.4, U1.P26 (PB13)
B14: J1.3, U1.P27 (PB14)
B15: J1.2, U1.P28 (PB15)
BOOT0: J7.P$1, R3.2, U1.P44 (BOOT0)
C13: B1.2A (P2), B1.2B (P2), J7.P$2, U1.P2 (PC13)
GND: C1.3 (2), C2.3 (2), C3.3 (2), C4.- (2), C5.3 (2), C6.3 (2), D2.-, D3.-, J2.1, J4A.P4 (GND), J4B.5 (GND), J4B.P$1 (GND), J4B.P$2 (GND), J4B.P$3 (GND), J4B.P$4 (GND), J5.3, J5.4, J5.- (2), J6.GND, J9.P$1, R3.1, R4.2, U1.GND (PKG_GND), U1.P8 (VSSA/VREF-), U1.P23 (VSS1), U1.P35 (VSS2), U1.P47 (VSS3), U2.1 (VSS), X1.2
unnamed: C5.1, U1.P4 (PC15/OSC32_OUT), X2.1
unnamed: C6.1, U1.P3 (PC14/OSC32_IN), X2.2
unnamed: U1.P5 (PH0/OSC_IN), X1.1
unnamed: U1.P6 (PH1/OSC_OUT), X1.3
unnamed: D2.+, R5.1
unnamed: D3.+, R1.1
unnamed: J3.P$1, Q1.1 (G), R6.2
unnamed: C1.1, U1.P22 (VCAP1)
NRST: J6.NRST, R2.1, U1.P7 (NRST)
VBAT: J1.1, J5.+ (1), Q1.3 (D)
VDD: B1.1A (P1), B1.1B (P1), C2.1, C4.+ (1), J2.3, J6.VDD, J9.P$2, R2.3 (2), U1.P1 (VBAT), U1.P9 (VDDA/VREF+), U1.P24 (VDD1), U1.P36 (VDD2), U1.P48 (VDD3), U2.2 (VOUT)
VUSB: FUSE.2, J4A.P1 (VCC), J4B.1 (VCC), U$1.VUSB
VUSB_FUSED: D1.A, FUSE.1, R4.1, R6.1, U1.P30 (PA9)

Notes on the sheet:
When jumper shorted BAT_FET can be: pull 3.3v: slow charge pull 0v: scary fast charge or powered output
B2=BOOT1 So we ensure that it is pulled down to 0
J6: SWD/JTAG debug



Board: 2 copper layers, 33.2 x 15.1 mm, 33 parts (23 on the bottom side), 47 nets.

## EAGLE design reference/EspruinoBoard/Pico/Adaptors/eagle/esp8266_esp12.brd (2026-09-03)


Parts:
C1: 10uF; C1206
R1, R2, R3: 4.7k; R1206
U$1: ESPRUINO_PICO_HALFSMD
X1: ESP-12

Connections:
+3V3: C1.1, R1.2, R2.2, R3.2, U$1.3.3V, X1.3 (CH_PD), X1.8 (VCC)
ESP_RX: U$1.A2, X1.15 (RXD)
ESP_TX: U$1.A3, X1.16 (TXD)
GND: C1.2, U$1.GND, X1.9 (GND)
unnamed: R3.1, X1.11 (GPIO2)
unnamed: R2.1, X1.12 (GPIO0)
unnamed: R1.1, X1.1 (RESET), X1.4 (GPIO16)



Board: 2 copper layers, 40.3 x 18.3 mm, 6 parts (4 on the bottom side), 7 nets.

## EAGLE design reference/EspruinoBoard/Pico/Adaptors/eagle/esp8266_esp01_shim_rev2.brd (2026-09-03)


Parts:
C1: 22uF; C1210
ESP8266: PINHD-2X4; 2X04
IC2: 78L 3.3v; TO92
U$1: ESPRUINO_PICO_0.05_SMALL

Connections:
ESP_CH_PD: ESP8266.6, U$1.B9
ESP_GPIO0: ESP8266.3, U$1.A1
ESP_GPIO2: ESP8266.5, U$1.A0
ESP_RST: ESP8266.4, U$1.A10
ESP_RX: ESP8266.1, U$1.A2
ESP_TX: ESP8266.8, U$1.A3
GND: C1.2, ESP8266.7, IC2.2 (GND), U$1.GND_2 (GND)
unnamed: IC2.3 (VI), U$1.5V_2 (5V)
VCC: C1.1, ESP8266.2, IC2.1 (VO), U$1.3.3V_2 (3.3V)

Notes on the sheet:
Farnell 1759435


Board: 2 copper layers, 17.1 x 10.7 mm, 4 parts (0 on the bottom side), 9 nets.

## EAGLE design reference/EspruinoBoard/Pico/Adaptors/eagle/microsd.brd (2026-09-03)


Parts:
J1: MICRO-SDCARD-CONNECTOR-3300060P1; 9P-SMD-W/-RING
R1: R-EU_R1206; R1206
U$1: ESPRUINO_PICO_SMDONLY

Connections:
unnamed: J1.4 (VDD), R1.1, U$1.3.3V
unnamed: J1.3 (DI), U$1.B15
unnamed: J1.7 (DO), U$1.B14
unnamed: J1.5 (SCLK), U$1.B13
unnamed: J1.2 (CS), R1.2, U$1.B1



Board: 2 copper layers, 23.8 x 17.8 mm, 3 parts (2 on the bottom side), 5 nets.

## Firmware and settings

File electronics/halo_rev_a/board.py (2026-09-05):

"""halo revision A — the board. Ø26.00 mm, four layers, notched and keyed.

    cd ~/dev/ce-workshop
    ce-pcb/bin/pcb ce-designs/halo/electronics/halo_rev_a/board.py

LANE B1. The netlist is NEVER RETYPED here: it is read back out of
`out/halo_rev_a.kicad_sch` with `cepcb.schematic.netlist_of_sch`, so the
copper and the drawing cannot drift apart, and `bin/sch check` grades them
against each other afterwards. If a pin moves on the sheet it moves here.

---------------------------------------------------------------------------
THE OUTLINE IS Ø26.00, AND THE BRIEF SAID Ø31.87. THE BRIEF IS QUOTING THE
SHELL.
---------------------------------------------------------------------------
SPEC.md §4 gives 31.87 mm as "maximum outer diameter … occurs at z = 4.34 mm",
which is the moulded shell's widest section, not the board. Lane M's
mechanical source — ce-designs/halo/design.py, the single place every
mechanical number in this project is typed — fixes the board:

    D_PCB         = 26.00     the disc
    T_PCB         =  0.600    its thickness
    PCB_NOTCH_DEG = 26.0      three keying notches
    R_PCB_NOTCH   = 12.60     how deep they cut
    TAB_ANGLES    = 0/120/240 where they are
    D_CARRIER_RIM = 26.20     the carrier's locating rim = Ø26.00 + 0.10

A Ø31.87 board cannot fit inside a Ø31.87 shell, and a board that ignores
the notches goes in the wrong way round and lands the antenna feed on the
wrong carrier trace — which is exactly what lane M put the notches there to
prevent. So the board is Ø26.00 with the notches, and this paragraph is the
record of the substitution rather than a silent correction.

---------------------------------------------------------------------------
WHAT DECIDES EVERY PLACEMENT: THE CELL IS UNDER THE BOARD
---------------------------------------------------------------------------
design.py again: Z_CELL_TOP = 4.022, Z_DECK_TOP = 4.600. A Ø20.0 mm steel
can sits 0.578 mm below the middle of this disc, spanning R 0 to R 10.0.
That single fact writes the floorplan:

  * R 10.0 -> 13.0 is THE ONLY ANNULUS WITH NO BATTERY UNDER IT, 3.0 mm
    wide. Both antennas have to live there or live over steel.
  * The 2.4 GHz antenna gets a sector of it with ALL FOUR LAYERS cleared
    beneath — an inverted-F over a ground plane is a short circuit, and an
    inverted-F over a battery can is not an antenna anybody can predict.
  * The NFC coil takes the rest of the annulus on the BOTTOM layer, so the
    two are not on the same copper. 13.56 MHz and 2.44 GHz do not couple
    strongly, but their copper competes for the same 3 mm and SPEC.md §4
    already flagged that as lane C's warning.
  * Actives go on the BOTTOM (B.Cu), passives on the TOP (F.Cu). Not for
    signal-integrity reasons — because of height, below.

---------------------------------------------------------------------------
THE HEIGHT DELTA, MEASURED, AND NOT ABSORBED
---------------------------------------------------------------------------
Lane M's stack allows, per design.py's own budget table:

    top face, inside Ø21.2      0.400 mm   (the bender's moving gap)
    top face, Ø21.2 -> Ø26.0    ~0.9-1.2 mm (the shell's inner surface)
    bottom face, over the cell   0.578 mm   (4.600 - 4.022)
    bottom face, over a finger   0.428 mm   (4.600 - 4.172)

Against that, the parts this circuit needs:

    QFN-48 6x6 (U1)             0.85 mm    OVER by 0.27 mm on the best face
    0603 inductor (L1)          0.90 mm    OVER by 0.32 mm
    3215 crystal (X1)           0.90 mm    OVER by 0.32 mm
    USON-8 (U3)                 0.60 mm    OVER by 0.02 mm
    LGA-12 (U2)                 0.70 mm    OVER by 0.12 mm
    0402 (bulk C9-C12)          0.55 mm    fits, 0.03 mm spare
    0201 (everything else)      0.33 mm    fits

FIVE OF THE SEVEN PART CLASSES DO NOT FIT. This is not a rounding error and
it is not this lane's to close alone — the stack belongs to lane M. The
board is drawn anyway, because the netlist, the outline, the keep-outs and
the routing are all correct regardless of who finds the 0.32 mm, and a board
that is not drawn teaches nobody anything. `report()` at the bottom prints
the table above every run so it cannot be forgotten, and
electronics/README.md carries the four candidate resolutions.

---------------------------------------------------------------------------
WHAT THIS BOARD DOES NOT CLAIM
---------------------------------------------------------------------------
  * THE ANTENNA GEOMETRY IS THIS FILE'S, NOT ce-rf's. Lane T3 owns the
    shape and, as of this writing, its two round-board cases resonate at
    4.0 and 5.8 GHz instead of 2.44 and it is retuning — on a Ø30 outline,
    which is not this board either. So the AE1 element drawn here is a
    PARAMETRIC PLACEHOLDER at a length computed from a quarter wavelength,
    put where the copper has to go, so that ce-rf has real geometry to
    solve instead of a blank annulus. Its S11 is CANNOT DETERMINE until
    ce-rf measures THIS copper. It is not asserted to work.
  * THE NFC COIL'S INDUCTANCE IS UNMEASURED, so C24/C25's 130 pF is a
    placeholder, exactly as the schematic says (X-2).
  * A PASSING DRC MEANS MANUFACTURABLE, NOT CORRECT. Whether the circuit
    works is the schematic's question and the simulators'.
"""
# AE1 TOPOLOGY IS NOT SETTLED, and this file used to call it three things.
# It was described here as a "meandered quarter-wave monopole", an "inverted-F"
# and an "inverted-L monopole" in three separate places. Those are three
# different topologies with three different counterpoise requirements, so a
# reader could not tell what was drawn and neither could anyone setting up a
# solver port. The names were removed rather than one being picked, because
# picking one would assert something nobody has established.
#
# What IS established, measured: the element is a meandered trace on F.Cu only,
# nine teeth, conductor 24.49100 mm against a quarter-wave target of the same,
# error -0.00000, copper R11.1920-R12.2000 at theta 256-340 degrees, fed at one
# end with the other end open. Whether that behaves as a monopole, an
# inverted-F or an inverted-L on THIS ground depends on the counterpoise, which
# is what ce-rf is still trying to characterise -- three hypotheses refuted so
# far (DECISIONS.md D26b-D26e).
#
# Call it "the AE1 element" until a solve identifies its mode.

import json
import math
import os
import sys

from cepcb import Board, find                                      # noqa: F401
from cepcb import kicad as _kicad
from cepcb.schematic import netlist_of_sch

HERE = os.path.dirname(os.path.abspath(__file__))

# ---------------------------------------------------------------------------
# REGISTER halo's OWN .pretty. `cepcb.footprint_libraries()` scans only
# KiCad's SharedSupport tree, so a project-local library is invisible to
# `load_footprint()` and to `find()`. Priming the cache here rather than
# editing ce-pcb, because lane T1 owns that repo and a shared tool should not
# grow a halo-shaped hole. THIS IS A GAP IN ce-pcb, NOT A HALO PREFERENCE:
# every board with a part the catalogue does not carry hits it, and it is
# filed to T1 as a P11 item (a `libs=` argument on Board, or a read of the
# project's own fp-lib-table, would close it for everyone).
# ---------------------------------------------------------------------------
_kicad.footprint_libraries()                       # build the cache, then add
_kicad._LIB_CACHE["halo"] = os.path.join(HERE, "halo.pretty")
_kicad._INDEX = None                               # so find() re-indexes

# The etched geometry lives in footprints.py and is IMPORTED, not re-typed.
# The antenna element and the NFC winding are drawn here as tracks; their
# radii, widths and turn counts are that file's, so a change there moves the
# copper here and cannot leave the two disagreeing.
if HERE not in sys.path:
    sys.path.insert(0, HERE)
import footprints as fpg                                          # noqa: E402
SCH = os.path.join(HERE, "out", "halo_rev_a.kicad_sch")
OUT = os.path.join(HERE, "out", "halo_rev_a.kicad_pcb")

# ==========================================================================
# 1. LANE M'S NUMBERS. Typed once, cited, never re-derived.
# ==========================================================================
D_PCB = 26.00
T_PCB = 0.600
PCB_NOTCH_DEG = 26.0
R_PCB_NOTCH = 12.60
TAB_ANGLES = (0.0, 120.0, 240.0)
D_CELL = 20.00
Z_CELL_TOP = 4.022
Z_DECK_TOP = 4.600
D_LAND = 21.20                 # the bender's bond land -> the 0.400 mm rule
D_SPEAKER_KO = 25.75           # Apple: "DO NOT OBSTRUCT THIS AREA"
D_ANTENNA_KO = 37.31           # Apple: no metal above or below - HOST scope
M_SRC = "ce-designs/halo/design.py (lane M)"

R = D_PCB / 2.0
CX = CY = R                    # the board's frame has its origin at a corner

# Derived height allowances, computed rather than quoted.
H_TOP_INNER = 0.400            # design.py's own keep-out on part:halo-pcb-blank
H_BOT_CELL = round(Z_DECK_TOP - Z_CELL_TOP, 3)          # 0.578

# ==========================================================================
# 2. THE FLOORPLAN, in polar coordinates, because a disc has no corners
# ==========================================================================
R_CELL = D_CELL / 2.0          # 10.0 - nothing below this radius is clear
R_ANNULUS_IN = 10.20           # 0.2 mm margin off the can's edge
R_ANNULUS_OUT = 12.70          # 0.3 mm in from the edge, for the router bit

# The three notches eat 26 deg each at 0/120/240, so the clear arcs are
# 13->107, 133->227 and 253->347. The antenna takes the middle of the first.
ANT_SECTOR_MID = 60.0
ANT_SECTOR_ARC = 88.0          # 16 -> 104 deg, inside the 13->107 clear arc


#: Where the antenna is fed, and where the coil's two halves meet. Both are
#: angles because everything on a disc is.
ANT_FEED_DEG = 20.0

#: Where the NFC winding's two halves meet, computed the same way the spiral
#: is so the net tie lands ON the conductor rather than near it.
# MEASURED WRONG 2026-09-04, AND THE SHAPE OF THE MISTAKE IS WORTH KEEPING.
# This read `20.0 + 360.0 * 3 - 40.0`, a hand-typed copy of a THREE-turn coil
# that was cut to two turns in footprints.py and never copied back. The tie
# was therefore placed at 180 deg and radius 10.3167 while the winding's gap
# is at 380 deg and radius 10.4486: 160 degrees and 20 mm away from the
# conductor it is supposed to join, on a Ø26 mm board. Nothing failed - the
# tie was simply a two-pad island in the middle of the coil, and the coil was
# open. Derived from fpg.NFC_TURNS now, and CHECKED against the spiral's own
# midpoint below, because the defect was not the arithmetic, it was that two
# expressions for one number were allowed to disagree in silence.
_NFC_A0_PRE = 20.0
_NFC_A1_PRE = _NFC_A0_PRE + 360.0 * fpg.NFC_TURNS
NFC_TIE_DEG_PRE = (_NFC_A0_PRE + _NFC_A1_PRE) / 2.0
NFC_TIE_R_PRE = fpg.NFC_R_OUT - (fpg.NFC_W + fpg.NFC_GAP) * \
    (NFC_TIE_DEG_PRE - _NFC_A0_PRE) / 360.0


def at_r(r, deg):
    """Polar placement. `deg` is CCW from +X with +Y up, so 90 is the top."""
    a = math.radians(deg)
    return (CX + r * math.cos(a), CY + r * math.sin(a))


def outline_polygon(segments=360):
    """The Ø26.00 disc with three 26 deg notches cut to R12.60.

    Reproduces `pcb_blank()` in design.py: `_sector(p, R_PCB_NOTCH,
    D_PCB/2+0.5, ..., a, PCB_NOTCH_DEG, op="cut")` — `a` is the sector's
    CENTRE angle and PCB_NOTCH_DEG its total arc, which is the convention
    `battery_contact()` in the same file uses.
    """
    half = PCB_NOTCH_DEG / 2.0
    notches = [(a - half, a + half) for a in TAB_ANGLES]

    def in_notch(deg):
        d = deg % 360.0
        for lo, hi in notches:
            lo %= 360.0
            hi %= 360.0
            if lo <= hi:
                if lo <= d <= hi:
                    return True
            elif d >= lo or d <= hi:          # the notch straddling 0 deg
                return True
        return False

    pts = []
    for i in range(segments):
        deg = 360.0 * i / segments
        rr = R_PCB_NOTCH if in_notch(deg) else R
        pts.append(at_r(rr, deg))
    return pts


#: 360 steps, not 180, and the reason is 1.7 um. A ring drawn as chords sits
#: INSIDE the circle it approximates by r(1-cos(pi/steps)); at 180 steps and
#: r 9.74 that is 0.0015 mm, so a band asked for 0.30 mm was drawn at 0.2983
#: and every report of it would have been a number nobody asked for. At 360 it
#: is 0.0004 mm. The cost is 360 more points in one zone outline.
def annulus_polygon(r_in, r_out, steps=360):
    """A full ring, as one polygon with a bridge so it is simply connected.

    KiCad zones have no holes, so a ring is drawn as an outer circle walked
    forwards and an inner circle walked back, meeting at a seam. The seam is
    zero-width and the fill closes over it.
    """
    pts = [at_r(r_out, 360.0 * i / steps) for i in range(steps + 1)]
    pts += [at_r(r_in, 360.0 - 360.0 * i / steps) for i in range(steps + 1)]
    return pts


def sector_polygon(r_in, r_out, mid_deg, arc_deg, steps=48):
    """An annular sector, for keep-outs and for clearing the antenna's ground."""
    a0, a1 = mid_deg - arc_deg / 2.0, mid_deg + arc_deg / 2.0
    pts = [at_r(r_out, a0 + (a1 - a0) * i / steps) for i in range(steps + 1)]
    pts += [at_r(r_in, a1 - (a1 - a0) * i / steps) for i in range(steps + 1)]
    return pts


# ==========================================================================
# 3. THE BOARD
# ==========================================================================
b = Board("halo_rev_a", outline=outline_polygon(), layers=4,
          title="halo rev A - Ø26.00 mm, 4 layer, nRF54L10 Find My tag")

# 0.127 mm / 0.127 mm is JLCPCB's standard 4-layer process, and this board
# needs all of it: the nRF54L10 is a 0.4 mm pitch QFN-48, so the gap between
# adjacent lands is about 0.20 mm and an escape trace has to pass through it.
# Anything looser than 5 mil cannot leave the part at all.
b.rules(clearance=0.127, track=0.127, min_track=0.127,
        via=0.45, via_drill=0.25, hole_clearance=0.20,
        why="JLCPCB standard 4-layer capability (ce-pcb/data/stackups.json, "
            "jlcpcb-4layer). The nRF54L10-QFAA is a 0.4 mm pitch QFN-48 and "
            "its escape does not exist at a looser clearance. Via 0.45/0.25 "
            "rather than 0.6/0.3 for the same reason: a 0.6 mm via does not "
            "fit between two 0.4 mm pitch lands.")

# -- keep-outs, and they are three DIFFERENT KINDS OF CLAIM ----------------
# 1. The cell. A Ø20 steel can 0.578 mm below the board is not a copper rule
#    — copper under it is fine and the ground plane wants to be there — it is
#    a KEEP-OUT ON PARTS AND ON THE ANTENNA. Recorded on one layer (B.Cu) as
#    a footprint keep-out so KiCad's DRC reports anything mounted into it.
b.keepout(diameter=D_CELL + 0.4, center=(CX, CY), layers=["B.Cu"],
          tracks=False, vias=False, pads=False, pours=False, footprints=False,
          scope="board", name="cell-body-HEIGHT-0.578mm",
          why="DOCUMENTATION, NOT AN ENFORCED RULE, and the distinction is "
              "the point. A Ø20.0 mm CR2032 sits 0.578 mm below this face "
              "(%s: Z_CELL_TOP 4.022, Z_DECK_TOP 4.600). What is forbidden "
              "here is HEIGHT, not presence: a 0201 at 0.33 mm is welcome "
              "and a QFN-48 at 0.85 mm is not. KiCad rule areas have no "
              "height axis, so forbidding footprints outright would fail "
              "every part on the bottom face including the ones that fit - "
              "an alarm that is always on tells you nothing. The real check "
              "is arithmetic and it is in height_check() below, which grades "
              "each part against the allowance at its own radius." % M_SRC)

# 2. The bender. Apple's Ø25.75 "do not obstruct" is acoustic, and lane M
#    turned it into the number that binds: nothing taller than 0.400 mm on
#    the top face inside Ø21.2. Also not a copper rule.
b.keepout(diameter=D_LAND, center=(CX, CY), layers=["F.Cu"],
          tracks=False, vias=False, pads=False, pours=False, footprints=False,
          scope="board", name="bender-diaphragm-HEIGHT-0.400mm",
          why="DOCUMENTATION, same reason as the cell. The Murata 7BB-20-3 "
              "is bonded to the shell's Ø21.2 mm land and needs a 0.680 mm "
              "moving gap, so %s limits top-face parts inside this circle to "
              "0.400 mm. Height again, not presence: 0201 (0.33 mm) passes "
              "and every active on this board does not. Graded in "
              "height_check()." % M_SRC)

# 3. Apple's Ø37.31 "no metal above or below" is LARGER THAN THE PRODUCT, so
#    it cannot mean "no board". It governs whatever the puck is fitted into.
#    scope="host" makes keepout_check() grade it CANNOT DETERMINE with the
#    measurement rather than quietly passing a rule it cannot see.
# FORBIDS NOTHING, deliberately. Created with the default forbids first, and
# because Ø37.31 covers every square millimetre of a Ø26 board, KiCad's DRC
# reported ordinary parts as items_not_allowed inside it - a rule area that
# outlaws the entire board. A host-scope region is a constraint on whatever
# the puck is fitted INTO and this board cannot enforce it, so it is drawn
# and documented and enforces nothing.
b.keepout(diameter=D_ANTENNA_KO, center=(CX, CY), layers="*",
          tracks=False, vias=False, pads=False, pours=False, footprints=False,
          scope="host", name="antenna-host-clearance",
          why="SPEC.md §4, Apple's own callout: no metal above or below, "
              "Ø37.31 mm - 11.44 mm LARGER than this board. Every square "
              "millimetre of halo is inside it, so it is a constraint on the "
              "HOST, and this board cannot grade it.")

# 4. The antenna's own ground clearance. This one IS a copper rule and it is
#    the load-bearing one: an inverted-F needs its counterpoise removed from
#    under the radiating element or it does not radiate.
ANT_CLEAR = sector_polygon(R_ANNULUS_IN - 0.3, R - 0.05,
                           ANT_SECTOR_MID, ANT_SECTOR_ARC + 6.0)
# FORBIDS POURS AND VIAS, NOT TRACKS AND PADS. What the AE1 element
# needs is its COUNTERPOISE removed - the ground and VDD planes, and any via
# stitching them - from under the radiating element. Forbidding tracks and
# pads as well was tried and reported 100 items_not_allowed against the NFC
# winding, which necessarily crosses this sector on its way round the board
# and is 13.56 MHz copper that does not behave as a 2.4 GHz counterpoise.
# WHAT DOES CROSS HERE IS A REAL COUPLING QUESTION AND IT IS ce-rf's: the NFC
# coil on B.Cu and BT1's positive contact land both sit under this sector and
# neither can move. They are in the model, not designed out.
# F.Cu IS IN THIS LIST, and leaving it out was a real bug. The antenna lives
# on F.Cu, so the first version excluded that layer entirely - which meant
# the top-side GND pour filled right up to the element with 0.127 mm of
# clearance on both sides. That is not an antenna beside a ground plane, it
# is a coplanar waveguide, and it would have radiated almost nothing. Pours
# are forbidden on all four layers in this sector; TRACKS are allowed,
# because the element itself is one.
b.keepout(outline=ANT_CLEAR, layers=["F.Cu", "In1.Cu", "In2.Cu", "B.Cu"],
          tracks=False, vias=True, pads=False, pours=True, footprints=False,
          scope="board", name="antenna-ground-clearance",
          why="No ground plane, no inner copper and no bottom copper under "
              "the 2.4 GHz element. An inverted-F over its own ground plane "
              "is a short circuit. F.Cu is deliberately NOT in this list - "
              "the antenna itself lives there.")
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

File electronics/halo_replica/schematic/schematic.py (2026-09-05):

"""halo REPLICA — Apple AirTag A2187, reconstructed as a schematic.

    cd ~/dev/ce-workshop
    ce-pcb/bin/sch all ce-designs/halo/electronics/halo_replica/schematic/schematic.py \
                   -o ce-designs/halo/electronics/halo_replica/out/schematic

LANE L11 owns this file. It is NOT `electronics/halo_rev_a/schematic.py`,
which is the board halo SHIPS; this one is the board Apple shipped, drawn as
faithfully as the evidence in this repository permits and NO MORE.

===========================================================================
THE ONE SENTENCE A READER MUST NOT MISS
===========================================================================
**NOBODY IN THIS PROJECT HAS TRACED APPLE'S COPPER.** Not one net on this
sheet was read off a board. Every connection here is RECONSTRUCTED FROM
FUNCTION — from what each identified part is for, and from what its datasheet
family requires — and the parts themselves come from `bom/bom.json`, which is
photographs and markings, not continuity.

So every net carries a `basis` and this sheet prints them all:

    MEASURED   read off the hardware by a named source, in this repository
    INFERRED   required by the part's own datasheet family once the part is
               accepted (a crystal goes on the crystal pins; a flash's VCC
               goes to a rail). Wrong only if the part identification is wrong
    CHOSEN     this sheet picked it. Apple's actual assignment is unknown and
               a different GPIO would be equally consistent with every
               photograph. Never cite one of these as a finding about Apple

`NETS.md` beside this file lists every net, its basis, what drives it and what
it feeds. `schematic.py --nets` regenerates it, so the two cannot drift.

===========================================================================
FOUR THINGS THAT ARE ON THIS SHEET AS THEY ARE, NOT TIDIED
===========================================================================
1. **U2 — Apple's "U1" UWB SiP — IS PLACED AND IS DNP/UNPOPULATED.**
   Apple does not sell it. To anyone. It is not a sourcing problem, it is a
   does-not-exist-for-us problem, and a replica that quietly omits it is
   claiming a device it cannot build. It is drawn, marked DNP, and the
   refusal is written on the sheet itself in `s.text()`, not only here.
   Its symbol is a PLACEHOLDER with this sheet's own pin numbering: **no
   pinout for the Apple U1 SiP has ever been published**, so those numbers
   are not a land pattern and nobody may fabricate from them.

   NAME COLLISION, and it has bitten people: `bom/bom.json` follows
   REFERENCE-TEARDOWN and calls the **Nordic MCU U1**. The part the press
   calls "the U1" is **U2** here. Never write bare "U1" about the UWB part.

2. **U4's exact part is CANNOT DETERMINE.** `bom.json` U4: two visually
   identical metal-lid parts, no readable marking at any magnification
   available, and "BMA280" is a teardown assertion this project tried to
   corroborate by size and could not. It is drawn with a GENERIC 3-axis
   accelerometer symbol and its value field carries the ambiguity.

3. **U9 is CANNOT DETERMINE.** Marking `1A8 / 1950`, a part number nobody has
   published, and its *function* — "secondary regulator" — is itself an
   inference. Generic symbol, ambiguity in the value field, and its output
   goes to NOTHING on this sheet because nothing in the record says what it
   feeds. `check()` reports that net as CANNOT DETERMINE and that report is
   the correct answer, not a defect to silence.

4. **D3 — the series diode DECISIONS.md D24 requires.** Nordic's own nRF52832
   product specification §42.10, verbatim: *"If the antenna is exposed to a
   strong NFC field, current may flow in the opposite direction on the supply
   due to parasitic diodes and ESD structures. If the battery used does not
   tolerate return current, a series diode must be placed between the battery
   and the device in order to protect the battery."* A CR2032 does not
   tolerate return current, and a phone held against the tag is a strong field
   BY DESIGN. D3 sits between the positive power finger and everything else.
   **It costs a forward drop the power budget has not accounted for** — a few
   hundred mV for a Schottky against a cell whose end-of-life headroom the
   coin-cell model already tracks to 68 mV of droop, or millivolts for an
   ideal-diode controller that costs more money. D24 says the board lane
   prices both. THE COST IS ON THE SHEET (`s.text`), not hidden in a note.

   D3 IS AN ADDITION, NOT AN OBSERVATION. No photograph in this repository
   shows a series diode in Apple's power path. Apple may have solved this
   another way, or accepted it. `basis=CHOSEN`.

===========================================================================
THE POWER PATH, AND WHERE IT DEPARTS FROM iFIXIT
===========================================================================
REFERENCE-TEARDOWN §2.1 says U8 (FPF2487-class load switch) "gates U1 +
flash", where U1 is the Nordic MCU. **This sheet does not draw that, and the
reason is an engineering one that does not need a photograph:**

    A load switch that gates its own controller cannot be turned on. If the
    MCU's rail comes through U8, and U8's enable comes from the MCU, the
    board never boots. Something else would have to hold that enable — and
    the record names nothing that could.

So: the buck U6 makes 1.8 V; the MCU U1 sits on it directly; U8 gates the
flash U3 and the UWB module U2 from a GPIO, which is exactly the arrangement
that buys the 2.3 µA sleep the teardown reports. iFixit's line is single-
source, `bom.json` grades U8 **LOW / SILICON CITED** ("not corroborated by
Catley, O'Flynn or any photograph here"), and this is what was discarded and
why. Both readings are recorded in `DISCARDED` at the bottom of this file.

===========================================================================
THE PACKAGES ARE NOT THE REAL PACKAGES, AND THAT IS DELIBERATE
===========================================================================
Apple's U1 is an **nRF52832-CIAA, WLCSP-50**. There is no COMPLETE sourced
ball map for CIAA anywhere in this repository, and inventing 50 ball
designators is exactly the failure DECISIONS.md D9 forbids.
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

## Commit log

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2026-09-03 research: lane E second pass - nRF54L prices re-verified, and lane I's module question closed
    Every price in section 10 was re-pulled from the live LCSC __NEXT_DATA__ blob and the
    JLCPCB parts API. All four nRF54L ladders came back identical; only the dead non-R7
    reel drifted a cent. New section 11 records the check and seven corrections.
    The answer lane I needed: NO module is both pre-certified and castellated on nRF54L
    silicon today. Raytac AN54LQ is certified in nine regimes and documents NFC1/NFC2 on
    pads 15/16, but it is LGA, not castellated - its bottom view draws 43 pads inset from
    the outline and its recommended lands sit wholly inside the body, where Raytac's own
    MDBT42Q lands prot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
    [sources.tsv]
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2026-09-03 research: lane E - D11a deletes the class-D amplifier, and the roll-up now says so
    Section 10 replaced the transducer with lane G's bare Murata 7BB-20-3 bender but kept
    paying for the MAX98357A. D11a's own words are that the bender is driven anti-phase
    from two SoC pins, and SPEC.md section 3 repeats it: two pins means no amplifier IC.
    The deletion is three things, not one - the part, 9 BGA joints, and one JLCPCB
    Extended-part feeder fee - so it is worth $0.72/unit at ten units and $0.26 at a
    thousand, not the $0.25 the part costs.
    Corrected v1 totals, bare nRF54L10: $19.25 / $9.28 / $7.17 / $6.75 at
    10/100/1000/10000. Certified-module route: $19.92 / $10.85 / $9.10 / $8.73.
    Delta against t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
    [sources.tsv]
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2026-09-04 electronics (lane B1): halo revision A schematic, ERC-clean, 0 errors 0 warnings
    The first board file in this repository that is ours. Everything under
    reference/ belongs to Nordic, to AirTag scanners and to other projects;
    this is halo's own circuit, generated from code so a value changes in one
    place.
    51 parts, 52 nets, 166 pin connections. kicad-cli sch erc --format json
    reports 0 errors and 0 warnings; PDF, SVG and netlist exported beside it.
    What it is: an nRF54L10-QFAA-R7 (D12) run straight off a CR2032 with no
    buck, no LDO and no load switch; the SoC's own NFC-A peripheral driving an
    etched coil through two tuning capacitors, so there is no NFC chip; a
    LIS2DW12TR on I2C; a 32 Mbit S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
    [halo_rev_a.kicad_sch]
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2026-09-04 electronics (lane B1): the Ø26.00 mm four-layer board, placed and planed
    Checkpoint. Placement, outline, keep-outs, planes and the etched copper are
    done; routing and DRC are not, and the numbers below are the ones measured
    right now rather than the ones hoped for.
    THE BOARD IS Ø26.00 mm, NOT Ø31.87. Ø31.87 is the shell's maximum outer
    diameter at z = 4.339 (SPEC.md §4); lane M's design.py fixes the PCB at
    D_PCB = 26.00 x 0.600 mm with three 26-degree keying notches to R12.60 at
    0/120/240. A Ø31.87 board cannot fit inside a Ø31.87 shell. The outline is
    generated from those constants, so it cannot drift from the carrier.
    The netlist is never retyped: board.py reads it back out of the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
    [halo_rev_a.kicad_pcb]
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2026-09-04 electronics (lane B1): board DRC 449 -> 20 violations, with the reasons
    Every fix below is a measured cause, not a tightened tolerance. Nothing was
    excluded, silenced or loosened to make a count fall.
    THE CONTACT LANDS WERE POINTING THE WRONG WAY, and it cost 1.2 mm of copper
    in the wrong direction. A pad at position angle t has its radius along
    (cos t, -sin t) in KiCad's Y-down frame, and a pad rotated by phi has its
    LONG axis along (cos phi, -sin phi) - so authoring phi = t pointed each
    2.40 mm contact strip RADIALLY. The lands spanned R10.4 to R12.8 instead of
    R11.0 to R12.2: into the NFC winding on one side, and to within 0.35 mm of
    the routed edge on the other. Found from the DRC's own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
    [halo_rev_a.kicad_pcb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]
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2026-09-04 sim (lane B1): our own rail under the nRF54L10's own transmit pulse - PASS
    ce-spice ships cr2032_pulse_load and it models a DIFFERENT BOARD: 8 mA from
    an nRF52832 behind 100 uF. Leif asked for our board simulated, so this is
    halo rev A's rail with halo rev A's numbers.
    load 8.0 mA -> 3.7 mA nRF54L10 datasheet Table 86, ITX,0dBm
    reservoir 100 uF -> 40 uF 4 x 10 uF 0402, because 0805 does not fit
    sleep 2.0 uA -> 2.4 uA Table 86 ION_IDLE4, 192 kB retained
    Those move the droop in opposite directions, so which wins was a question
    with a number as its answer. Six circuits, VERDICT PASS.
    worst case, 2.0 V cell at 140 ohm: droop 84.7 mV against a 400 mV limit,
    rail bo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
    [halo_rev_a.dsn, halo_rev_a.kicad_pcb]
2026-09-04 sim (lane B1): the sounder measured, and R9 earns its BOM line - PASS
    D11a deletes the class-D amplifier and drives a bare piezo bender straight
    from two SoC pins. research/05 section 11.6 argues on arithmetic that this
    costs nothing, and ends by calling itself 'derived arithmetic from the
    datasheet capacitance class, not a measurement'. This is the measurement of
    the electrical half. Seven circuits, VERDICT PASS.
    D11a's CENTRAL CLAIM HOLDS. Two GPIO in anti-phase put 3.98 V peak to peak
    across the bender from a 2.0 V end-of-life cell - the same 2 x VDD a
    bridge-tied class-D would give, from no amplifier at all.
    R9 IS LOAD-BEARING, and the schematic's stated reason for it was wrong. With
    a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
    [halo_rev_a.kicad_sch]
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2026-09-04 electronics (lane B1): flash deleted as out-of-spec, test access designed in, antenna re-sized from a measurement
    THE FLASH WAS A REAL DEFECT AND IT IS GONE. U3 was a GD25LQ32EEIGR sitting
    on VDD, which on this board is a raw CR2032 with no regulator anywhere. That
    part's supply range is 1.65 to 2.0 V and a fresh coin cell is 3.0 V, so it
    was out of specification from the first second - the kind of fault that
    half-works on a bench and fails in a field. Caught by the production test
    lane reading the sheet.
    Fitting a regulator was the other way out and it is what the real AirTag
    does (a TPS62746 buck plus an FPF2487 load switch, SPEC.md section 3). It
    would have cost a part, an inductor, a ra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
    [halo_rev_a.kicad_pcb, halo_rev_a.kicad_sch]
2026-09-04 fab (lane B1): the factory package - gerbers with geometry, a BOM with order codes, ERC 0/0
    ERC PASS, 0 errors AND 0 WARNINGS. The 13 warnings before this were one
    cause: this machine has no global KiCad footprint table, because KiCad has
    never been opened interactively here, so without a project table ERC cannot
    resolve a footprint and reports one warning per part. The project now writes
    its own listing all 155 KiCad libraries plus halo's, which also makes the
    handoff self-contained. It is written at the END of the pipeline because
    bin/sch build writes its own 8-library version over anything earlier - an
    attempt to write it from the schematic was silently discarded.
    THE GERBERS ARE VERIFIE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
    [halo_rev_a-BOM.csv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]
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2026-09-04 height (lane B1): the enclosure conflict closes on 0.372 mm, and lane M already found it
    The board's largest open item was that five part classes do not fit the
    stack: a QFN-48 is 0.85 mm and the cell leaves 0.578 mm under the bottom
    face, so X1 and L1 are over by 0.322 mm and the SoC by 0.272. It has been
    reported as a cross-lane delta since the placement went in.
    Lane M's D17, landed today, ends with the answer: 'leaving 0.542 mm of dead
    air under the cell that a flat pad embossed in the door could still
    recover'. Emboss that pad, the cell drops, and the bottom-face allowance
    becomes 0.578 + 0.542 = 1.120 mm. The tallest part on this board is 0.90 mm
    and needs 0.95 mm with a fillet, so EV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
    [halo_rev_a.dsn, halo_rev_a.kicad_pcb]
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2026-09-04 checkpoint: board work in flight when the machine crashed at 22:25
    Committed as-is so it survives, NOT as a result. Measured right now: DRC 19
    violations, 92 unconnected — the board is mid-routing, not finished. New in this
    tree: keepout_check.json and height_check.json.
    Claude-Session: https://claude.ai/code/session_01DLBM9xzZTSLgvB55tmrcPa
    [halo_rev_a.kicad_pcb]
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2026-09-04 B1: a pad is a capsule, not its own diagonal — and the two tie stubs were crossed
    Three more measured defects in the fanout, all in the obstacle model, none of
    which announced itself.
    1. A PAD WAS MODELLED AS A DISC OF ITS OWN DIAGONAL. `hypot(w, h)/2` turns a
    0.25 x 0.60 mm QFN-48 land into a disc 0.65 mm across, so its neighbour
    0.40 mm away on 0.40 mm pitch is permanently inside it and EVERY escape
    from EVERY fine-pitch pin is refused for a collision with copper that is
    not there. Measured: 16 of 24 VDD pads "unreachable", and the number did
    not move when the clearance rule was corrected — because clearance was
    never what was wrong. Pads are now COVERED by a grid of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
    [halo_rev_a.kicad_pcb]
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2026-09-04 B1: the crystal was out of spec, 1.1 nF does not exist, and the net tie was three times too wide
    THE FOUR CHANGES FROM SOURCING AND VERIFICATION, ALL FOUR LANDED.
    1. X1 IS THE WRONG CRYSTAL AND WOULD NOT HAVE STARTED. C32346 (Q13FC13500004)
    is CL = 12.5 pF, chosen on price and stock, and D-3 deletes the external
    load capacitors — so the entire load is the nRF54L's on-die caps. Nordic's
    datasheet 4503_018 v1.0 (Sept 2025) refuses 12.5 pF twice:
    * Sec 5.5.2 — OSCILLATORS.XOSC32KI.INTCAP holds 3-18 pF in 0.65 pF steps,
    and CL = (C_INT + C_pcb)/2, so the ceiling is about (18+2)/2 = 10 pF.
    12.5 pF needs C_INT ~ 23 pF: 5 pF above the hardware maximum.
    * Sec 11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
    [halo_rev_a.kicad_pcb, halo_rev_a.kicad_sch]
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2026-09-04 checkpoint: board and verification work in flight when the machine crashed 03:32
    Committed as-is so it survives, NOT as a result. Measured right now: board DRC
    12 violations; the drill blocker looks closed — PTH.drl carries 50 holes against
    49 vias declared in the board, which needs confirming rather than assuming (a
    PTH file also carries through-hole pads).
    B1 built a verification suite in out/verify/: bom-identity, cpl-rotations and
    lcsc-netlist PASS; dfm-jlc-4layer, fabset and convergence-integrity FAIL.
    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
    [halo_rev_a-BOM.csv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]
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2026-09-04 B1: the fabrication package, re-cut from the board it claims to be
    tools/build_fabset.sh from the current halo_rev_a.kicad_pcb (49 vias, 255 track
    segments, 62 footprints). The pack on disk was cut from the 02:27 board and the
    board was rewritten at 03:31; every Gerber, both drill files, the BOM, the CPL
    and the zip are replaced together so the set describes one board.
    Its own gate, measured after the cut:
    check_fabset 15 PASS / 0 FAIL / 0 CANNOT DETERMINE
    PTH 49 holes = 49 vias + 0 thru-hole pads
    NPTH 0 holes = 0 np_thru_hole pads
    diameters 0.25mm x49 on both sides
    export 415 s NEWER than the b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
    [halo_rev_a-BOM.csv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]
2026-09-04 convergence: a source that resolves to nothing was grading better than a literal
    Three fixes to the integrity check and the table it grades, each found by
    running the check rather than reading it.
    1. `elif src:` PASSED ON THE STRING IN THE `from` FIELD. G6 high_weight_measured
    exists to catch a weight-10 claim whose current value is typed into the spec.
    It compared `from` to the word "literal" and passed everything else — so a row
    naming a source that produced NO VALUE scored better than one that honestly
    typed the number in. Measured: two antenna rows (radiation efficiency, realized
    gain) were reading PASS on G6 with `current: null`, because their ce-rf case had
    FAILED and rf() correctly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
    [halo_rev_a.kicad_pcb]
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2026-09-04 B1: the board pack's README now names every file and what each check said
    §2 gains a row per file, including the two drill files with their exact hole
    counts and the reason NPTH is empty, and a new table of every artifact in
    out/verify/ with its verdict — 9 checks, one file each, all re-run 2026-09-05
    06:06.
    Corrections, each measured rather than reasoned:
    - **The 0.15 mm pad was not a paste-relief aperture.** The previous README
    said the sub-limit pad "carries no copper" and that the narrowest real land
    was 0.200 mm. Measured over all 254 pads by kind: solderable lands 0.200 mm
    (175 of them), net-tie pads 0.150 mm (2), unnumbered paste-relief apertures
    0.318 mm (77). The paste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
    [halo_rev_a-B_Cu.gbl, halo_rev_a-B_Mask.gbs, halo_rev_a-B_Silkscreen.gbo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]
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2026-09-04 dsnfix: the fiducials had no clear field, and that was every DRC error on the first autoroute
    The first successful autoroute of halo_rev_a (856 s, 10 passes, unconnected
    81 -> 31) came back with four DRC errors and ALL FOUR were at FID1/FID2:
    clearance via [I2C_SCL] 0.2017 mm from FID1's pad, own limit 0.35
    hole_clearance the same via, 0.3017 mm
    solder_mask_bridge that via and FID1's pad bridged in one mask aperture
    clearance track [NFC2] 0.3361 mm from FID2's pad
    Zero errors anywhere else on the board. The router did nothing wrong: a
    fiducial is an optical target for the placement camera, it carries no net, and
    the Specctra export sends it as an ordinary pad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
    [dsnfix.py]
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2026-09-04 B1: the board is routed — 81 unconnected -> 35, 0 DRC errors, protected copper intact
    The autoroute this lane wrongly reported impossible. `tools/route_board.sh`,
    one command: route --doctor, export -> dsnfix -> freerouting -> SES -> KiCad
    DRC, then check_routed on the result.
    unconnected 81 -> 35 (46 closed)
    DRC errors 0 -> 0
    DRC warnings 3 -> 2 (all track_dangling)
    copper +298 segments, +37 vias
    freerouting 10 passes on 113 pins across 48 nets
    check_routed: 8 PASS / 1 FAIL / 0 CANNOT DETERMINE.
    protected_copper_preserved PASS all 235 segments on ANT_FEED/NFC1/NFC2 came
    back within 55 nm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
    [halo_rev_a-routed.kicad_pcb, halo_rev_a.filtered.dsn]
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2026-09-04 B1: the routed board's own DRC report and project, beside it
    halo_rev_a-routed.drc.json is KiCad's verdict on the routed copper — 0 errors,
    2 track_dangling warnings, 35 unconnected — and the .kicad_pro is the netclass
    it was graded under, without which KiCad falls back to its own 0.2 mm default
    and the same copper reads 467 errors.
    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
    [halo_rev_a.dsn]
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2026-09-04 B1: nine meander teeth take the NFC coil out from under the antenna arm
    The coil overlapped the 2.4 GHz arm by 0.1747 mm. Lane T3 measured what that
    costs: coil under the arm 1.7666 GHz against 2.4346 GHz clear, a 668 MHz shift
    no tuning recovers. Fixed in the copper, and the fix is free in the one
    dimension that matters.
    WHY THE BAND WOULD NOT CLOSE ANY OTHER WAY. The coil lives between the cell
    can at R10.00 (copper over a steel can is a shorted turn) and the arm's inner
    copper edge. At 4 teeth the arm needs a depth of 0.9379 mm, which puts that
    edge at R10.6621 and leaves the coil 0.6621 mm for the 0.782 mm it needs — a
    0.4197 mm shortfall it was taking by lying under the arm. Every ot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
    [halo_rev_a.kicad_pcb]
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2026-09-04 B1: routed on the corrected geometry — 81 -> 33 unconnected, 0 errors, arm clear
    Second route, on the nine-tooth board with the antenna-arm-shadow keep-out.
    4-tooth run 9-tooth run
    unconnected 81 -> 35 81 -> 33
    DRC errors 0 -> 0 0 -> 0
    DRC warnings 3 -> 2 3 -> 3
    segments 255 -> 553 275 -> 649
    vias 49 -> 86 49 -> 91
    wall time ~857 s 464.8 s
    worst protected disp 55 nm 55 nm
    conductor 162.2257 -> 162.2479 ->
    162.2258 mm 162.2480 mm
    arm clearance -0.1747 mm +0.3627 m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
    [halo_rev_a-routed.kicad_pcb, halo_rev_a.filtered.dsn]
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2026-09-04 B1: the unrouted board's own DRC and DSN, regenerated on the nine-tooth geometry
    3 violations, all track_dangling warnings, 0 errors, 81 unconnected. Committed
    because the machine load spiked to the range both this week's kernel panics
    were in, and only committed work has survived the five crashes this lane has
    already had.
    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
    [halo_rev_a.dsn]
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2026-09-04 B1: 74% of the NFC coil had a plane under it, and that was never a decision
    ce-rf refused the re-solve because the coil comes within 0.1492 mm of the
    ground shape against a 0.1500 mm mesh cell — it could not separate them and
    would have merged them into a short, so it answered CANNOT DETERMINE instead of
    answering wrongly. Right refusal, and chasing it found something bigger.
    IS THE 0.1492 mm DELIBERATE? No. It is the 0.127 mm netclass clearance plus
    fill rounding. The pour filled as close to the coil as the rules allowed and
    nobody chose the number.
    DOES THE POUR NEED TO BE THAT CLOSE? No — and the coplanar gap is the smaller
    half of the problem. Measured on the shipped board by sampl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
    [halo_rev_a.kicad_pcb]
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2026-09-04 checkpoint at the usage wall: board lane work in flight, route running
    Committed unconditionally rather than tidily. A subagent that hits the usage
    limit dies outright and loses work that exists only as tool calls, unlike an
    interactive terminal which pauses and resumes. The board lane is the only
    subagent on this machine holding work anyone wants.
    In flight: the NFC coil keep-out (74% of the coil had solid plane one dielectric
    away on both inner layers), the stitch fix excluding vias by copper radius rather
    than centre, and the 360-chord polygon correction.
    Claude-Session: https://claude.ai/code/session_01DLBM9xzZTSLgvB55t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
    [halo_rev_a.dsn, halo_rev_a.filtered.dsn]
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2026-09-05 B1: routed with the planes cleared — 83 -> 28 unconnected, ROUTE GATE PASS
    Third route, on the geometry with nfc-coil-clearance cutting the planes out
    from under the coil. First run of this lane where check_routed returns a clean
    sweep.
    4-tooth 9-tooth 9-tooth + planes cleared
    unconnected 81 -> 35 81 -> 33 83 -> 28
    DRC errors 0 -> 0 0 -> 0 0 -> 0
    DRC warnings 3 -> 2 3 -> 3 3 -> 3
    segments 255 -> 553 275 -> 649 275 -> 610
    vias 49 -> 86 49 -> 91 49 -> 83
    wall time 857 s 465 s 1155 s
    worst protected 55 nm 55 nm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
    [halo_rev_a-routed.kicad_pcb]
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2026-09-05 L12: the Replica has land patterns. 40 footprints, three evidence classes, generated
    The Replica had no footprint library at all. It has one now:
    halo_replica.pretty/, generated by pcb/footprints.py from the measurement
    files, never hand-drawn, with fp-lib-table beside it.
    Every pad carries its evidence class, because three different kinds of
    geometry end up on one board and confusing them is the failure this lane
    exists to prevent:
    CLASS A package geometry, not a measurement of Apple's board.
    REPL_0201_0603Metric and REPL_0402_1005Metric (EIA case-size
    nominal body, lands built from stated toe/heel/side allowances
    that are labelled a CHOICE of this lane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
    [footprints.py]
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2026-09-05 L9: put the pre-averaged-homography trap in the file L12 reads, not only in my source
    The trap was in k_backface.py's source comment, in a commit message and in three
    cross-session messages. It was NOT in HANDOFF-positions-back.json, which is the file the
    board lane actually opens. That is the exact failure mode this lane has spent the day
    cataloguing: a finding that lives only in prose the next person will not read is a
    finding that gets re-derived painfully, and this one re-derives as a silent frame error.
    Now a top-level key L12 cannot miss:
    IF_YOU_MAP_A_REGISTERED_POSITION_YOURSELF_READ_THIS. c_register's homography returns
    coordinates in the PRE-AVERAGED source frame, not full-resoluti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
    [halo_replica.kicad_pcb, halo_replica.kicad_sch]
2026-09-05 board.py: stop calling AE1 three different topologies in one file
    It was a "meandered quarter-wave monopole" at line 820, "the inverted-F drawn
    here" at line 86, and "an inverted-L monopole" at line 325. Three topologies with
    three different counterpoise requirements, so a reader could not tell what was
    drawn and neither could anyone setting up a solver port.
    The names are removed rather than one being picked, because picking would assert
    something nobody has established. What is measured stays: a meandered trace on
    F.Cu only, nine teeth, conductor 24.49100 mm against a quarter-wave target of the
    same, fed one end, other end open. Which topology that IS on this ground is what
    ce-rf is still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
    [board.py]
2026-09-05 E07 synthesis: three kinds of adjacent, and the pipeline exit code as a sixth
    Refinement from the comparison lane: the five cases differ in WHAT the adjacent
    property was - three adjacent STATISTICS (increment permutation, off-peak noise,
    area alone), one adjacent COORDINATE (between-in-x), one adjacent PATH (a guard
    resolving against the search root). The path case is the one people least expect
    because it is not a modelling error at all - a plumbing error wearing a control's
    clothes, which no amount of thinking about the physics would have found.
    Plus a sixth of the same shape from the same day: reading 'cmd | tail's exit
    status instead of the command's. PIPESTATUS[0] gives the real one.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
    [halo_replica.kicad_pcb, halo_replica.kicad_sch]
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2026-09-05 L12: a .kicad_pcb that OPENS. Annular, routed pocket, 103 placements, DRC run
    The Replica had no board file. It has one: pcb/out/halo_replica.kicad_pcb,
    25.16 mm drawn OD, 4 layers, 0.30 mm, and it opens in KiCad 10.
    THE EDGE IS FITTED PRIMITIVES, NOT A SILHOUETTE. Outer: 3 true arcs + 4
    straight chords, endpoints solved exactly (circle-line quadratic, 2x2 for
    line-line), never sampled. Pocket: superellipse n=2.4491 with 7 measured
    straight facets and 14 radial step walls, 734 segments after dedupe, max
    tessellation chord error 0.0322 mm against a 0.1029 mm registration floor.
    The OD is a PARAMETER read from board.json, scaled by drawn/fitted; no
    diameter is hard-coded anywhere in pcb/.
    TH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
    [halo_replica.kicad_pcb]
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2026-09-05 E07 correction: the 0.23% cross-validation I amplified twice is really ~1.8%
    The BOM lane routed it and it corrects a claim I made and then repeated upward.
    E07 states that a steel rule through a homography and the nRF52832's datasheet
    package agree to 0.23% with neither fitted to the other, and I called it the
    strongest cross-validation in the lane.
    It rests on the SMALLEST of THREE segmentations of the same part in the same
    photograph. M08's own whole-board run gives 108.2 px/mm by the same route - 1.8%
    away - and a third gives 110.1. A datasheet package cannot pin a scale better
    than ~2% because the segmentation of the part is itself uncertain at that level.
    The 106.313 px/mm verdict is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
    [footprints.py]
2026-09-05 L9: the fourth column - a report's row state and its contents are different facts
    D6 showed "valid=yes", which by this file's own rules means ITS SOURCE (the ERC) was
    clean - and reads to anyone scanning a table for green as "the DRC passed". IT DID NOT:
    the Replica's DRC reports 42 errors against 3 warnings, with actual clearances down to
    0.0000 mm. Documenting that trap was the weaker option. The column that says so is now
    beside it, and the third column is renamed from "valid" to "source ok", because "valid"
    is the word that invited the misreading.
    opens | current | source ok | ITS OWN VERDICT
    D6 now prints ** 42E 0U ** with: "THIS ROW IS GREEN AS AN ARTIFACT AND THE THING IT
    GRADES I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
    [halo_replica.kicad_pcb]
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

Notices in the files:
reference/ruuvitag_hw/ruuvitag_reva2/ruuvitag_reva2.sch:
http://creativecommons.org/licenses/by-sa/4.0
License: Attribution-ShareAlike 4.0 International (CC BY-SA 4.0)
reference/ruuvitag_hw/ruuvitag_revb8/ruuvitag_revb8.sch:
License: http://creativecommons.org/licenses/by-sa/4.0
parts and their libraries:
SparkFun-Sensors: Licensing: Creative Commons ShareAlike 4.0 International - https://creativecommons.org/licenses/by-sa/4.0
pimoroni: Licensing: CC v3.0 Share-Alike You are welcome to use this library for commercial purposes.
